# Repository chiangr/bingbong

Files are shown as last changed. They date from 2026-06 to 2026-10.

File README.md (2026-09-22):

# bingbong

The current interactive product site, engineering references, and hardware working files in one checkout. Start with [SESSION_HANDOFF.md](SESSION_HANDOFF.md) for the accepted design direction, source authority, verification results, and remaining work.

This handoff branch is `codex/assembly-handoff-2026-09-22` in [chiangr/bingbong](https://github.com/chiangr/bingbong). It preserves the earlier `master` history and mirrors the local project layout: the former repository-root firmware now lives under `firmware/`.

## Run the site

Install Node.js 24 LTS (or 22.12+) and run:

```sh
git clone --single-branch --branch codex/assembly-handoff-2026-09-22 https://github.com/chiangr/bingbong.git
cd bingbong/site
npm ci
npm run dev
```

Open http://localhost:5173/#inside for the exploded assembly study, or http://localhost:5173/ for the full fifteen-chapter experience. [The standalone HTML](site/artifact/bingbong.html) also opens directly in a browser without installing dependencies.

For a production preview:

```sh
npm run build
npm run preview
```

Open http://localhost:4173/#inside. Servers must be started on each laptop; no remote service is required.

## Project map

| Path | Contents |
| --- | --- |
| [site/](site/) | Current Three.js/Vite experience, all assets, source, scripts and documentation |
| [site/qa/](site/qa/) | Saved tests, 240 layout captures, independent reviews, Lighthouse report and videos |
| [DESIGN_MANUFACTURING_REPORT_2026-09-19.md](DESIGN_MANUFACTURING_REPORT_2026-09-19.md) | Latest engineering authority, including conflicts and open decisions |
| [REDESIGN_DECISION_2026-09-12.md](REDESIGN_DECISION_2026-09-12.md) | Earlier engineering decisions; superseded where the September 19 report conflicts |
| [firmware/](firmware/) | Existing ESP32-S2/BG95 bring-up code and current KiCad working files in `bingbong_pcb/` |
| [cad/](cad/), [cad-v2/](cad-v2/) | Existing mechanical and PCB design exports; these are not final production CAD for the illustrated reference build |
| [pcbway-fab/](pcbway-fab/), [datasheets/](datasheets/), [bom-scratch/](bom-scratch/) | Fabrication exports, component references and supporting analysis |

See [site/README.md](site/README.md) for interactions and verification commands. The website uses the engineering report's reference geometry; existing hardware files and firmware do not constitute a completed implementation of that design.

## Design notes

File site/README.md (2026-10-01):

# bingbong — the assembly study

A new visual direction built around an animated, inspectable 3D product. Midnight blue, cool silver, violet, clean typography, and the original pet / boop / hold demonstrations. This replaces the first build's warm palette and still-first presentation, as requested.

Five later chapters open the same object into its internal assembly, crown cartridge, working ceramic-ball detents and antenna connection, then build it back up. Twenty component descriptions explain manufacture and fitting against the September 19 engineering report.

## Run

Use Node 24 LTS or 22.12+. On a fresh checkout, run these commands from this directory:

```sh
npm ci
npm run dev
```

Open http://localhost:5173. Read [SESSION_HANDOFF.md](../SESSION_HANDOFF.md) for the repository layout, engineering authority and setup on another laptop.

`npm run build` creates `dist/`. Start `npm run preview` to serve it at http://localhost:4173. Open http://localhost:4173/?v=4#inside to begin the assembly study.

Deploy the contents of `dist/` to a static host at the domain root. No server, account, telemetry, external runtime request, or purchase flow is needed. The local service worker makes the site available offline after a complete load. Navigation prefers the network so revisions are visible; cached content remains available offline.

`npm run artifact` produces `artifact/bingbong.html`. This standalone version includes the code, fonts, lighting map, and fallback assets. Open it directly in a browser; no local server or CDN is required.

## Interact

- Drag the **body** to rotate the object. Horizontal touch dragging rotates; vertical swiping keeps normal page scrolling. The view controls also work with keyboard activation.
- Drag the **crown**, or use its arrow keys, to turn in 15° detents. Enter boops; holding Space shares presence.
- Use the chapter's turn, boop, and hold controls to try the paired-device demonstrations.
- Use **Turn it over** for the rear charging pads. Rotation and rear-view transitions use the same live geometry.
- Scroll carries the same object between compositions. Position, scale, screen brightness, halo, mobile clipping and view controls follow the same continuous track; reversing scroll retraces it.
- In **Inside**, select a component button or click the 3D part to read how it is made and fitted. The crown opens into ten component groups.
- In **The mechanical click**, step the race forward or backward. Exactly two ceramic balls move against the 24 grooves while the BeCu leaves deflect.
- In **The cap and antenna**, trace the board → spring finger → plated land → cap connection. The cap is turned to expose its underside; the board is cropped to the RF edge.
- Open **RF lab** in the navigation or antenna chapter, or visit `/#rf-lab`, for a four-part interactive study. Follow equations from charge and current to traveling fields; inspect all 16 proposed RF component positions; animate LC branch currents and reflected waves; and decode a typed message through actual I/Q mixing and integration. The receiver exposes symbol boundaries, phase errors, a known pilot, and interference. The matching bench and receiver use documented teaching models, not measured bingbong antenna data or a complete LTE PHY. Escape or Back returns to the product; a static primer remains available without JavaScript.
- In **Coming together**, scroll, scrub, play, pause or reset the six-stage assembly. On phones the compact controller remains below the object while its introduction scrolls away.
- Sound is opt-in. Reduced motion stops ambient movement and scroll catch-up; the object follows the user's scroll directly and retains manual interaction.

## Source

| File | Responsibility |
| --- | --- |
| `src/experience.css`, `src/tokens.css` | New layout, responsive behavior, palette, typography |
| `src/sections/` | Fifteen chapters of static, accessible content |
| `scripts/build-page.mjs` | Generates HTML, navigation, and accessible controls |
| `src/main.js` | Immediate scene startup and chapter coordination |
| `src/timeline.js` | A single scroll coordinate drives continuous poses and visual states |
| `src/components/scene.js` | Live rendering, damped transforms, drag rotation, context recovery |
| `src/components/graphics-warmup.js` | Optional temporary worker prepares the graphics driver during page setup |
| `src/components/product-model.js` | Parametric exterior in millimetres; materials, crown, display and halo |
| `src/components/assembly-model.js`, `assembly-geometry.js` | Lazy internal geometry, cutaways, spring motion and fitting paths |
| `src/assembly-data.js`, `assembly-interactions.js`, `assembly.css` | Component catalogue, manufacturing notes and assembly controls |
| `src/sections/rf-lab.js`, `src/rf-content.js`, `src/rf-lab.js`, `src/rf-lab.css` | RF study content, schematic, accessible modal, and experiments |
| `src/rf-model.js` | Auditable passive-circuit calculations for the educational matching bench |
| `src/rf-components.js` | Component-by-component explanations of the working RF schematic, including DNP positions |
| `src/rf-lessons-content.js`, `src/rf-lessons.js`, `src/rf-lessons.css` | Detailed first-principles equations, animations, and worked receiver interface |
| `src/rf-signal.js` | Independent models for QPSK encoding/mixing, pilot phase measurement, LC currents, and complex reflection |
| `src/components/studio.js` | Source of the studio lighting environment |
| `src/components/mascot.js` | Original wordless creature and animated reactions |
| `src/interactions.js` | Pet, boop, hold, sound and timer lifecycle |
| `public/mascot/` | Reusable SVG states, PNG sheets, loops and character note |
| `public/lighting/` | Prefiltered reflection map; the object itself remains live geometry |
| `public/renders/` | Generated stills for no-JavaScript / unavailable-WebGL fallback only |
| `qa/` | Screenshots, gesture tests, motion recordings and reports |

With the dev server running, `npm run assets` regenerates fallback stills. `node scripts/bake-lighting.mjs` regenerates the lighting map from the studio source. Shader compilation runs asynchronously; expensive environment prefiltering happens when generating assets, not on each visitor's device.

## Verify

Install Google Chrome for Playwright's `chrome` channel. Run `npm run build` and `npm run artifact`, then keep the production preview running on port 4173. In another terminal:

```sh
npm run qa
node scripts/live-check.mjs
node scripts/scroll-check.mjs
node scripts/assembly-check.mjs
node scripts/delivery-check.mjs
node scripts/rf-check.mjs
node scripts/rf-lessons-check.mjs
node scripts/lighthouse.mjs
```

QA uses installed Google Chrome through Playwright. The main suite captures every chapter at 390, 820, 1440 and 1920 px, in both system themes and motion settings. The fixed midnight palette is intentional in both themes. The scroll suite measures rendered movement across every chapter in both directions, including reduced motion, intermediate stops, screen/halo fades, mobile clipping, wheel input and boop navigation. Additional checks cover 360 px, touch, keyboard, live startup, object rotation, graphics-context recovery, no JavaScript, offline reload and the standalone file.

See [DESIGN_NOTES.md](DESIGN_NOTES.md) for measured results and limitations. Browser-emulated touch/performance is not a physical-phone test.

The RF checks cover analytical circuit reference cases, energy conservation, all four study panels at 360/390/820/1440 px, keyboard and reduced-motion interactions, browser history, accessibility, the static primer, and the standalone HTML. The expanded lesson checks add analytic I/Q identities, all printable ASCII round-trips, phase/pilot recovery, LC current cancellation and energy conservation, each component inspector, partial-symbol decisions, custom and invalid inputs, animation lifecycle, and a visible phone readout. Evidence is in `qa/rf/` and `qa/rf/deep/`. See [the RF source register](qa/rf/source-register.md) for design authority, model assumptions, and the report/schematic test-port discrepancy.

The physical facts and wording come from `SITE_BRIEF.md` and the local engineering reports. The assembly study uses the September 19 report's coaxial reference build; crown architecture/materials, rotary seal, sensor/contact choices and RF results remain open. This is an explanatory model, not production CAD. [Assembly source register](qa/assembly/source-register.md) records the component references. Fonts are self-hosted under the SIL Open Font License; licences accompany them. Three.js's MIT notice is in `public/THIRD_PARTY_NOTICES.txt`. Earlier source/static archives are preserved in `revisions/first-build/` and `revisions/scroll-edition/`.

`scripts/export.ps1` creates source, static and review ZIPs. The source includes historical notes; the review archive holds screenshots, results and videos separately. Extract both into the same directory to follow the evidence links. Raw screencast frames and dependencies are excluded.

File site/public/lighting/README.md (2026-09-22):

# Studio environment

A prefiltered CubeUV lighting map from the softbox scene in src/components/studio.js. Not a product image: the model is rendered live using these reflection samples.

384 × 512; linear RGB; radiance divided by 4 for PNG storage; flipY false. The renderer restores the scale through material environment intensity. Rebuild with npm run dev followed by node scripts/bake-lighting.mjs.

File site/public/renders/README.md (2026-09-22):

# Fallback render source

These static views support unavailable WebGL and no-JavaScript browsing. The normal experience starts its animated 3D model automatically and does not use product-image swaps.

All frames come from `src/components/product-model.js`, `scene.js` and `timeline.js`. The geometry is in millimetres. `npm run assets`, with the dev server running, opens `render-lab.html`, sets complete poses and exports transparent WebP files. Desktop and phone views share geometry and materials. Projected crown coordinates in `src/render-frames.json` are retained as render metadata; live hit areas are projected each frame from the real crown.

`await createScene(container)` creates the renderer. `scene.setFrame({rx,ry,rz,cx,cy,scale,screen,halo,state,pair,otherCx,otherCy,otherScale,otherState,otherHalo,crown,pressed,reduced})` sets a complete target. `cx` and `cy` are fractions of the canvas. `crown` is radians in π/12 steps; `pressed` moves it 0.4 mm. `reduced:true` removes automatic movement for capture. The runtime uses one animation loop and pauses when the document is hidden.

The 95 × 27 × 15 mm body, Ø13 crown, 48 serrations, 1.5 mm ring, 22.5 mm cap, 34 × 16 mm lens and 25.58 × 10.96 mm active panel follow brief §12. The model is an exterior visualization, not production CAD. Final colours and finishes remain design intent. Studio reflections come from the generated lighting map in `public/lighting/`; grain textures are deterministic.

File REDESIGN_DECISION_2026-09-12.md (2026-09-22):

# bingbong — ARCHITECTURE DECISION DOCUMENT

**Author:** lead architect
**Date:** 2026-09-12
**Status:** decision, for review. Nothing here is frozen until the three EVM-0 experiments in §10 report.

**A note on provenance before anything else.** Every tag below means something specific:

| Tag | Meaning |
|---|---|
| `[V]` | A primary datasheet or standards document was opened and the number read, by the research pass or a hostile-review pass recorded in this corpus. |
| `[V?]` | Read by one pass, **contradicted or unreproducible** by another. Must be re-confirmed before design-in. |
| `[U]` | Nobody has read the primary source. It is an estimate, a vendor marketing claim, or a distributor parametric field. |

I have not fetched anything new in writing this document. I am arbitrating between passes that did. Where two passes disagree I say which I believe and why, and I budget the pessimistic one.

---

## 1. THE RECOMMENDATION

**Build ENDURANCE, amended: a 27 × 95 × 15 mm sealed polymer capsule with a machined metal end-cap that is also the cellular antenna, an always-on 160×68 reflective landscape screen that costs 20 microamps to leave lit forever, a knurled metal crown at the other end with 24 real mechanical ball detents, and one 8 mm haptic motor whose only job is to render the *other person*.**

The bet is this: **being reachable is the only thing that costs real power, so buy reachability deliberately and spend nothing else.** A boop costs 53 microamp-hours — all 280 boops in a week cost less than the battery's own self-discharge. What costs money is how often the radio wakes up to *listen*. So the device listens slowly (once every 164 seconds) when nothing is happening, and listens fast (every 5 seconds) for three minutes after anyone touches anything. That single trick is 42× cheaper than listening fast all the time, for a latency the user cannot tell apart, because only the *first* message of a conversation can ever be slow. The money we save goes into a screen that never turns off — which is what makes the object feel alive rather than notified — and into surviving the edge of coverage, which is where every standalone-cellular product actually dies.

The second bet, and the expensive one: **the metal end-cap must be a real 700 MHz radiator.** The industry-standard answer (an Ignion chip booster) has no published solution below 824 MHz, and AT&T mandates Band 12 at 699–746 MHz for every IoT LTE device. There is no catalogue part that certifies this product. We therefore own an antenna engineering programme — roughly $30–70k of NRE and 3–5 months — and we find out whether it works in a chamber in month two, not month ten.

---

## 2. WHY THIS OVER THE OTHERS

All three concepts scored 6.5/10 under hostile review, which is the correct score for three documents that each got one big thing right and one big thing wrong.

### What each one got right, and what killed it

**JEWEL** (23.7 cm³ aluminium, coaxial crown, split-band chassis antenna, 330 mAh)

Right: mechanical detents only; never let the actuator render your own input. That is the single best idea in the entire corpus and I have taken it verbatim. Also right: Power Class 5 is free peak-current relief *because the AT&T TRP requirement drops 3 dB in lockstep*.

Killed by: the crown zone does not close. 9.0 mm allocated against an 11.45 mm serial stack, and three components (magnet, angle sensor, 8 mm LRA coin) all demanding the same centreline. Worse, it bonded a 170 Hz permanent-magnet actuator 4 mm from a magnetometer and made "you feel it in the crown" the headline feature — the charm and the measurement were in direct physical conflict. And its sole quantitative justification for the metal shell, "2.8× lower Q_min, therefore +3.2 dB efficiency ceiling," is a misuse of the Chu limit. **Chu bounds Q, not efficiency.** The reviewer reproduced the arithmetic exactly and then correctly refused the inference. That is precisely the failure mode this project's evidence standard exists to prevent, and I will not repeat it anywhere in this document.

**EX** (31.5 × 85 × 16 mm, colour IPS, two actuators, 710 mAh)

Right: filling the mandatory zero-copper antenna keepout with a PMMA light pipe, so the RF tax becomes the most emotive feature of the product. I have taken this, adapted. Also right: performing the 2–6 s cold RRC setup as the creature waking up instead of hiding it behind a spinner.

Killed by: its headline feature does not exist. Phantom tactile motion between two actuators 44 mm apart requires compliantly decoupled contact surfaces; the reviewer computed the first free-free bending mode of the shell at ~2105 Hz, 9–12× above both actuators, so the capsule moves as a rigid body and both LRAs shake the same 52 g identically. The second actuator, its driver, the 44 mm separation and the extra millimetre of Z were all bought against a claim that does not survive the calculation. Separately, its colour TFT at 18 mA cell-side costs 42 mAh/week — more than the entire standing budget of this design — and can only ever be a screen you switch on, which is the pager feeling the whole product is trying to escape.

**ENDURANCE** (29 × 86 × 15 mm, memory-in-pixel, metal end-cap radiator, 620 mAh)

Right: the eDRX escalation exploit (the best protocol idea in the corpus, and it transfers to any silicon). Right: memory-in-pixel reframes a notification into "a thing your partner left on your desk that never expires." Right, and load-bearing: it killed the Ignion NN02-224 on a correct, document-backed reading — the part's published cellular-IoT solution is 824–960 MHz `[V, local DS_NN02-224.pdf]`, and AT&T mandates B2/B4/B12 `[V, local att_trp.txt]`, so that recommendation would have failed certification.

Damaged by: a coverage-search line wrong by ~20×, a square 128×128 display that contradicts the ID brief and forced the body wide, a Z-stack with negative margin, no ESD strategy on two exposed live metal parts, and no recovery path on a sealed object.

### Why ENDURANCE wins anyway

Because **its errors are arithmetic and its rivals' errors are physics.** Every defect the reviewer found in ENDURANCE is fixable with numbers and a millimetre budget. EX's phantom motion is not fixable without a different chassis architecture. JEWEL's crown/LRA/magnetometer collision is not fixable without giving up its headline feature — which is what ENDURANCE had already done.

And ENDURANCE is the only one of the three whose central thesis survives contact with the corrected power budget. Re-run honestly (§5) it lands at **3.5 weeks typical, 1.6 weeks in sustained deep coverage** on a 560 mAh cell. JEWEL corrected lands at 1.45 weeks warm-24/7 and 1.03 weeks with CE-mode repetitions. EX corrected lands at 1.88 weeks typical and 0.99 weeks in fringe coverage. Both of those meet the brief *on paper and nowhere else* — they have no margin left for the coverage-loss case, which is the one unbounded failure mode in any standalone-cellular product.

### The display error that nobody caught, and that buys back the width

EX's document asserts that the 160×68 memory LCD's 25.28 mm active area "needs a 32 mm-wide MODULE and therefore a ~34 mm body," and used that to justify growing to 31.5 mm. ENDURANCE accepted the same reasoning and went to a square panel, which forced 29 mm.

**Both are wrong.** The Sharp LS011B7DH03 outline is 32.0 × 14.0 × 0.745 mm `[V, Display Logic Sharp product table]`. On a stick, the module's **32 mm long axis runs down the length of the stick**, because that is the axis the landscape image runs along. Only 14.0 mm crosses the body width. A 27 mm body with 1.2 mm walls has 24.6 mm of internal width — the module fits with 5 mm to spare.

Consequence: **the recommended architecture honours the brief's 27 mm width exactly.** We spend the growth on length instead, where it is both less objectionable in a pocket and worth real antenna dB.

### What we give up, stated plainly

- **Colour.** One bit, 10,880 pixels, dithering only. The whole colour channel is one RGB LED in the split ring. A creature's face here is line art.
- **Length.** 95 mm against a brief of 80, and against a real NW-E405 at 84.9 mm. That is +19% and it is the most arguable call in this document. I defend it in §6.
- **Sub-minute presence by default.** Mean inbound latency is 82 s cold, 2.6 s inside a conversation window. The first boop of a cold exchange is slow. This is a product decision and the UI must never claim "delivered."
- **A programmable dial.** 24 steel balls in grooves, one texture forever. No firmware update will ever change how it feels.
- **Fingertip haptic crispness.** The actuator lives mid-body, not in the crown, so the boop arrives in the palm rather than the thumb. Paid to keep a 170 Hz magnet away from a magnetometer and a steel can away from the radiator.
- **Any catalogue antenna.** There is no drop-in fallback. See §9.1.
- **GNSS, Bluetooth, Wi-Fi, USB, a microphone, a speaker, PPG, and a phone app.** All dead, most for good reasons, listed in §8.

### Grafts taken from the runners-up

| Taken from | What | Why |
|---|---|---|
| JEWEL | Mechanical detents only; the LRA never renders your own input | Zero latency, zero microamps, zero wear, and emotionally exactly right. Best idea in the corpus. |
| JEWEL (reviewer) | Ceramic Si₃N₄ detent balls; non-magnetic crown with controlled permeability | 440C is martensitic and sits millimetres from the sensing magnet |
| JEWEL (reviewer) | 4-pin pogo: VBUS, GND, SWDIO, SWCLK | Field recovery on a sealed object; PPK2 attach point |
| EX | The RF keepout volume *is* the light feature | Adapted: the polymer split ring the chassis antenna **requires** becomes the illuminated halo. Zero added volume. |
| EX | Perform the cold RRC setup as the creature waking | Turns the one unavoidable curse of standalone cellular into character |
| EX | Mirror-Pet character model; no streaks, no death, no read receipts | Removes the guilt engine and the coercion vector by construction |
| EX | IQS211B true self-capacitance for grip, not Qvar | Qvar is charge-*variation* sensing; a steel crown in a POM journal is a triboelectric generator |
| ENDURANCE (reviewer) | Grow to ~95 mm; AT&T Small Form Factor is anything **under 107 mm** `[V]` | Free certification-class margin and real low-band dB. Do not reach 107: at 107 the B12 requirement jumps to +18 dBm, unachievable. |
| ENDURANCE (reviewer) | Rail at 3.1 V, not 3.0 V | MT6701 minimum supply is 3.0 V; a 3.0 V rail at −2% is out of spec on every unit |
| All three reviewers | PC5 vs PC3 is not a free lunch either way | I reverse JEWEL and EX here and choose **PC3**. See §6.3. |

---

## 3. BLOCK DIAGRAM

```
MECHANICAL (27.0 W x 95.0 L x 15.0 T mm, ~38.5 cm3 bbox / ~34 cm3 radiused, ~48 g)

  x=0                  x=16                         x=71   x=72.5      x=95
  +====================+============================+======+===========+
  | CROWN ZONE 16 mm   | MAIN PCB ZONE 55 mm        |SPLIT | 6061-T6   |
  |                    |                            | RING | END CAP   |
  | 13.0 OD knurled    | PCB 23 x 55, 6L, 0.8 mm    |1.5mm | 22.5 mm   |
  | non-mag crown,     | display module x=18..53    |PC/ABS| = THE     |
  | 6.0 protruding     | LRA + bracket x=55..69     |+ RGB | RADIATOR  |
  | 24 ceramic-ball    | cell 23x43x5.5 BENEATH     |LIGHT | ZERO      |
  | detents, POM       | nRF9151 on TOP under disp  |GUIDE | COPPER    |
  | journal, O-ring,   |                            |HALO  | ON ALL 6  |
  | keyring lug on     | last 8 mm of PCB and the   |      | LAYERS    |
  | the FLANK          | whole cell: >=10 mm from   |      | + NO CELL |
  +====================+ the split ring             +======+===========+
   satellite PCB 22x10 perpendicular, 6-way 0.5 mm FFC        ^
   (angle sensor on-axis, tact off-axis, 2x Hall latch)    spring-finger
                                                            feed, masked
   NON-CONDUCTIVE 28 mm DYNEEMA INTERPOSER between the      Ni/Au pad
   keyring lug and the user's actual keys.  <-- mandatory

ELECTRICAL

  4-pin magnetic pogo dock (5 V, SWDIO, SWCLK, GND)
     |
  [ferrite + 24 V TVS + reverse-blocking FET + dock-presence detect]
     |  IN  (abs max 25 V -- survives the fault it exists to prevent) [V]
     v
  +--------------------+  VSYS 3.45 - 4.35 V   (power path: 1.5 A DC / 2.5 A pulse [V])
  |   TI BQ25180       +---+-------------+-------------+--------------+
  |  power path + chg  |   |             |             |              |
  |  300 mA, JEITA/NTC |   |             |             |              |
  |  /MR <- dial press |   |             |             |              |
  +--+-----------------+   |             |             |              |
     | I2C                 |             |             |              |
  +--v-----------------+   |             |             |              |
  |  ADI MAX17048      |   |             |             |              |
  |  ModelGauge        |   |             |             |              |
  +--------------------+   |             |             |              |
                           |             |             |              |
  560 mAh Li-Po -----------+      +------v------+ +----v-----+  +-----v------+
  PCM trip >=2 A / >=10 ms        | TI DRV2625  | | TPS62840 |  | RGB LED    |
  DC-IR <=150 mOhm incl PCM       | DSBGA-9     | | V3 = 3.1 |  | 3x N-FET   |
  10k NTC bonded to the CELL      +------+------+ | 60 nA IQ |  | + resistor |
  cutoff raised to 3.45 V                |        +----+-----+  +------------+
                                         v             | V3 rail (3.1 V)
                              Vybronics VG0840001D     |
                              8.0 x 4.05, 170 Hz       |
                              on a bracket tied to     |
                              PCB + cell mass          |
                                                       |
  +----------------------------------------+           |
  | Nordic nRF9151-LACA-R                  |           |
  | 12.1 x 11.1 x 1.2 mm LGA  [V]          |           |
  | Cortex-M33, 1 MB / 256 kB              |           |
  | LTE-M Cat-M1, POWER CLASS 3 (23 dBm)   |           |
  | GNSS silicon present, NOT FITTED       |           |
  | VDD <- VSYS directly (3.0-5.5 V) [V]   |           |
  | VDD_GPIO <- V3 (abs max 3.9 V) <-------+-----------+
  +--+---+---+---+---+---+---+-------------+
     |   |   |   |   |   |   |
     |   |   |   |   |   |   +-- GPIOTE/PPI/RTC --> EXTCOMIN (hardware VCOM,
     |   |   |   |   |   |                          runs through deep sleep)
     |   |   |   |   |   +------ SPI0 -----------> MEMORY LCD 160x68  (V3)
     |   |   |   |   |                             Sharp LS011B7DH03 /
     |   |   |   |   |                             Winstar WFM0108A2 (2nd src)
     |   |   |   |   +---------- SPI1 -----------> 16 Mbit SPI NOR    (V3)
     |   |   |   |                                 MCUboot slot1 + art
     |   |   |   +-------------- SIM_1V8 --------> MFF2 eUICC 5x6 DFN-8
     |   |   |                                     SGP.32, supply-shutdown
     |   |   |                                     MANDATORY (contractual)
     |   |   +------------------ I2C0 + GPIO ----> SATELLITE PCB via 6-way FFC
     |   |                                          |
     |   |                                          +- MT6701QT-STD (LOAD-SWITCHED)
     |   |                                          |    on-axis 14-bit absolute
     |   |                                          +- 2x DRV5032DU (ALWAYS ON)
     |   |                                          |    1.6 uA typ / 3.5 max ea [V]
     |   |                                          +- tact SW (off-axis, press)
     |   |
     |   +---------------------- I2C0 -----------> Azoteq IQS211B (V3)
     |                                              electrode = STATIC annular
     |                                              ring on the end-cap shoulder
     |                                              (NOT the rotating crown)
     |                                              + 2k2 series R + 10 pF shunt
     |                                              + TX blanking in firmware
     v
  ANT (single 50 ohm port [V])
     |
  [low-cap TVS <0.3 pF]--[defined DC return]--[5x 0402 high-Q L/C dual-resonant
                                                match: B12 699-746 AND B2/B4
                                                1710-2155 MHz]
     |                        |
     +--> spring finger --> MASKED Ni/Au PAD ON THE 6061 END CAP
     |
     +--> DNP Hirose MHF4 pad  (CHAMBER PROBE ONLY -- see 9.1, this is NOT
                                a production fallback)

  NO aperture tuner in the shipping build.  NO coax.  NO GNSS antenna.
  ONE regulated rail.  ZERO boost converters.
```

---

## 4. BILL OF MATERIALS

Significant parts only. Passives, the matching network and adhesives are lumped.

### 4.1 Silicon

| Function | MPN | Package | Tag | Note |
|---|---|---|---|---|
| Host MCU + LTE-M modem + RF FE + PMIC + crystals | Nordic **NRF9151-LACA-R** (2k reel); `-R7` 500-pc for protos | LGA **12.1 × 11.1 × 1.2 mm** | `[V]` PS v1.0 front matter | **This corrects the corpus's "11 × 12 × 1.0 mm"** — Nordic's marketing page still says 11×12×1, the Product Specification says 12.1×11.1×1.2. Design to the PS. VDD 3.0–5.5 V single supply, runs straight off VSYS. PC3 23 dBm **and** PC5 20 dBm selectable. −108 dBm Cat-M1 low band. **Supply: 16–19 wk factory lead, 0 stock at most houses. Place the 2k reel PO before the schematic exists.** |
| Charger + power path | TI **BQ25180YBGR** | DSBGA-8 1.6 × 1.1 mm | `[V]` SLUSE99C Rev C | IN pin abs max **25 V** — survives the exact charge-port overvoltage it exists to prevent. SYS 1.5 A DC / 2.5 A pulse. **Correction to ENDURANCE:** IQ_BAT is 3 µA typ with pushbutton *disabled*, **4 µA typ with it enabled**, and we enable it for the /MR recovery path. Budget 5.5 µA max. |
| Fuel gauge | ADI **MAX17048G+T10** | WLP 0.9 × 1.7 mm | `[V]` 19-6171 | Needed because current swings 100× (147 µA → 295 mA); a naive voltmeter reads ~60 mV low during every boop, which on the 3.9–3.6 V plateau looks like a 20–40 % SoC collapse. **Caveat nobody flagged:** voltage-based ModelGauge with no coulomb counting is ±15–20 % without a custom battery-model INI from ADI, which means shipping cells to ADI and waiting. The UI shows the creature's sleepiness, not a percentage. |
| 3.1 V rail (the only regulator) | TI **TPS62840DLC** + 1 % ≤200 ppm/°C RSET | SON-8 **2.0 × 1.5 mm** | `[V]` SLVSEC6D Rev D | 60 nA IQ (36 nA VIN + 56 nA VOS typ), 120 nA in 100 % mode, **300 nA shutdown max** (ENDURANCE quoted the 25 nA typ). VIN 1.8–6.5 V, 750 mA. **RSET = 71.5 kΩ E96 → 3.1 V** `[V?]` — the hostile reviewer read this from Table 1; re-confirm at schematic. Layout rule from the datasheet: C(VSET) ≤ 100 pF or the R2D converter mis-reads and sets the wrong output. |
| Haptic driver | TI **DRV2625YFFR** | DSBGA-9 1.498 × 1.361 mm | `[V]` SLOS879C, TI product folder ACTIVE | 105 nA shutdown / 1.55 µA standby vs DRV2605L's 4 µA — 40× on a line that runs 168 h/week. 8.5k at DigiKey. **Do not design in DRV2624** (electrically identical, 1 kB RAM, 0 stock at DigiKey *and* Mouser). |
| Coarse rotation wake, always on | 2 × TI **DRV5032DU** | X2SON 1.4 × 1.1 mm | `[V]` SLVSDC7H Rev H | 3.9 mT, unipolar, push-pull, 20 Hz. **ICC(AVG) at VCC = 3 V is 1.6 µA typ / 3.5 µA MAX** — note the headline 5.2 µA in marketing is the 1.8 V figure for the 80 Hz part. Budgeted at MAX. |
| Fine angle, power-gated | MagnTek **MT6701QT-STD** | QFN3×3-16L | `[V?]` Rev 1.5 read, but the vendor datasheet has mislabelled units and no Western authorised distribution | 14-bit absolute, VDD **3.0–5.5 V**, 10 mA typ / 14 mA max, 1.0 ms power-up, 0.3 mm max off-axis. **Weakest sourcing line in the BOM.** Mitigation in §4.5. |
| Grip / presence | Azoteq **IQS211B00000000TSR** | TSOT23-6 ~2.9 × 1.6 mm | `[V]` v2.8.1 Table 7.2; stock Mouser 14,002 @ $0.40/1, $0.181@1k | 2 µA at 160 ms scan, 77 µA at 9 ms interacting, VDDHI 1.764–3.6 V, Cx ≤ 120 pF. Note this is the **default-OTP `-00000000-TSR`** variant with real dual-distributor stock, not the `-00060000-CSR` the research named. |
| SIM | Generic **MFF2 eUICC**, ETSI TS 102 671, SGP.32-capable | DFN-8 5 × 6 × 0.85 mm | `[V]` footprint; `[U]` specific MPN | **Do not design in Hologram SIM-ST-MFF2 — discontinued at DigiKey.** Design to the generic footprint. **Contractual, not technical:** written confirmation of UICC supply-shutdown support before any reel PO. Nordic's own footnote requires adding 20–60 µA at 3.7 V without it — up to 10 mAh/week, more than the display and both always-on sensors combined. |
| Asset / update flash | 16 Mbit SPI NOR, ≤6 × 5 mm, 1.65–3.6 V (Macronix MX25R1635F class) | USON-8 2 × 3 mm | `[U]` — **nobody has opened this datasheet** | Required: nRF9151 has 1 MB, no XIP, no QSPI. MCUboot slot 1 goes here via Partition Manager `nordic,pm-ext-flash`. Select against live stock at BOM freeze. |

### 4.2 Display

| Function | MPN | Outline | Tag | Note |
|---|---|---|---|---|
| Primary | Sharp **LS011B7DH03**, 1.08 in 160×68 MIP | **32.0 × 14.0 × 0.745 mm**, active 25.28 × 10.744 mm | `[V]` Display Logic Sharp product table; `[U]` the panel's own IVDD1/IVDD2/fCOM table | **Nobody in this corpus has read the LS011B7DH03's own electrical spec.** We are extrapolating from the LS013B7DH03 (20 µA static max, 340 µA dynamic max, fCOM 0.5–30 Hz) `[V]`. That extrapolation is conservative (smaller panel) but it is an extrapolation. Supply: 0 stock, 28-week lead, ship dates in Feb 2027. |
| Second source, same 10-pin FPC | Winstar **WFM0108A2TAJASNN000** | **34.84 × 16.17 × 2.08 mm** per Winstar, **32 × 14 × 2.08** per First Components | `[V]` spec 1st ed. 2025-04-24; **outline disputed** | 5 µA typ / 16.7 µA max hold at 3.0 V. **Mandates fEXTCOMIN 57–70 Hz**, unlike Sharp's 0.5 Hz floor. In stock in singles at ~€19.50@25. |
| Frontlight (stuff option) | Azumo-class frontlight film | ~0.6 mm added | `[U]` — no quote, no part | Reserved in the Z-stack. See §9.7. |

**Mechanical decision:** the display pocket and Z-stack are designed to the **Winstar worst case (34.84 × 16.17 × 2.08 mm)**, the aperture to the **shared active area (25.28 × 10.744 mm)**. Either part drops in. If the Sharp panel is secured, its 0.745 mm thickness returns 1.34 mm of Z, which goes to a 6.5–7.0 mm cell (~700 mAh) or a 13.7 mm body. That is the reward for closing the display source, and it is why §9.2 ranks it third.

### 4.3 Electromechanical

| Function | Part | Tag | Note |
|---|---|---|---|
| Haptic actuator | Vybronics **VG0840001D**, 8.0 dia × 4.05 mm, 170 Hz | `[V]` vendor page | 2.0 Vrms, 68 mA typ / 90 mA max, 1.00 Grms, fall ≤55 ms. **I am reversing ENDURANCE's stated reason for this part.** It quoted "rise 12 ms max" as the decisive number; the hostile reviewer correctly observed that a linear resonator's rise-to-50 % and fall-to-50 % share the same time constant τ = 2Q/ω₀ and **must be equal**. 12 ms vs 55 ms at the same threshold is only possible under overdrive — and overdrive is exactly what the DRV2625's supply compensation suppresses. The real reason to pay 0.8 mm of Z over the VG0832012 is **55 ms free fall instead of 80 ms**, which active braking then has to cut to ~15–25 ms. Prototype the click separation on a real 48 g mass before this is final. |
| Crown | 13.0 mm OD × 8.0 mm, knurled, **non-magnetic grade with a specified max permeability measured after machining**, hard-anodised or PVD | `[U]` | Protrudes 6.0 mm from the end cap. Recessed 0.4 mm radially inside the end-cap shoulder silhouette so it is never the drop impact point. |
| Detents | 24 grooves in a **hardened 17-4PH insert pressed into the crown bore**; 2 × ø0.8 mm **Si₃N₄ ceramic** balls on BeCu leaf springs | `[U]` torque target 2.5–4 mN·m | **Two fixes taken from the JEWEL review.** 303SS is free-machining, sulphur-bearing and soft (~170 HV) — two balls would brinell the grooves inside the life of the gift. And 440C is martensitic and ferromagnetic, sitting millimetres from the sensing magnet. Ceramic balls in a hardened race solve both. Specify 1,000,000 indexes with a measured torque-decay limit. |
| Sensing magnet | ø6.0 × 2.5 mm diametric NdFeB, catalogue part, in the crown hub | `[V]` MT6701 requirement | Concentric to 0.3 mm. Tightest tolerance in the product; it must be held by a moulded/machined feature, not by assembly luck. |
| Press | SMD tact ≥1.6 N, ≥300k cycles, **off-axis**, behind the sealed bulkhead | `[U]` — pull the catalogue | **The axis conflict is resolved by geometry, not by three switches.** The crown + hub + bulkhead translate 0.25 mm as a rigid unit on a 12 mm-long POM journal at 0.06–0.10 mm diametral clearance, which bounds tilt to <0.5°. A single off-axis tact pressed by a boss on the bulkhead therefore cannot cock. **Verify press force is independent of thumb position on the knurl at EVM** — this must be a measured result, not an argument. |
| Charge / debug | 4 × gold-over-**1.0–2.5 µm nickel** pogo pads (VBUS, GND, SWDIO, SWCLK) + weighted magnetic dock | `[V]` EU Directive 2022/2380 Annex Ia is a closed list; keychain wearables absent | **Upgraded from 2 pins per both hostile reviews.** Two pins on a sealed, screwed-shut object with no USB means one bad FOTA bricks a unit permanently, with no RMA reflash and no PPK2 attach point for the sleep-current verification this design demands. Gold *thickness* alone is the classic mis-spec; the nickel diffusion barrier is what survives sweat. Charge current held off until dock presence is detected. Short and reverse protection — a key **will** bridge them. |
| Antenna radiator | Machined **6061-T6** end cap, 22.5 mm, isolated by a 1.5 mm moulded PC/ABS split ring, single spring-finger feed | `[U]` performance | Feed pad is **selectively masked electroless Ni/Au on bare aluminium** — you cannot feed RF through Type II/III anodise, and a gold spring on bare 6061 is a ~1.5 V galvanic couple with gold cathodic. Both catches from the ENDURANCE review. |
| Keyring | Stainless lug on the **flank** of the crown-end housing + **28 mm Dyneema/POM interposer** | `[U]` | Zero axial length. The interposer costs pennies and is the only thing between the chamber result and the field link budget — a 120 g steel key bundle capacitively coupled to the counterpoise end of a 0.22 λ chassis is worth 4–10 dB. |
| Halo | 1 × PLCC-4 RGB, 1.6 × 1.6 mm, common anode to VSYS, 3 × SOT-523 N-FET + resistor, firing into the **polymer split ring as a light guide** | `[U]` MPN | Deliberately **not** an LP5009/LP5012: 10 µA power-save for nothing. Three GPIOs and three FETs cost zero standby. Common anode to VSYS because blue/green Vf exceeds 3.1 V. 8-bit software PWM is adequate here because the halo is a ring, not a display; if banding shows in the breath, move to a hardware PWM channel. |
| Cell | Li-Po pouch **23 × 43 × 5.5 mm, ~560 mAh**, integrated PCM, 10k NTC | `[U]` capacity derived, not quoted | 5.44 cm³ × 0.3796 Wh/cm³ (computed from the `[V]` LiPol LP602248 datapoint: 650 mAh / 2.405 Wh in 6.0 × 22 × 48) = 2.065 Wh = 558 mAh. **Get a vendor quote before believing it.** Specify in writing, because no vendor in this class publishes them: **PCM trip ≥2 A with ≥10 ms delay** (so a 295 mA burst with 35 mA/µs transients never nuisance-trips), **DC-IR ≤150 mΩ including PCM**, IEC 62133-2 and UN38.3 certificates. Connectorised on a 2-pin FPC/ZIF — **not** a JST ACH, which is 2.8–3.2 mm mated and blows the Z budget. |

### 4.4 Parts that MUST be datasheet-confirmed before anyone designs them in

Ranked by how much damage a wrong assumption does:

1. **Sharp LS011B7DH03's own electrical table** — IVDD1, IVDD2, fCOM/fEXTCOMIN floor, and storage temperature. We are extrapolating all four from the LS013B7DH03. Note the LS013's application note gives **Tstg −10 to +60 °C absolute maximum**, far tighter than the family selector's −30/+80, and a keychain on a July dashboard exceeds +60 °C routinely. *This is exactly the class of abs-max oversight that produced the 6 V protection-part failure.*
2. **Winstar WFM0108A2 mechanical drawing for the exact ordering code** — 34.84 × 16.17 × 2.08 vs 32 × 14 × 2.08 is 2.8 mm of width and 1.3 mm of thickness in dispute. Also: the Winstar MIP selector says "Front Light: Yes" while the spec has a 10-pin FPC with **no LED terminals and an empty LED table**.
3. **TPS62840 RSET value for 3.1 V** — read once, by a reviewer, and the rail feeds the display (abs max 3.6 V) and the MT6701 (min 3.0 V). Two abs-max exposures on one unconfirmed resistor.
4. **MT6701QT-STD** — vendor datasheet extracts badly and the electrical table has mislabelled units. Treat every marginal spec with suspicion.
5. **The MFF2 part's supply-shutdown behaviour** — contractual, in writing, before the reel PO.
6. **Panasonic EVPBB or whatever tact is chosen** — Panasonic publishes no operating force, travel or cycle life on the overview page, and a 0.55 mm-tall tact almost certainly has ~0.15 mm travel, not the 0.25 mm the crown is specified to move.
7. **SPI NOR MPN, RGB LED MPN** — placeholders.
8. **Cell energy density** — derived, not quoted.

### 4.5 The MT6701 sourcing hedge

The satellite PCB is a 22 × 10 × 0.6 mm 2-layer board. It costs cents. **Spin two variants of it** — one MT6701QT-STD (QFN3×3-16L), one ams-OSRAM AS5600L (WLCSP 2.07 × 2.63 × 0.60, real Western distribution) — and qualify both against the same FFC pinout and the same magnet. The main PCB never knows which is fitted. This converts a single-source exposure into a $300 NRE item, and it is the cheapest insurance in the whole design.

### 4.6 Cost

**~$62 material per unit at 1k**, plus ~$6 for the dock. I am explicitly re-costing the two lines both JEWEL and EX got badly wrong:

| Line | Naive | Honest @1k |
|---|---|---|
| nRF9151-LACA-R | $16.08@2000 `[V]` | $16.08 |
| Display | $6.54@2240 Sharp `[V]` / €19.50@25 Winstar `[V]` | $9.00 blended, **high variance** |
| 6-layer 0.8 mm main PCB + 2-layer satellite + FFC | "$3.50" | **$7.00** |
| Machined crown assembly (crown, 17-4PH insert, ceramic balls, BeCu springs, journal, O-ring, wave washer, magnet) | "$4.50" | **$9.50** |
| Machined + finished 6061 end cap with masked plated feed pad | "$3.50" | **$6.50** |
| Shells (2), glass lens + OCA, split-ring light guide, brass inserts | — | **$5.50** |
| Cell + PCM + NTC | — | $3.50 |
| MFF2 eUICC | — | $3.50 |
| VG0840001D | — | $2.00 |
| MT6701 / AS5600L | — | $1.50 |
| BQ25180 $1.64 + MAX17048 $1.12 + TPS62840 + DRV2625 $0.81 + 2× DRV5032 + IQS211B $0.18 + NOR | — | $6.00 |
| Passives, matching network, TVS, pogo, adhesives, aura | — | **$4.00** |

At 10k expect ~$48–54. **Excludes** ~$30–70k antenna NRE, ~$18–30k shell tooling, ~$8–15k chamber, and PTCRB + FCC/CE + AT&T + Verizon Open Development at **$50–150k** — a line both JEWEL and ENDURANCE listed without a number.

---

## 5. POWER BUDGET

### 5.1 The assumption everything rests on

**Baseline eDRX 163.84 s → mean inbound latency 82 s.** On any interaction (you boop, or a boop arrives, or the grip sensor fires), the modem drops to **eDRX 5.12 s for 180 s → mean inbound latency 2.6 s.** Twelve such windows per day.

This is the ENDURANCE exploit and it is the single best idea in the corpus. Flat eDRX 5.12 s costs **345 mAh/week** and is impossible at any cell size that fits this body. Twelve 180-second windows cost **8.2 mAh/week** for the same felt latency *inside a conversation*, because only the very first boop of a cold exchange can ever be slow.

**The idle-current model:** `I_idle = 2.7 µA + 10,499/T µA`, back-solved from Nordic's field measurement of 132 µA at eDRX 81.2 s on a live network. Sanity check: the model returns 130.9 µA at 81.92 s, 1 % from measured. At 163.84 s the model returns 66.8 µA but Nordic **measured** 92.6 µA, so I budget 92.6 — 39 % conservative on the largest line in the design.

**Honest caveat on that number.** Nordic's own Product Specification says eDRX @ 81.92 s = **18 µA** Cat-M1, UICC included `[V]`. The field figure is 7× higher and the ENDURANCE reviewer could not locate its source. I budget the field figure because it errs safe — but the reader should know that the biggest line in this table rests on a measurement I cannot point you to. §10 fixes this with a PPK2.

### 5.2 The modelled day

20 boops sent, 20 received, 5 petting sessions initiated + 5 received (20 s each), 50 display-wake interactions of 15 s, 24 periodic TAU, 2 cold re-attaches. **AS-RAI assumed NOT granted.** Where a datasheet publishes a MAX, I budget the MAX.

**Cell: 560 mAh nominal × 0.81 = 454 mAh usable.** Derate = 0.90 (nRF9151 RF is specified only down to VDD 3.3 V; 3.0 V is survival, and see §5.5 on the cold-temperature droop) × 0.90 (ageing + temperature).

#### A. Standing load, 168 h

| Line | Current | mAh/wk | Tag |
|---|---:|---:|---|
| nRF9151 modem, eDRX 163.84 s | 92.6 µA | 15.56 | `[V?]` field-measured, source unlocated |
| nRF9151 app core, System-ON idle + RTC | 2.2 µA | 0.37 | `[V]` |
| Display static, IVDD1 MAX | 20.0 µA | 3.36 | `[V]` LS013 max, extrapolated to LS011 |
| EXTCOMIN generation (RTC→PPI→GPIOTE domain) | 2.0 µA | 0.34 | `[U]` |
| Idle "breathing" animation, 40 µA for 90 min/day | 2.5 µA | 0.42 | `[U]` — **see note** |
| 2 × DRV5032DU @ 3 V, ICC MAX 3.5 µA each | 7.0 µA | 1.18 | `[V]` |
| IQS211B grip, 160 ms scan | 2.0 µA | 0.34 | `[V]` |
| DRV2625 standby, MAX | 2.0 µA | 0.34 | `[V]` |
| BQ25180 IQ_BAT, **pushbutton enabled**, MAX | 5.5 µA | 0.92 | `[V]` |
| MAX17048 hibernate, MAX | 5.0 µA | 0.84 | `[V]` |
| SPI NOR deep power-down | 1.0 µA | 0.17 | `[U]` |
| TPS62840 IQ + pull-ups + board leakage | 5.0 µA | 0.84 | `[U]` |
| **Standing subtotal** | **146.8 µA** | **24.68** | |
| Cell self-discharge, **4 %/month** on 560 mAh | — | 5.20 | `[U]` |
| **A. STANDING TOTAL** | | **29.88** | |

> **The breathing-creature line is the one ENDURANCE missed and I have put back.** Its 20 µA display line assumed a *still image*. A creature that breathes needs CPU wakes: a 4 Hz idle animation costs ~40 µA all-in, which run 24/7 would be **6.7 mAh/week — doubling the standing budget**. The resolution is architectural, not arithmetic: **the creature only animates when a human is present.** The IQS211B grip bit or the DRV5032 pair or a recent event gates it; otherwise the panel holds a static frame at 20 µA. Budgeted at 90 min/day. This is a firmware requirement with a hard number attached, not a polish item.

#### B. Event load

| Line | Basis | mAh/wk | Tag |
|---|---|---:|---|
| eDRX escalation, 12 × 180 s/day to 5.12 s | Δ1960 µA × 2160 s/day | 8.23 | model |
| 40 boops/day, **no AS-RAI**, 191 mC = 53.1 µAh each | | 14.87 | `[V]` Nordic |
| 10 petting sessions/day × 20 s RRC-connected **@ 50 mA** | | 19.44 | `[U]` — reviewer's correction from 35 mA |
| App core awake: 750 s display + 200 s petting + 120 s boops @ 4 mA | 1070 s/day | 8.32 | `[U]` |
| Display dynamic, IVDD2 340 µA MAX, 950 s/day | | 0.63 | `[V]` LS013 max |
| Haptics: 1220 clicks/day × 30 ms @ 68 mA | | 4.84 | `[V]` actuator |
| Haptics: purr 100 s/day @ 35 % amplitude (≈8.3 mA, V² scaling) | | 1.61 | `[V]`+`[U]` |
| MT6701 gated on, 10 × 25 s/day @ 14 mA MAX | | 6.81 | `[V]` |
| Periodic TAU, 24/day **@ 0.5 J** | 37.5 µAh each | 6.30 | `[U]` — reviewer's correction from 105 mJ |
| Cold re-attach, 2/day **@ 5 J** | 375 µAh each | 5.26 | `[U]` — reviewer's correction from 0.98 J |
| **Coverage search governor allowance** | | **20.00** | `[U]` — **see note** |
| Aura: 40 blooms + 20 min/day breath | | 1.15 | `[U]` |
| FOTA allowance, 1 × 200 kB delta/month | | 0.50 | `[U]` |
| **B. EVENT TOTAL** | | **97.96** | |

> **The coverage-search line is where ENDURANCE was wrong by ~20× and it is the most important correction in this document.** It budgeted "30 min/week @ 1.72 mA = 0.86 mAh/wk". An nRF91-class modem doing PLMN/cell search runs its receiver at tens of milliamps, and a pocket-carried keychain loses coverage *daily* in garages, lifts, building cores and transit. The reviewer's fair figure is 15–20 mAh/wk; pessimistic is 28. **I budget 20, which makes it the second-largest single line in the design.** It is also the only genuinely unbounded failure mode: a modem that cannot find a cell and does not back off draws 1.72 mA continuously and flattens this cell in 11 days. §9.6.

#### Total

| | mAh/wk |
|---|---:|
| A. Standing | 29.88 |
| B. Events | 97.96 |
| **TOTAL** | **127.84** |

**454 mAh usable / 127.84 = 3.55 weeks.** Round to **3.5 weeks typical.**

### 5.3 Sensitivities

| Scenario | mAh/wk | Runtime |
|---|---:|---:|
| **Nominal** (eDRX 163.84 s baseline, AS-RAI refused) | 128 | **3.5 wk** |
| AS-RAI granted (boops 191 mC → 24.3 mC) | 115 | 3.9 wk |
| Network grants only eDRX 81.92 s (latency halves to 41 s) | 134 | 3.4 wk |
| eSIM without supply shutdown (+40 µA) | 135 | 3.4 wk |
| Heavy user: 2× all interaction | 190 | 2.4 wk |
| **Network refuses eDRX → PSM + 300 s poll** (latency 150 s) | 227 | **2.0 wk** |
| **Sustained CE Mode A/B deep coverage** (4× connected-mode energy, 2× search) | 285 | **1.6 wk** |
| Compound: no eDRX **and** sustained deep coverage | ~600 | **0.8 wk — FAILS** |

The compound case does not meet one week **at any cell size that fits this body**, and I am not going to pretend otherwise. The mitigation is behavioural and must be specified: in sustained deep coverage with no eDRX grant, the device lengthens the poll interval to 900 s, stops animating, and tells the user through the creature that it is sleeping deeply. That is an honest degradation, not a fudge, and it needs to be in the requirements document with those numbers.

### 5.4 The one genuinely fatal mode

If the network denies **both** eDRX and PSM and parks the device in idle DRX at 1.28 s, current is ~8.2 mA and the product is **dead in 2.6 days**.

Firmware must read back `+CEDRXRDP` and `+CPSMS` after every attach and, if neither is granted after N attempts, **detach and fall back to RTC-scheduled polling**. Never leave the modem in operator-chosen idle DRX. This is a release gate, tested in a shielded box against a base-station simulator configured to refuse both.

Second gate: Qoitech measured **+600 µA on an nRF9151 simply from leaving the debug UART enabled in sleep** `[V]`. That is 100 mAh/week — 78 % of the entire budget, from one build flag. The console UART must be compile-gated out of the production image; debug is SEGGER RTT over the SWD pogo pins. Verified with a PPK2 capture on the golden unit, every release.

### 5.5 Burst current — and the argument ENDURANCE got wrong by 70×

Worst simultaneous: PC3 TX 295 mA + haptic 90 mA + housekeeping 10 mA = **395 mA = 0.71C** on a cell rated 1C continuous.

ENDURANCE wrote "on a linear power path the bulk cap is what actually services that burst." **That is wrong.** 44 µF over a 1 ms LTE-M TX subframe at 295 mA gives ΔV = 6.7 V. To hold 100 mV you would need ~3000 µF. The capacitors handle the **35 mA/µs edges**; the millisecond subframe is serviced by the cell through the BATFET (90 mΩ max `[V]`) and the cell's DC-IR.

At 0 °C, cell IR ≈ 375 mΩ + 90 mΩ BATFET × 395 mA = **181 mV droop**, putting VDD at ~3.12 V against the SiP's 3.0 V hard floor if the cutoff is 3.3 V. **Brownout during TX at low temperature is a credible field failure** and the 0.90 "RF floor" derate was being asked to cover it silently.

Fix: **discharge cutoff raised to 3.45 V**, DC-IR specified at ≤150 mΩ including PCM, and the actual droop measured at 0 °C on a real cell with a real 295 mA burst before the 0.81 derate is trusted. Decoupling per Nordic's HIG: 4.7 µF + 100 nF at the SiP, 2 × 22 µF 0805 bulk on VSYS **mounted bottom-side beside the SiP** (they are 1.45 mm tall and will not fit the 0.70 mm top-side budget).

### 5.6 Charge and thermal

300 mA (0.54C) → ~2.1 h CC + ~0.4 h CV = **~2.5 h full charge**, against v1's 5.35 h. Dissipation 0.3 A × (5.0 − 3.7) = 0.39 W; body surface 2(27×95 + 27×15 + 95×15) = 90.3 cm²; at h = 10 W/m²K that is a **4.3 K rise**. Thermal has real slack — but h = 10 is a still-air textbook figure and a trouser pocket is not still air. JEITA throttling against an NTC **bonded to the cell, not the PCB**, is mandatory; charging a Li-Po below 0 °C is prohibited.

---

## 6. MECHANICAL

### 6.1 Envelope

**27.0 W × 95.0 L × 15.0 T mm** = 38.5 cm³ bounding box, ~34 cm³ as a 4 mm-radiused capsule, **~48 g**.

| Reference | W × L × T | Volume |
|---|---|---|
| Brief target | 27 × 80 × 15 | 32.4 cm³ |
| Real Sony NW-E405 | 28.8 × 84.9 × 13.9 | 34.0 cm³ |
| **This design** | **27.0 × 95.0 × 15.0** | 38.5 cm³ bbox |

**Width and thickness are exactly the brief.** Length is +19 % over the brief and +12 % over a real Walkman. I am spending it on one thing: an antenna that can certify.

Why 95 and not 86: at 722 MHz, 86 mm is 0.18 λ and 95 mm is 0.22 λ, and low-band radiation resistance climbs steeply through that region. AT&T's Small Form Factor class is **anything under 107 mm in the longest direction** `[V, local att_trp.txt]`, so the length is free in certification terms. **Do not reach 107 mm** — at 107 you fall into Table 3 and the B12 requirement jumps from +10 to +18 dBm, which is unachievable in any version of this object. 95 mm leaves 12 mm of headroom to absorb tooling growth and the antenna Plan B in §9.1.

### 6.2 Millimetre budget

**Length (95.0 mm):**

| x | Zone | mm |
|---|---|---:|
| 0–16.0 | **Crown zone.** Crown protrusion 6.0 + journal/hub 2.0 + press travel 0.25 + wave washer & bulkhead 1.25 + magnet-to-sensor gap 1.3 + satellite PCB 0.6 + tact/component height 2.6 + tolerance 2.0 | 16.0 |
| 16.0–71.0 | **Main PCB zone.** PCB 23 × 55 × 0.8, 6 layers. Display module x = 18–53. LRA + bracket, top side, x = 55–69. Cell 23 × 43 × 5.5 beneath, x = 24–67. nRF9151 **on the top side under the display**. | 55.0 |
| 71.0–72.5 | **Split ring**, moulded PC/ABS, doubles as the halo light guide | 1.5 |
| 72.5–95.0 | **6061-T6 end cap = the radiator.** Zero copper on all six layers for the last 8 mm of PCB; no cell, no fastener, no metal within 10 mm of the split ring. | 22.5 |

**Note on the crown zone:** JEWEL's 9.0 mm crown zone failed because it put the 4.05 mm LRA coin on the same bulkhead and the same centreline as the magnet and the sensor. Moving the LRA to mid-body removes 4.05 mm at a stroke and de-conflicts the axis. The remaining stack is magnet (inside the hub, zero marginal length), sensor on-axis, tact off-axis. 16.0 mm closes with 2.0 mm of tolerance. That is the JEWEL failure fixed by the ENDURANCE topology.

**Thickness (12.6 mm internal behind 1.2 mm walls), per column:**

| Layer | Battery column | SiP column |
|---|---:|---:|
| Chemically strengthened glass lens | 0.50 | 0.50 |
| OCA | 0.15 | 0.15 |
| Frontlight film (reserved) | 0.60 | 0.60 |
| Display module (**Winstar worst case**) | 2.08 | 2.08 |
| Air / foam | 0.20 | 0.20 |
| FPC (**soldered directly, no ZIF**) | 0.60 | 0.60 |
| Top-side components | 0.70 | **1.35** (nRF9151 + solder) |
| PCB | 0.80 | 0.80 |
| Insulator | 0.15 | — |
| Cell | 5.50 | — |
| Swell gap | 0.60 | — |
| **Total** | **11.88** | **6.28** |
| **Margin in 12.6 mm** | **0.72** | 6.32 |

Two fixes taken from the hostile reviews are load-bearing here: **bulk 0805 caps go bottom-side** (1.45 mm tall, will not fit 0.70 mm) and **the display FPC is soldered, not ZIF'd** (a 180° fold on 0.5 mm-pitch polyimide needs ≥1.0 mm and a ZIF body adds 0.9–1.2 mm). With them, the stack closes with 0.72 mm. Without them it is negative, which is exactly where all three source concepts were.

**If the Sharp 0.745 mm panel is secured, 1.34 mm returns** → a 6.5–7.0 mm cell (~700 mAh, pushing typical runtime to 4.4 weeks) or a 13.7 mm body. Closing the display source is the highest-return mechanical action available.

**Undeclared item I am declaring:** a 13.0 mm crown in a 15 mm body protrudes **6.0 mm axially, not radially** — it sits inside the 15 mm silhouette. The object still passes through a 15 mm slot. JEWEL's 12.6 mm coaxial crown in a 13.0 mm body left 0.2 mm per side with nowhere to land an O-ring; 13.0 in 15.0 leaves 1.0 mm per side for the end-cap shoulder and the labyrinth seal.

### 6.3 Antenna strategy

**The gate, corrected.** AT&T IoT Radiated Performance Requirements v1.8, Table 4, Small Form Factor LTE-M `[V, local att_trp.txt]`:

- **B12 (699–746 MHz): +10.0 dBm TRP at PC3, +7.0 dBm at PC5.** TIS −85 dBm.
- **B2 and B4: +12.0 dBm TRP each.** All IoT LTE devices are **required** to support B2, B4 and B12.

ENDURANCE computed the required efficiency as 5.62 % (23 dBm − 0.5 dB feed − 10.0 dBm = 12.5 dB). **That is optimistic on three axes** and the hostile reviewer's correction stands:

| Term | ENDURANCE | Corrected | Why |
|---|---:|---:|---|
| Conducted design power | 23.0 dBm | **21.5 dBm** | 3GPP ±2 dB plus band-edge MPR |
| Feed + match loss | 0.5 dB | **2.0–2.8 dB** | A 5-element high-Q match into Rr ≈ 5–12 Ω, Xa ≈ −j120 to −j250 Ω has network Q of 20–40; 0402 inductors at Q 45–60 give η_match = 1/(1+Q_net/Q_comp) = 0.53–0.72 |
| Certification margin | 0 dB | **2.0 dB** | Channel spread, unit spread, temperature, lab-to-lab |
| **Required total efficiency @ B12** | 5.62 % | **12.3 %** | |

**The honest estimate of what a 22.5 mm cap on a 23 × 55 mm ground plane achieves, loaded by an aluminium-laminate cell, FR4, PC/ABS, glass, a steel LRA can and a metal crown, is 8–18 %, centred ~12 %.** The gate and the estimate are the same number. **Design target 15 %.**

**Power Class: PC3 (23 dBm), not PC5. I am reversing JEWEL and EX here.** Their observation is correct and sharp — PC5 gives free peak-current relief *because the TRP requirement drops 3 dB in lockstep*, so it costs nothing in certification margin. But it is the wrong call for *this* antenna. With a 12 % antenna the device will spend real time in CE Mode A/B, where repetitions multiply time-on-air and energy **linearly**. 3 dB of absolute link margin buys fewer repetitions, and in the deep-coverage stress case repetitions are worth 157 mAh/week — far more than the 85 mA of peak current PC5 would have saved, which we handle with DC-IR and bulk capacitance anyway. **Antenna efficiency and the power budget are the same problem**, and that is the insight neither JEWEL nor EX joined up.

**What I will not say.** I am not going to justify the metal cap with the Chu limit. Both JEWEL and ENDURANCE derived "+3.2 / +4.5 dB of efficiency ceiling" from Chu/McLean, and both reviewers independently showed the derivation is invalid — **Chu bounds Q, not efficiency**; a small antenna can be 100 % efficient if it is narrow enough, and adding loss actually *buys* bandwidth. The reviewers reproduced the arithmetic exactly (ka = 0.636, Q_min = 5.46, FBW = 12.9 %) and refused the inference. They were right. The metal cap is justified by **radiation resistance and current distribution on a physically larger radiating structure, and by a chamber measurement** — not by a bound on Q. Chu's *legitimate* contribution here is narrower and still useful: on a 23 × 55 mm PCB ground alone the usable instantaneous bandwidth is ~48 MHz against B12's 47 MHz span with practical Q running 2–3× Q_min, which is why a single broadband low-band resonance on the bare board is not available. That is a bandwidth argument, and it is the only one Chu supports.

**Keepout, specified as a volume not a copper rule:** zero copper on all six layers for the last 8 mm of PCB; **no cell within 10 mm of the split ring**; no metal fastener, no display tail, no LRA can, no steel keyring in the 22.5 × 27 × 15 mm cap volume or the 8 mm buffer.

**Unmodelled conductors that must go into the EM solver from day one:** the metal crown (a floating parasitic at the counterpoise current maximum, with a hand on it), the LRA's steel can, the aluminium-laminate cell, and the IQS211B's annular electrode. The last one is also an RF *victim*: a large floating electrode near the counterpoise will rectify a 23 dBm TX burst, so the grip channel needs a 2k2 series resistor, a 10 pF shunt, and **TX blanking in firmware**. None of the three source concepts had any of this.

**ESD, which none of them had either:** the cap is exposed, hand-touched, galvanically fed metal going into the nRF9151 ANT pin. It needs a <0.3 pF TVS and a defined DC return. The crown is floating metal over a capacitive electrode and needs the same treatment on the sense line.

### 6.4 Sealing, drop, service

- The crown runs a **0.15 mm visible labyrinth clearance** into a 0.6 × 1.5 mm annular debris chamber, with a greased 1.0 mm silicone O-ring on the hub behind it. Nothing but magnetic flux crosses the moulded bulkhead. Over years the chamber fills; design so accumulated lint cannot bridge to the O-ring.
- **0.50 mm chemically strengthened glass lens, OCA-bonded** into the aperture, so the panel's own glass is never the outer surface. At ~48 g a 1.5 m drop is 0.71 J.
- **Rear shell on 2 × M1.4 torx into brass heat-set inserts, under the crown end cap. Cell on a connector, never soldered.** This keeps EU Regulation 2023/1542 Art. 11 (in force 18 Feb 2027) a legal question rather than a shell redesign. See §9.9.
- **LRA on a bracket tied to the PCB and the cell mass**, not to the rear shell — the ENDURANCE reviewer is right that a hollow gloss capsule driven at 170 Hz off its own shell is an acoustic radiator, and a "silent, intimate" boop audible across a quiet room is a product failure. Measure acoustic output at 170 Hz in an anechoic box before ID sign-off.

---

## 7. THE INTERACTION

### 7.1 Your own petting — no firmware is in this loop

Your thumb and forefinger take the 13 mm knurled cylinder protruding from the end of the stick and turn it. Every 15 degrees — 1.70 mm of knurl travel — two ceramic balls drop into a groove in a hardened race. Twenty-four soft catches per revolution at 2.5–4 mN·m, damped by a greased O-ring so the crown has glide and weight and coasts about a third of a turn before stopping. It does not free-wheel like a fidget spinner and it does not rattle in a pocket.

**Every one of those detents is mechanical. Zero milliseconds, zero microamps, no firmware in the loop, and they still work with a flat battery.** This is JEWEL's best idea and I have taken it whole: *I will not let an LRA render your own detents; 12 ms of rise is 12 ms too many when your own finger caused it.*

Underneath, the MT6701 reports **absolute** angle to better than 0.02° at 100 Hz, so what your partner receives is a continuous velocity curve, not a click count. The felt resolution and the transmitted resolution are deliberately decoupled. The IQS211B sees your hand land on the static electrode ring 200–500 ms before the thumb moves and has already powered the encoder, so the first millimetre is never lost. Gloved or dry hand: the two DRV5032DU latches catch the rotation within 90°. **The wheel is never dead, only occasionally coarse for a quarter turn.**

Press the crown inward 0.25 mm against a conical wave washer onto a real tact dome. That is a boop. It is a snap, not a synthesis.

### 7.2 A boop, sent and received

**Sent:** the creature on the 25.28 × 10.744 mm landscape screen looks up within ~15 ms. That is local; no radio is involved, so it never lags. Then, if the modem was cold, the creature **stretches** — a deliberate 2–6 second wake animation that *is* the RRC connection setup, performed rather than hidden behind a spinner. This is EX's idea and it is the best available answer to the one unavoidable curse of standalone cellular. When the network acknowledges, one 30 ms braked tap lands in the palm and the creature settles. The UI says "sent". **It never says "delivered" and it never says "read".**

**Received:** one 150 ms pulse at 170 Hz, 1.00 Grms into a rigid ~48 g capsule rather than the 100 g inertial sled the datasheet is measured on — a low, round thump through the whole body. Simultaneously the split ring blooms warm over 400 ms, which is the only channel that works when the device is face-down in a pocket. The arrival then **stays on the screen indefinitely with no timeout**, because a memory-in-pixel panel costs 20 µA to keep showing it. That is the detail that makes the object feel alive rather than notified: it is not a notification that expires, it is a thing your partner left on your desk.

**bingbong, the sound the device does not make:** the boop waveform is two transients — one overdrive cycle at 170 Hz, 18 ms of braked decay, a 40 ms gap, then a second softer transient at 60 %. *BING… bong.* The 40 ms gap is why it reads as a word instead of a buzz. It is also why the product can be named what it is named without having a speaker.

### 7.3 Their petting

Their device emits, per detent, `{seq, cumulative_count, direction, inter-detent Δt[], grip_flag}`, coalesced to ≤10 pkt/s over **UDP/DTLS — never TCP**, because one retransmit stalls a caress for 1–2 s. Cumulative counts mean a lost packet self-heals on the next one: latest-state-wins, not an event stream.

Your device replays it through a **150 ms de-jitter buffer that restores their rhythm, not the network's**. Contract: their detent → your click ≤250 ms typical, 400 ms hard ceiling, from ITU-T G.114's conversational budget `[V]`. A mirrored caress is a social event between two people, so the conversational budget governs — **not** the 45–65 ms cross-modal window, which governs your own self-caused feel and would send the team chasing an impossible latency.

Three regimes on one actuator:

- **Slow (<8 detents/s):** discrete clicks. ~30 ms envelope with DRV2625 active braking fighting the 55 ms free fall. Individual, correctly spaced touches. A hand moving deliberately.
- **Fast (>12–15/s):** clicks stop being resolvable — that ceiling is real and we do not fight it. The firmware **crossfades into a purr**: the 170 Hz carrier held at steady amplitude under a 20–30 Hz envelope whose depth and rate track their speed. That construction is literally what a cat's purr is: a carrier in the Pacinian band (peak sensitivity 250–300 Hz) under an envelope in the Meissner band (20–30 Hz). Add ±10 % slow pseudo-random jitter on depth and ±5 % on rate — a perfectly periodic envelope reads as a machine, a slightly irregular one reads as a creature.
- **They stop:** the purr decays over ~600 ms with a slight downward slide. It feels like a breath being let out.

Sessions auto-taper from 15 s and hard-stop at 20 s. That is a power rule dressed as an emotional one: petting is precious and it ends.

**A single actuator, not two.** EX's travelling purr across two actuators 44 mm apart is dead: the shell's first bending mode is ~2105 Hz, 12× above the carrier, so the capsule moves as a rigid body and both actuators shake the same mass identically. You would feel amplitude and spectral change, not localisation. Two-point vibrotactile localisation needs compliantly decoupled contact surfaces, which an OCA-bonded, screwed-shut IP67 monolith specifically does not have.

### 7.4 Presence

The IQS211B gives a stable DC "held" bit within 160 ms from an annular electrode on the **static end-cap shoulder** — not behind the rotating crown, because a steel crown in a POM journal is a textbook triboelectric generator and rotation-induced charge would swamp grip detection during exactly the interaction it is meant to accompany. Your thumb bridges the crown and the shoulder as a matter of course.

When they are holding theirs, your creature leans in. When they let go, it settles.

**Presence is architectural, not a settings screen.** Ephemeral, held in server RAM only, never logged, no duration, no "last seen", no history API, and **strictly reciprocal** — you see theirs only while yours is visible. **No read receipts, ever:** "arrived", never "they saw it". No delivery-failure alert to the sender that can be cited as evidence of non-compliance. Server-side boop rate limiting (~30/hour, coalesced) as a protection. Unbond is unilateral, instant, from the device, wipes local content, and **presents to the other device as the same neutral "away" state as a flat battery** — announcing "you have been blocked" escalates danger.

These are refusals, not toggles, because the coercion model is demand + threat + **surveillance of compliance**, and presence data supplies exactly that third leg. Ship with presence OFF, boops ON.

### 7.5 The character model

**The creature on your screen IS your partner**, not a third being you both keep alive. You cannot feed it and you cannot fail it. **No streaks, no decay, no death, no bereavement flow.** Long-term bonding comes from a permanent visual trait gained every few hundred exchanges and never lost.

Hard rule: **the creature has no negative-valence idle state.** Resting is content. Absence is asleep or away. Never sad, never sulking, never hungry, never dying — because a low-energy creature that represents a *person* invites the inference that they chose not to answer. Exactly two states, "with you" and "away", and no failure mode may editorialise beyond them.

At 3 % battery the device spends **one final packet** to say "going to sleep", so your partner sees sleep rather than silence. That packet costs ~0.05 mAh and converts the most alarming failure into the most reassuring one.

**The object breaks character exactly once.** If service is genuinely broken for >24 h — subscription lapsed, SIM deactivated — it stops being cute and shows a short code and a URL in plain language. Pretending to be sleepy while actually being unsubscribed is a betrayal.

### 7.6 Onboarding without a phone — the competitive weapon

Bond Touch needs an app and an account. Totwoo needs a phone number. Lovebox needs the **recipient's** Wi-Fi password typed into a 192.168.4.1 captive portal, so it "ideally" has to be gifted in person `[V, vendor sources]`. Standalone cellular lets us ship the only device in the category with **literally zero setup**.

- **Factory bonding, the 95 % path.** Sold as a boxed pair. At manufacture both units get eSIM profiles on one subscription group plus a cross-signed key pair in their secure elements. First boot: "hold the crown". Both hold. Both creatures wake simultaneously — **and that works fine 5000 km apart**, over cellular, which is what makes split shipping possible.
- **Re-pair / rename.** The crown is a natural character wheel: turn to select, press to commit, long-press to backspace. ~2 s/char, so a 6-character base32 code (no I/1/O/0) takes ~20 s. Server-issued, 10-minute TTL, one-time, 5-attempt rate limit.
- **Recovery.** A card in the box with a per-device claim code and a URL any browser can use — also how the 8–12 canned messages get co-authored, which must include at least two lines written by each partner. Generic factory copy would be the weakest thing in the product and the thing reviewers quote.
- **Billing.** N years prepaid in the box price. A payment wall on a gift is a disaster, and a subscription-cancellation dark pattern in a love object is worse. Renewal at year N is a cliff that must be handled gracefully or the object dies for a billing reason.

**Logistics:** offer split shipping of a bonded pair at checkout. Never require the two devices to be physically co-located.

---

## 8. WHAT CHANGED FROM V1

| v1 | Now | Why |
|---|---|---|
| ESP32-S2-SOLO-2U + BG95-M3 + TPS62172 (815 mm², 3.2 mm) | One nRF9151 SiP (134 mm², 1.2 mm) | 84 % area, 63 % height. BG95 eDRX @81.92 s is 577 µA vs 132 µA measured — 97 mAh/week of standby on its own. |
| 1.8" 256×32 SSD1326 OLED + R1200 12 V boost | 160×68 memory-in-pixel, single 3.1 V rail | Deletes an entire conversion stage, an inductor and a Schottky. And it makes always-on cost 20 µA instead of ~21 mAh/day. |
| TPS62172 3.3 V buck + R1200 boost (3 conversion stages) | One TPS62840 at 3.1 V (1 stage) | nRF9151 VDD is 3.0–5.5 V and runs straight off the cell. The 12 V rail died with the OLED. |
| Nano-SIM socket (~182 mm² + 13 mm edge clearance + a case aperture) | MFF2 eUICC, 30 mm² | ~152 mm² and the last unnecessary hole in a sealed object. |
| MCP73871 at 100 mA (5.35 h charge), modem hung off the raw cell | BQ25180 at 300 mA (2.5 h) with a 1.5 A / 2.5 A-pulse power path | Fixes both v1 pain points. The 25 V abs max on IN also survives the charge-port fault. |
| 2 × MHF1 connectors + coax, antenna placement binding a 37.5 mm width | One spring-finger feed to a chassis radiator, zero coax | Deletes the routing constraint that set v1's width. |
| GNSS (BG95 + second antenna + LNA) | Not fitted. Silicon present, pin terminated. | Removes the 25 mm separation constraint that was v1's binding mechanical limit — and removes a coercive-control vector from a device given between intimate partners. |
| Cherry MX key (15.6 × 15.6 × 11.6 mm) | 24-detent metal crown + an off-axis 2.6 × 1.6 mm tact | It is the product now, not an input. |
| USB-C receptacle + native ESP32-S2 USB DFU | 4-pin magnetic pogo (VBUS/GND/SWDIO/SWCLK) + LTE-M FOTA | nRF91 has no USB peripheral. A 7.4 mm-deep cavity through a 15 mm body is the most contested hole in the product. The two extra pins buy field recovery and a PPK2 attach point. |
| 26-pin ZIF for the display | 10-pin FPC, **soldered** | A ZIF in a dropped keychain is a latent intermittent, and it costs 1.0–1.2 mm of Z we do not have. |
| 500 mAh cell, 120 × 37.5 mm board | 560 mAh cell, 23 × 55 mm board | 4.5× less board area for 12 % more energy. |

---

## 9. OPEN QUESTIONS AND RISKS, RANKED

Ranked by *kill probability × irrecoverability*.

### 9.1 Band 12 TRP. This is the one that kills the product.

The corrected gate is **12.3 % total efficiency at 699–746 MHz**, not 5.62 %. The honest estimate for a 22.5 mm cap on a 23 × 55 mm ground plane inside a loaded enclosure is **8–18 %**. The gate and the estimate are the same number.

**There is no catalogue fallback, and I want that stated in writing.** Ignion NN02-224 has no published solution below 824 MHz `[V]` and cannot certify B12. Taoglas FXP14 measures 46.2 % at 698–806 MHz **on a bare 2 mm ABS plate in free space** `[V]`; inside this cavity 1–2 mm from an aluminium-laminate pouch, realistic is 3–8 %, below the gate. The DNP MHF4 pad is a **chamber probe**, not insurance.

**The real Plan B, and it is why the body is 95 mm and not 100:** if the metal cap misses, revert to a polymer cap, extend the clearance zone to 32 mm, and fit an **Ignion NN03-310** (30.0 × 3.0 × 1.0 mm, published 698–960 MHz `[V, UM_NN03-310]`) lying **along the length**, not across the board. That takes the body to ~105 mm — still Small Form Factor, barely. ENDURANCE rejected NN03-310 because "at 30 mm it cannot lie across a 24 mm board," which is true and irrelevant in a 95 mm stick.

**Also unbudgeted by everyone: B2 and B4 at +12.0 dBm TRP each are mandatory** `[V]`. A single 50 Ω feed on a 22.5 mm cap must cover 699–746 **and** 1710–2155 MHz. That is a dual-resonant antenna design problem, not five 0402s, and it goes in the consultancy's statement of work on day one.

> **Cheapest settling experiment:** a representative mechanical mock-up — real cap, real split ring, real 6-layer FR4 with the real matching footprint, a real aluminium-laminate dummy cell, the real display module, a real crown, inside a printed shell — measured in a CTIA chamber at 700/750/850/900/1800/2100 MHz. **~$8–15k, 3 weeks.** Measure **three configurations: bare, in-hand phantom, and with a 120 g steel key bundle on the lug.** If bare-chamber comes in under 15 %, stop and redesign rather than iterating the match.

### 9.2 Mobile-terminated reachability may simply not work

A field report on nRF9151 LTE-M found downlink commands published while the device was in RRC Idle **were not delivered by paging at all** — they arrived only on the next uplink, bounded by a 30–60 s keepalive, with operator NAT/firewall behaviour suspected. If MT paging is unreliable on the chosen operator, "adaptive eDRX" degrades to "polling", which changes the power model *and* the data bill. The entire 15.56 + 8.23 mAh/week reachability budget exists for no other purpose.

Recoverable — PSM + 300 s polling costs 2.0 weeks of runtime at 150 s latency — but it is the difference between the product we described and a worse one.

> **Cheapest settling experiment:** nRF9151-DK + PPK2 + three MVNO SIMs (AT&T, T-Mobile, one roaming MVNO), running the actual reachability state machine. Measure: is eDRX granted (`+CEDRXRDP`)? is PSM granted (`+CPSMS`)? is AS-RAI negotiated? **does an MT UDP packet reach a device in RRC Idle at eDRX 163.84 s, and after how long?** **<$2k, 2 weeks.** This is the cheapest high-value test in the whole programme and it should start on day one.

### 9.3 Display supply, and the two specs nobody has read

Sharp LS011B7DH03: **zero authorised stock, 28-week factory lead, ship dates Feb 2027.** The five-figure broker quantities must not be used for production. Winstar WFM0108A2 is buyable in singles but its outline is disputed by 2.8 mm of width and 1.3 mm of thickness, and it mandates a 57–70 Hz EXTCOMIN that must run for the entire week the device is "always on" — if that toggle is generated by anything that stops in deep sleep, you lose the image or DC-bias and permanently damage the LC.

And nobody has opened the **LS011B7DH03's own electrical table**. We are extrapolating IVDD1, IVDD2, fCOM and storage temperature from the LS013. The LS013's Tstg is **−10 to +60 °C absolute maximum**, which a car dashboard in July exceeds routinely.

> **Cheapest settling experiment:** buy **20 Winstar samples from First Components (~€400)**, measure the outline with callipers, and bench-test the actual minimum EXTCOMIN frequency at which the image holds for 72 h. In parallel, request a written Winstar quote with MOQ, lead time and a lifecycle statement, and request the LS011B7DH03 production spec through an authorised Sharp distributor. **~€400 and two phone calls.** Do this in week 1 — it also unlocks 1.34 mm of Z (§6.2).

### 9.4 Does a coaxial crown actually feel like petting?

The brief says "a knurled metal jog dial at one END of the stick." I have built a coaxial crown you **twist** between thumb and forefinger. EX argued, with some force, that a transverse wheel you **stroke** with the pad of the thumb is the gesture that matches "stroking a pet", and that twisting is not. I do not think that is settled by argument.

> **Cheapest settling experiment:** two 3D-printed mules with real journals, real hardened races, real ceramic balls, real O-rings and a real tact — one coaxial, one transverse — plus a VG0840001D on a bracket driven by a DRV2625-DK. **Ten hands, blind, 20-second sessions. ~$3k and 2 weeks.** Decision gate before the shell CAD starts. If transverse wins, the crown zone shortens by ~3 mm and the angle sensor moves to a side-shaft arrangement, which costs a different sensor (MA782 supports side-shaft; MT6701 is on-axis only) — that is a real but bounded respin of the satellite PCB, which is exactly why §4.5 keeps it separable.

### 9.5 The eSIM's 20–60 µA clock-stop trap

Nordic's current-consumption chapter carries an explicit footnote: if the UICC does not support supply shutdown, **add 20–60 µA at 3.7 V** `[V]`. That is up to 10 mAh/week — more than the display, both always-on sensors, the charger and the gauge combined. It is the single easiest way to silently lose a day of battery life, and it is decided by a supplier email nobody sent.

> **Cheapest settling experiment:** a written confirmation of UICC supply-shutdown support and the minimum shutdown interval, from the supplier, before any reel PO. **Free.** Then verify it on the bench with a PPK2 during the §9.2 test.

### 9.6 The coverage-search governor is a specification, not a firmware to-do

The only unbounded failure mode in the design. A modem that cannot find a cell draws 1.72 mA continuously `[V, arXiv 2601.17656 Thingy:91 PPK2]` = 41 mAh/day, flattening this cell in 11 days of a basement or a flight. I have budgeted 20 mAh/week for it; ENDURANCE budgeted 0.86.

> **Cheapest settling experiment:** write the exponential-backoff schedule, the accelerometer/grip "stationary and untouched for N minutes → stop searching" rule, and the maximum permitted search duty cycle **into the requirements document with numbers**, and make it a release gate tested in a shielded box. **Free, and it must happen before firmware architecture, not after.**

### 9.7 The screen is invisible in the dark, which is where the product lives

Reflective, 0.2 % transmissivity. The most likely single use context for a long-distance-couples device is a dark bedroom. The RGB halo carries the "something happened" channel but cannot show a creature's face or a message.

> **Cheapest settling experiment:** 0.60 mm is already reserved in the Z-stack. Get an Azumo quote for a 1.08 in frontlight film in week 1 (cost, MOQ, lead time, added thickness, and the lamination step). A frontlight at ~1 % duty costs under 1 mAh/week, so the decision is entirely about cost, thickness and supply, not power. **Default is to fit it.** If Azumo cannot supply a 1.08 in part, this becomes an explicit, documented product limitation rather than an accident.

### 9.8 Grip sensing may disappoint

IQS211B on a static annular electrode near a floating metal crown, a hand, a cell and a 23 dBm TX burst. Cx of a 22 mm ring a few mm above a ground plane is ~5–15 pF, comfortably inside the 120 pF ceiling — but the RF rectification and the triboelectric charge from the rotating crown are real.

> **Cheapest settling experiment:** a coupon with the real end-cap geometry, the real crown spinning, and a real TX burst from a DK. **~$1k, 1 week.** Reserve two pads and a GPIO for a fallback so it is a stuff option, not a respin. If grip fails entirely, presence degrades to the DRV5032 pair plus a pick-up detector, which costs nothing and already exists.

### 9.9 EU Battery Regulation 2023/1542 Art. 11

From **18 February 2027**, portable batteries must be removable and replaceable by the **end user** with commercially available tools; permanent adhesives blocking the cover are prohibited; spares must remain available 5 years after discontinuation. The wet-environment provision is a downgrade to professional replacement, not an exemption, and the Commission applies it narrowly. A Delegated Act has added exemptions reportedly covering compact and shock/water-resistant wearables.

> **Cheapest settling experiment:** a written legal opinion on whether a 27 × 95 × 15 mm sealed keychain object qualifies. **~$3–5k.** Must land **before the shell is frozen**, because a glued capsule and a user-openable door are different products and the door costs ~1.5 mm of thickness and most of the jewel. The screwed-rear-shell-plus-connectorised-cell architecture keeps both doors open at low cost in the meantime.

### 9.10 nRF9151 lead time will make the decision for us

16–19 weeks factory lead, 0 stock at DigiKey/Avnet/element14, Mouser 283 units, Octopart flagging −48.7 % three-month inventory `[V?]` — and note that distributor figures throughout this corpus are search-summary-derived because DigiKey returned HTTP 403 to every direct fetch.

> **Action, not an experiment:** place the 2k reel PO against the lead-time clock **before the schematic is finished**, or the part choice gets made for us. Order the 500-pc `-R7` for prototypes at the same time.

### 9.11 Lower-ranked but live

- **MT6701 single-source.** Mitigated by the dual-variant satellite PCB (§4.5). ~$300.
- **LRA acoustic radiation.** Anechoic box measurement at 170 Hz before ID sign-off. ~$500.
- **Press force independence from thumb position.** Measured on the §9.4 mule, not argued.
- **Detent life.** 1,000,000 indexes on a motorised rig with a torque-decay limit. ~$4k.
- **MAX17048 battery model INI.** Ship cells to ADI early; without it SoC is ±15–20 %.
- **Cell PCM trip point and DC-IR at 0 °C.** Measured, on a real cell, with a real 295 mA burst.

---

## 10. WHAT TO PROTOTYPE FIRST

**EVM-0: three mules, run in parallel, before any schematic freeze. ~$30k, 6–8 weeks.**

They are deliberately separate because the three biggest unknowns are independent and the cheapest one answers fastest.

### Mule A — the network mule (start day one, ~$2k, 2 weeks)

nRF9151-DK + PPK2 + three MVNO SIMs. No custom hardware at all.

Answers: Is eDRX granted, and at what cycle? Is PSM granted? Does AS-RAI negotiate? **Does a mobile-terminated UDP packet reach a device in RRC Idle at eDRX 163.84 s, and after how long?** What is the *measured* per-paging-occasion energy — the 92.6 µA field figure that carries 12 % of the power budget, or Nordic's published 18 µA? Does the eSIM's UICC support supply shutdown in practice?

**This is the highest value per dollar in the entire programme** and it tests the central product promise ("their boop reaches you") without a single custom part. It also produces the PPK2 baseline against which every later firmware build is checked for the +600 µA debug-UART regression.

### Mule B — the RF mule (~$20k inc. chamber, 5 weeks)

A **non-functional** mechanical representation: machined 6061 cap, moulded or machined split ring, a 23 × 55 mm 6-layer FR4 board with the real matching footprint and real ground pour, a real aluminium-laminate dummy cell, the real display module, a real non-magnetic crown with a real magnet, an LRA can dummy, inside a printed shell. Feed through the real spring finger onto the real masked Ni/Au pad.

Chamber: **bare, in-hand phantom, and with a 120 g steel key bundle** at 700/750/850/900/1800/2100 MHz.

Gate: **≥15 % total efficiency bare at 699–746 MHz.** Under 15 %, do not iterate the match — go to Plan B (polymer cap, 32 mm clearance, NN03-310, 105 mm body) and re-measure.

### Mule C — the feel mule (~$4k, 3 weeks)

Two 3D-printed crown-end assemblies — one coaxial, one transverse — with real POM journals, hardened 17-4PH races, ceramic balls, BeCu leaf springs, O-rings and tacts, plus a VG0840001D on a bracket driven by a DRV2625-DK from a scripted waveform set.

Answers: coaxial-twist vs transverse-stroke, on ten hands, blind. Detent torque target and its decay over 100k indexes. Click separation at 8, 12, 15, 20 detents/s with active braking on a real ~48 g mass — which is the measurement that decides whether the click→purr crossfade is a designed transition or a papered-over failure. Press force independence from thumb position. Acoustic output at 170 Hz.

### What EVM-0 does *not* do

No custom PCB with an nRF9151 on it. No firmware beyond the reachability state machine on a DK. No shell tooling, no glass, no OCA, no eSIM provisioning, no certification. **Nothing that costs money is committed until Mule B reports**, because if the antenna misses, the shell architecture changes and everything downstream of it is scrap.

### Gate to EVM-1

All three must pass before a custom board is laid out:

1. Mule A: eDRX granted **and** MT paging delivers on at least two of three carriers, or a documented polling fallback with its measured energy cost.
2. Mule B: ≥15 % bare-chamber B12 efficiency on the metal cap, **or** a Plan B configuration that achieves it.
3. Mule C: a chosen dial geometry, a measured detent torque, and demonstrated click separation to ≥12/s.

Plus two paper items on the same clock: the Winstar mechanical drawing in hand, and the EU battery-regulation legal opinion delivered.

---

## Appendix: things I am deliberately leaving dead

Each of these was proposed in the corpus, killed under hostile review, and stays killed. If someone wants to reopen one, they need to refute the specific finding, not re-argue the benefit.

| Killed | Finding that killed it |
|---|---|
| Phantom tactile motion / second actuator | Shell's first free-free bending mode ~2105 Hz, 12× the carrier; the capsule moves as a rigid body |
| Colour IPS TFT | 18 mA cell-side = 42 mAh/week; kills always-on, which is the entire "alive" thesis |
| Any OLED | ~7–12 mA from the cell, plus 20,000 h to 50 % luminance with a static element on a gift object |
| E-paper | 300 ms partial refresh is 3 fps at best, with a visible smear. Petting cannot be rendered. |
| Piezo / TDK PowerHap + BOS1921 | 0 stock at DigiKey, $99.99 at a broker, 60–190 V next to a Li-ion cell in a pocket |
| Ignion NN02-224 as the B12 antenna | Published cellular-IoT solution is 824–960 MHz; B12 is 699–746 |
| The Chu limit as an efficiency argument | Chu bounds Q, not efficiency; adding loss *increases* bandwidth |
| nPM1300 | BCHGISETDISCHARGE "Low" resets on every TX; forces low-accuracy gauging; light-sensitive WLCSP; a DevZone erratum worth 100 µA |
| nPM1304 | 210 mA discharge limiter against a 295 mA TX subframe. It would brown out on every transmit. |
| Onomondo SoftSIM as primary | SPDX GPL-3.0-only, no confirmed commercial licence, ISR-context APDU handler |
| Alps EC05E / any contact encoder | 100,000 cycles ≈ 11 months at 300 rev/day, on the defining interaction of a gift object |
| Microchip MTCH101 | 54 µA at 3.3 V, not the 4 µA the internet says. Datasheet Table 8-2. |
| Any gyro (LSM6DSV16X, BMI270) | No feature in this product needs one; 420 µA in A+G low power is 70 mAh/week |
| ADXL362 | $7.62 to save 2.4 µA = 0.4 mAh/week. Indefensible in a gift-object BOM. |
| GNSS | 43.1 mA tracking, a second antenna site that does not exist, and a coercive-control vector |
| Microphone | Non-negotiable. A love object that can listen is a bug. |
| Qi charging | Largest coil that fits is ~22 mm against a 30 mm derated reference; and the metal crown trips foreign-object detection by design |
| 2-pin pogo | One bad FOTA bricks a sealed object with no reflash path and no PPK2 attach point |
| Qvar on the rotating crown | A steel crown in a POM journal is a triboelectric generator; rotation charge swamps grip during exactly the gesture it accompanies |
| 440C detent balls | Martensitic and ferromagnetic, millimetres from the sensing magnet |
| 303SS as a ball-detent race | ~170 HV annealed; two balls brinell soft grooves long before 800,000 indexes |

## ADDENDUM 2026-09-13 — Programming, debug, and charge interface

**Status:** decision, recorded from the 13 Sep review. Amends the §4.3 "Charge / debug" row and §8 row 9. Nothing else in the body changes.

### A.1 The two ways in

Only two paths reach the nRF9151: **SWD over the dock pads**, and **LTE-M FOTA through MCUboot**. No USB receptacle, no UART pad. Console and shell are SEGGER RTT over the same two SWD lines in development builds. The UART console is compiled out of every build (§5.4: +600 µA `[V]`), and RTT logging out of the production image.

### A.2 The dock interface, specified

| Item | Decision | Tag | Why |
|---|---|---|---|
| Pads | 4 × flat pads, single row, **2.54 mm pitch**, order **GND · SWCLK · SWDIO · VBUS**, gold over 1.0–2.5 µm Ni (unchanged) | `[V]` pitch is the wearable-charger de facto standard | Power at the two ends: a head pressed on backwards maps VBUS↔GND (blocked by the reverse FET) and SWDIO↔SWCLK (harmless). |
| Pad location | Rear face, mid-body, **x ≈ 40–52**, over the cell | `[U]` | ≥10 mm from the split ring (§6.2 metal exclusion) and >20 mm from the satellite PCB's Hall latches and the sensing magnet. The main PCB is on the display side of the cell, so these pads are on a **flex tail bonded behind four sealed openings in the rear shell**. The flex lives in the 0.60 mm swell gap; budget its thickness in §6.2 before the stack is called closed. |
| Ferromagnetic target | **0.3 mm 430 stainless shim, insert-moulded in the 1.2 mm rear wall behind the pads. Not a magnet.** | `[U]` | The head carries the magnets. A magnet in the device costs Z the battery column does not have (0.72 mm margin), and anywhere nearer the crown it sits within reach of two 3.9 mT Hall latches and a 14-bit angle sensor. A shim in the wall costs nothing inside. |
| Polarity | Enforced by the **dock cradle geometry** — the crown end and the metal cap are different shapes — not by magnet repulsion. | — | Repulsion needs a device-side magnet, ruled out above. |
| SWD pad protection | Series resistor plus a 3.3 V-class low-capacitance TVS on SWDIO and SWCLK, at the pads | `[U]` values at schematic | The existing short protection covers VBUS/GND only. While docked, a key bridging the live VBUS pad to an SWD pad puts 5 V on a 3.1 V GPIO; the clamp takes it instead. Keep clamp capacitance low enough for 4 MHz SWD. |
| Dock head | Wearable-charger-class magnetic pogo head (Sunmon 901-00001 / Jiatel 2.54 mm 4P / CFE / Good-Link class): pogos **and** magnets in the head, 2.54 mm, 1–2 A rated, 300–500 g pull, ≥30k cycles, USB-C fed | `[U]` MPN; vendor quotes are against their own steel plate | Catalogue two-half connectors — Adafruit 5358, Adam Tech PH1-3L-04-FVMP-4560, ATTEND 303C-C4115-30-04, EDAC POGO+ — all put a housed receptacle in the device. That is a cavity again, smaller than USB-C but still a hole and a lint trap. The wearable head mates to bare pads. |
| Dock board | USB-C receptacle with 5.1 kΩ Rd on CC1/CC2; 5 V straight through to the head, current-limited so a key across the live head pins is harmless; **3.3 V LDO driving VTref on a 10-pin Cortex debug header**; SWDIO/SWCLK passed straight through | `[U]` | A four-wire head has no pin for VTref and a J-Link will not talk without it, so the dock supplies it. The header is what EVM, service, and the PPK2 plug into. ~$6/unit as already costed in §4.6. |
| Bench jig (EVM-1) | Adafruit 5412 cable with the USB-A end cut off and rewired to a Cortex header, or an Adam Tech / ATTEND pin half, on a printed cradle against the same pads, VTref from a bench 3.3 V | — | $5–10, no custom parts. SWD at 1–4 MHz over a metre of unshielded four-wire is fine. |
| Production programming | The same four pads on a bed-of-nails, bare board, before the rear shell closes: MCUboot + app + modem firmware in one pass, then APPROTECT locked. A Tag-Connect TC2030 footprint is optional if the 23 × 55 board has room; it is not required. | — | A locked unit is still recoverable through the dock with `nrfutil device recover`, by full erase only — the right property for a sealed, field-serviced object. |

### A.3 USB-C: not fitted, and what would bring it back

Deleted per §8. If it returns, it returns in exactly one form: **power-only USB-C** — 5.1 kΩ Rd pulldowns, D+/D− unconnected, SWDIO/SWCLK on **SBU1/SBU2** with clamps, IP67 receptacle gasketed to the shell. D+/D− are never used for SWD: BC1.2 dedicated-charging-port adapters short D+ to D−, which would short SWDIO to SWCLK the first time a C-to-A cable is used.

Any one of these reopens the decision: (1) counsel reads EU 2022/2380 Annex Ia as covering this object; (2) Mule B fails B12 and the shell moves to the 105 mm polymer Plan B, which has room for a cavity; (3) user research says a proprietary dock blocks gifting. **One port or the other, never both** — two charge ports carry both sets of problems and the dock cost.

### A.4 Firmware path

nRF Connect SDK on Zephyr, sysbuild with MCUboot, external-flash secondary slot per §4.1. Modem firmware is flashed over the same SWD link. **Field modem updates are delta only:** a full modem image does not fit in a 16 Mbit NOR beside the app slot, so either accept delta-only or size the NOR up at BOM freeze. Dev builds: `CONFIG_LOG_BACKEND_RTT`, `CONFIG_SHELL_BACKEND_RTT`; every build: `CONFIG_UART_CONSOLE=n`. All of this is brought up on Mule A (nRF9151-DK + PPK2) first; the custom board definition is built against that tree so EVM-1 adds only the pin map and the dock cable.

### A.5 Added to the §4.4 confirm-before-design-in list

9. **Dock head MPN and its measured pull force against a 0.3 mm 430 shim through a 1.2 mm wall.** Vendors quote against their own plate.
10. **Flex-tail thickness in the swell gap.** §6.2 closes at 0.72 mm in the battery column; the flex spends some of that.
11. **SWD clamp capacitance vs. programming speed**, verified on EVM-1.

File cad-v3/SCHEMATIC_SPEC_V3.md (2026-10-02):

# bingbong v3 — schematic gap analysis and spec

Date: 2026-09-23
Basis: `REDESIGN_DECISION_2026-09-12.md` (architecture) as overridden by `DESIGN_MANUFACTURING_REPORT_2026-09-19.md` §0.3 (on-demand AMOLED) and §6 (electronics domain, E-1…E-17). Where the two disagree, the 09-19 report wins.
Compared against: v1 `firmware/bingbong_pcb/bingbong.kicad_sch` (ESP32-S2 + BG95) and the abandoned v2 `cad-v2/bingbong/bingbong.kicad_sch` (ESP32-S3 + BG95 + W25Q32 — same v1 architecture, not carried forward).

Evidence tags follow the decision document: `[V]` primary source read, `[V?]` read once or contested, `[U]` nobody has opened the source.

---

## 1. Verdict

v3 is a clean-sheet schematic. **No v1/v2 circuit block survives electrically.** Every major IC changes, the power topology inverts (modem/MCU straight off VSYS instead of a 3.3 V buck), and the board goes from 120 × 37.5 mm to 23 × 52 mm 6-layer 0.8 mm with an LGA SiP. What carries over is the *lessons* from the v1 reviews (section 3), a handful of footprint-library entries, and the naming/ERC hygiene.

Start v3 as a new KiCad project (`cad-v3/bingbong/`), hierarchical, one sheet per E-step block. Do not edit v2 into v3.

---

## 2. Block-by-block: v1 → v3

| Block | v1 / v2 (current schematic) | v3 (spec) | Action |
|---|---|---|---|
| MCU | ESP32-S2-SOLO-2U (v2: ESP32-S3 + 40 MHz XTAL + W25Q32) | **nRF9151-LACA-R** (MCU + LTE-M + RF FE + PMIC + crystals in one LGA 12.1 × 11.1 × 1.2) | Delete. New symbol + footprint from PS v1.0. |
| Cellular modem | Quectel BG95-M3 + 1.8 V LDO (MIC5504) + SN74AVC2T245 level shifter + Q1 PWRKEY transistor | Inside nRF9151 | Delete U2, U3, U7, Q1, R1 and all UART translation. |
| GNSS | BG95 GNSS + 2nd antenna/MHF1 | **Not fitted**, pins terminated per HIG | Delete. |
| SIM | Nano-SIM socket J7 + 3 × ESD + card-detect to MCU | **MFF2 eUICC** DFN-8 5 × 6, ISO 7816-3 **Class C 1.8 V**, ≤ 10 mm from SiP; HIG series/shunt filter | Delete J7/CR1-3. New footprint; MPN `[U]`. |
| Charger | MCP73871 @ 100 mA, THERM via TH1 JST + DNP R24 | **BQ25188YBGR** (DSBGA-8, successor to BQ25180, SLUSFJ3 `[V]`): 300 mA set in FW after NTC read; **combined TS/MR pin** (NTC + crown button, see §9.1); /INT → nRF; I²C 0x6A | Delete U8 + network. New. |
| Fuel gauge | none | **MAX17048G+T10**, VDD **on BAT** (not V3) | New. |
| Regulation | TPS62172 3.3 V buck from SYS (fails at low cell) + MIC5504 1.8 V | **TPS62840DLC → V3 = 3.1 V**, the only general rail. nRF VDD straight from VSYS (3.0–5.5 V) | Replace. Fixes v1 critical C3 by design. |
| Display | ER-OLED018-1 256×32 SSD1326 PMOLED, I²C, 26-pin ZIF | **1.1" 126 × 294 AMOLED module, off the shelf**: iFan IF011TPS12-29 (RM69310, 27-pin) or OSPTEK AM110Q126294LK1 (ICNA3306, 24-pin) — see §9.3; 4-wire SPI | Replace. Pick the module first; the two are **not** pin-compatible. |
| Display power | R1200 12 V boost + L2 + Q2/Q3 switch | **TPS65631DPDR** (§9.2) → ELVDD +4.6 / ELVSS per panel (−2.4 V on the OSPTEK module) + **two 4.7 µH inductors** + **two TPS22916C load switches** (A: V3→VCI/VDDIO, B: VSYS→PMIC VIN) | Delete R1200 chain. New. |
| Charge / debug port | USB-C (J2) + CC Rd + TPD2EUSB30A + native USB | **4-pad magnetic pogo** GND·SWCLK·SWDIO·VBUS on a lid flex → 5-way 0.4 mm B2B (5th = jig ID) | Delete USB-C block. New dock sheet. |
| Input | Cherry MX key / TS04 tact | Crown on a **satellite PCB**: MT6701 (or AS5600L variant) + 2 × DRV5032DU + EVPBB-class tact, over a 10/12-way 0.5 mm tail | New (separate board). |
| Grip | none | **Azoteq IQS211B**, buried 316L ring electrode, 2k2 + 10 pF | New. |
| Haptics | none | **DRV2625** → Vybronics VG0840001D LRA | New. |
| Light | discrete LEDs | **PLCC-4 RGB halo**, common anode VSYS, 3 × SOT-523 N-FET on hardware PWM | Replace. |
| Flash | ESP internal (v2: W25Q32 as ESP boot flash) | **16 Mbit SPI NOR** (MX25R1635F class) on shared SPIM — MCUboot slot 1 + assets | New role; MPN `[U]`. |
| Antenna | MHF1/u.FL to external antenna | Metal end-cap radiator via SMT spring finger; **MM8130-2600** switch connector; 10 × 0402 dual-resonant match; ≤ 0.3 pF TVS; L_dc | New RF sheet. |
| Battery | 2-pin JST, ~500 mAh | 23 × 43 × 6.0 mm pouch, 560–620 mAh `[U]`, PCM, 10 k NTC, **3-way B2B** (B+, B−, NTC) | Replace connector. |

### What actually carries over from v1/v2

- **Nothing electrical.** Possibly the 10 k β3435 NTC convention and 0402 passive footprints.
- `Bingbong_library` — keep the library *structure*; none of its current parts (BG95, ESP32-S3, TS04 tact, Cherry MX, XRCGB40M crystal, the Molex connectors) are used. Start `Bingbong_v3` library fresh.
- Design-rule file `bingbong.kicad_dru` — does not apply (v3 is 6-layer HDI with via-in-pad). Write new rules against the fab's HDI capability.

---
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

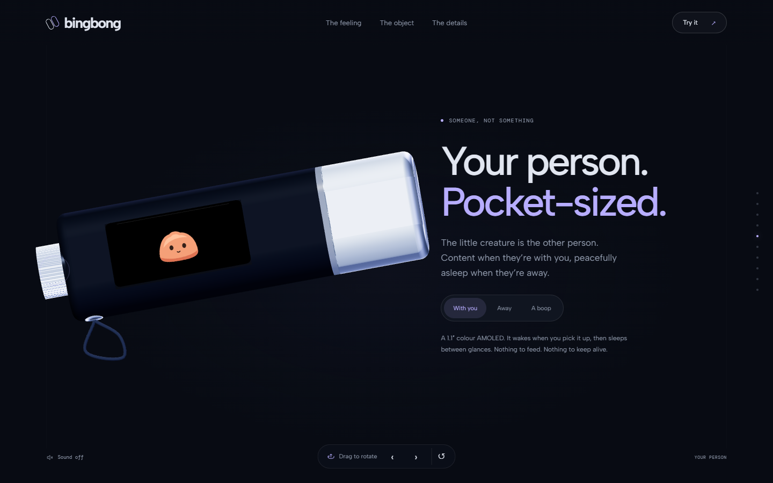
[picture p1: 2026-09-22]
site/qa/redesign/reviewer/creature-1440.png

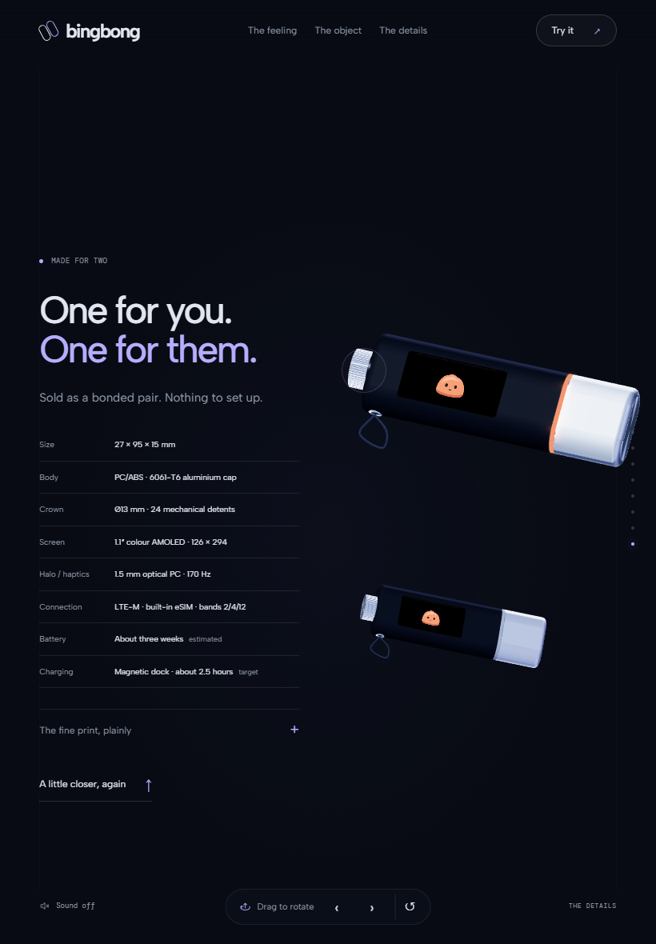
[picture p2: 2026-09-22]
site/qa/redesign/reviewer/details-820.png

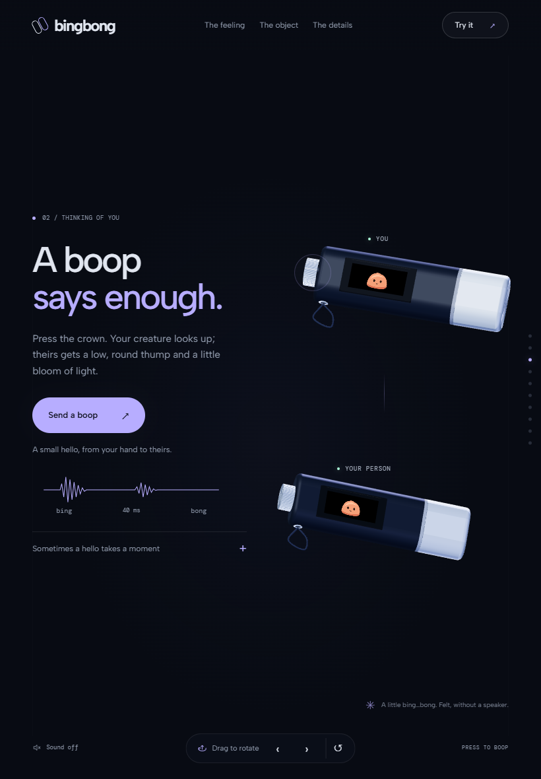
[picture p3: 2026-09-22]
site/qa/redesign/820-boop.png

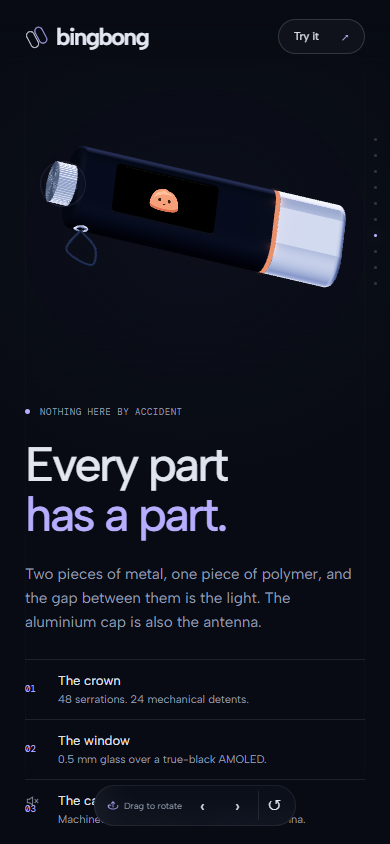
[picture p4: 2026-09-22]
site/qa/redesign/reviewer/object-390.png

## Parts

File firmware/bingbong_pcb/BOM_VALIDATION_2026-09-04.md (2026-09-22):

# Bingbong BOM Validation - 2026-09-04

**BOM under review:** `bingbong_pcb/BOM_2026-09-04.csv` - 48 lines, 104 reference designators, 8 DNP
placements, 96 purchasable placements across 46 lines resolving to **39 distinct usable MPNs plus 4
lines with no MPN at all**. Regenerated 2026-09-04 from the current schematic, MPNs merged forward by
refdes from the stale 2026-03-16 workbook.

**All stock figures are snapshots observed 2026-09-08 unless stated otherwise. They will move. Re-pull
before any PO.**

> **Session caveat.** This report is assembled from six research passes plus verification. The working
> copy (`C:/Users/chian/Desktop/bingbong_software/bingbong_pcb/`) was **not accessible** when this
> document was written, so every claim sourced to a local file (`bingbong.kicad_pcb`,
> `bingbong.kicad_sch`, `_t12.nets`, `_dsx/*`, `_bg95.pdf`, `_r1200_ds.txt`, the `_bomaudit_*.py`
> scripts) is carried forward from the passes that did read them and is marked accordingly. Web-sourced
> lifecycle and stock claims carry their URLs and were independently checked.

---

## THE CONCLUSION, FIRST

**Do not order from this BOM, and do not send this board to fab.** Two independent failures:

1. **The MPN column is wrong on at least seven lines.** Value changes made on 2026-09-04 did not
   propagate through the carry-forward merge - only deletions did. C6/C21 are off by 1000x, L1 is the
   wrong value *and* package *and* component class, C10/C13 and C15 are the wrong package and voltage,
   R11/R13 carry the old 1 k, and the nine-resistor 100 k line carries two contradictory part numbers
   in one cell.
2. **`bingbong.kicad_pcb` was never re-synced with the 2026-09-04 schematic.** 28 parts the BOM buys
   have no footprint on the board - the entire RF pi (C30-C43), five of eight ESD diodes (CR4-CR8),
   the GNSS connector J8, and R24/R31-R37 - while all nine parts deleted today are still placed. A CPL
   exported today would instruct the assembler to fit the exact nine parts you cancelled and silently
   omit 28 BOM lines. `[SUSPECTED - local-file analysis, not re-verified in this session. Run
   Update PCB from Schematic and read the change list; it takes one minute and settles it.]`

The BOM is internally consistent with the schematic (104/104 refdes, quantities, values, footprints and
DNP flags all check out). It is inconsistent with the artifact a fab actually builds from, and its MPN
column is not trustworthy.

---

## 1. BLOCKERS - fix before ordering anything

| Refs | Current MPN | Problem | Action |
|---|---|---|---|
| **PCB (all)** | n/a | Layout never re-synced. 28 BOM parts unplaced (C30-C43, CR4-CR8, J8, R24, R31-R37); 9 deleted parts still placed (C12, C19, C20, Q2, Q3, R10, R29, R30, U7); one stray `REF**`. PCB also records Q2 as **FDN340P** while the workbook ordered **FDN338P**. | Update PCB from Schematic (F8) with "delete extra footprints", re-route, re-DRC, then regenerate BOM **and** CPL from the same post-sync database. Substantial layout work - the RF pi and GNSS path are unplaced. Hold PCB1 + stencil until done. |
| **C6, C21** | `C0603C101K5RACAUTO7411` | **1000x error.** `C101` = 10x10^1 pF = **100 pF**; 0.1 uF is `104`. The row's own LegacyDesc already reads "100 pF ±10% 50V X7R 0603" and contradicts its Value cell. These are the +3.3 V bypass for the ESP32-S2 module (U10 pin 2) and the SN74AVC2T245 VCCB. **`7411` is a real bulk-pack suffix, so a pasted PO orders the wrong part rather than erroring** - worse, not better. | Replace with **C0603C104K5RACTU** (0.1 uF ±10% 50 V X7R 0603, Active, ~8.4 M @ DigiKey). Alt: Samsung **CL10B104KB8NNNC** (DigiKey 1276-1000-1-ND, Active, LCSC C1591). If you want the same packaging code, **C0603C104K5RAC7411** is a one-character-group edit. Strip `7411` from the MPN column BOM-wide. |
| **L1** | `MLZ1608A2R2WTD25` | **Four defects on one line.** Schematic 3.3 uH / L_1008_2520Metric; MPN is 2.2 uH, 0603, and a **multilayer ferrite decoupling** part, not a power inductor; **and the PCB still carries L_0603_1608Metric / 2.2 uH**. Duty is the TPS62172 switch node (ILIMF 1.35 A max). TDK's own page rates MLZ1608A2R2WTD25 at **130 mA** rated current (DigiKey shows 500 mA - that is saturation) - roughly 4.6x under-rated. | **Murata DFE252012F-3R3M=P2**: 3.3 uH ±20%, DCR 135 mOhm max, Isat 2.5 A max, Itemp 1.8 A, 2.5x2.0x1.2, shielded flat-wire metal-alloy, -40..+125C. LCSC 5,140 @ $0.197. Second source **TDK VLS252012HBX-3R3M-1**. **Fix the PCB footprint - the layout is the real blocker.** Note z-height grows 0.8 -> 1.2 mm. **Reject DFE201610P-3R3M** named in the change note: it is 2.0x1.6 mm and does not fit a 2520 land. |
| **R2, R6, R9, R15, R16, R31, R32, R33, R35** | `RC0402JR-0710KL/RE0402FRE07100KL` | Two part numbers in one cell. `RC0402JR-0710KL` = **10 k ±5%** (10x error). `RE0402FRE07100KL` = 100 k ±1%, electrically correct, but Yageo RE is a low-volume precision grade with no readable stocked listing. At **R33** (top leg of the MCP73871 VPCC divider) fitting 10 k moves the foldback knee from 4.29 V to **1.54 V** and silently disables the feature. | Specify **RC0402FR-07100KL** (100 k ±1%, 0402, Yageo RC thick film, 100 ppm/C). LCSC C60491, 3,594,500 in stock; DigiKey 726526; deep multi-source. Strike `RC0402JR-0710KL` from this line. Do not accept a 5% part - R33 needs 1%. |
| **C10, C13** | `GRM158R60J226ME01D` | Schematic footprint is **0805**; part is **0402, 6.3 V**. 6.3 V is wrong for a 3.3 V-bias 22 uF (retains ~20-30%, i.e. 4-7 uF *estimate*) - the reason the schematic moved to 0805. Murata also flags this part "Limited Application: for consumer equipment only". Same MPN as deleted C20. | **GRM21BR61C226ME44L** (22 uF ±20% **16 V** X5R 0805). DigiKey ~111,494; JLCPCB C86817. 16 V derates least at 3.3 V. Avoid the 10 V sibling GRM21BR61A226ME44L - contradictory stock reads on the same day. |
| **C15** | `GRM155R61A106ME11D` | Schematic footprint **0603**; part is **0402, 10 V**. C15 is the raw **USB VBUS** bypass (all four J2 VBUS pins + both MCP73871 IN pins). 10 V on VBUS is only 2x, and hot-plug ringing overshoots. At 5 V bias it holds ~2-3 uF (*estimate*) of a marked 10 uF. | **GRM188R61E106MA73D** (10 uF ±20% **25 V** X5R 0603). Mouser 1.5 M / DigiKey 1.15 M / LCSC 384 k, Active. Second source Taiyo Yuden TMK107BBJ106MA-T. Use the same part at C8 and merge two lines. |
| **R11, R13** | `AF0402JR-071KL` | Value changed 1 k -> 680 R; MPN is still the **1 k** part, and the row's own LegacyDesc says "1 kOhms ±5%". Worse: **the same MPN is legitimately on the R3/R12/R36 1 k line**, so anyone consolidating by MPN orders 5x 1 k and nothing for the 680 R positions, with no error raised. | **RC0402FR-07680RL** (680 R ±1%, 0402). **Do NOT order `AF0402JR-07680RL`** - that PN was constructed by decoding the AF series convention and could not be found at any distributor. Verified 680 R 0402 alternatives: RC0402FR-07680RL (DK 726654), AC0402FR-07680RL (DK 5895472, AEC-Q200), RC0402JR-07680RL (RS 1995428). |
| **J5 + display** | `--` (connector), no line at all (display) | The entire display subsystem is unbuyable from this file. J5's MPN cell is literally `--`; the **ER-OLED018-1 panel does not exist as a BOM line** despite being the second most expensive item in the build (~$11.21) after the BG95. | Add both as explicit lines - see §2. |
| **TH1** | `ND03N00103K--` | **Three-way mismatch.** MPN is a radial leaded 10 k NTC **disc** (3.5 mm dia, 2.54 mm lead pitch, 35 mm leads). Schematic footprint is `Connector_JST:JST_PH_B2B-PH-K_1x02_P2.00mm_Vertical` - a **2.00 mm JST PH connector land** the leads cannot fit. PCB footprint is a third thing: `PinSocket_1x02_P2.54mm`. SchDescription says "External battery NTC **connector**". The trailing `--` is legitimate (Kyocera bulk packaging code), not corruption. | Decide what TH1 is. Most likely a **connector**: buy **JST B2B-PH-K-S(LF)(SN)** (DigiKey 926611 / 608703, LCSC C131337) and add a separate off-board pigtail line (NTC + PHR-2 + 2x SPH-002T-P0.5S). Delete the ND03 from the placement line. Separately: no RT1/RT2 network exists, and this NTC's beta is 4080 vs Microchip's 3892 worked example - the THERM window is currently **undefined**. Recompute per MCP73871 §6.0 or populate R24 and accept that thermal qualification is off. |
| **C26, J2** | `8.85012206055E11`, `1.054500101E9` | **Excel float coercion.** Arithmetic confirmed exactly: `float("8.85012206055E11") == 885012206055` (Wurth 220 pF 25 V X7R 0603) and `float("1.054500101E9") == 1054500101` (Molex USB-C receptacle). Unorderable as written. Same coercion destroyed LegacyPkg BOM-wide (`402.0`, `603.0`, `805.0`, `1206.0`). | Rewrite both cells as text; format MPN/DigiKey/LegacyPkg as strings on export or stop round-tripping through .xlsx. **Recoverable in the meantime** - both rows still carry valid DigiKey PNs (732-7974-1-ND, WM12856CT-ND). |

---

## 2. Parts with NO source yet

| Item | Recommended MPN | Price / lead | Confidence |
|---|---|---|---|
| **Display module (no refdes; legacy row 49)** | **ER-OLED018-1W** (white) or `-1B` (blue), EastRising / buydisplay. 1.8in 256x32, SSD1326U3R1, -40..+85C, **integrated FPC tail - no separate FFC cable needed**. | US$11.21, ~$10.00 in volume; >500 pcs needs a quote. **No published lead time.** | `[SUSPECTED]` buydisplay.com returns HTTP 403 to automated fetch; price is from a search-index snapshot 2026-09-08. **No manufacturer lifecycle status is published** - "listed and priced" is not "Active". Sole-source, zero authorized distribution. https://www.buydisplay.com/white-1-8-inch-256x32-oled-display-module-serial-i2c-and-ssd1326 |
| **J5 ZIF connector** | **ER-CON26HT-1**, 26-pin 0.5 mm, **CONFIRMED TOP contact** (the `HB` sibling is bottom). | Legacy $0.16 - **unverified and carried forward**. MOQ/lead unknown. | `[CONFIRMED]` top/bottom orientation from buydisplay's own page titles. `[UNVERIFIED]` price/stock/lead - findchips returns **zero** legitimate hits across all authorized and independent distributors. https://www.buydisplay.com/26-pin-0-5mm-pitch-top-contact-zif-connector-fpc-connector |
| **J5 second source** | **Hirose FH12A-26S-0.5SH(55)** = **TOP** contact, 2.0 mm high, 6.2 mm deep, DigiKey 1,940 @ $2.37/1, Mouser 1,132. Bottom-contact sibling FH12-26S-0.5SH(55): Mouser 3,510, Newark 2,058 @ $1.83. | ~$1.90-2.60 vs the claimed $0.16 - buys an authorized supply chain and a documented land pattern. | `[CONFIRMED]` The project's own `Conn_Zif_26Pin.kicad_mod` has 26 pads at 0.5 mm spanning exactly **12.5 mm**, matching Hirose's 26-pos contact span. Check ear span (16.1 vs 16.35 mm) and body depth (5.6 vs 6.2 mm); leave 6.2 mm keepout so either fits. FH12 is rated **20 mating cycles** - do not re-seat the FPC repeatedly at bring-up. **Avoid plain FH12-26S-0.5SV (no suffix) - obsolete.** |
| **E2 - cellular antenna (J3 / BG95 ANT_MAIN)** | **TE/Linx ANT-LTE-RPC-UFL**. **600 MHz - 3.8 GHz** (not 617-4200 as stated elsewhere in the passes). Ground-plane-independent dipole - **no counterpoise**. 98.4 x 14.9 x 0.8 mm, 3M 9888T adhesive. Covers **B71**, which T-Mobile US uses for NB-IoT. | DigiKey CA **4,561** @ $8.37 CAD/1, **8-week** lead. | `[CONFIRMED]` stock/price. `[DISPUTED]` lifecycle: TE and DigiKey both say Active, but **TTI shows "Reference Only / in transition" and OnlineComponents says "no longer being manufactured"**. Get a written lifecycle statement from TE/Linx before an 8-week buy and qualify the second source in parallel. **Watch temp: -20..+65C**, narrower than the BG95 and the OLED. https://www.digikey.ca/en/products/detail/te-connectivity-linx/ANT-LTE-RPC-UFL/11314387 |
| **E2 alternates** | **Quectel YF0006PA** - 50 x 25 mm, dipole, ground-independent, 698-960 / 1710-2690, MHF1. **DigiKey: Active, 5,249 in stock, EUR 1.65 @1, 4-week lead.** Loses B71. **Pulse W3907B0100** - 698-3600, -40..+85C, DigiKey CA 4,278 @ $8.98, 9 wk; also no B71. | | `[CONFIRMED]` YF0006PA is the **cheapest and shortest-lead of the three** and half the length - if the CAD mock-up is tight it may be the right primary, not the fallback. |
| **E3 - GNSS antenna (J8 / BG95 ANT_GNSS)** | **Quectel YFGA003AA**, passive GNSS L1, 39.45 x 13.25 x 0.13 mm, 100 mm coax, MHF1. VSWR 1.1, eff 58-61%, peak gain 3.2-3.5 dBi - **passes every line of BG95 Table 34**. | DigiKey CA **3,237** @ $2.36 CAD/1, $1.53 @1000, **4-week** lead, Part Status **Active**. | `[CONFIRMED]` distributor data. `[SUSPECTED]` the passive-vs-active conclusion: Quectel's BG95 HW Design §5.5.1 reportedly recommends a **passive** antenna when B13 is supported (BG95-M3 is), and Fig 32 note 2 says the VDD bias tee is not needed for passive - so **no bias tee, no schematic change, the bare pi is correct**. Cited to local `_bg95.pdf` only; not independently re-read. **Confirm the datasheet's ground-plane clearance requirement** (~10 mm is typical for this class) before assuming it "fits". |
| **E1 - 2.4 GHz antenna (ESP32-S2-**SOLO-2U** on-module U.FL)** | **Molex 1461530150**. 34.90 x 9.00 x **0.10 mm**, 150 mm micro-coax to MHF1, 2.4-2.5 GHz, >72% total efficiency, 2.8 dBi, ground-plane independent, peel-and-stick. | DigiKey CA **22,221** + 4,800 factory @ $4.55 CAD/1, **9-week** lead, **Active**. | `[CONFIRMED]`. Beats the legacy Molex **1461539150** (also Active, 7,150 @ DigiKey, but **18-week** lead, 2.00 mm thick vs 0.10 mm, and a Wi-Fi 6E tri-band part wasted on a 2.4 GHz-only radio). The legacy part was never purchased so nothing is stranded. Backup: Taoglas FXP73.07.0100A, 8,440 @ $7.97 CAD, 16 wk. Note 1461530150 is dual-band 2.4/5 - single-band siblings in the same 146153 family are worth a look if area is tight. |
| **Battery (BT1; legacy row 48)** | **Do not carry ASR00035 forward.** Re-source: any 600-1000 mAh Li-ion pack from a real cell maker with a **published PCM over-current trip**, ordered with a **JST SHR-02V-S-B** pigtail; or change J4 to JST PH and buy a mainstream PH-terminated pack. | ASR00035 was $6.95. | `[CONFIRMED UNBUYABLE]` DigiKey .ca and .co.uk both return "This product is no longer available at DigiKey"; TinyCircuits shows Sold Out; **Mouser 406-ASR00035: 0 on hand, 590 on order, 13 wk factory lead, USA-only shipping** (2026-09-08). No manufacturer EOL notice was published, so it is *delisted*, not confirmed obsolete. **Drop the "under-rated at 1C" argument** - the PCM trip is unpublished and both datasheet PDFs are unreadable; 600 mA from a 500 mAh pouch is 1.2C, ordinary. The real reasons to re-source are the delisting and the 1.0 mm JST SH termination most commodity packs do not carry. Ignore broker listings. |
| **R34** (40.2 k 1%, MCP73871 VPCC lower leg) | **Yageo RC0402FR-0740K2L** (40.2 k ±1%, 0402, 62.5 mW, 100 ppm/C). DigiKey 311-40.2KLRCT-ND / -LRDKR-ND. Second source **Uni-Royal 0402WGF4022TCE** (LCSC C25893 / TME). | ~$0.01. | `[CONFIRMED]` part identity and duty. `[UNVERIFIED]` stock - **DigiKey cached pages read both "ships today" and "out of stock/backorder"; RS UK 198-7788 reads "currently unavailable, no known restock date"**. Check the live page before ordering. **1% matters:** with both legs at 1% the VPCC knee holds ~4.10-4.48 V (including the MCP73871's own ±3% VPCC threshold tolerance). With both at 5% it spreads to ~4.00-4.61 V: at the high corner the charger folds back on a normal 4.75-4.8 V hub port and never fills the cell; at the low corner foldback never engages. **Value-code hazard:** `-0740K2L` = 40.2 k, `-07402RL` = 402 R, `-07402KL` = 402 k, `RC0201FR-0740R2L` = 40.2 R. Three of those are a 1000x error waiting to happen and two are stocked. |
| **C31, C34** (15 pF C0G 0402, RF pi **series** elements) | **Murata GJM1555C1H150JB01J** (15 pF ±5% 50 V C0G 0402) - GJM is Murata's high-Q RF line. **Do not substitute a GRM or GCM C0G**: identical on paper, worse Q and ESR in a matching network. Second source Kyocera AVX 04025A150JAT2A. | DigiKey listed, "ships today" (search-index snapshot). Order the `J` reel code - the `...JB01D` bulk suffix did not surface in stock listings. | `[CONFIRMED]` part. `[OPEN DESIGN QUESTION]` the **value**: at 15 pF the series reactance is 15.2 ohm at 700 MHz into a 50 ohm line. If the SchDescription's "DC block" is literal, 15 pF is far too small (a 700 MHz DC block wants >=100 pF). If it is a matching element, 15 pF is a plausible starting value. Four DNP shunt positions surround these two series positions, i.e. the topology is explicitly a tunable pi - so **action this as "record an MPN and confirm on a VNA at bring-up", not as "the 15 pF is wrong"**. |
| **C32, C33, C35, C36** (DNP - RF pi shunts) | Record **Murata GJM15 series** as the named stuffing family. Buy a tuning kit spanning 0.5-10 pF: **GJM15-KIT-DE-1** (Murata's own 0402 GJM C0G design kit, 20 pcs each) is cleaner than four reel line items. Plus 0 ohm 0402 jumpers. | Kit, not reels - `...BB01D` is a 7-inch paper-tape reel code. | `[CONFIRMED]` family. Not purchased for build 1; the deliverable is recording the family and range so the line is not empty at handoff. |
| **C41, C42, C43** (DNP - SIM EMI shunts) | **33 pF C0G 0402 50 V**, *not* 22 pF. Quectel's BG95 reference (Fig 21) specifies 33 pF, and states verbatim **"the 33 pF capacitors are used for filtering interference of EGSM900"** - so with EGPRS dropped their stated purpose no longer applies and DNP is now *justified*, not an unexplained gap. Record that rationale in Status. **Samsung CL05C330JB5NNNC** or Murata **GRM1555C1H330JA01D** - either is fine, pick on price. | | `[SUSPECTED]` the 33 pF figure and the EGSM900 quote are cited to local `_bg95.pdf` p.48-49 only. `[CORRECTED]` an earlier claim that Murata was "thinning in the channel" does **not** hold: LCSC is out of stock but **DigiKey 3693846 ships today and Arrow has stock** - do not reverse primary/alternate on that basis. Note ETSI/Quectel budget the USIM ESD parasitic at <=15 pF; do not go above 33 pF if you ever populate these. |
| **J6** (1x05 2.54 mm debug header) | **Recommendation: do not buy it. Convert to five labelled test pads.** It is a pure power-rail tap (GND, +1.8 V, +3.3 V, +5 V, +12 V) with **zero signals**, forces a THT operation on an all-SMT board, and puts **+12 V immediately adjacent to +1.8 V on unkeyed, unshrouded 2.54 mm centres** - one slipped probe puts 12 V on the BG95's 1.8 V rail. If pads are kept, reorder so +12 V sits at one end next to GND. | If retained for bring-up: **Wurth 61300511121** (DigiKey 4846831, 30,254 @ $0.25) or **Sullins PRPC005SAAN-RC** (DigiKey 2775249, $0.35). Both Active, in stock 2026-09-08. | `[CONFIRMED]` alternates real and orderable. **`[CONFIRMED]` J6 carries NO `(dnp yes)` in the schematic and its BOM DNP cell is empty** - contrary to the brief's "deliberately not populated", it currently counts as a purchasable placement with no MPN. Pick one and record it. Useful side-finding: **+1.8 V comes from U2.29 (BG95 VDD_EXT), not from the deleted U7** - deleting the MIC5504 did not orphan that rail. |
| **Bare PCB (PCB1)** | JLCPCB **JLC04161H-7628**, 4-layer, ENIG, 37.50 x 120.00 mm. Real JLCPCB controlled-impedance stackup, correct for the 50 ohm coplanar RF the BG95 requires. | `[UNVERIFIED]` - the quote engine is a JS app. Quote at cart.jlcpcb.com with impedance control on **and the stencil in the same cart**. Impedance control + ENIG is not a "standard parameters" order and triggers engineering confirmation, adding build days. | **Do not order until the layout is resynced.** |
| **Stencil (STENCIL1)** | Laser-cut stainless, 0.12 mm (4 mil), **top side only**, frameless is fine for protos. Aperture reduction on the 0.4 mm-pitch UQFN (U3); **windowpaned, not solid, apertures on U6 and U8 exposed pads**. | `[UNVERIFIED]` JLCPCB advertises a $1 first stencil for new accounts. | This board *should not* be hand-pasted: U3 is 0.4 mm-pitch 10-UQFN, U8 is 0.5 mm 20-VQFN with EP, U6 is 8-WFDFN with EP, 39x 0402, plus the BG95 LGA. Buy in the same cart as PCB1 so fiducials and panel data match. Confirm top-side-only **after** the resync. |
| **Mounting hardware / enclosure** | **None found - and none can be fitted.** The PCB has **zero MountingHole footprints**; the only three np_thru_holes are SW1's Cherry MX alignment posts. Six anonymous 2.2 mm plated GND holes exist in the layout with empty refdes/library/value, plus one annotated `REF**` on a TestPoint footprint. CAD exists (`bingbong_case_1/2.SLDPRT`, `helical_pcb_stand.SLDPRT`, `bingbong_btn_ext.SLDPRT`) but SolidWorks binaries are not machine-readable. | n/a | `[SUSPECTED - local analysis]`. **Adding at least two MountingHole footprints before the next spin costs nothing now and cannot be added after fab.** Open the assembly and answer: how do the case halves join, what retains the PCB, and is `bingbong_btn_ext` printed or purchased. Then add the fasteners and the enclosure as BOM lines. |
| **SW1 keycap / actuator** | **None found.** A bare MX switch has no actuating surface as ordered. `bingbong_btn_ext.SLDPRT` implies a custom actuator with no BOM line. | n/a | Add a keycap or enclosure plunger as a purchasable line. Also sanity-check the fit: an MX switch is ~15.6 x 15.6 mm at the plate, ~11.6 mm tall before a keycap adds ~10 mm, and needs a 14 x 14 mm plate cutout - on a 37.5 mm-wide handheld that is very likely the dominant mechanical constraint. |
| **Bring-up SIM** | **None on the BOM.** J7 is a nano-SIM socket and U2 is an LTE-M/NB-IoT modem; a board with no SIM cannot be proven to attach. | Add a Hologram / Twilio / Soracom developer SIM as a bring-up line. | Not an assembly item, but a bring-up blocker. |
| **Off-board / harness** | **None on the BOM.** Missing: the cell, the **JST SH mating housing + crimps** (SHR-02V-S-B, DigiKey 455-1377-ND; SSH-003T-P0.2, DigiKey 700389/27687549), the **JST PH housing + crimps** for the NTC lead (PHR-2, 455-1165-ND; SPH-002T-P0.5S, 455-1127-1-ND). | All confirmed real and orderable 2026-09-08. | Two practical notes: the **SSH-003T-P0.2-H** variant reads 0 stock with a **16-week** lead - specify the base part or buy **pre-terminated ASSHSSH28K jumpers**, because 1.0 mm-pitch SH crimping is impractical by hand (the JST WC-240 hand crimper is ~$537). SPH-002T-P0.5S is 24-30 AWG; if the NTC pigtail is finer, use **SPH-004T-P0.5S** (32-28 AWG). |

---

## 3. Lifecycle and stock risk register

Sorted by risk. Every row marked `[CONFIRMED]` / `[SUSPECTED]` / `[UNVERIFIED]`. All quantities are
**2026-09-08 snapshots**.

### BLOCKER

| Refs | MPN | Lifecycle | Stock (2026-09-08) | Risk | Action |
|---|---|---|---|---|---|
| PCB | n/a | n/a | n/a | Layout desync - board is a different design from the BOM | `[SUSPECTED]` Resync, re-route, re-DRC before anything. Local analysis, not re-verified here. |
| C6,C21 | C0603C101K5RACAUTO7411 | **Active** `[CONFIRMED]` | Alt C0603C104K5RACTU: ~8.4 M DigiKey; ~10 M aggregate `[SUSPECTED - search-index]` | Wrong part, 1000x, and *orderable* as written | Swap to C0603C104K5RACTU. https://www.arrow.com/en/products/c0603c101k5racauto/kemet-corporation ; https://www.digikey.com/en/products/detail/kemet/C0603C104K5RACTU/1465594 |
| L1 | MLZ1608A2R2WTD25 | **Unknown** `[UNVERIFIED]` - product.tdk.com 403s to automated fetch | n/a - delete from BOM. Alt DFE252012F-3R3M=P2: **LCSC 5,140 @ $0.197** `[CONFIRMED - read live]` | Wrong value+package+class+rating; PCB land also wrong | Murata DFE252012F-3R3M=P2 + fix the footprint. https://www.lcsc.com/product-detail/C2041573.html ; https://www.murata.com/~/media/webrenewal/products/inductor/chip/tokoproducts/wirewoundmetalalloychiptype/m_dfe252012f.ashx |
| R2 group (9) | RC0402JR-0710KL / RE0402FRE07100KL | Both **Active** `[CONFIRMED]` | Wrong one: LCSC C60489 4,288,100. Right one: **no readable stocked listing anywhere**. Alt RC0402FR-07100KL: LCSC C60491 **3,594,500** `[CONFIRMED - read live]` | 10x error at R33 kills VPCC foldback | RC0402FR-07100KL. https://www.lcsc.com/product-detail/C60491.html ; https://www.digikey.com/en/products/detail/yageo/RC0402FR-07100KL/726526 . *Caveat: the "RE = 20 wk, not stocked" evidence is from a **different** RE part (RE1206FRE07470KL) and JLCPCB does carry an RE 0402 100 k - so "RE is unstockable" is a reasonable inference, not a fact for this exact PN.* |
| J5 connector | ER-CON26HT-1 | **Unknown - no status published** `[CONFIRMED absence]` | **Zero authorized-distributor availability**; findchips returns no legitimate hits | Sole-source, zero visibility, on the critical path | Buy 5-10 spares with the display; qualify Hirose FH12A in parallel. https://www.findchips.com/search/ER-CON26HT-1 |
| Display | ER-OLED018-1W | **Unknown - no status published** `[SUSPECTED]` | Listed at $11.21; **live stock never obtained** (403) | Sole-source, small Shenzhen vendor, no distribution, no published lead time | Add as a line, get a written lead time and stock reservation from sales@buydisplay.com **before the enclosure is committed**. Buy 2-3 spares - the ZIF tail is fragile. Also ask whether the ER-CON26HT-1 ships bundled (their AliExpress listing says "Free Connector") - the answer zeroes the J5 cost and tells you authoritatively which contact orientation they intend. |
| Battery | ASR00035 | **Delisted, no EOL notice** `[CONFIRMED]` | DigiKey: "no longer available". TinyCircuits: Sold Out. **Mouser: 0 on hand, 590 on order, 13 wk, USA-only** | Unbuyable through the project's channel | Re-source. Longest pole: re-selection + UN38.3 + air-freight restrictions. https://www.digikey.ca/en/products/detail/tinycircuits/ASR00035/9808767 |
| TH1 | ND03N00103K-- | **Active** `[CONFIRMED]` | Mouser 8,942 @ $0.41; Newark 4,838; DigiKey 3,131 @ $0.46 | Right part, wrong slot - three mutually incompatible representations | Decide connector vs on-board NTC; see §1. https://datasheets.kyocera-avx.com/NTC_DiscThermistors.pdf |
| J8 | CONMHF1-SMD-T | Active | n/a | **Not placed on the PCB** despite being in schematic, netlist and BOM (qty 2) | Resync. Buying 2 is correct; the board cannot accept the second one today. `[SUSPECTED - local]` |
| SW1 | KS-9Y10B060NW-G43 | **Unknown - no lifecycle published** `[CONFIRMED absence]` | **Zero authorized distributors** (findchips: only unrelated APEM/IDEC "KS900B14"). Hobby channel: mechanicalkeyboards.com ~860 @ $0.50; MaxGaming, Milktooth, LumeKeebs, KBDfans | No franchised supply, no PCN process, no RoHS/REACH declaration, no MSL rating, on a commercial handheld | **Buy lifetime spares now** at $0.50 - keyboard switch colourways are discontinued on fashion cycles, not PCN cycles. Electrically and footprint-wise it is correct (5-pin MX PCB mount, 60±15 gf, netlist active-high on press). If MX feel was inherited rather than chosen, re-selecting to a distributor-stocked tact collapses this risk to zero. https://www.findchips.com/search/KS-9Y10B060NW-G43 |
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

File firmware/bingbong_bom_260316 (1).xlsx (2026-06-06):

Ryan Chiang |  | rychi@berkeley.edu |  |  |  |  |  |  |  |  |  |  |  |  |  | Total Price for Project
 |  |  |  |  |  |  |  |  |  |  |  |  |  |  |  | $68.70
Quantity | Purchase Status | Description (include component value if applicable) | Purchase URL | Reference Designator | Package/Case | Type | Assembly (YES/NO) | Side | Manufacturer Part # | Digi-key Part#/SKU | Price/unit ($) | Datasheet Link |  | Multiple | Total Qty | Total Price/part ($)
1 | Ordered | 470 µF 16 V Aluminum Electrolytic Capacitors Radial, Can 8000 Hrs @ 105°C | https://www.digikey.com/en/products/detail/rubycon/16ZLH470MEFCT78X11-5/3568114 | C3 | Radial, Can | Through Hole | YES | TOP | 16ZLH470MEFCT78X11.5 | 1189-3712-1-ND | $0.42 | https://www.rubycon.co.jp/wp-content/uploads/catalog-aluminum/ZLH.pdf |  | 1 | 1 | $0.42
4 | Ordered | 1 µF ±10% 6.3V Ceramic Capacitor X5R 0402 (1005 Metric) | https://www.digikey.com/en/products/detail/taiyo-yuden/JMK105BJ105KV-F/930583 | C2, C11, C12, C29 | 402 | SMD | YES | TOP | JMK105BJ105KV-F | 587-1231-2-ND | $0.08 | https://ds.yuden.co.jp/TYCOMPAS/ut/detail?pn=JMK105BJ105KV-F%20%20&u=M |  | 1 | 4 | $0.32
7 | Ordered | 0.1 µF ±10% 25V Ceramic Capacitor X5R 0402 (1005 Metric) | https://www.digikey.com/en/products/detail/samsung-electro-mechanics/CL05A104KA5NNNC/3886701 | C1, C4, C5, C7, C17, C18, C19 | 402 | SMD | YES | TOP | CL05A104KA5NNNC | 1276-1043-2-ND | $0.08 | https://mm.digikey.com/Volume0/opasdata/d220001/medias/docus/503/CL05A104KA5NNNC.pdf |  | 1 | 7 | $0.56
2 | Ordered | 100 pF ±10% 50V Ceramic Capacitor X7R 0603 (1608 Metric) | https://www.digikey.com/en/products/detail/kemet/C0603C101K5RACAUTO7411/21784016?gclsrc=aw.ds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 | C6, C21 | 603 | SMD | YES | TOP | C0603C101K5RACAUTO7411 | 399-C0603C101K5RACAUTO7411CT-ND | $0.12 | https://yageogroup.com/content/datasheet/asset/file/KEM_C1023_X7R_AUTO_SMD |  | 1 | 2 | $0.24
2 | Ordered | 4.7 µF Molded Tantalum Capacitors 25 V 1206 (3216 Metric) 6Ohm | https://www.digikey.com/en/products/detail/kemet/T491A475K025AT/3759607 | C22, C23 | 1206 | SMD | YES | TOP | T491A475K025AT | 399-10128-1-ND | $0.44 | https://yageogroup.com/content/datasheet/asset/file/KEM_T2005_T491 |  | 1 | 2 | $0.88
1 | Ordered | 220 pF ±10% 25V Ceramic Capacitor X7R 0603 (1608 Metric) | https://www.digikey.com/en/products/detail/w%C3%BCrth-elektronik/885012206055/5453829 | C26 | 603 | SMD | YES | TOP | 885012206055 | 732-7974-1-ND | $0.10 | https://www.we-online.com/components/products/datasheet/885012206055.pdf |  | 1 | 1 | $0.10
3 | Ordered | 22 µF ±20% 6.3V Ceramic Capacitor X5R 0402 (1005 Metric) | https://www.digikey.com/en/products/detail/murata-electronics/GRM158R60J226ME01D/13918973 | C10, C13, C20 | 402 | SMD | YES | TOP | GRM158R60J226ME01D | 490-GRM158R60J226ME01DCT-ND | $0.37 | https://search.murata.co.jp/Ceramy/image/img/A01X/G101/ENG/GRM158R60J226ME01-01A.pdf |  | 1 | 3 | $1.11
3 | Ordered | 10 µF ±20% 10V Ceramic Capacitor X5R 0402 (1005 Metric) | https://www.digikey.com/en/products/detail/murata-electronics/GRM155R61A106ME11D/12091056 | C8, C9, C15 | 402 | SMD | YES | TOP | GRM155R61A106ME11D | 490-GRM155R61A106ME11DCT-ND | $0.08 | https://search.murata.co.jp/Ceramy/image/img/A01X/G101/ENG/GRM155R61A106ME11-01A.pdf |  | 1 | 3 | $0.24
2 | Ordered | 4.7 µF ±20% 10V Ceramic Capacitor X5R 0402 (1005 Metric) | https://www.digikey.com/en/products/detail/samsung-electro-mechanics/CL05A475MP5NRNC/3887140 | C14, C16 | 402 | SMD | YES | TOP | CL05A475MP5NRNC | 1276-1482-1-ND | $0.10 | https://mm.digikey.com/Volume0/opasdata/d220001/medias/docus/863/CL05A475MP5NRNC_Spec.pdf |  | 1 | 2 | $0.20
2 | Ordered | 1 µF ±10% 16V Ceramic Capacitor X7R 0603 (1608 Metric) | https://www.digikey.com/en/products/detail/kemet/C0603C105K4RACTU/2199788 | C24, C25 | 603 | SMD | YES | TOP | C0603C105K4RACTU | 399-C0603C105K4RACTUCT-ND | $0.08 | https://yageogroup.com/content/datasheet/asset/file/KEM_C1002_X7R_SMD |  | 1 | 2 | $0.16
3 | Ordered | Clamp Ipp Tvs Diode Surface Mount SOD-923 | https://www.digikey.com/en/products/detail/onsemi/ESD9B5.0ST5G/1646497?gclsrc=aw.ds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 | CR1, CR2, CR3 | SOD-923 | SMD | YES | TOP | ESD9B5.0ST5G | ESD9B5.0ST5GOSCT-ND | $0.10 | https://www.digikey.com/en/products/detail/onsemi/ESD9B5.0ST5G/1646497?gclsrc=aw.ds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 |  | 1 | 3 | $0.30
2 | Ordered | Red 630nm LED Indication - Discrete 1.9V 0603 (1608 Metric) | https://www.digikey.com/en/products/detail/w-rth-elektronik/150060SS75000/4489902?gclsrc=aw.ds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 | D1, D3 | 603 | SMD | YES | TOP | 150060SS75000 | 732-4979-1-ND | $0.15 | https://www.digikey.com/en/products/detail/w-rth-elektronik/150060SS75000/4489902?gclsrc=aw.ds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 |  | 1 | 2 | $0.30
2 | Ordered | Green 573nm LED Indication - Discrete 2V 0603 (1608 Metric) | https://www.digikey.com/en/products/detail/w%C3%BCrth-elektronik/150060VS55040/8557182 | D2, D4 | 603 | SMD | YES | TOP | 150060VS55040 | 732-12017-1-ND | $0.19 | https://www.we-online.com/components/products/datasheet/150060VS55040.pdf |  | 1 | 2 | $0.38
1 | Ordered | USB-C (USB TYPE-C) USB 3.2 Gen 2 (USB 3.1 Gen 2, Superspeed + (USB 3.1)) Receptacle Connector 24 Position Surface Mount, Right Angle; Through Hole | https://www.digikey.com/en/products/detail/molex/1054500101/5843891 | J2 | -- | SMD, Through Hole | YES | TOP | 1054500101 | WM12856CT-ND | $2.40 | https://www.molex.com/pdm_docs/ps/PS-105448-001.pdf |  | 1 | 1 | $2.40
1 | Ordered | U.FL (UMCC) Connector Jack, Male Pin 50 Ohms Surface Mount Solder | https://www.digikey.com/en/products/detail/te-connectivity-linx/CONMHF1-SMD-T/15293395?gclsrc=aw.ds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 | J3 | -- | SMD | YES | TOP | CONMHF1-SMD-T | 343-CONMHF1-SMD-TCT-ND | $0.21 | https://www.te.com/commerce/DocumentDelivery/DDEController?Action=srchrtrv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 |  | 1 | 1 | $0.21
1 | Ordered | Connector Header Surface Mount 2 position 0.039" (1.00mm) | https://www.digikey.com/en/products/detail/jst-sales-america-inc/BM02B-SRSS-TBT/5725846?gclsrc=aw.ds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 | J4 | -- | SMD | YES | TOP | BM02B-SRSS-TBT | 455-BM02B-SRSS-TBTCT-ND | $0.56 | https://www.jst-connector.com/datasheet/jst-connector/BM02B-SRSS-TB.pdf |  | 1 | 1 | $0.56
1 | Ordered | 26 Pins 0.5mm Pitch ZIF Connector (FPC Connector) | https://www.buydisplay.com/white-1-8-inch-256x32-oled-display-module-serial-i2c-and-ssd1326 | J5 | -- | SMD | YES | TOP | -- | -- | $0.16 | https://www.buydisplay.com/download/connector/ER-CON26HT-1.pdf |  | 1 | 1 | $0.16
1 | Ordered | 8 (6 + 2) Position Card Connector NANO SIM Surface Mount, Right Angle Gold | https://www.digikey.com/en/products/detail/te-connectivity-linx/2452808-1/21284895 | J7 | -- | SMD | YES | TOP | 2452808-1 | 343-2452808-1CT-ND | $1.36 | https://www.te.com/usa-en/product-2452808-1.datasheet.pdf |  | 1 | 1 | $1.36
1 | Ordered | 2.2 µH Shielded Multilayer Inductor 500 mA 250mOhm 0603 (1608 Metric) | https://www.digikey.com/en/products/detail/tdk/MLZ1608A2R2WTD25/4743174 | L1 | 603 | SMD | YES | TOP | MLZ1608A2R2WTD25 | 445-MLZ1608A2R2WTD25CT-ND | $0.13 | https://product.tdk.com/en/system/files |  | 1 | 1 | $0.13
1 | Ordered | 22 µH Shielded Multilayer Inductor 220 mA 1.25Ohm 0805 (2012 Metric) | https://www.digikey.com/en/products/detail/tdk-corporation/MLZ2012P220WT000/4327893 | L2 | 805 | SMD | YES | TOP | MLZ2012P220WT000 | 445-15751-1-ND | $0.10 | https://product.tdk.com/en/system/files |  | 1 | 1 | $0.10
1 | Ordered | Bipolar (BJT) Transistor NPN 40 V 600 mA 300MHz 300 mW Surface Mount SOT-23-3 (TO-236) | https://www.digikey.com/en/products/detail/onsemi/SMMBT2222ALT3G/9087735?gclsrc=aw.ds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 | Q1 | SOT-23-3 | SMD | YES | TOP | SMMBT2222ALT3G | SMMBT2222ALT3GOSCT-ND | $0.18 | https://www.onsemi.com/pdf/datasheet/mmbt2222lt1-d.pdf |  | 1 | 1 | $0.18
1 | Ordered | P-Channel 20 V 1.6A (Ta) 500mW (Ta) Surface Mount SOT-23-3 | https://www.digikey.com/en/products/detail/onsemi/FDN338P/458848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 | Q2 | SOT-23-3 | SMD | YES | TOP | FDN338P | FDN338PCT-ND | $0.68 | https://www.onsemi.com/pdf/datasheet/fdn338p-d.pdf |  | 1 | 1 | $0.68
1 | Ordered | Bipolar (BJT) Transistor NPN 25 V 1.5 A 100MHz 300 mW Surface Mount SOT-23 | https://www.digikey.com/en/products/detail/shenzhen-slkormicro-semicon-co-ltd/SS8050/21853087 | Q3 | TO-236-3, SC-59, SOT-23-3 | SMD | YES | TOP | SS8050 | 5399-SS8050CT-ND | $0.10 | -- |  | 1 | 1 | $0.10
2 | Ordered | Tactile Switch SPST-NO Top Actuated Surface Mount | https://www.digikey.com/en/products/detail/same-sky-formerly-cui-devices-/TS04-66-70-BK-100-SMT/15634306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 | S1, S2 | -- | SMD | YES | TOP | TS04-66-70-BK-100-SMT | 2223-TS04-66-70-BK-100-SMT-ND | $0.19 | https://www.cuidevices.com/product/resource/ts04.pdf |  | 1 | 2 | $0.38
1 | Ordered | Boost Switching Regulator IC Positive Adjustable 1 Output 700mA (Switch) SOT-23-6 | https://www.digikey.com/en/products/detail/nisshinbo-micro-devices-inc/R1200N002A-TR-FE/10244888 | U1 | SOT-23-6 | SMD | YES | TOP | R1200N002A-TR-FE | 2129-R1200N002A-TR-FECT-ND | $1.24 | https://www.nisshinbo-microdevices.co.jp/en/pdf/datasheet/r1200-ea.pdf |  | 1 | 1 | $1.24
1 | Ordered | Cellular, Navigation BeiDou, EGDE, Galileo, GLONASS, GPS, GNSS, GSM, LTE Transceiver Module 850MHz, 900MHz, 1.8GHz, 1.9GHz Antenna Not Included Surface Mount | https://www.digikey.com/en/products/detail/quectel/BG95M3LA-64-SGNS/13278150?gclsrc=aw.ds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 | U2 | Module | SMD | YES | TOP | BG95M3LA-64-SGNS | 2958-BG95M3LA-64-SGNSTR-ND | $27.46 | https://mm.digikey.com/Volume0/opasdata/d220001/medias/docus/7133/Quectel_BG95_Series_LPWA_Specification_V2.2.pdf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..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 |  | 1 | 1 | $27.46
1 | Ordered | Translation Transceiver 1 Element 2 Bit per Element 3-State Output 10-UQFN (1.8x1.4) | https://www.digikey.com/en/products/detail/texas-instruments/SN74AVC2T245RSWR/1902119 | U3 | 10-UQFN | SMD | YES | TOP | SN74AVC2T245RSWR | 296-23684-1-ND | $1.20 | https://www.ti.com/general/docs/suppproductinfo.tsp?distId=10 |  | 1 | 1 | $1.20
1 | Ordered | 8V Clamp 1A (8/20µs) Ipp Tvs Diode Surface Mount SOT-3 | https://www.digikey.com/en/products/detail/texas-instruments/TPD2EUSB30ADRTR/2520830 | U5 | 3-SMD, SOT-23-3 | SMD | YES | TOP | TPD2EUSB30ADRTR | 296-28153-1-ND | $0.72 | https://www.ti.com/general/docs/suppproductinfo.tsp?distId=10 |  | 1 | 1 | $0.72
1 | Ordered | Buck Switching Regulator IC Positive Fixed 3.3V 1 Output 500mA 8-WFDFN Exposed Pad | https://www.digikey.com/en/products/detail/texas-instruments/TPS62172DSGR/2833456 | U6 | 8-WFDFN Exposed Pad | SMD | YES | TOP | TPS62172DSGR | 296-39449-1-ND | $1.32 | https://www.ti.com/general/docs/suppproductinfo.tsp?distId=10 |  | 1 | 1 | $1.32
1 | Ordered | IC REG LINEAR 1.8V 300MA 4-TDFN | https://www.digikey.com/en/products/detail/microchip-technology/MIC5504-1-8YMT-TR/5049172 | U7 | 4-UDFN Exposed Pad | SMD | YES | TOP | MIC5504-1.8YMT-TR | MIC5504-1.8YMT-CT-ND | $0.22 | https://ww1.microchip.com/downloads/en/DeviceDoc/MIC5501-02-03-04-300mA-Single-Output-LDO-in-Small-Packages-DS20006006B.pdf |  | 1 | 1 | $0.22
1 | Ordered | Charger IC Lithium Ion/Polymer 20-QFN (4x4) | https://www.digikey.com/en/products/detail/microchip-technology/MCP73871-2CCI-ML/1680971 | U8 | 20-VFQFN Exposed Pad | SMD | YES | TOP | MCP73871-2CCI/ML | MCP73871-2CCI/ML-ND | $2.41 | https://ww1.microchip.com/downloads/en/DeviceDoc/30009610F.pdf |  | 1 | 1 | $2.41
1 | Ordered | WiFi 802.11b/g/n Transceiver Module 2.4GHz Antenna Not Included, U.FL Surface Mount | https://www.digikey.com/en/products/detail/espressif-systems/ESP32-S2-SOLO-2U-N4/16997862?gclsrc=aw.ds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 | U10 | 41-SMD Module | SMD | YES | TOP | ESP32-S2-SOLO-2U-N4 | 1965-ESP32-S2-SOLO-2U-N4CT-ND | $4.29 | https://www.digikey.com/en/models/16591894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 |  | 1 | 1 | $4.29
6 | Ordered | 10 kOhms ±5% 0.063W, 1/16W Chip Resistor 0402 (1005 Metric) Moisture Resistant Thick Film | https://www.digikey.com/en/products/detail/yageo/RC0402JR-0710KL/726418 | R1, R14, R15, R18, R20, R30 | 402 | SMD | YES | TOP | RC0402JR-0710KL | 311-10KJRCT-ND | $0.10 | https://www.yageogroup.com/content/datasheet/asset/file/PYU-RC_GROUP_51_ROHS_L |  | 1 | 6 | $0.60
5 | Ordered | 100 kOhms ±1% 0.063W, 1/16W Chip Resistor 0402 (1005 Metric) Thick Film | https://www.digikey.com/en/products/detail/yageo/RE0402FRE07100KL/18103629?gclsrc=aw.ds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 | R2, R6, R9, R10, R16 | 402 | SMD | YES | TOP | RE0402FRE07100KL | 13-RE0402FRE07100KLCT-ND | $0.10 | https://yageogroup.com/content/Resource%20Library/Datasheet/PYU-RE_105_ROHS_L.pdf |  | 1 | 5 | $0.50
4 | Ordered | 1 kOhms ±5% 0.063W, 1/16W Chip Resistor 0402 (1005 Metric) Anti-Sulfur, Automotive AEC-Q200 Thick Film | https://www.digikey.com/en/products/detail/yageo/AF0402JR-071KL/12707163?gclsrc=aw.ds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 | R3, R11, R12, R13 | 402 | SMD | YES | TOP | AF0402JR-071KL | 13-AF0402JR-071KLCT-ND | $0.10 | https://yageogroup.com/content/Resource%20Library/Datasheet/PYU-AF_51_ROHS_L.pdf |  | 1 | 4 | $0.40
4 | Ordered | 0 Ohms Jumper Chip Resistor 0402 (1005 Metric) Moisture Resistant Thick Film | https://www.digikey.com/en/products/detail/yageo/RC0402JR-130RL/12756406?gclsrc=aw.ds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 | R4, R5, R17, R19 | 402 | SMD | YES | TOP | RC0402JR-130RL | 13-RC0402JR-130RLCT-ND | $0.10 | https://yageogroup.com/content/datasheet/asset/file/PYU-RC_GROUP_51_ROHS_L |  | 1 | 4 | $0.40
2 | Ordered | 5.1 kOhms ±1% 0.063W, 1/16W Chip Resistor 0402 (1005 Metric) Anti-Sulfur, Automotive AEC-Q200 Thick Film | https://www.digikey.com/en/products/detail/yageo/AF0402FR-075K1L/18104055?gclsrc=aw.ds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 | R7, R8 | 402 | SMD | YES | TOP | AF0402FR-075K1L | 13-AF0402FR-075K1LCT-ND | $0.10 | https://yageogroup.com/content/Resource%20Library/Datasheet/PYU-AF_51_ROHS_L.pdf |  | 1 | 2 | $0.20
1 | Ordered | 680 kOhms ±5% 0.1W, 1/10W Chip Resistor 0603 (1608 Metric) Automotive AEC-Q200 Thick Film | https://www.digikey.com/en/products/detail/panasonic-electronic-components/ERJ-3GEYJ684V/135939 | R21 | 603 | SMD | YES | TOP | ERJ-3GEYJ684V | P680KGCT-ND | $0.10 | https://industrial.panasonic.com/cdbs/www-data/pdf/RDA0000/AOA0000C301.pdf |  | 1 | 1 | $0.10
3 | Ordered | 10 kOhms ±5% 0.1W, 1/10W Chip Resistor 0603 (1608 Metric) Automotive AEC-Q200 Thick Film | https://www.digikey.com/en/products/detail/panasonic-electronic-components/ERJ-3GEYJ103V/135662 | R22, R23, R26 | 603 | SMD | YES | TOP | ERJ-3GEYJ103V | P10KGCT-ND | $0.10 | https://industrial.panasonic.com/cdbs/www-data/pdf/RDA0000/AOA0000C301.pdf |  | 1 | 3 | $0.30
1 | Ordered | 110 kOhms ±1% 0.1W, 1/10W Chip Resistor 0603 (1608 Metric) Thin Film | https://www.digikey.com/en/products/detail/yageo/RT0603FRE07110KL/1075045 | R27 | 603 | SMD | YES | TOP | RT0603FRE07110KL | 13-RT0603FRE07110KLCT-ND | $0.10 | https://yageogroup.com/content/datasheet/asset/file/PYU-RT_1-TO-0-01_ROHS_L |  | 1 | 1 | $0.10
1 | Ordered | 2 kOhms ±5% 0.1W, 1/10W Chip Resistor 0603 (1608 Metric) Moisture Resistant Thick Film | https://www.digikey.com/en/products/detail/yageo/RC0603JR-072KL/726726 | R28 | 603 | SMD | YES | TOP | RC0603JR-072KL | 311-2.0KGRCT-ND | $0.10 | https://yageogroup.com/content/datasheet/asset/file/PYU-RC_GROUP_51_ROHS_L |  | 1 | 1 | $0.10
1 | Ordered | 1 kOhms ±5% 0.1W, 1/10W Chip Resistor 0603 (1608 Metric) Moisture Resistant Thick Film | https://www.digikey.com/en/products/detail/yageo/RC0603JR-071KL/726677 | R29 | 603 | SMD | YES | TOP | RC0603JR-071KL | 311-1.0KGRCT-ND | $0.10 | https://yageogroup.com/content/datasheet/asset/file/PYU-RC_GROUP_51_ROHS_L |  | 1 | 1 | $0.10
1 | Delivered | NTC Thermistor 10k Disc, 3.5mm Dia x 3.0mm W | https://www.digikey.com/en/products/detail/kyocera-avx/ND03N00103K--/1452051?gclsrc=aw.ds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 | TH1 | -- | Through Hole | NO | TOP | ND03N00103K-- | 478-ND03N00103K---ND | $0.41 | https://datasheets.kyocera-avx.com/NTC_DiscThermistors.pdf |  | 1 | 1 | $0.41
1 | Delivered | Gateron POM Banana Smoothie Switch | https://mechanicalkeyboards.com/products/gateron-pom-banana-smoothie-switch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 | SW1 | -- | Through Hole | NO | BOTTOM | KS-9Y10B060NW-G43 | -- | $0.50 | -- |  | 1 | 1 | $0.50
1 | Delivered | 3.7 V Lithium Polymer Battery Rechargeable (Secondary) 500mAh | https://www.digikey.com/en/products/detail/tinycircuits/ASR00035/9808767 | -- | -- | -- | NO | TOP | ASR00035 | 1832-1051-ND | $6.95 | https://mm.digikey.com/Volume0/opasdata/d220001/medias/docus/738/ASR00035_Web.pdf |  | 1 | 1 | $6.95
1 | Ordered | White 1.8“ inch 256x32 OLED Display Module w/Serial I2C and SSD1326 | https://www.buydisplay.com/white-1-8-inch-256x32-oled-display-module-serial-i2c-and-ssd1326 | -- | -- | -- | NO | TOP | -- | -- | $11.37 | https://www.buydisplay.com/download/manual/ER-OLED018-1_Series_Datasheet.pdf | https://track.4px.com/#/result/0/4PX3002601089856CN | 1 | 1 | $11.37
1 | Not Purchased | RF ANTENNA Bluetooth, Wi-Fi, Zigbee™ Flat Patch MHF1 Adhesive | https://www.digikey.com/en/products/detail/molex/1461539150/17630204 | -- | -- | -- | NO | TOP | 1461539150 | 900-1461539150-ND | $1.55 | https://www.molex.com/en-us/products/part-detail/1461539150?display=pdf |  | 1 | 1 | $1.55
 | Delivered |  | https://www.amazon.com/gp/buy/thankyou/handlers/display.html?purchaseId=106-0649734-9523433&isRefresh=1 |  |  |  |  |  |  |  |  |  |  |  | 0 | 0
 | Ordered |  | https://www.amazon.com/Liter-energybattery-Rechargeable-602535-Connector/dp/B09FSVSBG5 |  |  |  |  |  |  |  |  |  |  |  | 0 | 0
 | Ordered |  | https://www.amazon.com/dp/B0DPJ9392M?ref=ppx_yo2ov_dt_b_fed_asin_title |  |  |  |  |  |  |  |  |  |  |  | 0 | 0
 | Not Purchased |  | https://www.digikey.com/en/products/detail/quectel/YF0006AA/17101890?utm_source=chatgpt.com |  |  |  |  |  |  |  |  |  |  |  | 0 | 0
 |  |  |  |  |  |  |  |  |  |  |  |  |  |  | 0 | 0
 |  | https://www.amazon.com/OXWINOU-Battery-103450-Rechargeable-1-Pack/dp/B0CTQ6VBB6 |  |  |  |  |  |  |  |  |  |  |  |  | 0 | 0
 |  |  |  |  |  |  |  |  |  |  |  |  |  |  | 0 | 0
 |  |  |  |  |  |  |  |  |  |  |  |  |  |  | 0 | 0
 |  |  |  |  |  |  |  |  |  |  |  |  |  |  | 0 | 0
 |  |  |  |  |  |  |  |  |  |  |  |  |  |  | 0 | 0
 |  |  |  |  |  |  |  |  |  |  |  |  |  |  | 0 | 0
 |  |  |  |  |  |  |  |  |  |  |  |  |  |  | 0 | 0
 |  |  |  |  |  |  |  |  |  |  |  |  |  |  | 0 | 0
 |  |  |  |  |  |  |  |  |  |  |  |  |  |  | 0 | 0
 |  |  |  |  |  |  |  |  |  |  |  |  |  |  | 0 | 0
 |  |  |  |  |  |  |  |  |  |  |  |  |  |  | 0 | 0
 |  |  |  |  |  |  |  |  |  |  |  |  |  |  | 0 | 0
 |  |  |  |  |  |  |  |  |  |  |  |  |  |  | 0 | 0
 |  |  |  |  |  |  |  |  |  |  |  |  |  |  | 0 | 0
 |  |  |  |  |  |  |  |  |  |  |  |  |  |  | 0 | 0
 |  |  |  |  |  |  |  |  |  |  |  |  |  |  | 0 | 0
 |  |  |  |  |  |  |  |  |  |  |  |  |  |  | 0 | 0
 |  |  |  |  |  |  |  |  |  |  |  |  |  |  | 0 | 0
 |  |  |  |  |  |  |  |  |  |  |  |  |  |  | 0 | 0
 |  |  |  |  |  |  |  |  |  |  |  |  |  |  | 0 | 0
 |  |  |  |  |  |  |  |  |  |  |  |  |  |  | 0 | 0
 |  |  |  |  |  |  |  |  |  |  |  |  |  |  | 0 | 0
 |  |  |  |  |  |  |  |  |  |  |  |  |  |  | 0 | 0
 |  |  |  |  |  |  |  |  |  |  |  |  |  |  | 0 | 0
 |  |  |  |  |  |  |  |  |  |  |  |  |  |  | 0 | 0
 |  |  |  |  |  |  |  |  |  |  |  |  |  |  | 0 | 0
 |  |  |  |  |  |  |  |  |  |  |  |  |  |  | 0 | 0
 |  |  |  |  |  |  |  |  |  |  |  |  |  |  | 0 | 0
 |  |  |  |  |  |  |  |  |  |  |  |  |  |  | 0 | 0
 |  |  |  |  |  |  |  |  |  |  |  |  |  |  | 0 | 0
 |  |  |  |  |  |  |  |  |  |  |  |  |  |  | 0 | 0
 |  |  |  |  |  |  |  |  |  |  |  |  |  |  | 0 | 0
 |  |  |  |  |  |  |  |  |  |  |  |  |  |  | 0 | 0
 |  |  |  |  |  |  |  |  |  |  |  |  |  |  | 0 | 0
 |  |  |  |  |  |  |  |  |  |  |  |  |  |  | 0 | 0
 |  |  |  |  |  |  |  |  |  |  |  |  |  |  | 0 | 0
 |  |  |  |  |  |  |  |  |  |  |  |  |  |  | 0 | 0
 |  |  |  |  |  |  |  |  |  |  |  |  |  |  | 0 | 0
 |  |  |  |  |  |  |  |  |  |  |  |  |  |  | 0 | 0
 |  |  |  |  |  |  |  |  |  |  |  |  |  |  | 0 | 0
 |  |  |  |  |  |  |  |  |  |  |  |  |  |  | 0 | 0
 |  |  |  |  |  |  |  |  |  |  |  |  |  |  | 0 | 0
 |  |  |  |  |  |  |  |  |  |  |  |  |  |  | 0 | 0
 |  |  |  |  |  |  |  |  |  |  |  |  |  |  | 0 | 0
 |  |  |  |  |  |  |  |  |  |  |  |  |  |  | 0 | 0
 |  |  |  |  |  |  |  |  |  |  |  |  |  |  | 0 | 0
 |  |  |  |  |  |  |  |  |  |  |  |  |  |  | 0 | 0
 |  |  |  |  |  |  |  |  |  |  |  |  |  |  | 0 | 0
 |  |  |  |  |  |  |  |  |  |  |  |  |  |  | 0 | 0
 |  |  |  |  |  |  |  |  |  |  |  |  |  |  | 0 | 0
 |  |  |  |  |  |  |  |  |  |  |  |  |  |  | 0 | 0
 |  |  |  |  |  |  |  |  |  |  |  |  |  |  | 0 | 0
 |  |  |  |  |  |  |  |  |  |  |  |  |  |  | 0 | 0
 |  |  |  |  |  |  |  |  |  |  |  |  |  |  | 0 | 0
 |  |  |  |  |  |  |  |  |  |  |  |  |  |  | 0 | 0
 |  |  |  |  |  |  |  |  |  |  |  |  |  |  | 0 | 0
 |  |  |  |  |  |  |  |  |  |  |  |  |  |  | 0 | 0
 |  |  |  |  |  |  |  |  |  |  |  |  |  |  | 0 | 0
 |  |  |  |  |  |  |  |  |  |  |  |  |  |  | 0 | 0
 |  |  |  |  |  |  |  |  |  |  |  |  |  |  | 0 | 0
 |  |  |  |  |  |  |  |  |  |  |  |  |  |  | 0 | 0
 |  |  |  |  |  |  |  |  |  |  |  |  |  |  | 0 | 0
 |  |  |  |  |  |  |  |  |  |  |  |  |  |  | 0 | 0
 |  |  |  |  |  |  |  |  |  |  |  |  |  |  | 0 | 0
 |  |  |  |  |  |  |  |  |  |  |  |  |  |  | 0 | 0
 |  |  |  |  |  |  |  |  |  |  |  |  |  |  | 0 | 0
 |  |  |  |  |  |  |  |  |  |  |  |  |  |  | 0 | 0
 |  |  |  |  |  |  |  |  |  |  |  |  |  |  | 0 | 0
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

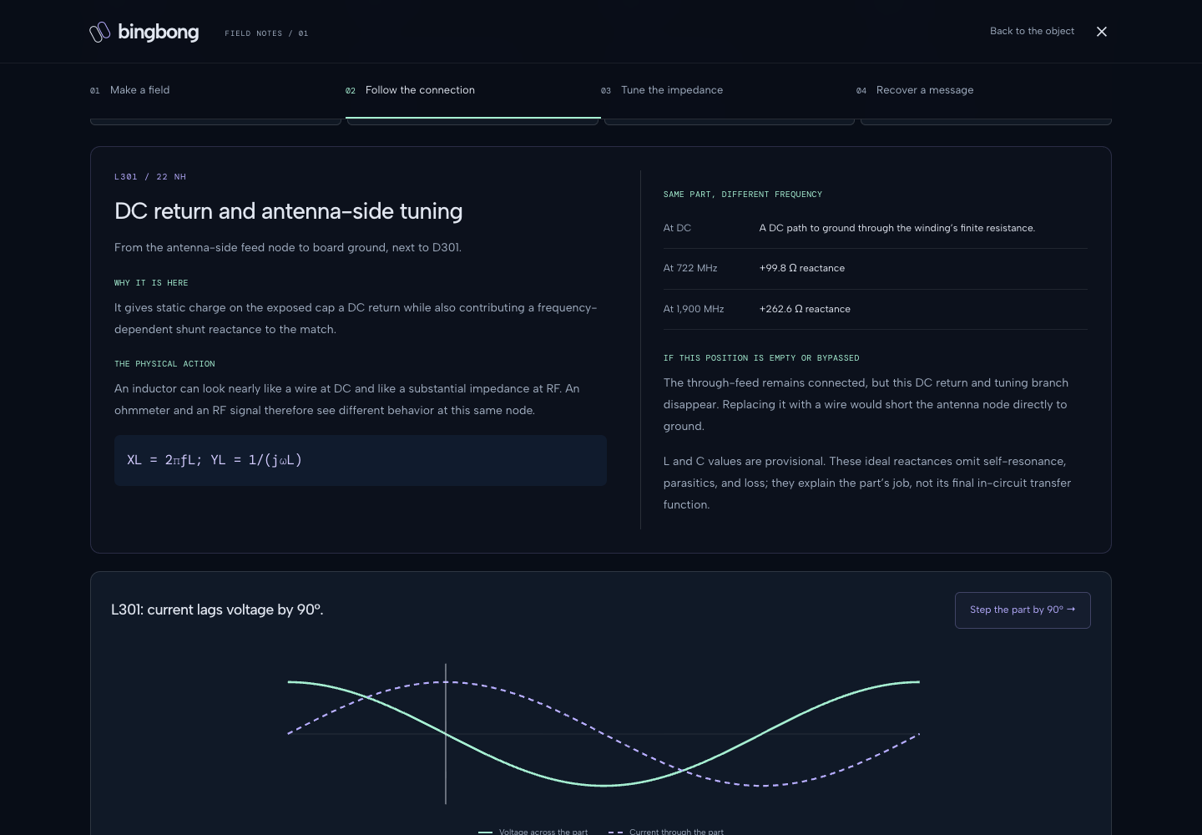
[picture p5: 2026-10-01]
site/qa/rf/deep/1440-component.png

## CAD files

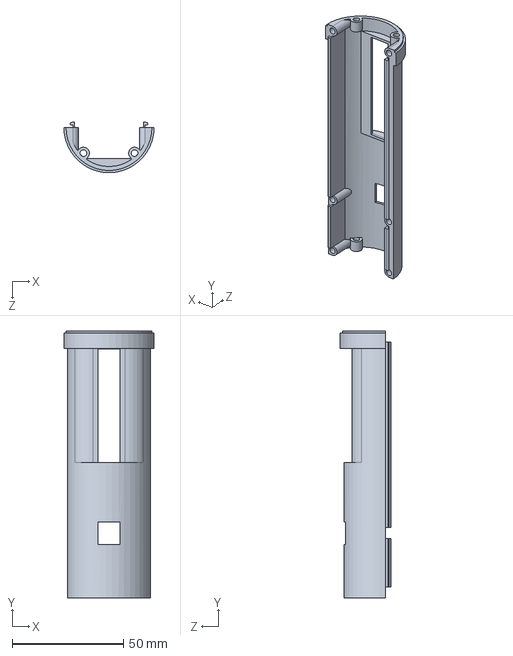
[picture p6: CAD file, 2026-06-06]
firmware/bingbong_pcb/bingbong_case_1.SLDPRT
40.6 x 120.0 x 22.7 mm

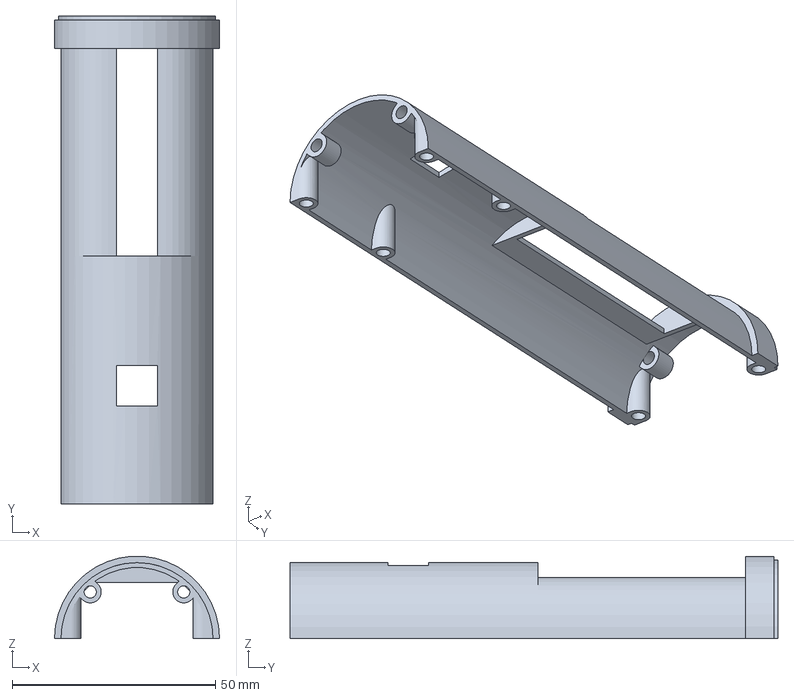
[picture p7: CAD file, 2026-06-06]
firmware/bingbong_pcb/test.3MF
40.6 x 120.0 x 20.2 mm

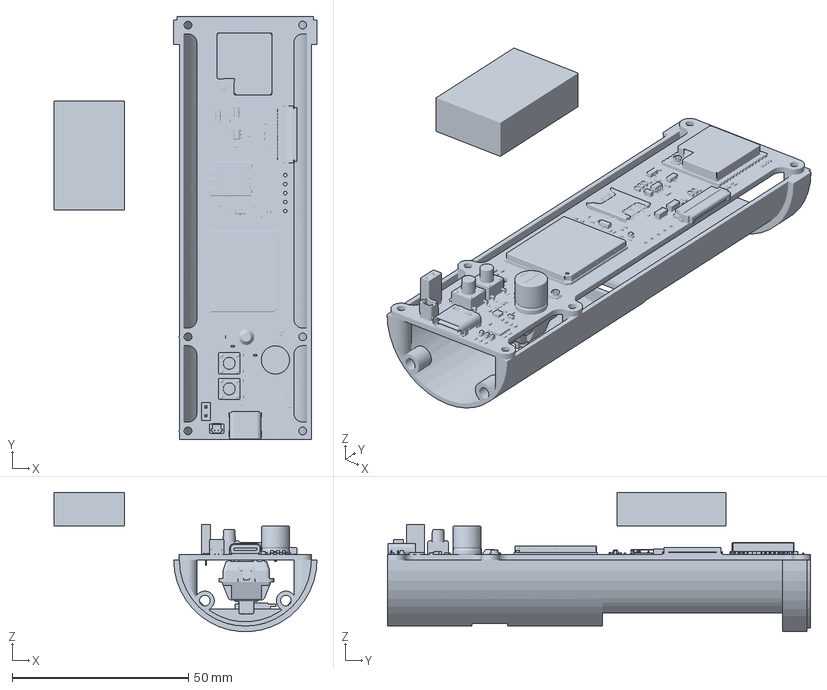
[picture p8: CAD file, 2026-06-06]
firmware/bingbong_pcb/bingbong_pcb_shape.3MF
74.5 x 120.0 x 39.4 mm

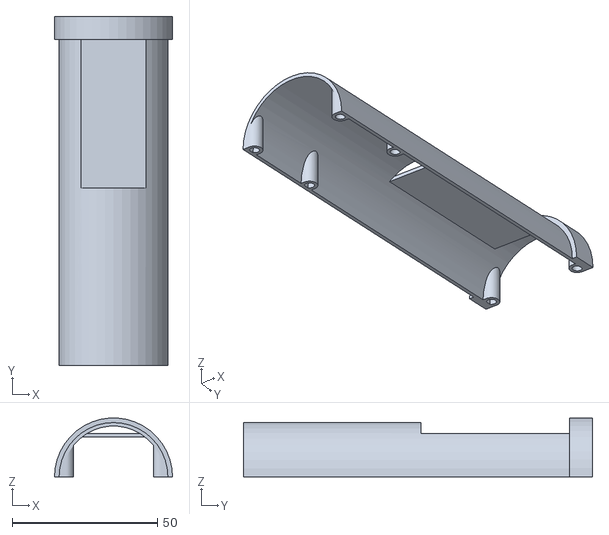
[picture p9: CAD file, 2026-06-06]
firmware/bingbong_pcb/case-test.STL
40.6 x 120.0 x 20.2

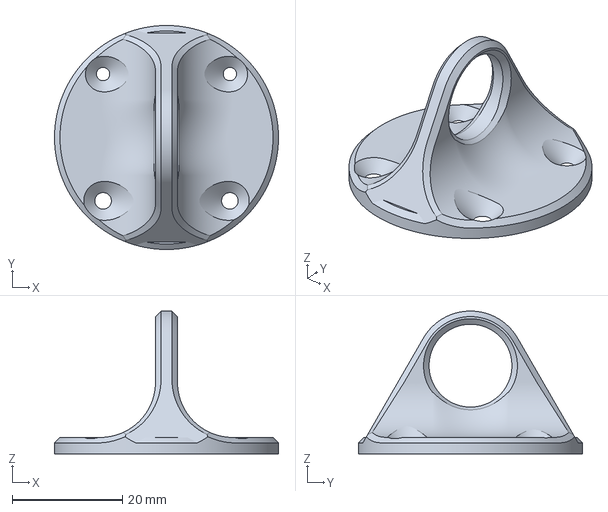
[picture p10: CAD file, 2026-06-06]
firmware/bingbong_pcb/keychain_top.3MF
40.6 x 40.6 x 25.9 mm

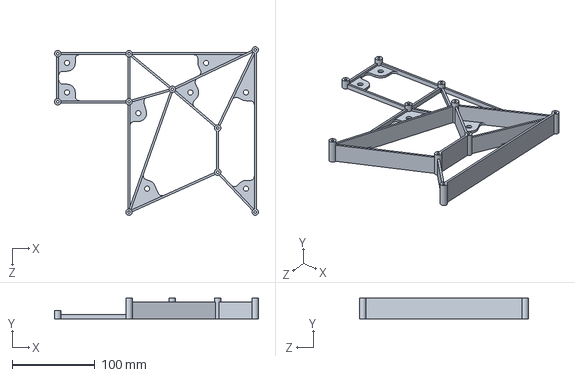
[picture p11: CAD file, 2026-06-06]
firmware/bingbong_pcb/helical_pcb_stand.SLDPRT
246.1 x 24.8 x 203.5 mm

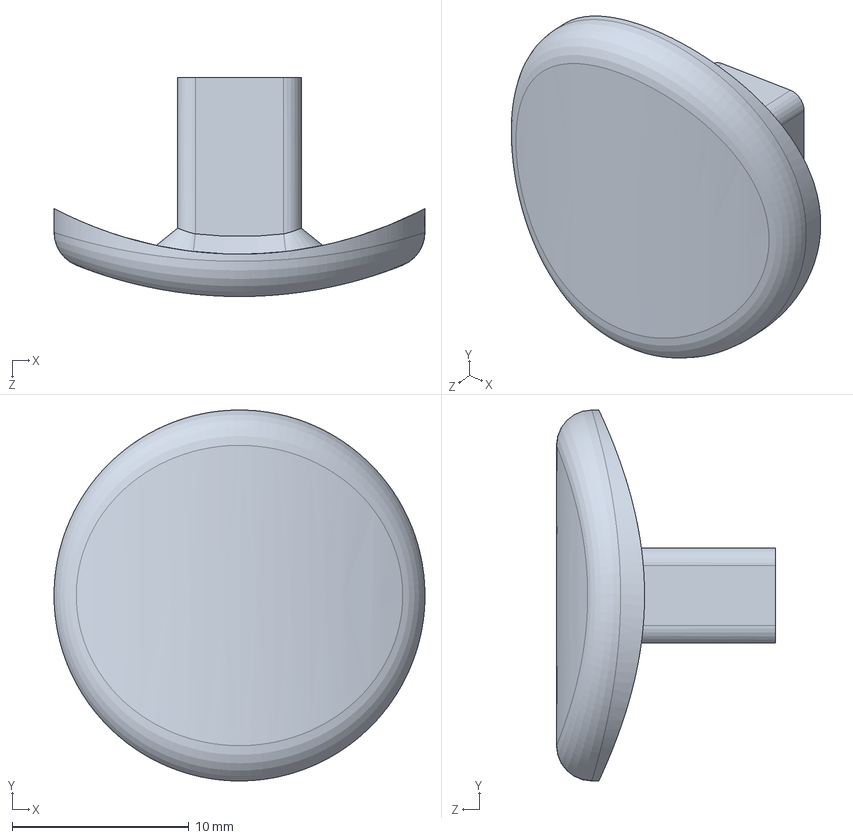
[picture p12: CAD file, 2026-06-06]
firmware/bingbong_pcb/bingbong_btn_ext.SLDPRT
21.0 x 21.0 x 12.4 mm

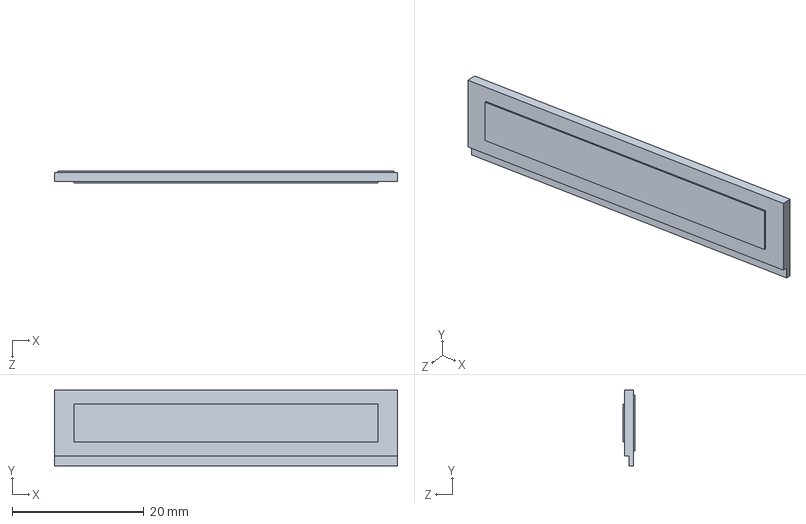
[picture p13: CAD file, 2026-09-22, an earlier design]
cad/ER-OLED018-1W_OLED_256x32.SLDPRT
52.0 x 11.5 x 1.83 mm

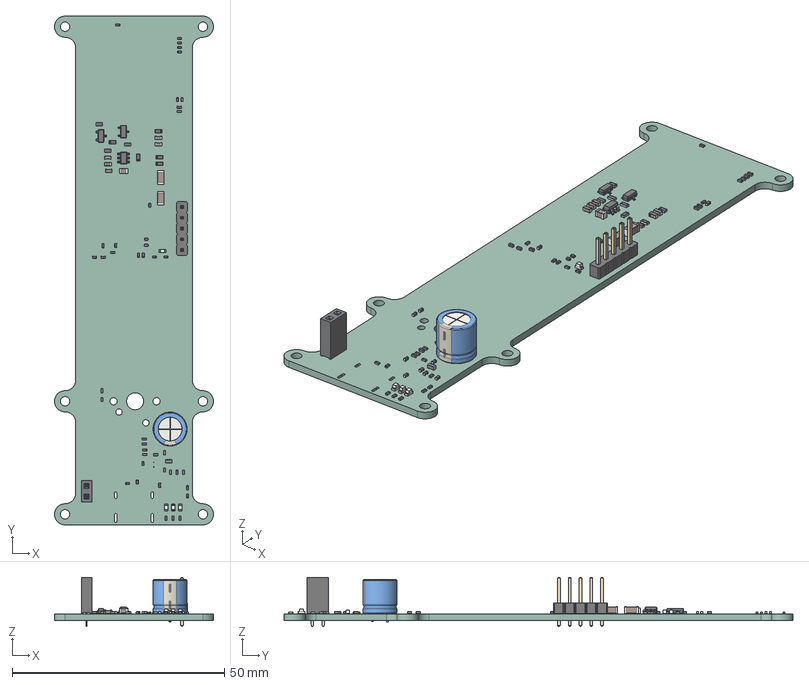
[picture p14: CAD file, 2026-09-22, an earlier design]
cad/bingbong-2026-03-20.step
37.5 x 120.0 x 11.6 mm
PinSocket_1x02_P2.54mm_Vertical
D_SOD-923 x 3
R_0402_1005Metric x 20
R_0603_1608Metric x 8
C_0603_1608Metric x 5
C_0402_1005Metric x 19
PinHeader_1x05_P2.54mm_Vertical
SOT-23 x 2
L_0603_1608Metric
LED_0603_1608Metric x 4
C_1206_3216Metric x 2
SOT-23-6
CP_Radial_D8.0mm_P3.50mm
L_0805_2012Metric
bingbong_PCB

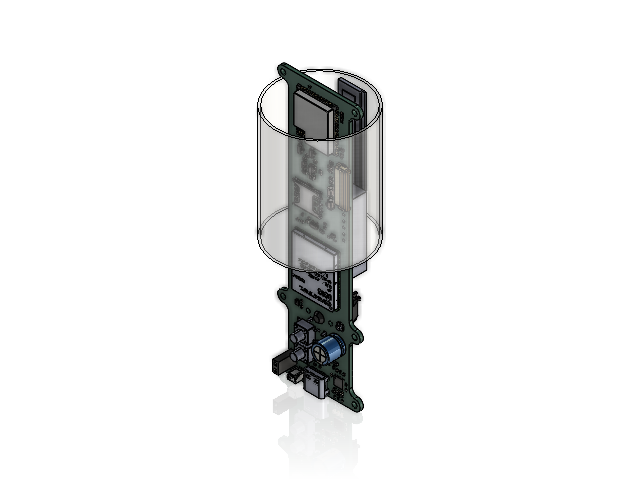
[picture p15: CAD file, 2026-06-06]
firmware/bingbong_pcb/Assem8.SLDASM
SOLID.step
COMPOUND.step
body.step
lock.step
pins.step
BMxxB-SRSS-TB(LF)(SN)_02.step
PinSocket_1x02_P2.54mm_Vertical_1.step
D_SOD-923_1.step x 3
R_0402_1005Metric_1.step x 20
R_0603_1608Metric_1.step x 8
C_0603_1608Metric_1.step x 5
C_0402_1005Metric_1.step x 19
SOT-23_1.step x 2
L_0603_1608Metric_1.step
UQFN-10_1.4x1.8mm_P0.4mm.step
CONMHF1-SMD-T.step
2452808-1.step
BG95M3LA-64-SGNS.step
LED_0603_1608Metric_1.step x 4
ESP32-S2-SOLO-U-N4R2--3DModel-STEP-510211.step
SOT-23-3.step
DFN-8-1EP_2x2mm_P0.45mm_EP0.64x1.37mm.step
Same_Sky_TS04-66-70-BK-100-SMT.step x 2
C_1206_3216Metric_1.step x 2
SOT-23-6_1.step
CP_Radial_D8.0mm_P3.50mm_1.step
UQFN-20-1EP_4x4mm_P0.5mm_EP2.8x2.8mm.step
L_0805_2012Metric_1.step
MX1A-11NN--3DModel-STEP-510211.step
bingbong_PCB_1.step
acrylic_tubing
ER-OLED018-1W_OLED_256x32
ASR00035_3.7_Lipo

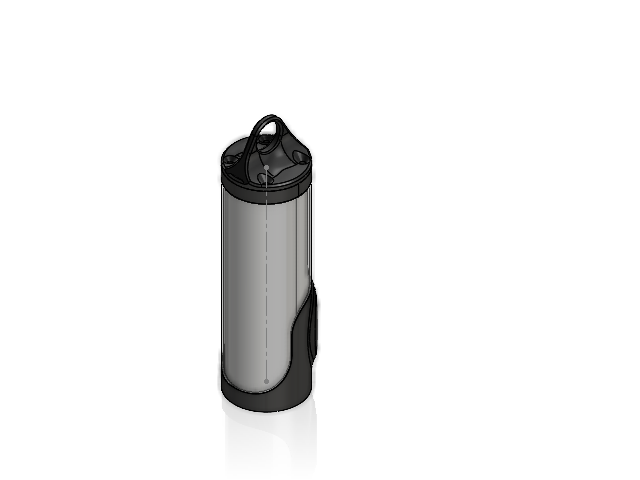
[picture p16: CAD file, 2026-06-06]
firmware/bingbong_pcb/bingbong.SLDASM
SOLID.step
COMPOUND.step
body.step
lock.step
pins.step
BMxxB-SRSS-TB(LF)(SN)_02.step
PinSocket_1x02_P2.54mm_Vertical.step
D_SOD-923.step x 3
R_0402_1005Metric.step x 20
R_0603_1608Metric.step x 8
C_0603_1608Metric.step x 5
C_0402_1005Metric.step x 19
SOT-23.step x 2
L_0603_1608Metric.step
UQFN-10_1.4x1.8mm_P0.4mm.step
CONMHF1-SMD-T.step
2452808-1.step
BG95M3LA-64-SGNS.step
LED_0603_1608Metric.step x 4
ESP32-S2-SOLO-U-N4R2--3DModel-STEP-510211.step
SOT-23-3.step
DFN-8-1EP_2x2mm_P0.45mm_EP0.64x1.37mm.step
Same_Sky_TS04-66-70-BK-100-SMT.step x 2
C_1206_3216Metric.step x 2
SOT-23-6.step
CP_Radial_D8.0mm_P3.50mm.step
UQFN-20-1EP_4x4mm_P0.5mm_EP2.8x2.8mm.step
L_0805_2012Metric.step
MX1A-11NN--3DModel-STEP-510211.step
bingbong_PCB.step
acrylic_tubing
ER-OLED018-1W_OLED_256x32
ASR00035_3.7_Lipo
bingbong_case_1
bingbong_case_2
bingbong_bottom_case
Part1^bingbong
bingbong_btn_ext

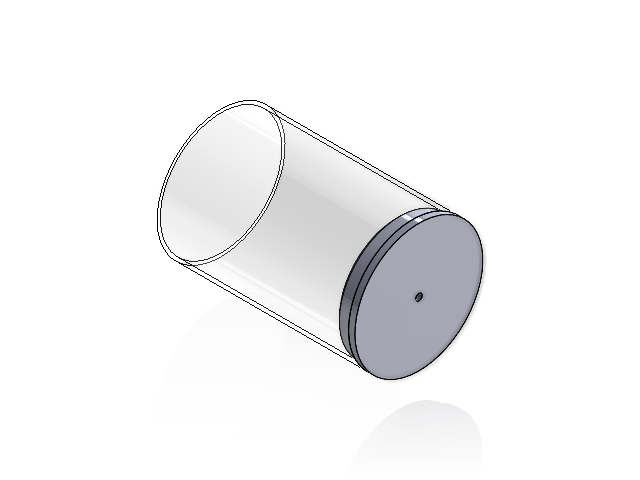
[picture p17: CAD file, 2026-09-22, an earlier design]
cad/Assem1.SLDASM
acrylic_tubing
Part3^Assem1

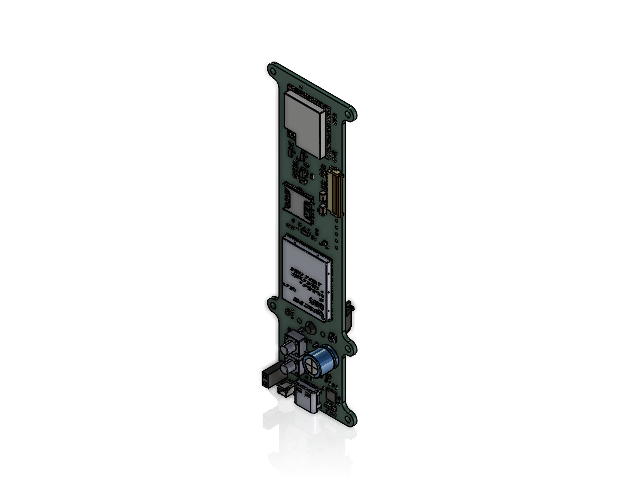
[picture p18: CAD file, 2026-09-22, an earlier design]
cad/bingbong_PCB.SLDASM
SOLID.step
COMPOUND.step
body.step
lock.step
pins.step
BMxxB-SRSS-TB(LF)(SN)_02.step
PinSocket_1x02_P2.54mm_Vertical.step
D_SOD-923.step x 3
R_0402_1005Metric.step x 20
R_0603_1608Metric.step x 8
C_0603_1608Metric.step x 5
C_0402_1005Metric.step x 19
SOT-23.step x 2
L_0603_1608Metric.step
UQFN-10_1.4x1.8mm_P0.4mm.step
CONMHF1-SMD-T.step
2452808-1.step
BG95M3LA-64-SGNS.step
LED_0603_1608Metric.step x 4
ESP32-S2-SOLO-U-N4R2--3DModel-STEP-510211.step
SOT-23-3.step
DFN-8-1EP_2x2mm_P0.45mm_EP0.64x1.37mm.step
Same_Sky_TS04-66-70-BK-100-SMT.step x 2
C_1206_3216Metric.step x 2
SOT-23-6.step
CP_Radial_D8.0mm_P3.50mm.step
UQFN-20-1EP_4x4mm_P0.5mm_EP2.8x2.8mm.step
L_0805_2012Metric.step
MX1A-11NN--3DModel-STEP-510211.step
bingbong_PCB.step

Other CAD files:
firmware/bingbong_pcb/bingbong_case_2.SLDPRT
cad/ASR00035_3.7_Lipo.SLDPRT
cad/Part3^Assem1.3MF
cad/acrylic_tubing.SLDPRT
cad/acrylic_tubing.STEP
cad/acrylic_tubing_shaped.STEP
cad/bingbong.step
cad/bingbong/bingbong_btn_ext.3MF
cad/bingbong/bingbong_case_1.3MF
cad/bingbong/bingbong_case_2.3MF
cad/bingbong/bingbong_case_2.SLDPRT
cad/bingbong/helical_pcb_stand - Copy.SLDPRT
cad/bingbong/helical_pcb_stand.3MF
cad/bingbong_bottom_case.3MF
cad/bingbong_bottom_case.SLDPRT
cad/bingbong_pcb.3MF
cad/bingbong_pcb.SLDPRT
firmware/bingbong_pcb/bingbong_btn_ext.3MF
firmware/bingbong_pcb/bingbong_case_1.3MF
firmware/bingbong_pcb/bingbong_case_2.3MF
firmware/bingbong_pcb/helical_pcb_stand - Copy.SLDPRT
firmware/bingbong_pcb/helical_pcb_stand.3MF

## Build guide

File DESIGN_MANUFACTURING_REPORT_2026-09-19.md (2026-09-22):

# bingbong — Step-by-step Design & Manufacturing Report (2026-09-19)

**Role of this document:** the single integrated engineering programme for the bingbong 27 × 95 × 15 mm sealed polymer capsule keychain — design phases, EVM-0 (Mules A/B/C), EVM-1, DVT, PVT — synthesised from the 2026-09-12 architecture decision document and the revised (post-hostile-review) domain reports of 2026-09-19. It is engineering, not marketing. Nothing in it is frozen until the EVM-0 gate (§2) reports.

---

## 0. Provenance, evidence standard and binding decisions

### 0.1 Evidence tags (the decision document's standard, applied throughout)

| Tag | Meaning |
|---|---|
| `[V]` | A primary datasheet or standards document was opened and the number read; the source is named where the tag appears or in §10. |
| `[V?]` | Read by one pass but contradicted, unreproducible, or read only from a secondary/summary source (supplier sheet, lab summary, search extract). Must be re-confirmed before design-in. |
| `[U]` | Nobody has read the primary source: an estimate, an engineering calculation from tagged inputs, or a vendor-marketing / distributor-parametric claim. |

Rules applied in this synthesis: no `[U]` was upgraded to `[V]` without a domain report naming the primary source it opened; where two domains tagged the same number differently the more conservative tag is kept and the disagreement is stated; no part numbers were invented — where a class of part is proposed, the text says what must be confirmed. Costs and durations are `[U]` unless a domain tagged them otherwise.

### 0.2 What was synthesised, and the gap closed in the second pass

Inputs to this report:

1. `C:\Users\chian\Projects\bingbong\REDESIGN_DECISION_2026-09-12.md` (the primary source, read in full by the editor: §3 block diagram, §4 BOM incl. §4.3/§4.4, §5 power, §6 mechanical incl. §6.2/§6.3/§6.4, §7 interaction, §8, §9 risks, §10 prototypes, Appendix, Addendum A).
2. Domain report **Crown & crown-end assembly** (revised after hostile review) → §4.
3. Domain report **End-cap antenna & RF front end** (revised after hostile review) → §5.
4. Domain report **Mechanical system, sealing, cell, LRA, final assembly and build plan** (revision 2 after hostile review) → §7.
5. Domain report **Electronics** (revision 2 after hostile review; second pass, merged 2026-09-19) → §6.
6. The 2026-09-19 decisions listed in §0.3.

**Electronics domain report — delivered in a second pass:** the brief names four domain reports, but only three reached the synthesis editor in the first pass and §6 was assembled by the editor from the decision document, the electronics content of §4/§5/§7 and the local nRF9151 PS front-matter extract (`firmware\bingbong_pcb\_mech\nrf9151_ps.txt`, 116 lines — "Up to 4x SPI master/slave with EasyDMA", "32 general purpose I/O pins", "Single 50 Ω antenna interface", PC3 23 dBm / PC5 20 dBm, −108 dBm Cat-M1 low band, PSM floor 2.7 µA, eDRX @ 81.92 s 18 µA — and no SPIM clock limit). **The electronics domain report was then delivered in a second pass — analysed by a domain analyst, hostile-reviewed (14 findings, 10 missing steps, 7 mis-tags) and revised — and merged into this report on 2026-09-19 as §6 (revised after hostile review), with its cross-domain conflicts added to §3 (C-22…C-30), its open questions to §8, its risks to §9 and its sources to §10.6.** §6 now carries the same evidence standard and the same review maturity as §4, §5 and §7; the reviewer's dispositions are in §6.1.1.

### 0.3 Decisions since the decision document (2026-09-19), binding on this report

1. **Display: the Sharp/Winstar memory-in-pixel LCD is replaced by an on-demand colour AMOLED** — 1.1" 126 × 294, RM69310 driver, 3/4-wire SPI, outline 12.96 × 30.94 × 0.78 mm, active 10.96 × 25.58 mm, 400–450 nits, VCI 2.7–3.6 V, VDDIO 1.65–3.3 V, ELVDD +4.6 V / ELVSS −2.2 V from an external AMOLED PMIC (TI TPS65631-class, 3 × 3 mm WSON, single-wire CTRL/SWIRE from the panel) plus a load switch on VCI/VDDIO. All AMOLED mechanicals are `[V?]` (vendor product page, no drawing — §7 makes the panel drawing an EVM-1 entry criterion). The screen sleeps between glances; **the halo carries arrivals.** The 0.60 mm frontlight reservation and ~1.3 mm of panel thickness are returned to the cell; the EXTCOMIN/RTC machinery is gone. The nRF9151 SPIM is taken as 8 MHz maximum `[V?]` (not in the PS extract opened; confirm in the full PS) → ~13.5 fps full-frame at 16 bpp; partial-window updates for animation (§6).
   - Consequences the domains carry: the doc's "always-on 20 µA screen" thesis (§1, §7.2 "stays on the screen indefinitely") is **withdrawn**; the crown, the two Hall latches and the halo are now the only always-available channels; the doc's "ZERO boost converters" line (§3) is no longer true — the AMOLED PMIC is a boost + negative charge pump and is an RF-desense and power-budget item (§5 Step 14, §6).
   - **Cell thickness:** the decision text's "~6.5–7 mm, ~700 mAh" is **not** available in the Z-stack as built: with the LRA on the top side the governing column closes only with a 6.0 mm cell (§7 Step 6, margin 0.70 mm); 6.5 mm needs an RF-gated LRA cut-out. See §3 conflict C-7.
2. **Crown geometry (coaxial twist vs transverse stroke) is OPEN pending Mule C** (doc §9.4, §10). Coaxial is the baseline throughout; §4 Design step 20 and §7 Step 12 state what changes if transverse wins; §7 Step 12 lists the tray features frozen at the EVM-0 gate so the tray tool is unaffected either way.
3. **The product page exists; this report is engineering.** Where a domain found the product story physically wrong (e.g. §7.1 "coasts about a third of a turn" — the crown cannot coast, §4 Design step 7; "looks up within ~15 ms" — an on-demand AMOLED wakes in ~100–200 ms `[U]`, §6), the correction is recorded in §8 for the product owner.

### 0.4 Coordinate frames and terminology harmonised across domains

- **Body frame X (mm):** the decision document's frame — X = 0 at the crown's front face, +X toward the antenna cap; crown zone X = 0–16, main PCB zone 16–68/71, split ring 71–72.5, end cap 72.5–95. §5, §6, §7 use this frame.
- **Crown frame x (mm):** the crown domain's frame — x = 0 at the crown-end shoulder (the tray's crown-end wall face), +x into the body; the crown front face is at x = −6.00. **X = x + 6.0.** §4 uses this frame; where a §4 number is quoted elsewhere it is converted.
- **PCB z:** the RF domain's feed-stack datum (PCB top surface); §5 Step 6.
- "**Bezel**" (crown report) = "**crown-end bulkhead / collar**" (mechanical report) = the tray's crown-end wall that carries the reamed ø13.30 crown bore, the debris pockets and the buried grip electrode, plus the snap-on cosmetic collar that hides the two lid screws. See §3 conflict C-2 for the harmonised module-to-tray interface.
- "**Split ring / annulus**" (RF) = "**ring-disc**" (mechanical) = the 1.5 mm optical-PC part between tray and cap: full web (sealing and light guide) with a sealed aperture for the cap's feed tab (§3 C-5).
- "**Satellite PCB**" = the 22 × 10 × 0.6 mm 2-layer board in the crown zone carrying the angle sensor, two DRV5032DU latches and the tact; two variants (MT6701 / AS5600L) per doc §4.5.
- Step labels are kept from each domain so that cross-references remain traceable: §4 uses *Design step n*, *M-n*, *Verification item n*, *Risk n*; §5 uses *Step n*, *Mn*, *V-n*, *Rn*; §6 uses *E-n*, *EM-n*, *EV-n*, *ER-n*; §7 uses *Step n*, *Jn* (joints), *Phase n / station n*, *Risk n*.

---

## 1. Executive summary

### 1.1 What gets built

A 27.0 × 95.0 × 15.0 mm PC/ABS **front tray + full-width screwed-and-snapped rear door** (over-moulded LSR bead gasket, 12 snap hooks + 2 × M1.4 Torx T3, IP67, end-user battery door for EU 2023/1542 Art. 11) holding a 23 × 52 × 0.8 mm six-layer PCB with the Nordic **nRF9151** LTE-M SiP, a 1.1" **RM69310 AMOLED** behind a 0.50 mm chemically strengthened glass lens (vendor-laminated, tail on a 0.4 mm-pitch B2B), a **23 × 43 × 6.0 mm pouch cell** (560–620 mAh `[U]`, connectorised, stretch-release PSA), a **VG0840001D 170 Hz LRA** on a bracket reacting against the PCB only, one TPS62840 3.1 V rail plus the AMOLED PMIC, a BQ25180 charger with a 4-pad magnetic pogo dock (VBUS/GND/SWDIO/SWCLK) and an MFF2 eUICC.

At the crown end (X = 0–16): a **one-piece turned 316L crown + hub** (13.0 OD × 8.0, 48 cut serrations, PVD, 6.0 mm proud) rotating and translating 0.40 mm on a **one-piece POM-C sleeve** carrying two ø0.8 Si₃N₄ balls on BeCu leaves into a **24-groove race** (17-4PH H900 wrought + wire-EDM baseline; zirconia and BeCu rings built in parallel for Mule C), a ø6 × 2.5 diametric magnet in the hub's rear pocket, an **LSR diaphragm bulkhead** with a PEEK-cored pip onto one off-axis EVPBB tact, an on-axis MT6701 (or AS5600L) and two DRV5032DU latches on the satellite PCB, and an optional low-squeeze FKM rotary O-ring whose fate Mule C decides.

At the antenna end (X = 68–95): a **machined 6061-T6 end cap** that is a coupling element exciting the whole 95 mm capsule's dipole-like mode at 722 MHz, isolated by the **1.5 mm optical-PC ring-disc** that is also the RGB halo light guide, fed by a **vertical-deflection BeCu spring finger** onto a plated land on the underside of an **L-shaped cap tab** through a 5-element 0402 dual-resonant match (B12 + B2/B4) with a ≤ 0.3 pF antenna TVS, a DC-return inductor and a Murata MM8130-2600 RF switch connector for test.

### 1.2 In what order

1. **Weeks 0–2 — freeze requirements and start the clocks** (§2 Phase 0): nRF9151 2k-reel PO and prototype quantity secured; AT&T "wearable vs SFF" classification letter; cell RFQ at 6.0 and 6.5 mm with capacity in writing; AMOLED panel drawing and RM69310/PMIC datasheets; Art. 11 legal opinion; ID sign-off on the 0.40 mm press stroke and on "no coast".
2. **Weeks 0–8 — EVM-0, three mules in parallel** (§2 Phase 1): Mule A (network, DK + PPK2), Mule B (RF, chamber), Mule C (feel, crown-end blocks) — with the EM simulation, the FEMM magnetics, the press-stroke stack and the to-scale Z/x CAD running alongside. **Gate G0 at week 8.**
3. **Weeks 8–20 — EVM-1, 20 units** on quick-turn aluminium tools with the first custom PCBA, real crown cartridges, real cap/ring/feed, real cells and laminated display modules: active TRP/TIS, SAR and radiated-spurious pre-scans, drop with monitored connectors, insert pull-out, PPK2 golden current, 0 °C brownout. **Gate G1 at week 20.**
4. **Weeks 20–36 — DVT, 150 units** on soft tooling, RF BOM frozen, the full DVT matrix (drop, IP67, altitude, thermal, damp heat, ESC/UV, salt/sweat, detent and press life, charge cycling, leak correlation), certification pre-scans. **Gate G2 at week 36.**
5. **Weeks 36–52 — PVT, 500 units** on hard tooling; PTCRB/CTIA/AT&T/FCC (+ ISED/CE if in scope) from PVT samples; ORT; production RF box, tracer-gas leak station, EOL dock jig, serialisation live. **MP after week 52.**

### 1.3 The five numbers that decide the product

| # | Number | Value | Why it decides | Where |
|---|---|---|---|---|
| 1 | **B12 total antenna efficiency, bare, 699–746 MHz** | binding **≥ 12.3 %** (doc); design target 15 %; Mule B stop-line **< 15 % → Plan B**; honest estimate 8–18 % `[U]` | The gate and the estimate are the same number; there is no catalogue fallback; B2/B4 need **≥ 17.8 %** as well | §5 rows 7–9, Step 2, V-5 |
| 2 | **Governing Z-stack margin** | **C′ = 0.70 mm with a 6.0 mm cell** (LRA top-side column); 6.5 mm cell → 0.20 mm (fails the 0.3 mm floor) unless the LRA drops into an RF-gated PCB cut-out | Sets the cell (560–620 mAh `[U]`), hence the runtime; the AMOLED decision's "~700 mAh" is not available without the cut-out | §7 Step 6; §3 C-7 |
| 3 | **Weekly energy vs usable capacity** | doc 127.84 mAh/wk vs 454 mAh usable (560 mAh × 0.81) → 3.5 wk; **with the AMOLED, editor estimate 132–153 mAh/wk (mid 139) `[U]`** → 3.0–3.4 wk on 560 mAh, 3.2–3.7 wk on 600 mAh; compound no-eDRX + deep coverage still fails 1 week | The one unbounded failure mode (coverage search) and the biggest line (eDRX paging) both rest on measurements Mule A must make | §6 E-9; doc §5 |
| 4 | **Crown press stroke and click window** | **S = 0.40 ± 0.03 mm** hard stop; click at 0.27 mm nominal, RSS 0.18–0.36; arithmetic worst-case does **not** close — design relies on 3-bin selective pip assembly + 100 % EOL force-stroke test; the doc's 0.25 mm cannot be built with an H ± 0.1 tact | The boop is the product's second input; if ID rejects 0.40 the tact class changes | §4 Design step 12, Risk 1 |
| 5 | **Detent contact stress vs race shakedown** | land contact **p₀ ≈ 2.1 GPa** at 0.49 N vs shakedown ≈ 1.9 GPa (wrought 17-4PH H900) / 1.75 GPa (MIM) / 0.4 GPa (303) → wrought marginal-OK, MIM ratchets, 303 brinells; **1,000,000 indexes, torque decay ≤ 15 %** | The dial is "one texture forever"; a race that brinells kills the gift inside its life | §4 Design step 6, Risk 2 |

Two more numbers sit just behind these: **first-motion detection ≤ 77° worst-case** (both DRV5032DU outputs on two devices at 90°; OUT1-only gives 121° and fails the doc's "within 90°") — now a hard requirement because the screen sleeps (§4 Design step 11); and the **crown-end zone closure at 11.6 of 16.0 mm** (4.4 mm spare; 2.9 mm with an FH12 connector) which the draft had broken and the revision restored (§4 Design step 15).

### 1.4 The three experiments that come first (EVM-0, doc §10 — revised build lists)

| Mule | Answers | Cost / time (doc) | Revised scope carried by this report |
|---|---|---|---|
| **A — network** (nRF9151-DK + PPK2 + 3 SIMs) | Is eDRX granted and at what cycle; PSM; AS-RAI; **does an MT UDP packet reach a device in RRC Idle at eDRX 163.84 s, and after how long**; measured paging energy (92.6 µA field `[V?]` vs 18 µA PS `[V]`); UICC supply shutdown; the +600 µA debug-UART regression baseline | < $2k, 2 wk — **start day one** | Adds: `%XCOEX0` and `%XRFTEST` syntax/semantics on nRF91x1 firmware (§5 Step 13, M14); band-mask and power-class switchability (§5 Step 1); SPIM maximum clock on the DK (§6 EV-1 a); AMOLED + PMIC current on a DK-driven panel (§6 E-5.7, EV-1 b) |
| **B — RF** (non-functional mechanical mock in a CTIA chamber) | B12 and B2/B4 total efficiency bare / body phantom / hand / keys ± interposer; cap length, ring gap, tab position, crown grounded/floating, **cell at X = 19–62 vs 24–67**, **PCB with vs without the LRA slot**, harmonic-band efficiency; feed-land route A vs C; cable-free cross-check | ~$20k incl. chamber, 5 wk | Gate **≥ 15 % bare at 699–746 MHz** (binding) plus B2/B4 ≥ 17.8 % floor; full build list §5 Week 0; RF-gated decisions for §7 (cell x, LRA cut-out) and §4 (crown material/floating) |
| **C — feel** (two printed crown-end blocks, coaxial + transverse, with real parts) | Coaxial vs transverse on 10 hands blind; detent torque and 100k decay; seal drag with/without the O-ring; press stack closure on ≥ 10 units; magnetics with three race materials; click separation to ≥ 12/s on a ~48 g mass; acoustics; nickel release, yank, permeability controls | ~$4k, 3 wk (+ $4k life rig) | Full list §4 Verification items 1–16; tray interface freeze for §7 Step 12 at the gate |

**Gate to EVM-1 (doc §10, extended):** Mule A — eDRX granted **and** MT paging delivers on ≥ 2 of 3 carriers, or a documented polling fallback with measured energy; Mule B — ≥ 15 % bare B12 on the metal cap **or** a Plan B that achieves it, plus a cell x and LRA-slot decision; Mule C — a chosen geometry, measured torque, click separation ≥ 12/s, press-stack closure, seal-drag decision, latch edge map, and the collar/bore/lug interface frozen. Paper items: AMOLED panel drawing, cell quotes at both thicknesses, Art. 11 legal opinion, AT&T classification answer, LSR grade with a self-bonding datasheet, ID sign-off on stroke 0.40 and "no coast".

---

## 2. Master sequence — the integrated programme

All durations and costs `[U]` unless a domain tagged them; costs are rolled up from the domain tables (§4 Sourcing, §5 Sourcing, §7 Sourcing, §6.5) and **overlap where domains costed the same item** (noted). Week 0 = programme start. Critical path items are in bold.

### 2.1 Phase 0 — Requirements freeze and long-lead starts (weeks 0–2)

**Entry:** this report accepted; owners named per domain.

| # | Action | Owner | Output / exit criterion | Feeds |
|---|---|---|---|---|
| P0-1 | **Place the nRF9151-LACA-R 2k-reel PO and secure ≥ 40 prototype SiPs** (16–19 wk factory lead `[V?]` doc §9.10; distributor stock was 283 at Mouser `[V?]`) | Electronics | PO acknowledged with a date ≤ week 19; ≥ 40 pcs for EVM-1 in hand by week 10 | EVM-1 PCBA |
| P0-2 | Written question to AT&T's Partner Coordinator: keychain = "wearable" (body phantom, v2.1 Note 6) or free-space SFF? | RF | Letter; Mule B pass/fail configuration fixed | §5 Step 1, V-5 |
| P0-3 | SKU decision: AT&T-only B2/B4/B12 first; B13/B5 disabled in the band mask; EU/Verizon as separate tunes | RF + product | Signed band plan | §5 Step 1, Step 16 |
| P0-4 | Cell RFQ to ≥ 3 pouch vendors per §7 Step 7, **at T 6.0 max and 6.5 max**, capacity and local face-pressure in writing; 50 samples each thickness ≤ 6 wk; 20 cells to ADI for the MAX17048 INI | Mechanical + electronics | Quotes; sample PO | §7 Step 6/7, §6 E-1 |
| P0-5 | AMOLED module: panel drawing (outline tolerance, COG ledge, tail pitch/length/bend zone, polarizer/back film, Tstg), RM69310 datasheet (SPI timing, sleep-in/out delays, partial-window commands), TPS65631-class PMIC datasheet, load-switch selection; 10 modules + 3 evaluation boards | Electronics + mechanical | Drawing in hand = EVM-1 entry criterion (§7); SPIM clock confirmed in the full nRF9151 PS | §6 E-5/E-6, §7 Step 4 |
| P0-6 | Art. 11 legal opinion ($3–5k, doc §9.9) — keychain classification, boxed T3 driver as the "free tool", 18 Feb 2027 date | Mechanical + product | Opinion before the lid tool is cut | §7 Step 14 |
| P0-7 | ID sign-offs: press stroke 0.40 mm (doc 0.25 cannot be built with an H ± 0.1 tact); "no coast" (threshold 9.7 rev/s); detent acoustic target; crown zone as drawn (one-piece crown+hub, 6.9 mm two-land journal, 0.8° tilt) | Crown + ID | Signed | §4 Design steps 7, 9, 12 |
| P0-8 | Antenna consultancy SOW: EM model contents (§5 Step 4, all 11 conductors), sweeps incl. harmonic bands, dual-resonant match, chamber support, cert configuration | RF | SOW signed; model started week 1 | §5 Phase 1 |
| P0-9 | Requirements document lines with numbers: coverage-search governor (backoff schedule, "stationary and untouched N min → stop", max search duty), eDRX/PSM-refused fallback, first-motion ≤ 90° as a hard spec, screen-wake latency budget | Firmware + product | Release-gate tests defined | §6 E-14, doc §5.4/§9.6 |
| P0-10 | MFF2 eUICC supplier: written confirmation of UICC supply-shutdown support and minimum shutdown interval | Electronics | Letter (free) | §6 E-3, doc §9.5 |
| P0-11 | LSR-capable moulder and watch-component crown maker short-listed; wire-EDM shop and 17-4PH heat-treater identified | Mechanical + crown | Quotes for §4 M-14/M-15 and §7 tooling | DVT tooling |

**Exit:** P0-1, P0-4, P0-5, P0-8 started; P0-7 signed. (P0-2/P0-6/P0-10 may land during Phase 1 but must land before Gate G0.)

### 2.2 Phase 1 — EVM-0: the three mules and the design analyses (weeks 0–8)

**Entry:** Phase 0 exit. **Quantities:** Mule A = 3 DKs + PPK2 + 3 SIMs; Mule B = 7–9 caps, 6 annuli, 5 boards, 1–2 shells, dummies; Mule C = 2 crown-end blocks (coaxial, transverse) with 3 groove/preload variants and 3 race materials, ~10 crown cartridges. **Cost:** Mule A < $2k; Mule B $6–11k hardware + $8–15k chamber (+ consultancy $20–40k running through EVM-1); Mule C ~$4k + $4k life rig + Ti control crown; mechanical mock-ups ~$12k (§7) → **≈ $35–50k hardware + labs, plus the consultancy retainer** (the doc's "~$30k" excluded the consultancy).

Run in parallel:

| Track | Weeks | Content (cross-reference) |
|---|---|---|
| **Mule A — network** | 0–2 (+ continuous PPK2 baseline) | doc §10; §6 EV-1: eDRX/PSM/AS-RAI grants, MT paging latency at eDRX 163.84 s, per-paging energy, UICC shutdown, UART regression baseline; `%XCOEX0`/`%XRFTEST` on nRF91x1 firmware; SPIM clock; DK-driven AMOLED current |
| **Mule B — RF** | 0–5 | §5 Verification Week 0–4: build list, bench V-1…V-4, chamber V-5/V-5b/V-6/V-7, decide V-8; both cell positions and the LRA slot (§7); feed route A vs C; ring gap 1.0/1.5/2.0 |
| **Mule C — feel** | 0–3 (+ 100k decay to week 5) | §4 Verification items 1–16: geometry (10 hands), torque, decay, seal drag, coast/rattle, press stack, magnetics with three races, sealing, ESD, drop, yank, permeability, nickel release, debris, acoustics, click separation; §7 Gate items (cold torque at −20 °C, field map, acoustic with/without cell contact) |
| **EM simulation** | 1–4 | §5 Steps 4–5 (model, sweeps incl. harmonic bands) → design point + dB/mm sensitivity table signed by mechanical |
| **Crown analyses** | 1–4 | §4 Design step 16: FEMM (both sensor variants, both latches, race and tact dome, press-induced change, stray field at the labyrinth); Hertz/shakedown; LSR skin + pip stiffness and 300k fatigue; ring/groove bearing at 150 N; drop 120 N on the hard stop; seal drag |
| **Mechanical CAD to scale** | 1–6 | §7 Steps 1–6, 12: tray/lid architecture, Z-stack columns A1/A2/B/C′/C/D with the PCB floor plan (§5 Step 11b, §6 E-12), the crown-module-to-tray interface (§3 C-2), lid rib FEA (§7 J1), lens ledge stack |
| **Electronics schematic v0** | 2–8 | §6 E-1…E-17: power tree with the AMOLED PMIC, GPIO budget, SPI throughput, satellite 10-way interface, ESD, dock; PCB rev A layout starts at week 6 against the Mule B keepout and the §5 floor plan |
| **Paper items** | 0–8 | P0-2, P0-4, P0-5, P0-6, P0-10; LSR grade with self-bonding datasheet; Panasonic EVPBB allowable static load in writing; Materion C17200 datasheet; ASTM B733/B488 opened |

**Gate G0 — EVM-0 → EVM-1 (week 8), all mandatory:**

1. Mule A: eDRX granted **and** MT paging delivers on ≥ 2 of 3 carriers, or a documented polling fallback with measured mAh/wk; measured paging energy replaces the 92.6 µA `[V?]` line; UICC shutdown confirmed on the bench.
2. Mule B: **≥ 15 % total efficiency bare, 699–746 MHz** on the metal cap (or a Plan B configuration that achieves it); B2/B4 ≥ 17.8 %; cell x (19–62 vs 24–67) and LRA slot (≤ 1 dB cost or dead) decided; feed route chosen; harmonic-band efficiency table delivered to §5 Step 10b.
3. Mule C: geometry chosen; torque 2.5–4.0 mN·m with ripple uniformity ≤ 15 %; ≤ 15 % decay at 100k; press stack closes on ≥ 10 units with 3 bins; seal-drag decision (O-ring in/out); INL and latch edge map (≤ 80° gap) met on ≥ 3 units; race material chosen from the field map (≥ 2× B_OP margin); cold torque at −20 °C; **collar/bore/lug/boss interface frozen** (§7 Step 12).
4. Paper: AMOLED panel drawing; cell quotes at 6.0/6.5 with capacity in writing; Art. 11 opinion; AT&T classification; ID sign-offs (P0-7); nRF9151 prototype SiPs allocated.

**If a gate item fails:** Mule B < 15 % → Plan B (polymer cap, 32 mm clearance, NN03-310 lengthwise, ~105 mm body) is simulated during weeks 4–6 and a Plan B mule is built before any tooling (doc §10; §5 V-8 table — the 12–15 % "one structural iteration" branch is a proposed amendment needing sign-off). Mule C transverse → satellite PCB respin (L-flex MT6701 or MA782 side-shaft), crown zone −3 mm to the keepout buffer, crown-module tool changes, tray tool unaffected.

### 2.3 Phase 2 — EVM-1: first real hardware (weeks 8–20), 20 units

**Entry:** Gate G0. **Cost:** mechanical ~$50k (quick-turn Al tray/lid tools $8–15k, cells, lenses, CNC caps, machined sleeves, proto LSR discs) `[U]` §7; PCBA rev A (main + 2 satellite variants, ~30 sets) $15–25k `[U]` §6; crown proto parts (turned crowns, EDM'd races, etched leaves, Ti control) ~$10k `[U]` §4; chamber active TRP/TIS + SAR pre-scan + spurious pre-scan $13–25k `[U]` §5 → **≈ $90–110k**.

| Step | Weeks | Content |
|---|---|---|
| EVM1-1 | 8–11 | PCBA rev A: §6 EM-1…EM-7b (6-layer 0.8 mm, copper ends X = 63.0, ten 0402 match positions, TVS, MM8130-2600, finger pad, AMOLED B2B at X = 46–49, PMIC in the side strip, 10-way satellite connector at X = 16–19.5, bottom-side strip connectors); satellite PCB both variants (§4 Design step 13) |
| EVM1-2 | 8–12 | Quick-turn Al tools for tray and lid (§7 Phase 1); separately moulded/die-cut LSR gasket; CNC caps with L-tab and land (§5 M1–M5, Route A on some, Route C on others); CNC/SLA optical-PC ring-disc with the sealed tab aperture; 10 bosses for insert pull-out |
| EVM1-3 | 9–13 | Crown cartridges from real parts through §4 M-1…M-23 at proto level (machined POM-C sleeves, loose LSR disc + machined pip in 3 heights, Panasonic EVPBB, wire-EDM'd wrought race, chosen race material variants) |
| EVM1-4 | 10–14 | Cells: 50 vendor samples, both thicknesses; 50 laminated lens + AMOLED modules with B2B tails |
| EVM1-5 | 12–16 | Bring-up: §6 EV-2 (rails, PMIC, SPI throughput and fps, NOR, eSIM, gauge, charger JEITA readback, DRV2625 waveforms, satellite both variants, IQS211B); PPK2 golden sleep current (< 200 µA at 60 s, target per §6 E-9/EV-3; §3 C-23); 0 °C brownout with a real 395 mA burst; COEX0 timing (§5 V-15) |
| EVM1-6 | 14–18 | RF: §5 V-9 conducted (MPR/A-MPR/ΔTC applied, H2/H3 at ANT, switch-connector IL), V-9b radiated-spurious pre-scan, V-10 active TRP/TIS (AMOLED on/off ≤ 1 dB), V-10b SAR pre-scan (PC3 vs PC5 decision), V-11 ESD, V-12 unit spread (σ ≤ 0.6 dB), V-13 temperature/humidity/swell, V-14 field (3 units, 2 wk), V-15 COEX0 |
| EVM1-7 | 14–18 | Mechanical: §7 Gate EVM-1→DVT items — all six Z columns ≥ 0.3 mm by shim; lid closes ≤ 150 N; 3 units fine-leak + immersion; 3 units 26-orientation drop with **continuous B2B monitoring**; insert pull-out ≥ 180 N / torque-out ≥ 0.08 N·m on 10 bosses; dock pull ≥ 200 g through the wall; ESC screen (Bergen jig) on tray/lid/ring; gasket reseal × 10 |
| EVM1-8 | 16–20 | Crown: §4 Gate to EVM-1 items re-run on production-intent parts; §9.11 1M-index rig started on the chosen variant (≈ 5.8 h at 2 rev/s per million, then talc/filings) |

**Gate G1 — EVM-1 → DVT (week 20):** RF: TRP ≥ gate + 2 dB and TIS ≤ gate − 2 dB on 3 channels/band in the certification configuration; spurious pre-scan passed or trap fitted with ≤ 0.3 dB in-band cost; SAR pre-scan decided PC3/PC5; unit σ ≤ 0.6 dB. Electronics: golden sleep current within budget; brownout margin at 0 °C ≥ 100 mV; fps and wake latency meet the P0-9 numbers; JEITA/gauge validated. Mechanical: all §7 Gate items; 6.0 vs 6.5 mm cell decided (with the Mule B slot result); panel B2B or hot-bar decided. Crown: press-stack closure on ≥ 10 production-intent cartridges; latch edge map at −10…+50 °C; nickel-release and yank in hand. Paper: cell CB/UN 38.3 test plan booked; PTCRB/GCF module status (§5 Step 15.2) confirmed; hard-tool decision (1+1 P20 + LSR 2-shot, $35–60k) taken.

### 2.4 Phase 3 — DVT (weeks 20–36), 150 units (~65 consumed by test)

**Entry:** Gate G1. **Cost:** mechanical tooling + build $60–90k `[U]` §7; PCBA rev B ~$20k `[U]`; crown tooling (POM sleeve tool $6–10k, LSR 3-cavity tool $12–20k, race EDM program/fixtures $3k, PVD fixtures, spring dies) $30–45k `[U]` §4; test labs (drop/IP/thermal/salt/altitude/ESC/UV/IEC 62133-2) $25–40k `[U]` §7; nickel-release + ESD + salt fog on crowns $3–5k `[U]` §4; cell CB + UN 38.3 $3–6k `[U]` → **≈ $145–210k**.

| Step | Weeks | Content |
|---|---|---|
| DVT-1 | 20–27 | Soft tooling: 7075 Al single-cavity tray (may be the EVM-1 tool re-cut) and ring-disc; lid as Al tool + small LSR gasket tool; POM-C sleeve tool + one-chucking secondary (§4 M-14); LSR diaphragm tool with 3 pip-height cavities (§4 M-15); production-intent crown module from the watch-component house; CNC caps by two shops (cap-to-cap RF spread ≤ 0.3 dB) |
| DVT-2 | 20–24 | **RF BOM lock** (§5 Step 16): cap alloy/finish, ring resin, cell vendor/thickness, LRA position, AMOLED module, PMIC, shell mould — any later change is an ECO with re-measurement |
| DVT-3 | 22–26 | PCBA rev B (layout fixes from EVM-1; SPI terminations; PMIC placement verified for TIS); satellite variant chosen or both kept |
| DVT-4 | 26–36 | The §7 DVT matrix: drop (26 orientations), tumble, lens impact, IP67 after drop/lid cycles/1M indexes/thermal/altitude/cold soak, altitude, thermal cycling + 72 °C × 3 + 80 °C stretch, damp heat (coupons 85/85; real module 60/90), ESC/chemical, UV, salt/sweat/EN 1811/dock-pad creep, detent life at three temperatures, press life 300k, charge/discharge 300 cycles with real bursts, cell safety certs, swell, acoustics, lug, lid service × 10 by naive users, dock 30k, **leak-test correlation (30 units, fine-leak vs IPX7/IP6X)**, RF pre-scans on RF-frozen units |
| DVT-5 | 28–34 | §5 V-16 golden units (5) and production box limits (−1.0/+2.0 dB, ≤ 0.3 dB repeatability); V-17 drop → S11 finger check; V-18 long-term (60 °C/90 % RH on real units within the cell vendor's limit; 85/85 + thermal cycling on dummy-cell RF units) |
| DVT-6 | 28–36 | Firmware release-gate tests: eDRX/PSM-refused fallback in a shielded box against a base-station simulator; coverage-search governor duty cycle; PPK2 on every release; FOTA delta (app + modem delta) end to end |
| DVT-7 | 30–36 | Production test development: §5 M12/M13/M14 (bed-of-nails DC checks, S11 finger signature, `%XRFTEST` shield box); §7 Phase 4 leak station commissioning; §7 Phase 5 EOL dock jig; §4 M-19/M-21/M-23 crown stations and the tact-height gauge; MES serialisation schema |

**Gate G2 — DVT → PVT (week 36):** all DVT failures closed with re-test; leak threshold frozen from the correlation set; RF pre-scans within 2 dB of the gates on RF-frozen units; golden units locked; firmware release gates passed; work instructions with photos; hard-tool release approved; certification lab slots booked.

### 2.5 Phase 4 — PVT (weeks 36–52), 500 units, then MP

**Entry:** Gate G2. **Cost:** hard tooling + build $75–120k `[U]` §7 (1+1 P20 tray + 2-shot LSR lid $35–60k; 2-cavity ring); fixtures (pre-line + 7 stations + crown cell + dock jig) $30–45k; **tracer-gas leak station $40–80k** (forming-gas variant $25–40k); production RF box/fixture/power meter $6–15k; crown assembly fixtures + life rig $20–30k `[U]` §4; **certification $50–150k** (doc; §5: PTCRB + CTIA OTA $15–35k, FCC Parts 24/27/15B + SAR $25–50k, ISED +$5–10k, CE RED + second tune + OTA +$30–60k) → **≈ $220–440k**.

| Step | Weeks | Content |
|---|---|---|
| PVT-1 | 36–46 | Hard tooling (8–10 wk); textured; first-off CMM (ledge 0.05 sort, rim 0.10, hook shoulder ± 0.05, crown bore); cap on a 5-axis cell; crowns on Swiss-type lathes with the M-4 permeability gate live |
| PVT-2 | 40–48 | Certification samples from PVT: PTCRB integration + CTIA OTA (per the classification answer), AT&T Table 4 report, FCC (custom chassis antenna → transmitter certified in our name; SAR), ISED/CE if in scope; cell IEC 62133-2 CB and UN 38.3 summary with the pack |
| PVT-3 | 44–52 | ORT: 20 units/week through drop/IP/thermal mini-loops for 4 weeks; yield targets: lamination ≥ 95 %, fine-leak ≥ 98 % first pass, EOL ≥ 97 %; Cpk ≥ 1.33 on lens sub-flush, lid step, gasket squeeze (lid height), crown torque, click travel |
| PVT-4 | 44–52 | Production readiness: golden RF units re-verified weekly; leak station correlated; tact-height gauge R&R; grease-mass audit (§4 M-22); EOL calibration capture (§4 M-23) writing the 24-point detent table to NVM; pair provisioning and eSIM profiles; split-shipping DG paperwork (UN3481 PI 967 Section II `[V?]`) |

**Release gate to MP:** certifications granted (or conditional with a dated plan); ORT four weeks clean; traceability live (serial ↔ pair ↔ cell ↔ module ↔ crown module ↔ leak value ↔ EOL ↔ firmware); spares path (cell + 2 screws + gasket) stocked for the Art. 11 five-year obligation.

### 2.6 Programme roll-up (all `[U]`, overlaps noted)

| Phase | Weeks | Units | Cost range |
|---|---|---|---|
| Phase 0 | 0–2 | — | legal $3–5k; silicon reels (nRF9151 2k × $16.08 = $32k, doc `[V]` price) |
| EVM-0 | 0–8 | 3 mules | $35–50k + consultancy $20–40k (runs to EVM-1) |
| EVM-1 | 8–20 | 20 | $90–110k |
| DVT | 20–36 | 150 | $145–210k |
| PVT | 36–52 | 500 | $220–440k |
| **Total to MP** | 52 | | **≈ $550–890k** excluding silicon reels and the optional in-line lamination cell (+$30–60k) — the domains' own subtotals (antenna $39–76k, certification $50–150k, mechanical/build $355–420k, crown-end $60–85k) overlap in the EVM-1/DVT builds and are not simply additive |

**Schedule risks that move the whole sequence:** nRF9151 lead time vs EVM-1 (P0-1); custom cell 12 wk from the EVM-1 gate (§7); LSR 2-shot moulder selection at G0; wire-EDM race capacity (bridge: broach-then-age); AT&T classification answer (changes the Mule B pass/fail configuration); Mule B < 15 % (adds a Plan B mule cycle of ~6 weeks and changes the shell).

---

## 3. Cross-domain conflicts and interfaces

Each conflict states the positions, which one is adopted and why, the owner, and the test or gate that closes it. "Adopted" means the domain sections in §4–§7 are read with this resolution; where a domain's text still carries the superseded position it is marked *[Editor: superseded by §3 C-n]* in place.

### C-1. Detent race material: 17-4PH H900 (crown) vs "replace with BeCu/zirconia" (mechanical)

- **Crown (§4):** wrought 17-4PH H900 (YS ≥ 1170 MPa, 40–48 HRC `[V?]`) with wire-EDM grooves after ageing is the only ferromagnetic part; it is coaxial and co-rotates with the magnet so its distortion is a static reshaping of the 2-pole field (< 5 % shunting expected `[U]`), not INL; fallbacks Y-TZP zirconia (preferred if the O-ring is deleted) and C17200 BeCu HT (38–45 HRC `[V?]`).
- **Mechanical (§7):** 17-4PH is "strongly ferromagnetic in all conditions" `[V]` ATI TDS; a concentric ferromagnetic ring rotating with the magnet is a static shunt (field-amplitude loss at DRV5032 and MT6701) plus a once-per-rev harmonic if eccentric; use BeCu C17200 TH04 or Y-TZP.
- **Resolution:** the two domains agree on the physics (static shunt, not INL) and on the test. **Adopted: Mule C builds all three race rings as swap-in parts** (wrought 17-4PH H900 EDM'd; Y-TZP CIM/sintered; C17200 TH04 turned + grooved + aged) and decides on the gaussmeter map — race delta ≤ 10 % at the IC, **≥ 2× B_OP margin at the latches (Bpk ≥ 8 mT)** — and on the 100k decay (≤ 15 %). Hertz check: BeCu TH04 at YS 1130–1420 MPa `[V?]` has a shakedown line (≈ 1.8–2.3 GPa) at or above the wrought 17-4 figure, so it is not excluded on contact stress; zirconia (HV ~1200) is above all of them. The 17-4 ring stays the *cost* baseline only until the map is in hand. Mechanical's station C1 "press 200–400 N" is superseded by §4 M-7 (0–0.02 mm interference + retainer, 50–150 N — a 0.03 mm press puts ~470 MPa hoop in the 1.0 mm annealed 316L wall). **Owner:** crown. **Closes:** Mule C item 7; §4 M-11 residual-magnetisation check applies to the 17-4 variant only.

### C-2. Crown-end architecture: one-piece crown+hub on a POM sleeve (crown) vs "crown bore on a fixed hollow sleeve, magnet in the end wall, 2.8 mm to the sensor, 0.25 stroke" (mechanical Step 12)

- **Crown (§4):** body-by-body dimensioned stack that closes at 11.6 of 16.0 mm; magnet in the hub's rear pocket (AG 1.0 mm rest / 0.6 pressed for the MT6701 `[V]` window 0.5–2.0); stroke 0.40 with a toleranced press stack; LSR diaphragm bulkhead with a compliant pip; retention by a BeCu C-ring; 6.9 mm two-land journal → tilt ≈ 0.8°.
- **Mechanical (§7 Step 12):** a sketch resolving the doc's "12 mm journal" inconsistency with a ≥ 6 mm sleeve journal (also 0.8°), magnet in the crown end wall, sensor behind a 1.0 mm moulded bulkhead at ≈ 2.8 mm, stroke 0.25 with a tact of ≥ 0.25 travel.
- **Resolution:** **§4 is authoritative for everything inside the crown module** — it is toleranced, it keeps the magnet inside the crown's own length (the doc's zero-marginal-length topology), it puts the sensor at the datasheet's mid-window rather than 2.8 mm, and it faces the tact-travel fact (no 0.5 mm-tall tact travels > 0.11 mm `[V]` Panasonic) instead of specifying a tact that does not exist in that height. Mechanical Step 12 is superseded except for (a) the **dual-compatibility freeze list** (crown-end bore, O-ring/gasket land, orientation key, two screw bosses, collar snap, lug position) frozen at Gate G0, and (b) the "draw to scale before Mule C" requirement. Both domains' 0.8° tilt figures agree; the doc's "< 0.5° on a 12 mm journal" is corrected in §8.
- **Harmonised module-to-tray interface (editor, for sign-off by crown + mechanical):** the crown cartridge (crown + sleeve + diaphragm + satellite PCB + carrier ring) is inserted **crown-first from inside the tray, before the lid closes** (§4 M-21), through the tray bulkhead's reamed ø13.30 +0.05/−0 bore; the sleeve flange (ø13.20) passes the bore and the **two retention ears on the wide-face sides** seat in pockets on the bulkhead's inside face — the ears are the yank shoulder (crown → C-ring → sleeve groove → ears → bulkhead). Because the 27 mm direction has room, the ears are widened from 3.0 to **6.0 mm** each (shear capacity ≈ 2 × 300 N `[U]`, doubling §4 Design step 14's figure). **J5 (the static seal) is a face seal on the flange/ear front face against the bulkhead's inside face** (LSR ring or O-ring in a flange groove, 25–30 % squeeze), not a radial seal on a "collar OD"; mechanical station 10 ("insert from outside") is superseded. The cosmetic collar snaps on from outside and hides the two lid screws; it carries no load and no seal. Mechanical's "crown-module bore ø~10.5" is superseded by ø13.30 + the ear pockets; the opening in the bulkhead inside face is sized for the sleeve nose only, the satellite PCB (22 × 10) is fitted to the cartridge before insertion and lies inside the tray. **Owner:** mechanical (tray), crown (cartridge). **Closes:** to-scale CAD by week 6; Mule C item 11 (yank 150 N / lug 300 N).

### C-3. Crown seal: optional 3–6 % squeeze FKM rotary O-ring (crown) vs 10–15 % squeeze low-temperature FKM (mechanical J6)

- **Crown (§4 Design step 8):** Parker ORD 5700 §8.13 rotary rules `[V]`: ID 1–3 % larger than the shaft, compressed from the gland OD, 3–6 % squeeze; computed drag 0.15–0.35 mN·m running / 0.6–1.4 breakaway `[U]` → optional, Mule C measures with/without; deletion implies a zirconia race (wet-tolerant mechanism); the LSR diaphragm alone protects the electronics.
- **Mechanical (§7 J6):** 10–15 % squeeze, low-temperature FKM (GLT/GFLT class) or PTFE-filled silicone, cold torque at −20 °C.
- **Resolution:** **Crown wins on squeeze and gland geometry** (primary source opened; 10–15 % is reciprocating practice and the review had already rejected it). **Mechanical wins on compound temperature class:** if the O-ring is fitted it is a low-temperature FKM (GLT/GFLT class, TR10 `[U]` — Parker bulletins not opened) or PTFE-filled silicone, and Mule C item 4 gains a −20 °C cold-torque run. Acceptance unchanged: ≤ 0.5 mN·m running / ≤ 0.9 breakaway or delete. **Owner:** crown. **Closes:** Mule C item 4; DVT IPX7 after −20 °C soak.

### C-4. Grip electrode and the crown's ESD path: exposed shoulder ring (doc, crown) vs buried insert-moulded ring (mechanical J8)

- **Doc / crown (§4 Design steps 12, 18):** IQS211B annular electrode on the static shoulder face; the floating crown 0.15 mm away arcs an 8 kV contact discharge across the labyrinth into the electrode's 2k2 + TVS — the ESD acceptance rests on that route, not on the LSR/PEEK dielectric numbers.
- **Mechanical (§7 J8):** the electrode is insert-moulded (or LDS) **inside** the bulkhead wall, 0.8–1.0 mm behind the shoulder surface — no feedthrough, no sealing joint; capacitive sensing through 1 mm of PC/ABS is standard practice; Cx still ≈ 5–15 pF `[U]`.
- **Resolution:** **Adopted: the buried electrode (mechanical)** — it removes a sealing feedthrough and an exposed metal ring at the E-field maximum of the antenna. **Consequence, which the crown text does not yet reflect:** the crown's ESD discharge can no longer reach the electrode's TVS through air; with 1 mm of PC/ABS (~20 kV/mm `[U]`) in the way the next-weakest path is the 0.30 mm LSR skin + pip to the tact (~6 kV `[U]`) — unacceptable. **A deliberate bleed/discharge path must be added:** a BeCu grounding leaf moulded into the POM sleeve, riding on the hub's rear land, taken through the flange to the satellite PCB → 1 MΩ to GND (keeps the crown RF-floating for §5) in parallel with a low-capacitance TVS to GND. This is the RF domain's "1 MΩ bleed from the crown insert via the wave washer `[U]`" made concrete. Alternative if the leaf is refused: a small exposed spark-gap pad on the shoulder tied to the TVS — a feedthrough again. **Owners:** crown (leaf in the sleeve), electronics (1 MΩ + TVS on the satellite PCB), mechanical (electrode ring in the bulkhead). **Closes:** §4 Verification item 9 (8 kV contact / 15 kV air with a current probe on the bleed line); doc §9.8 coupon with a press (Cx step on the 0.40 mm stroke) and a TX burst.

### C-5. Feed geometry, ring web and PCB edge: L-tab + z-deflection finger, PCB to X = 71 (RF) vs full-web ring-disc, ø3 boss with an x-loaded finger, PCB ending at X = 68 (mechanical J4/J9)

- **RF (§5 Step 6, M1, M7):** after review, the finger is a standard vertical-deflection (z) SMT part bearing on a plated land on the underside of an L-shaped cap tab that passes through the annulus's open centre and overhangs the PCB edge (tab to X = 68.5, finger at 68.5–70.5, board edge 71); the ring is an annulus with an open centre.
- **Mechanical (§7 J4/J9):** the ring-disc is an H-section optical-PC part with a **full web** (it is the seal and the light guide), skirts inside the tray end (X = 68–71, hence the PCB shortened to 68) and inside the cap bore; the RF feed is a ø3 boss through a ø3.2 hole in the web, with the finger bearing on the boss end face (x-loaded).
- **Resolution:** **RF wins on the feed load direction** (the x-loaded finger is the blocking finding F1 the RF review already killed — the boss end-face contact re-creates it). **Mechanical wins on the full web and the skirt** (sealing and the light path need it; PCB substrate ends at **X = 68.0**). Harmonised: the cap's L-tab (5 wide × 1.5 thick) passes through a **sealed rectangular aperture in the ring web** (≈ 5.6 × 2.1 mm, epoxied in the same operation as J4b — this is the new J9), continues −X over the PCB edge to **X = 65.5**, and its underside land (3.0 × 4.0 mm) sits at z = +1.4 mm above the PCB top; the finger moves to **X = 65.5–67.5**; the feed trace shortens to X = 63–65.5; copper still ends at 63.0. The tab cantilever grows by 3 mm (still a 1.5 mm-thick aluminium beam — the drop load path is the cap lip on the shell, never the tab or finger). The RF model (§5 Step 4.2) must now include the web (εr ≈ 2.9, tan δ ≈ 0.006 `[U]`) and the longer tab; Mule B sweeps tab length 5–8 mm. **Owners:** RF (tab, land, finger, trace), mechanical (ring-disc, aperture seal, tray end). **Closes:** Mule B V-1/V-5 (tab length is a sweep variable); §5 V-3 stack on 10 units; §7 leak correlation includes J9.

### C-6. Feed-land plating spec: "EN 3–5 µm + Au 0.1–0.3 µm" (mechanical Phase 2 item 3) vs "ASTM B733 Type IV/V ≥ 5 µm SC1 + B488 hard Au 0.25–0.5 µm, or a plated insert (Route C)" (RF M4)

- **Resolution:** **RF wins** — the spec was rewritten after review against the standard's classes (`[V?]` until B733/B488 are opened); mechanical's process line is updated to §5 M4 (Route A masked immersion EN + Au; Route C plated pin as co-baseline; Route B recorded only). Acceptance: ≤ 5 mΩ land-to-cap, tape adhesion + thermal shock, XRF thickness 5/lot. **Owner:** RF; mechanical carries it in the cap drawing. **Closes:** Mule B V-3 / V-8.

### C-7. Cell thickness: "~6.5–7 mm, ~700 mAh" (AMOLED decision; RF model) vs "6.0 mm baseline, 6.5 only with the LRA cut-out" (mechanical Z-stack)

- **Resolution:** **Mechanical's arithmetic wins** (§7 Step 6): the governing column is the LRA on the top side (C′ = 0.70 mm at 6.0 mm; 0.20 at 6.5 mm; −0.30 at 7.0 mm). The 6.5 mm option exists only if the LRA sits in an 8.4 mm PCB cut-out at X = 52–60, which slots the counterpoise — **RF-gated on Mule B: if B12 efficiency drops > 1 dB with the slot, the cut-out is dead and the cell is 6.0 mm.** The RF EM model runs both cell boxes (6.0 and 6.5 mm, X = 19–62). The power model (§6 E-9) is re-run at **600 mAh conservative** (560–620 `[U]` for 6.0 mm), not 700. Capacity in writing from the cell vendor at T-max including PCM/wrap at 50 % SoC is a Gate G0 paper item. **Owners:** mechanical (Z), RF (slot), electronics (power). **Closes:** Mule B slot/no-slot; EVM-1 shim measurement of all six columns.

### C-8. Cell x-position and the keepout: doc §6.2 (cell 24–67, LRA 55–69) vs RF (cell ≤ 61, LRA ≤ 61, no metal in X > 61) vs mechanical (cell 19–62, LRA 52–60, brass bracket to 61)

- **Resolution:** the doc's own layout violates its own keepout (§5 R7) — **adopted: cell X = 19–62, LRA X = 52–60 top side, bracket ending ≤ 61 (polymer preferred; brass acceptable only if it ends ≤ 61), halo LED at X = 62–63, copper ends at 63.0, PCB substrate at 68.0.** The doc's "10 mm from the ring" rule is itself `[U]`; the cell at 19–62 is 9 mm from the ring at X = 71. Mule B measures **both** cell positions (19–62 and 24–67) and the number decides; if 24–67 must be used the crown-end connector strip at X = 16–19 gains 5 mm and the RF cost is the price. The 3.0 mm PCB rear-side strip at X = 16–19 (cell 3-way B2B, dock 5-way B2B, two tooling holes) is a layout closure item (§7 Step 11, §6 E-12). **Owners:** RF (keepout), mechanical (layout), electronics (strip closure). **Closes:** Mule B V-1/V-5 with cell/LRA at both positions.

### C-9. LRA steel can vs antenna keepout vs acoustics vs Art. 11

- Positions agree once C-8 is applied: LRA at X = 52–60 on a bracket soldered to the PCB, **≥ 0.3 mm air gap to the cell face, the lid and the front wall, no PSA to the cell** (§7 Step 9 — reacting the moving mass against the pouch drives it as a diaphragm and glues the battery in, defeating Art. 11); bracket first mode ≥ 800 Hz; acoustic ≤ 35 dB(A) at 10 cm `[U]` provisional, set from Mule C. The doc's "bracket tied to PCB **and cell mass**" (§3, §6.4) is corrected: PCB only. The RF model carries the can as steel Ø8 × 4.05 at 49.5–57.5 per §5 Step 4.5 — **harmonised to X = 52–60** (mechanical) so both domains model the same position. **Owners:** mechanical (bracket), electronics (DRV2625 braking), RF (position). **Closes:** Mule C acoustics with/without cell contact; Mule B with the can at 52–60.

### C-10. AMOLED PMIC switching vs RF sensitivity (TIS)

- The PMIC (boost + negative charge pump, ~1–2 MHz `[U]`) and its inductor are new noise sources next to a −108 dBm receiver. **Adopted (§5 Step 14, §6 E-5):** PMIC + shielded inductor at **X < 40** in the side strip beside the panel, input and output capacitors within 2 mm, ELVDD/ELVSS on inner layers between ground planes, load switch off and PMIC disabled when the screen sleeps; SPI SCK with 33 Ω series termination and routed away from the ANT trace. **Acceptance:** TIS screen-on (full white, max brightness) vs screen-off Δ ≤ 1 dB (§5 V-10); conducted spur scan on VSYS/V3. **Owner:** electronics; RF tests. **Closes:** EVM-1 V-10.

### C-11. SPI bandwidth vs animation vs the product's latency story

- nRF9151 SPIM ≤ 8 MHz `[V?]` (not in the PS extract opened; the PS front matter only lists "up to 4× SPI master with EasyDMA") → 126 × 294 × 16 bpp = 592.7 kbit = **74 ms per full frame → 13.5 fps**; a 4-wire interface with no QSPI (the SiP has none). **Adopted (§6 E-6/E-7):** partial-window updates (RM69310 column/row address windows `[U]` until the driver datasheet is opened) for the creature's animated region; full-frame only on wake; TE-synchronised writes; wake sequence (load switch → PMIC enable → SWIRE → sleep-out → first frame) budgeted at **100–200 ms `[U]`**. This changes the doc's §7.2 "creature looks up within ~15 ms": the **halo and the LRA respond within 15 ms; the screen follows within ≤ 200 ms** — a product-story correction recorded in §8. **Owner:** electronics/firmware. **Closes:** Mule A DK measurement of the real SPIM clock and the panel's sleep-out time; EVM-1 fps and wake-latency test.

### C-12. Satellite interconnect: 6-way FFC (doc, mechanical) vs 10 signals (crown)

- **Resolution:** **10 signals** (3V1_ON, MT_VDD_SW, GND, SDA, SCL, HA1, HA2, HB1, HB2, TACT) — both DRV5032DU outputs on both latches are required for ≤ 90° first-motion detection (§4 Design step 11); the doc's 6-way is superseded. Main-board side: a 10-way 0.5 mm connector (FH12-10S-0.5SH `[U]` confirm; 2.0 mm tall `[V]` for the 6S/8S) or a hot-bar pad field at the top-side strip X = 16–19.5 — column D has 7.8 mm of Z (§7 Step 6) so height is not the constraint; **the 3.0 mm x-depth of the strip is** (a 10-way FH12 body is ~3–4 mm deep `[U]`): if it does not close, the satellite tail is hot-bar soldered to a pad field (crown baseline) or the cell moves to X = 20–63 (Mule B). **Owner:** electronics; crown supplies the tail. **Closes:** PCB rev A layout (week 6–8).

### C-13. Sensor supply rail: 3.1 V −2 % = 3.04 V against a 3.0 V minimum (MT6701 `[V]`, AS5600L `[V]`)

- The load switch must add ≤ 20 mV at 14 mA (R_on ≤ 0.5 Ω, §4 Design step 19) — or the rail moves. AMOLED VDDIO max is 3.3 V (`[V?]` decision text) so a 3.3 V rail at +2 % (3.37 V) is out of spec for the panel; a **3.2 V** setting (3.14–3.26 V at ± 2 %) satisfies both the sensors and VDDIO **if the TPS62840's RSET table offers 3.2 V** `[U]` — the doc's RSET 71.5 kΩ → 3.1 V is itself `[V?]`. **Adopted:** keep 3.1 V with a ≤ 0.5 Ω load switch as baseline; evaluate 3.2 V at schematic once the TPS62840 Table 1 is re-read (§6 E-1, §8). **Owner:** electronics. **Closes:** schematic review; EVM-1 rail measurement under the 14 mA MT6701 load.

### C-14. Magnets: crown sensing magnet vs Hall latches vs dock-head magnets vs key fobs vs the LRA

- Positions: sensing magnet at X ≈ 6.25–8.75 (crown hub), latches at X ≈ 10.5 on r = 4.0; dock shim at X = 33–45 (> 20 mm from the latches, > 26 mm from the ring), head magnets in the dock (device carries none — a device-side magnet would cost Z and sit within reach of the 3.9 mT latches); LRA at X = 52–60 (> 40 mm from the sensors); the M-16 magnet bond is the **last** mechanical step so no process heat reaches it; keys shed steel filings into the labyrinth mouth (§4 Verification item 14). **Adopted:** no device-side magnet (Addendum A.2); verify no DRV5032 false latch while docked (head magnets > 25 mm from the sensing magnet) at EVM-1; 50 mT fob at 20 mm for 24 h adds ≤ 0.5 mAh/day (firmware confirms a latch edge with an MT6701 delta before waking the radio). **Owners:** crown (latches/magnet), mechanical (shim/dock), electronics (wake logic). **Closes:** EVM-1 A.5-9 dock test; §4 Risk 14 fob test.

### C-15. Debris chamber and the 15 mm-face wall

- Doc §6.4's 0.6 × 1.5 mm annular chamber in a ø13.30 bore leaves 0.25 mm of wall on the 15 mm faces. **Adopted (§4 Design step 8.2):** two arc pockets of 0.6 radial × 1.5 axial over ± 50° centred on the 27 mm faces; 0.15 mm deep on the 15 mm faces (wall ≥ 0.70 mm). Mechanical's J6 text ("0.6 × 1.5 mm debris chamber") is superseded; the bulkhead mould-flow and the crown-end corner-drop analysis (§4 Risk 11) must include the 0.70 mm wall. The buried grip electrode (C-4) must be routed clear of the pockets. **Owner:** crown (spec), mechanical (mould). **Closes:** Mule C item 10 corner drops; mould-flow on the tray.

### C-16. Crown material and permeability gate: 316L at µr ≤ 1.05 (crown) vs "Ti Gr2 preferred, brass + PVD, 316L only at µr ≤ 1.01" (mechanical)

- **Resolution:** **Crown wins** — 316L one-piece crown+hub with **cut** serrations (no rolled knurl, no welds, no rivets), lot gate µr ≤ 1.05 with a low-mu indicator (ASTM A342 `[U]`), Ti Gr5 as the Mule C control and the premium/fallback grade; the ASSDA "< 1.02 after cold work" statement does **not** cover 316L (re-tagged `[U]`). Brass is rejected (lead-bearing C36000 under REACH; soft; nickel-free but PVD-dependent). Decision rule: if Mule C INL with the 316L crown differs from the Ti control by > 0.3° after the 24-point EOL table, switch to Ti Gr5 (+$3.0/pc `[U]`). Nickel release (EN 12472 wear → EN 1811, `[V?]`) decides between PVD'd 316L and Ti for the skin-contact crown and lug. **Owner:** crown. **Closes:** Mule C items 7, 12, 13.

### C-17. Keyring lug position and load path

- Crown: lug insert-moulded in the crown-end bulkhead flank at "x ≈ 8–14" — evidently the **body** frame (its own crown frame ends at x = +10), i.e. X = 8–14; mechanical: insert-moulded 316L in the **tray** flank at X ≈ 6–10, on the right flank, with the collar clear of it. **Adopted:** lug insert-moulded in the **tray** (monolithic, carries 300 N; a snap-on collar must not), right flank, **X = 8–14**, with a clearance slot in the cosmetic collar; the 28 mm Dyneema interposer is mandatory (RF). Yank path: crown → C-ring → sleeve groove → ears (6.0 mm wide, C-2) → bulkhead; lug path: lug flange → tray flank. **Owner:** mechanical (lug), crown (yank). **Closes:** §4 Verification item 11; §7 DVT lug test (100 N × 60 s, 10k jerks).

### C-18. Sealing vs serviceability

- The cap/ring/tab joints (J4a/J4b/J9), the lens (J2) and the dock pads (J3) are permanent; the only user-openable joint is the lid (J1) — LSR bead 30 % squeeze, 12 snaps + 2 screws, retention ≥ 2 × (gasket + 26 kPa altitude) ≈ 230 N budgeted at ≈ 360 N; the crown module is a factory sub-assembly behind J5 and the diaphragm; the cell is on a connector with a stretch-release tab. Art. 11's wet-environment derogation is **not** relied upon (C/2025/214 `[V]`). No conflict between domains; the interface is that **the crown cartridge is not user-serviceable** — a failed crown is a unit swap. **Owner:** mechanical. **Closes:** DVT lid-service × 10 by naive users → IPX7; altitude → IPX7.

### C-19. Z-stack vs cell vs drop

- Agreed: cell located by its edges (lid perimeter ribs, tray stubs), free on the lid side into the 0.60 mm swell gap, bonded only on the PCB-side insulator; PCB clamped in Z between tray ribs and lid rib ends (0.05–0.10 interference through the gasket's compliance) so a drop never loads the display B2B or the SiP; lens −0.08 ± 0.05 sub-flush; bottom-side components under the cell limited to the insulator + connector strip at X = 16–19 (the doc's "22 µF bottom-side beside the SiP" is superseded: bulk caps go **top-side in the 5.8 mm strips beside the panel**, where ≈ 4.85 mm of height exists — §7 Step 5, §6 E-12). **Owner:** mechanical/electronics. **Closes:** EVM-1 shim measurement; 26-orientation drop.

### C-20. The doc's Mule C race and the §9.11 life rig

- Doc §10 builds Mule C with "hardened 17-4PH races"; §4 separates the 3-week feel mule (100k decay per variant) from the §9.11 qualification rig (1M indexes + 300k presses + talc + filings on the chosen variant only). **Adopted:** Mule C = feel + down-select with three race materials (C-1); the 1M rig starts at Gate G0 on the chosen variant and runs through EVM-1. **Owner:** crown.

### C-21. Interfaces that are *not* in conflict but must be written down (the hand-off list)

| Interface | From → To | Content |
|---|---|---|
| Crown conductors for the EM model | crown → RF | crown material/mass (316L 5.1 g vs Ti 2.8 g), **floating with a 1 MΩ bleed** (C-4), position (13 × 8 cup at the E-max), 17-4/BeCu/zirconia race, BeCu ring/washer/leaves, magnet, satellite PCB 22 × 10, buried electrode ring |
| Keepout and floor plan | RF → electronics/mechanical | copper ends X = 63.0 ± 0.1; nothing metallic in X > 61 except the feed; three-strip top-side plan X = 49–68 (§5 Step 11b, adjusted for the 68 mm PCB) |
| PCB z-datum | mechanical → RF | PCB seated on tray ribs (Z1); cap on the shell shoulder (Z2); stack ± 0.38 worst case → 2.5 mm free-height finger or PCB-referenced stop (§5 Step 6) |
| Z columns and placement rules | mechanical → electronics | SiP at X = 20–32 under the panel; shim 33–45; B2B 46–49; fold 49–51; flex tail never under the LRA; tall parts in the side strips |
| Satellite tail | crown → electronics | 10 signals, soldered tail or FH12-10S, pinout fixed (§4 Design step 13) |
| COEX0 | electronics → firmware/RF | `AT%XCOEX0=2,1,690,760,1,1700,2160` `[V]` syntax (nRF9160 guide v1.9), RF-active semantics; GPIO → IQS211B masking + 20 ms |
| EOL calibration data | crown → firmware | 24-point detent table + 8 latch-edge angles in main-MCU NVM (§4 M-23) |
| Cell spec sheet | mechanical → electronics | §7 Step 7: PCM trip, DC-IR, NTC β 3435, 3-contact B2B, mechanical acceptance |
| Leak-test value, EOL record, firmware versions | production → MES | §7 Phase 5 serialisation |

### C-22. Production programming and lock order: "MCUboot + app + modem in one pass, then APPROTECT locked" on the bare board (doc A.2, §7 Phase 5) vs the RTT factory-mode command on the finished unit (§5 M14)

- **Doc A.2 / mechanical (§7 Phase 5):** the bare PCBA is programmed and APPROTECT-locked at the bed-of-nails fixture; the finished unit is "recoverable through the dock by full erase".
- **RF (§5 M14):** `%XRFTEST` and `%XPRODDONE` are issued as a factory-mode command over the dock's SWD/RTT on the *finished* unit, after the radiated go/no-go — impossible once APPROTECT is set (RTT needs the debug port).
- **Electronics (§6):** the same channel is needed for eSIM confirmation and ship-mode entry; a locked, un-provisionable unit is the highest-irrecoverability production risk (ER-6).
- **Resolution — adopted:** bare board = passive test → image load → powered test → provisioning, **unlocked** (EM-6a → EM-7a → EM-6b → EM-7b); **APPROTECT + SECUREAPPROTECT are the last SWD operation at pack-out (EM-9b)**, after `%XPRODDONE`, eSIM confirmation and ship mode; the failed-unit path (recover → EM-7a → … → EM-9b, serial/pair code re-provisioned from the MES) is defined; A.2's "recoverable through the dock by full erase" is unchanged. §7 Phase 5 is read with the EM-9b step and the recovery path appended. **Also:** the doc's "charge current held off until dock presence" is a BQ25180 register rule (ICHG set only after a valid NTC read and VIN-good, E-1.2) plus a dock-head enable, never a device-side VBUS switch — a firmware-gated VBUS path is a dead-battery/ship-mode lockout (E-2, ER-1). **Owner:** electronics (fixture and jig sequence), production. **Closes:** EV-15 production-flow dry run before the first DVT lot.

### C-23. Sealed-unit EOL sleep current: "1 in 20 via SWD/PPK2, < 200 µA after 60 s" (§7 Phase 5) vs what a dock can measure

- **Mechanical (§7 Phase 5):** sleep current 1 in 20 via SWD/PPK2 (< 200 µA after 60 s) on the dock jig.
- **Electronics (§6 EM-9, EV-3):** with VBUS present the BQ25180 supplies SYS from VIN, so nothing on the dock sees the cell-side current; the "eDRX idle" figure needs a live attach the shield box does not have; and the first draft's EV-3 (135 µA) and EM-9 (200 µA) limits disagreed.
- **Resolution — adopted:** the sealed-unit EOL step becomes a **VBUS-side gross-leak screen, 1 in 20: charging disabled by I²C, screen asleep, modem `CFUN=0`, Δ vs the golden unit ≤ +50 µA `[U]`** after the BQ25180 VIN-side quiescent is characterised on 10 units (EV-3) — it catches a console left on (+600 µA) or a stuck screen, not a 10 µA fault (ER-20). The **cell-side ≤ 40 µA (`CFUN=0`)** is measured on the bare PCBA through the VBAT test pad (EM-6b) and on the golden unit every release (EV-3); the **eDRX-idle ≤ 135 µA mean over 30 min `[U]`** is an EV-3/lab number only. §7 Phase 5's line is read with this replacement; §2's "< 200 µA at 60 s" EVM-1 target is read as the EV-3 pair. **Owner:** electronics; production. **Closes:** EV-3 10-unit characterisation; OQ-19 (whether the VBUS-side screen is stable enough or is dropped for ORT cell-side sampling).

### C-24. Satellite tail, amended: 10-way (C-12) vs 12-way with two grounds; the TACT conductor is a BQ25180 /MR-domain net

- **C-12 as adopted:** 10 signals, FH12-10S-0.5SH `[U]` or hot-bar; the 3.0 mm x-depth of the strip is the constraint.
- **Electronics (§6 E-10, E-15):** the crown's ESD bleed (C-4) returns its TVS clamp current through the tail ground; on a 10-way tail that is one conductor beside the latch lines — proposes **12-way with GND on pins 1 and 12**; **FH12-12S-0.5SH exists in the same series `[V]`** (Hirose FH12 catalogue extract `bom-scratch\fh12.txt`: contact-array width 5.5 vs 4.5 mm, body 10.1 vs 9.1 mm; the series x-depth is not in the extract → `[U]`). **New:** TACT drives the BQ25180 /MR pin directly and the nRF reads it only through a gate-to-V3 N-FET limiter (E-13) — so the **TACT conductor idles at the /MR pull-up voltage (`[U]`, possibly VBAT-referenced; SLUSE99C not opened)**: the satellite's tact switch and trace must be rated for it and no nRF-domain logic shares that conductor (ER-10).
- **Resolution:** electronics proposes, crown decides at the rev A layout; if §4 keeps 10-way, E-10's pin order applies and EV-10 probes HA1 for ground bounce during the crown discharge (≤ 0.5 V). Connector height (2.0 mm `[V]`) is fine either way; the hot-bar pad field remains the baseline for both domains (§7 Step 6 column D). **Owner:** electronics proposes; crown decides. **Closes:** rev A layout (week 6–8); OQ-11; EV-2 TACT idle-voltage measurement.

### C-25. Dock pads: plating spec wording, pitch tag, and the fifth conductor

- **Mechanical (§7 Step 11) / doc A.2:** "Au over 1.0–2.5 µm Ni", 2.54 mm pitch tagged `[V]`, fifth conductor = dock presence.
- **RF (§5 M4):** ASTM B488 hard-gold classes for the feed land.
- **Electronics (§6 E-13, EV-8):** 1.0–2.5 µm Ni is thin for 30k cycles in sweat; the hostile review caught "Type II" mislabelling hard gold. Proposed wording: **ASTM B488 Type II (99.0 % Au, cobalt-hardened), Code C (hard), ≥ 0.76 µm over ≥ 2.5 µm Ni `[U]` until B488 is opened** — consistent with §5 M4; acceptance is EV-8's 30k cycles then ≤ 100 mΩ. The **2.54 mm pitch is `[U]`** — the doc's basis is "wearable-charger de facto standard", not a drawing (§0.1 rule: nothing is `[V]` without a source); §7 Step 11 and the first-issue §6 row are read with that tag. **Dock presence is read from the BQ25180 VIN-good via /INT** (no divider); the flex's **fifth conductor is re-assigned to jig ID/presence (EOL fixture only, 1 MΩ pull-down)** — §7 Step 11's connector pin list and the EOL jig spec follow.
- **Owner:** electronics (spec), mechanical (flex drawing). **Closes:** B488 opened at the flex drawing release; EV-8; OQ-12.

### C-26. Side-strip placement moves (§5 Step 11b, §7 Step 5) and the C-10 extension

- **First-issue §6:** BQ25180 + MAX17048 at X = 40–48 "near the connectors" (the connectors are at X = 16–19); MAX17048 on V3.
- **Electronics (§6 E-12, corrected):** **BQ25180 + MAX17048 + the three limiter FETs at X = 19–28 in the −y strip** (cell B2B, dock B2B and the SiP VDD within ≈ 10 mm; the 395 mA burst path ≤ 10 mm); **IQS211B at X = 24–30** (sense line still leaves on the crown side; electrode ≥ 40 mm from the cap holds); **AMOLED PMIC + inductor + switches A/B at X = 30–40 (−y)**; +y strip: 2 × 22 µF, eSIM X = 22–30, TPS62840 X = 34–40, NOR X = 40–46; halo FETs and the RF strip unchanged; **MAX17048 VDD on BAT** per the doc's block diagram (the gauge must read the cell with the buck off). A shielding-can footprint at X < 40 is reserved and, if fitted, is to be listed in §5 Step 4's conductor list.
- **C-10 extended:** two load switches (A on VCI/VDDIO from V3, B on the PMIC VIN from VSYS); the PMIC's IQ(off) and IQ(VIN present, CTRL low) are `[U]`; the wake order puts PMIC VIN on *before* SLPOUT so the panel's SWIRE burst is not lost. No change to the C-10 acceptance (TIS Δ ≤ 1 dB). C-11's 100–200 ms wake budget is refined to ≈ 135–160 ms `[U]` with a ≤ 200 ms provisional acceptance (halo/LRA carry the 15 ms). C-13 unchanged; E-1.6 adds the VCI ≥ 2.7 V check (passes).
- **Owner:** electronics; RF (conductor list). **Closes:** rev A layout; EVM-1 V-10.

### C-27. `%XMAGPIO` provisioning (§5 M12, first-issue §6 EM-4) vs the nRF9151 pin list

- The nRF9160 AT guide v1.9 `[V]` defines `%XMAGPIO`; whether the **nRF9151 exposes MAGPIO0–2 at all is `[V?]`** (not in the PS extract; OQ-3). **Adopted:** §5 M12 and EM-7b read "`%XMAGPIO` if present"; nothing in the design depends on it (no aperture tuner). **Owner:** electronics. **Closes:** PS pin list; Mule A EV-1 (f).

### C-28. AMOLED module storage temperature (§7 Step 4, doc §4.4) becomes a purchasing and warehouse requirement

- The module is not reflowed (mated at final assembly) but has a storage-temperature limit `[U]`; the doc's +60 °C dashboard warning (§7 Risk 11) transfers to storage. **Adopted:** modules stored ≤ 40 °C / ≤ 60 % RH in original trays, no bake, Tstg and storage conditions on the PO (EM-3, EM-5, §6.5 item 2); §7's final-assembly line must not bake or reflow the module. **Owner:** electronics (PO), production (warehouse). **Closes:** panel datasheet Tstg (§8 A-4).

### C-29. EU SKU EMC immunity and the dock's own EMC — new certification lines

- §5 Phase 4 covers radio and spurious emissions; nobody had listed immunity. **Adopted (EV-12):** EU SKU — EN 301 489-1/-52 radiated immunity (80 MHz–6 GHz, 3 V/m class `[U]`) and conducted immunity on the dock cable, ESD per EV-10; the dock board itself to EN 55032/55035 `[U]`. **Owner:** whoever owns the dock board (electronics by default); RF adds the lines to the §5 Phase 4 scope. **Closes:** DVT pre-scan; §8 C-8.

### C-30. Evidence-tag harmonisation from the electronics pass (§0.1)

- Every vendor web page (TI product pages for TPS65631/TPS22916, the Vybronics LRA page, the Mouser stock line) is `[V?]` in §6; the doc's `[V]` on the Vybronics page and the Mouser stock line, and the first-issue §6's `[V]` on the 2.54 mm dock pitch, are harmonised to `[V?]`/`[U]` wherever this report repeats them. `datasheets\ER-OLED018-1_Series_Datasheet.pdf` is the V1 1.8" SSD1326 PMOLED datasheet (BOM_VALIDATION_2026-09-04 §2), not an RM69310 source — no RM69310 or panel electrical table exists in the project. **Owner:** editor. **Closes:** on the next errata pass of the decision document.

---

## 4. Crown & crown-end assembly — domain report (coaxial baseline; transverse alternative in Design step 20)

*Frame: crown frame x (x = 0 at the crown-end shoulder face, +x into the body, crown front at −6.00); body X = x + 6.0. "Bezel" below = the tray's crown-end bulkhead (§0.4). Editor notes in italics mark §3 resolutions.*

### 4.1 What this subsystem is

The crown end is the only moving mechanism in the product and the only dynamic interface on a sealed capsule. It is a **coaxial knurled metal cup (13.0 OD × 8.0 mm, protruding 6.0 mm) with an integral ø7.0 mm hub** turned from one bar. The hub carries the **ø6 × 2.5 mm diametric NdFeB magnet in a pocket at its rear end, inside the crown's own 8 mm length** (the doc's "zero marginal length" topology, §6.2 — restored after the review showed the draft's shaft-head layout added ~2.9 mm and broke the 16 mm budget). The crown+hub rotates and translates **0.40 mm** (raised from 0.25 — see governing number 9) on a **one-piece static POM-C sleeve** that carries the two ø0.8 Si₃N₄ balls on BeCu cantilever leaves; the 24-groove race is bonded in the crown skirt and co-rotates with the magnet (*race material per §3 C-1: 17-4PH H900 wrought baseline, zirconia and BeCu built in parallel for Mule C*). A **BeCu wire C-ring** in matching grooves on hub and sleeve is the outward stop and the pull-out retention; a BeCu wave washer preloads the crown outward against it. Behind the hub, an **LSR diaphragm (0.30 mm skin) clamped on the sleeve flange is the bulkhead**; a PEEK-cored pip on its dry side presses one off-axis EVPBB tact on the satellite PCB. Nothing but flux crosses the diaphragm (*plus, per §3 C-4, one BeCu grounding leaf moulded into the sleeve for the crown's ESD bleed*). There are **no welds** and every joint is made from the rear in the order it is reached; PVD happens on the finished crown before any assembly.

**What changed from the draft (review outcome).** Accepted and fixed: zone closure (blocking); unreachable weld / 2.0-deep socket in a 1.6 wall (blocking) — eliminated by the one-piece crown+hub; press-stroke tolerance stack (blocking) — stroke 0.40, selective pip assembly, tolerance table in Design step 12; wave-washer datums — one datum set, one table; rotary O-ring drag — computed, made optional, Mule C measures with/without, Parker §8.13 gland rules applied; debris-chamber wall on the 15 mm faces — chamber now on the wide faces only; MIM race tolerances/hardness — wrought + wire-EDM after H900 is baseline, MIM demoted; DRV5032DU two-output — both outputs used, 8 edges/rev, worst-case gap computed 75°, flex 10-way; 316L ASSDA misattribution — re-tagged `[U]`, cut serrations only, Ti control on Mule C; concentricity chain — one worst-case chain, 0.28 mm; nickel release — EN 1811/EN 12472 added; EVPBB 1.0 N travel 0.08; R_b 4.25 and I from a mass build-up; 16 mm bar capacity; PCB placement ring; labyrinth bore tolerance; Mule C vs §9.11 life scope.

### 4.2 The numbers that govern it

| # | Quantity | Value | Tag / source |
|---|---|---|---|
| 1 | Crown envelope | 13.00 −0.03 OD over crests × 8.00 ± 0.03; protrudes 6.00 ± 0.10; recessed 0.4 radially inside the shoulder; 0.15 labyrinth in a reamed ø13.30 +0.05/−0 bulkhead bore | `[U]` doc §4.3/§6.2/§6.4 + this report |
| 2 | Detent count / pitch | 24 → 15° → 1.70 mm crest travel per detent (π·13/24) | computed |
| 3 | Ball-centre radius | R_b = 4.20 (land) / 4.30 (seated) → **4.25 ± 0.05** (race ID 9.20, ball ø0.80, groove 0.12 deep) | computed (draft's 4.4 corrected) |
| 4 | Detent torque | F_n seated 0.40 ± 0.08 N/ball, α_eff 30–35°, µ 0.10 → **T_peak 2.4–2.9 mN·m** nominal, 1.9–3.9 over tolerances; target 2.5–4.0 | `[U]` doc target; math step 6 |
| 5 | Crown inertia / coast | m ≈ 6.1 g (316L cup + hub + race + magnet), I ≈ 1.25 × 10⁻⁷ kg·m² (mass build-up, not ½mr²); barrier ≈ 0.23 mJ; KE at 5 rev/s ≈ 0.06 mJ; coast threshold ≈ 9.7 rev/s → **no coast**; §7.1 "coasts a third of a turn" must be dropped | computed, step 7 |
| 6 | Race material | 17-4PH **wrought** H900: UTS ≥ 1310, YS ≥ 1170 MPa, 40–48 HRC (Ulbrich sheet); MPIF-35 wrought H900 40 HRC / MIM H900 33 HRC, YS 1090 (Markforged sheet quoting MPIF 35); "strongly ferromagnetic in all conditions" (Ulbrich `[V?]`, ATI TDS `[V]` via §7) | `[V?]` two supplier sheets agree; SAE AMS 5643 / ASTM A564 / MPIF 35 text not opened |
| 7 | Hertz on the race | land contact 0.50 N: p₀ ≈ 2.1 GPa (E* 133 GPa, R_e 0.42 mm); shakedown ≈ 1.6·σ_y ≈ 1.9 GPa wrought / 1.75 GPa MIM → wrought marginal-OK, MIM ratchets | computed, step 6 |
| 8 | Angle sensor windows | MT6701: Bpk 200–1000 G at IC surface, AG (magnet-to-IC-surface) 0.5/1.0/2.0 mm, DISP ≤ 0.3 mm, VDD 3.0–5.5 V, power-up ≤ 1 ms, QFN 0.70–0.80 tall. AS5600L: VDD3V3 3.0–3.6 V, Bz 30–90 mT at die on a 1 mm circle (Bz_ERROR 8 mT), typical airgap 0.5–3 mm, **max axis displacement 0.25 mm with a 6 mm magnet**, WL-CSP Hall array **172.5 µm off chip centre**, INL ± 1°, I²C 0x40 programmable, IDD NOM 6.4 / LPM1 3.3 / LPM2 1.8 / LPM3 1.5 mA | `[V]` MT6701 DS Rev 1.5 §5 + tables; `[V]` AS5600L DS v1-12 |
| 9 | Press stack | Stroke **S = 0.40 ± 0.03** (hard stop crown skirt on POM flange); EVPBB2A9B000 1.6 N / 0.11 mm travel / H 0.53 **± 0.1**, general tol ± 0.05, 500k; 1.0 N and 0.7 N variants travel **0.08**; click at 0.27 mm nominal (RSS 0.17–0.37); over-travel absorbed by a 26 N/mm pip; force at click ≈ 2.9 N centre / ≈ 3.8 N rim | `[V]` Panasonic EVPBB DS; stack step 12 |
| 10 | Hall latches | DRV5032DU X2SON: **two outputs — OUT1 (pin 4) north, OUT2 (pin 3) south**; B_OP 1.2/2.5/3.9 mT, B_RP 0.9/1.8/3.5 mT, hysteresis 0.1/0.7/1.9; sampling period 27/50/75 ms; ICC 1.6 µA typ at 3 V | `[V]` TI DRV5032 DS (pin table, DU table, §7.3.2) |
| 11 | First-motion detection | both outputs on 2 devices at 90°, Bpk ≥ 4.5 mT: worst-case edge gap **≤ 77°** (B_OP min case 75°); OUT1-only: 121° (fails the doc's "within 90°"); plus ≤ 75 ms sampling latency (13.5° at 0.5 rev/s) | computed, step 11 |
| 12 | Journal / tilt | hub ø7.00 h7 in POM bore ø7.06–7.10, two lands spanning 6.9 mm → tilt ≤ 0.10/6.9 rad ≈ **0.8°** (doc's < 0.5° needed 12 mm that the zone does not hold) | computed, step 9 |
| 13 | Zone closure | crown front −6.00 … last far-side component +5.63 → **11.6 mm of 16.0, 4.4 mm spare** (2.9 with an FH12 connector); AG 1.0 rest / 0.6 pressed (MT6701); magnet-to-Hall 1.7 / 1.3 (AS5600L WL-CSP) | computed, step 15 |
| 14 | Concentricity chain (worst-case, systematic) | 0.01 + 0.05 + 0.02 + 0.05 + 0.05 + 0.10 = **0.28 mm** vs MT6701 0.30 ✓, AS5600L 0.25 ✗ → AS5600L variant needs 0.04–0.06 bore clearance and a package-body nest (→ 0.24) | computed, step 10 |
| 15 | Seal | O-ring optional; if fitted: FKM 75–80 ShA (*low-temperature GLT/GFLT class per §3 C-3*), 1.0 section, ID 1–3 % larger than shaft, 3–6 % squeeze, compressed from the gland OD (Parker §8.13); computed drag 0.15–0.35 mN·m running, 0.6–1.4 breakaway `[U]`; acceptance ≤ 0.5 running / ≤ 0.9 breakaway or delete it | `[V]` Parker O-Ring Handbook §6.3.16, §8.13, §8.17, §10.4 |
| 16 | Flex | **10 signals** (3V1_ON, MT_VDD_SW, GND, SDA, SCL, HA1, HA2, HB1, HB2, TACT); soldered flex tail baseline; FH12-10S-0.5SH fallback (2.0 tall; 6S/8S read in fh12.txt, 10S `[U]` confirm) | `[V]` Hirose FH12 (local) |
| 17 | Skin contact | REACH Annex XVII entry 27: Ni release < 0.5 µg/cm²/week, EN 1811 (+ EN 12472 wear/corrosion for coated parts) | `[V?]` secondary sources (Intertek/ComplianceGate); regulation text not opened |
| 18 | Life | 1,000,000 indexes = 41,667 rev ≈ 5.8 h at 2 rev/s; torque decay ≤ 15 % | doc `[U]`; rig time computed |

The AMOLED decision (screen sleeps, halo carries arrivals) changes nothing dimensionally here but makes the crown the only always-available input: the mechanical detents, the DRV5032 wake path (now 8 edges/rev) and the EOL detent-phase calibration carry more of the product. Coaxial vs transverse remains OPEN pending Mule C; coaxial is the baseline throughout, transverse is Design step 20.

### 4.3 DESIGN — step by step (coaxial baseline)

Axial datum: x = 0 at the crown-end shoulder face, +x into the body. Crown front face at x = −6.00. All positions are at REST (crown pushed outward by the wave washer against the retention ring). Full press = +0.40.

#### Design step 1. Architecture (what rotates, what translates, what is static) — redrawn

- **Crown + hub (rotates and translates, ONE turned part):** 316L (Ti Gr5 alternative) cup 13.0 × 8.0 with a 1.30 mm front wall and an integral **ø7.00 h7 hub** running from the front-wall inner face (−4.70) to **+2.80** (0.80 mm proud of the skirt rear end at +2.00). The hub has: two journal lands (−4.70 → −3.40 and −2.30 → +2.20), a ø6.20 relief between them (spring room), a **retention groove ø6.20 × 0.85 wide at −1.85 → −1.00**, and the **magnet pocket ø6.05 +0.02/0 × 2.60 deep opening at the rear face** (floor at +0.20). The magnet sits at +0.25 → +2.75, inside the crown's length. The race is bonded in the skirt bore. Because the part is one piece there is no weld, no socket, and PVD is done on the finished crown before assembly (M-7 precedes M-16). `[U]` architecture; settled on Mule C.
- **Sleeve (static, ONE moulded + machined POM-C part):** nose ø9.00 (−4.05 → −1.60) carrying the two radial ball pockets and two tangential leaf slots; journal ø10.90 (−1.60 → +2.40) on which the crown skirt bore ø11.00 runs; **flange OD 13.20 (+2.40 → +2.90)**, with two retention ears on the wide-face sides (*1.5 mm thick; widened to 6.0 mm per §3 C-2*); bore ø7.06–7.10 with a front land (−4.05 → −3.40) and rear land (−2.30 → +2.20); internal ring groove ø7.50 × 0.45 at −1.45 → −1.00; optional O-ring gland (+0.40 → +1.75) in the rear land; counterbore ø7.60 (+2.20 → +2.90) clearing the hub rear; two PCB locating pins on the flange rear at (± 6.0, 0). The sleeve enters the bulkhead from the rear and is the datum for everything (labyrinth bore, PCB, diaphragm). *[Editor, §3 C-4: add one moulded-in BeCu grounding leaf riding on the hub rear land, brought out through the flange rear to a satellite-PCB pad — the ESD bleed.]*
- **Retention / outward stop:** C17200 BeCu **wire C-ring ø0.40**, free OD ≈ 7.8, compressed flush into the hub groove (OD 7.00) for assembly, springs out into the sleeve groove (ø7.50) when it arrives: engagement 0.15 radial in the hub groove, 0.22 in the sleeve groove. Hub groove rear wall on the ring = rest position; hub groove width 0.85 = 0.40 wire + 0.40 stroke + 0.05. Pull-out path: crown → groove wall → ring → POM groove wall (bearing 100 N / (π·7.28·0.22) ≈ 20 MPa, POM yield ~60 MPa `[U]`) → sleeve → ears → bulkhead. BeCu, not 316 spring wire: cold-drawn 316 wire is partly martensitic `[U]`.
- **Wave washer (C17200 BeCu, stamped and aged; ID 7.2 / OD 9.6 / t 0.12, 3 waves, free height ≈ 0.95 `[U]`):** in the annulus between the crown front-wall inner face (−4.70) and the sleeve nose front face (−4.05): **working height 0.65 at rest, 0.25 at full press (solid 0.12 → 0.13 margin)**; rate ≈ 1.8 N/mm → 0.55 N preload at rest, ≈ 1.0 N at click (0.27), 1.3 N at the stop. One datum set — the draft's contradictory −4.0/−4.2/−4.4 values are gone.
- **Bulkhead:** LSR diaphragm (60 Shore A, platinum-cure), 0.8 mm rim bead in a groove on the flange rear face, 0.30 skin spanning the ø9.4 opening at **+2.85 → +3.15**, i.e. **G = 0.05 mm** behind the hub rear face. On the dry side, at r = 3.3 mm, a **pip: PEEK core ø1.4 × 0.60 insert-moulded, LSR cap 0.15** → pip top at +3.90. No rigid pressure plate, no feet: the draft's rigid PEEK plate is what made the stack un-tolerable.
- **Satellite PCB:** component face at +4.48, located on the sleeve pins; MT6701/AS5600L on the axis, crown-facing; tact at r 3.3 (top at +3.95, L = 0.05 to the pip); two DRV5032DU at r 4.0; flex on the far side.

#### Design step 2. Material selection — the permeability argument (corrected)

Requirement: every part within ~8 mm of the magnet other than the race must have µr ≤ 1.05 **measured after all forming/machining** (low-mu permeability indicator, ASTM A342 method `[U]` — standard not opened; the Severn-gauge-type indicator is industry practice).

| Candidate | Verdict | Why |
|---|---|---|
| 303 | **Reject** (doc, confirmed with a number) | Free-machining, sulphide-bearing, ~170 HV, σ_y ~240 MPa: Hertz shakedown ≈ 0.4 GPa vs 2.1 GPa land contact (step 6) → brinells at the first index as a race; as a crown body it also cold-works. |
| 304 | Reject | Lower Ni → strain-induced martensite on cold work; cold-worked austenitics "will be attracted to a permanent magnet" (ASSDA FAQ, qualitative `[V]`). |
| **316L** | **Baseline crown+hub** | Better than 304 but **NOT covered by ASSDA's "µr below 1.02 after cold work" statement — that sentence is about highly alloyed / high-nitrogen austenitics; ASSDA groups 304 and 316 together as grades that become attracted after cold work** (review finding accepted; draft's `[V]` was a misattribution). Md30 for 316L is around −10 to −30 °C `[U]`, so heavy cold work (rolled knurl, orbital forming) can produce martensite. Therefore: **cut serrations only** (no rolled knurl, no riveting, no welding — the one-piece design needs none), permeability gate M-4 on every lot, and a Ti control on Mule C. Cheap, PVD-able, ground finish Ra 0.2. Crown+hub ≈ 5.1 g. |
| 6061-T6 / 7075-T6 hard-anodised | Alternative (lightest, immune to nickel release) | µr ≈ 1.00. MIL-A-8625 Type III ~50 µm, half penetration / half build-up → ø grows ~0.05; crest R ≥ 0.10 or the coating chips `[V?]` anodiser pages, spec not opened. Race press in aluminium creeps; galvanic couple to the race in sweat; hardcoat serrations feel "sandy". |
| **Ti Gr2 / Gr5** | Premium alternative; **Mule C control unit** | µr ≈ 1.00005, 4.4 g/cm³ (crown ≈ 2.8 g), no nickel-release question, Gr5 ~36 HRC allows a true race interference fit. Machining 2–3× cost; PVD or AMS 2488 Type II anodise. |
| 440C / 17-4PH / 430 anywhere but the race | **Reject** | Ferromagnetic (17-4PH "strongly ferromagnetic in all conditions" — Ulbrich `[V?]`, ATI `[V]`); a static ferromagnetic part near the magnet adds angle-dependent field error. |
| Race: 17-4PH H900 **wrought** | Cost baseline (doc) — *§3 C-1: decided on the Mule C field map against zirconia and BeCu* | Only ferromagnetic part; coaxial and co-rotating with the magnet, so its distortion is a static reshaping of the 2-pole field, not INL; 4–6 mm from the magnet, expected < 5 % flux shunting `[U]` → FEMM in step 16. Passivate ASTM A967 (H900 is the most chloride-sensitive condition). |
| Race alternatives | Built for Mule C | Y-TZP zirconia CIM ring (HV ~1200, immune to sweat, non-magnetic — preferred fallback, and preferred outright if the O-ring is deleted in step 8); C17200 BeCu HT (38–45 HRC `[V?]` Materion via MatWeb) for a non-ferromagnetic metal race. |
| Magnet plating (Ni-Cu-Ni) | Sealed side | Behind the diaphragm cavity and the optional O-ring — not a skin-contact surface. |

**Nickel release (step 2b):** the crown (thumb/finger, minutes a day) and the keyring lug are prolonged-skin-contact articles under REACH Annex XVII entry 27 → Ni release < 0.5 µg/cm²/week per EN 1811, and EN 12472 simulated wear + corrosion before EN 1811 for the PVD'd crown `[V?]` secondary sources. Discriminator: if PVD'd 316L fails after EN 12472 wear at the serration flanks, the answer is Ti or hard-anodised Al, not a thicker PVD. Test in Verification item 13.

**What goes to the RF owner (Mule B) from this step:** crown material and mass (316L 5.1 g vs Ti 2.8 g), that the crown is **floating** (no galvanic path to ground by design; *ESD bleed is 1 MΩ per §3 C-4, RF-floating*), its position (a 13 × 8 mm cup at the counterpoise end, ~1 mm of PC/ABS from the buried IQS211B electrode → estimated 5–10 pF `[U]`), the race, the BeCu ring/washer/leaves, and the magnet. None of these are grounded; the EM model must carry them as floating conductors.

#### Design step 3. Crown body geometry (one part)

- OD 13.00 −0.03 over serration crests; length 8.00 ± 0.03 (front face to skirt rear end); front wall 1.30 with a 0.20 dish (1.10 min) — the dish steers the thumb toward the axis (reduces the rim-push penalty).
- Skirt bore, three diameters in one boring setup (concentric ≤ 0.01 TIR): **ø10.00 H8 (−4.70 → −4.20)** clearance behind the race, **ø10.60 H7 (−4.20 → −1.60)** race seat with the step at −4.20 as the race stop, **ø11.00 H7 (−1.60 → +2.00)** skirt journal, Ra ≤ 0.4; 0.2 × 45° chamfers at every bore mouth (race lead-in, ball lead-in).
- Hub as in step 1; magnet pocket and both hub lands turned in the same setup as the bores → pocket-to-hub concentricity ≤ 0.01.
- Recessed 0.4 mm radially inside the shoulder (shoulder silhouette ≥ 13.8); the last 2.0 mm of skirt (x 0 → +2.0) run inside the reamed ø13.30 +0.05/−0 bulkhead bore → labyrinth 0.15 nominal, ≥ 0.05 worst-case (step 8).
- Knurl: **straight (axial) serration, 48 teeth, 90° included, 0.85 pitch, crest flat 0.10, root R 0.10, 5.5 long, 0.25 run-out chamfers. Cut, never rolled** (step 2).

#### Design step 4. Race ring (wrought + hard finishing; tolerances relaxed to process capability)

- 17-4PH wrought bar, Swiss-turned in Condition A: OD 10.61 +0.01/−0 (0–0.02 interference in the 316L bore + anaerobic retainer; a 0.03 press would put ~470 MPa hoop in the 1.0 mm annealed wall, above yield), ID 9.20 ± 0.02, L 2.60, keyed notch. Age H900, then **wire-EDM the 24 grooves after ageing** (profile ± 0.005 achievable `[U]`), remove recast by tumble-lap/electropolish, passivate.
- Grooves: full-radius **R 0.45 ± 0.03, depth 0.12 ± 0.02**, edges blended R 0.10, **angular pitch 15° ± 15′, cumulative ± 20′** (the draft's ± 5′ / ± 0.01 were grinding-class numbers with no process basis — review accepted). What matters is torque-ripple uniformity ≤ 15 % (Mule C); the sensor, not the race, defines angle.
- Geometry check: chord of an R0.45 groove at 0.12 deep = 0.89 mm; land at ID = 1.204 − 0.89 = 0.31 mm → the ø0.8 ball always rests on two flanks or the land, never falls through.
- MIM (net-shape) is **not** baseline: MPIF-35 MIM H900 typical 33 HRC / YS 1090 MPa `[V?]` is below the shakedown line in step 6 — it ratchets. It may return only if a MIM lot measures ≥ 40 HRC and the 1M rig passes.
- *Zirconia and BeCu variants (§3 C-1): same OD/ID/L and groove geometry; zirconia by CIM/sintering + grinding (tool ~$10k `[U]`), BeCu turned + grooved in the solution-annealed state then aged 2 h @ 315 °C `[V?]`.*

#### Design step 5. Ball / spring carrier (in the static sleeve nose) — spring geometry re-derived

- Two radial pockets ø0.85 +0.02/0 at 180° in the ø9.0 nose at x = −2.90; balls ø0.800 Si₃N₄ ISO 3290 G5 (G10 acceptable) `[V?]` vendor pages.
- Space check that killed the draft's leaf: with the hub at ø7.0 under the ball plane there is only ~0.15 mm of radial room for spring deflection. Hence the **hub relief ø6.20 (−3.40 → −2.30)** giving 0.55 mm of room under the balls, without touching the journal lands.
- **C17200 BeCu cantilever leaf, 0.12 × 1.5 mm, effective length 4.5 mm**, lying tangentially in a slot milled into the nose from the outside (root clamped by a moulded boss; retained radially by the race ID — it cannot escape). Rate k = E·b·t³/(4L³) = 131e9 × 1.5e-3 × (0.12e-3)³ / (4 × (4.5e-3)³) ≈ **0.93 N/mm**; preload deflection 0.43 mm for 0.40 N; land climb 0.10 → +0.09 N → land force 0.49 N (ripple ratio 1.2 — a soft, even click). Bending stress at 0.49 N: 6·F·L/(b·t²) ≈ 0.61 GPa vs Materion Alloy 25 HT yield 1130–1420 MPa, fatigue 310–340 MPa reverse-bending at 10⁸ `[V?]` (MatWeb mirror of the Materion sheet); fatigue amplitude here ± 0.05 N ≈ ± 60 MPa → infinite life. Age 2 h @ 315 °C after forming `[V?]`.
- Ball protrudes ≤ 0.20 beyond ø9.0 with the crown off (leaf free-height stop) → cannot escape; even groove count + balls at 180° → both seat together, zero net radial load on the journal.

#### Design step 6. Detent torque math (R_b corrected)

Ball climbing a flank at angle α with µ: F_t/F_n = (sin α + µ cos α)/(cos α − µ sin α). At µ 0.10: α 20° → 0.47; **30° → 0.72; 35° → 0.84**; 45° → 1.22.
Baseline R0.45 groove 0.12 deep with R0.10 edges → α_eff 30–35°. **T_peak = 2 × R_b × F_n × ratio = 2 × 4.25e-3 × 0.40 × (0.72–0.84) = 2.4–2.9 mN·m**; over F_n 0.32–0.48 and µ 0.05–0.15: 1.9–3.9 mN·m. If Mule C wants a sharper click, steepen α (edge blend) rather than raising F_n.

Hertz: E* = 1/((1−0.27²)/310 + (1−0.3²)/200) GPa ≈ 133 GPa; on the **land** (sphere R0.4 on the concave R4.6 cylinder, R_e ≈ 0.42) at 0.49 N: p₀ = (6FE*²/(π³R_e²))^⅓ ≈ **2.1 GPa**; in the conforming groove ≈ 1.0–1.3 GPa. Shakedown ≈ 1.6·σ_y: wrought H900 (≥ 1170 MPa `[V?]`) → 1.9 GPa → mild shakedown/polishing of land edges in the first ~1k indexes, then stable — to be proven on the rig; MIM (1090) → 1.75 GPa → ratcheting → rejected as baseline; 303 (240) → 0.4 GPa → the doc's rejection with a number. *BeCu TH04 (1130–1420 `[V?]`) → 1.8–2.3 GPa, comparable to or above wrought 17-4; zirconia is far above.* Fallbacks: zirconia race; ø0.9 balls (p₀ ∝ R^−⅔).

#### Design step 7. Coast and damping — correction to doc §7.1

Mass build-up: skirt 2.0 g at r 6.0 → 72 g·mm²; front wall 1.4 g → 30; hub 1.7 g → 10; race 0.44 g at r 5 → 11; magnet 0.53 g → 2 → **I ≈ 1.25 × 10⁻⁷ kg·m²** (thin-walled cup, not ½mr²). Barrier energy ≈ T_peak × (π/24) × 0.64 ≈ 2.75e-3 × 0.131 × 0.64 ≈ 0.23 mJ. KE at 5 rev/s = ½·I·ω² ≈ 0.062 mJ. Threshold ω = √(2·0.23e-3/1.25e-7) ≈ 61 rad/s ≈ **9.7 rev/s** — a thumb flick is 3–5 rev/s `[U]`. **The crown cannot coast; delete "coasts about a third of a turn" from §7.1.** "Glide and weight" come from Coulomb + viscous drag in the hub journal, ring and (optional) O-ring: budget **≤ 0.5 mN·m running**, measured on Mule C (step 8). Pocket rattle: holding torque dwarfs any inertial torque on 10⁻⁷ kg·m².

#### Design step 8. Journal / seal stack (outside → inside), with the wall check

1. **Labyrinth:** crown OD 13.00 −0.03 in the **reamed** bulkhead bore ø13.30 +0.05/−0 (post-mould sizing, same reamer pass as the sleeve-flange seat → concentric ≤ 0.02): 0.15 radial nominal; worst case 0.15 − 0.02 (bore/flange) − 0.05 (hub clearance) − 0.03 (crown OD) − 0.02 (race/skirt) ≈ **0.03 ≥ 0** — never touches.
2. **Debris chamber — §6.4 amended:** the doc's 0.6 × 1.5 annulus in a ø13.30 bore leaves 0.25 mm of wall on the 15 mm faces (review, accepted). Chamber is now **two arc pockets of 0.6 radial × 1.5 axial over ± 50° centred on the 27 mm faces**; on the 15 mm faces the groove is 0.15 deep → bulkhead wall ≥ 0.70 mm there. *The IQS211B electrode is buried in the bulkhead wall (§3 C-4), routed clear of the pockets.*
3. **Skirt journal:** crown ø11.00 H7 on sleeve ø10.90 ± 0.02 (0.06–0.10 diametral), 3.6 mm long — a 0.03–0.05 gap that is itself a lint barrier for the race.
4. **Race + balls**, greased 2–4 mg PFPE (Krytox GPL 205-class `[U]`; PFPE is inert and FKM-compatible; silicone grease is incompatible with silicone rubber — Parker §6.3.16 `[V]`).
5. **Hub journal:** ø7.00 h7 (Ra 0.2) in POM-C ø7.06–7.10, two lands spanning 6.9 mm (tilt ≤ 0.8°). POM CTE ~110 µm/m·K: bore grows 0.03 over +40 K, shrinks 0.03 at −10 °C (still ≥ 0.03 clearance).
6. **Retention ring** (step 1) — rotates with the hub, slides in the POM groove; negligible drag.
7. **Rotary O-ring (OPTIONAL — a Mule C variable, not a settled part):** the draft's 12–15 % squeeze in a static housing groove with a silicone ring was reciprocating-seal practice on the wrong compound (review accepted). If fitted: gland in the sleeve rear land at +0.40 → +1.75 (1.35 wide), **FKM 75–80 Shore A (low-temperature GLT/GFLT class, §3 C-3), 1.0 section, ID 1–3 % larger than ø7.0 (≈ 7.1–7.2), compressed from the gland OD, 3–6 % squeeze** — Parker §8.13 Gough-Joule rule `[V]`; PFPE-greased; shaft lead-in 15°. Drag estimate `[U]`: load ≈ 0.03–0.06 N/mm × 22 mm circumference = 0.6–1.3 N normal; µ 0.06–0.08 mixed (Parker §8.17 `[V]`) → 0.04–0.10 N × 3.5 mm = **0.15–0.35 mN·m running; breakaway at µ ≈ 0.3 → 0.6–1.4 mN·m** — the same order as a detent, which is why it must be measured. Combined rotary + 0.4 mm reciprocation is Parker's §10.4 spiral-failure case `[V]` — mitigated by low squeeze, hard compound, grease, stroke ≪ section; inspected after the life test (Verification 3). **Acceptance: seal drag ≤ 0.5 mN·m running, ≤ 0.9 mN·m breakaway after 24 h at 40 °C (and at −20 °C); otherwise delete the O-ring** and make the mechanism wet-tolerant (Si₃N₄, zirconia race, POM, 316L/Ti) — the diaphragm alone protects the electronics.
8. **Sealed interior:** the hub-rear cavity and diaphragm; rim clamped between the flange and the PCB carrier (static seal). Water reaching the electronics must pass the (optional) O-ring **and** the diaphragm. *The flange/ear front face carries J5, the static face seal to the bulkhead inside face (§3 C-2).*

#### Design step 9. Tilt and guidance

Tilt bound = diametral clearance / span between outer land ends = 0.10 / 6.9 ≈ 0.8° (the coaxial skirt journal at r 5.5 with the same clearance tightens this slightly). Magnet tilt 0.8° is harmless to an on-axis 2-pole sensor `[U]` (Mule C INL confirms). The doc's "< 0.5° on a 12 mm journal" cannot exist inside the 10 mm of body the zone contains; 0.8° is the achievable number.

#### Design step 10. Magnet retention and one concentricity chain (worst-case for systematic terms)

- Magnet ø6.0 0/−0.05 × 2.5 diametric NdFeB N35–N42 (N35SH grade if any later process exceeds 80 °C `[U]`), catalogue part; pocket ø6.05 +0.02/0 × 2.60; retained by 3–5 mg Loctite 648-class retainer (0.05 film on the floor) plus a **3 × 120° stake of the pocket lip** (0.1 mm, non-magnetic tool, after bonding); face 0.05 below the hub rear face. Magnetisation axis laser-marked on the hub rear face for the EOL calibration. Bonded **last**, after PVD and mechanical assembly, so no process heat ever reaches it.
- **Chain (all systematic → arithmetic):** pocket-to-hub OD (one setup) 0.01 + hub in sleeve bore (full radial clearance under a rim side-load) 0.05 + sleeve bore to flange/PCB-nest (one secondary op) 0.02 + PCB on pins 0.05 + package placement 0.05 + die-to-package 0.10 `[U]` = **0.28 mm** vs MT6701 DISP 0.30 `[V]` (0.02 margin). AS5600L max 0.25 `[V]` → for that variant: bore clearance 0.04–0.06 (0.03 radial) and a moulded nest on the package body (0.03) → 0.24 ✓; the WL-CSP footprint must be offset **172.5 µm** so the Hall array, not the chip, is on axis `[V]`. Measure die-to-package on 10 samples (open question) — if it is 0.05, both variants gain 0.05.

#### Design step 11. Field levels and the latch geometry (DRV5032DU two-output)

- MT6701 wants 200–1000 G at the IC surface at AG 0.5–2.0 `[V]`; AG here is **1.0 rest / 0.6 pressed** (step 15) — mid-window `[U]` until FEMM + gaussmeter on Mule C with the race fitted. AS5600L WL-CSP: magnet-to-Hall 1.7 / 1.3 mm, needs 30–90 mT on the 1 mm circle `[V]` → expected 35–55 mT for N42 `[U]` — the weaker margin of the two; N42 minimum for that variant.
- **DRV5032DU is a two-output part:** OUT1 (X2SON pin 4) asserts on north flux above |B_OP|, OUT2 (pin 3) on south `[V]` TI DS pin table + §7.3. Under an off-axis diametric magnet Bz at each latch swings ± once per revolution, so **each device gives 4 edges/rev when both outputs are read**. Design: two devices at r = 4.0 mm, 90° apart, **both outputs on each → 4 GPIO lines (nRF9151 has 32 GPIO `[V]` PS), 8 edges/rev.** Worst-case first-motion gap computed with Bz = Bpk·cos θ: Bpk 8 mT / B_OP 2.5 typ → gaps 31° and 59° (max 59°); B_OP 3.9 max → max 55°; **B_OP 1.2 min → max 75°**; Bpk down to 4.5 mT → max 77°. **OUT1-only (the draft) gives 121° at typ — the doc's "within 90°" is not met that way.** Three lines (one device both outputs, one OUT1) gives exactly 90° — rejected as marginal. Add the DU sampling period 27–75 ms `[V]`: 13.5° at 0.5 rev/s petting, so first-motion ≤ 90° holds at petting speed; at a 5 rev/s flick the 75 ms sample gap (135°) dominates and the MT6701 (powered ≤ 1 ms after the first edge `[V]`) takes over.
- Target Bpk at the latches ≥ 8 mT (2 × B_OP max) so the 0.40 mm press (≈ +20 % field) cannot flip a state; firmware masks latch edges while TACT is low.
- MT6701's push-button detector needs a ≥ 31 % field step `[V]` (PUSH_THRD); a 0.40 mm approach gives ~20 % → **cannot replace the tact**; plausibility check only.

#### Design step 12. Bulkhead and press mechanism — toleranced

Why the draft failed: EVPBB height is **H ± 0.1** with ± 0.05 general tolerance `[V]`, larger than any sub-window of a 0.25 mm stroke. Fixes adopted: (i) **stroke S = 0.40 ± 0.03** (hard stop = crown skirt rear end on the POM flange front face, both machined; 0.25 was an ID number the tact cannot honour — needs ID sign-off, open question); (ii) **selective assembly**: tact-top height measured on every satellite PCBA relative to its component face (PCB thickness therefore out of the chain), diaphragm chosen from **3 pip-height bins (0.10 steps)** → residual ± 0.033 + 0.02; (iii) **compliant pip** for over-travel: PEEK core 0.60 + LSR cap 0.15 + 0.30 skin at ø1.4 → rubber column 0.45, shape factor 0.78, E_eff ≈ 7.7 MPa (60 ShA) → **k ≈ 26 N/mm** `[U]`: 0.06 mm pre-compression at 1.6 N, and over-travel of 0.25 costs +6.5 N (dome sees ≤ 8 N worst-case — Panasonic allowable static load is not on the datasheet, open question; if < 10 N, k → 18 N/mm and S → 0.45).

**Stroke stack (from rest, named tolerances):**

| Term | Nominal | Tol | Basis |
|---|---|---|---|
| Hub rest position (groove wall / ring / POM groove wall) | ref | ± 0.06 | turned ± 0.02, wire ± 0.01, machined POM ± 0.03 |
| G: hub rear face → skin | 0.05 | ± 0.05 | LSR mould ± 0.05 (on the machined flange datum) |
| Pip pre-compression at 1.6 N | 0.06 | ± 0.02 | pip stiffness ± 30 % |
| L: pip → tact top (after 3-bin selection) | 0.05 | ± 0.05 | H ± 0.1 binned to ± 0.033, pip height ± 0.02 |
| Tact travel | 0.11 | ± 0.02 `[U]` | Panasonic gives none |
| **Click travel** | **0.27** | **± 0.20 arith / ± 0.09 RSS** | RSS window 0.18–0.36 |
| Hard stop S | 0.40 | ± 0.03 | |
| Over-travel at the dome | 0.13 | 0.01–0.25 (RSS) | arithmetic worst-case −0.10 (no click) |

Arithmetic worst-case does **not** close even at 0.40 — stated plainly. The design relies on RSS plus a **100 % EOL press test (force–stroke curve, click 0.15–0.37, stop 0.37–0.43)**; the fallback is S = 0.45 with 5 pip bins. A 1.0 N tact (EVPBB1AAB000, **0.08 mm travel** `[V]`) moves the click to 0.24 and the force to ≈ 2.3 N; re-run the table for whichever Mule C picks.

- **Force at click** ≈ washer 1.0 N + tact 1.6 N + skin/rim 0.2 N + journal friction 0.1 N ≈ **2.9 N at the centre**; rim push at r 6.5 adds 2µr/L = 2 × 0.15 × 6.5/6.9 ≈ **+28 %** → ≈ 3.7 N; the pip's fixed off-axis reaction (1.6 N × 3.3 mm) adds ≈ +4 % everywhere. Cannot jam (jam needs r/L > 1/(2µ) ≈ 3.3). Acceptance ≤ +50 %, click at every thumb position.
- **Why one off-axis tact cannot cock:** the crown+hub is guided by 6.9 mm of journal at ø7 plus the coaxial skirt journal; the tact is loaded through the pip at r 3.3 by the rigid hub rear annulus (r 3.0–3.5); the moment from any thumb position is reacted by the journal, not by the dome.
- **Drop:** a 6 g crown at 2000 g (≈ 120 N) is reacted by the hard stop (skirt on flange, ≈ 6 MPa on POM) — the dome sees only the pip force at S (≤ 8 N).
- **Debounce:** press counted only if TACT low ≥ 30 ms (drop actuation < 5 ms).
- **ESD (path restated per §3 C-4):** with the IQS211B electrode buried ~1 mm inside the bulkhead wall, the crown's discharge cannot arc to the electrode's TVS; the designed path is now the **BeCu grounding leaf in the sleeve → satellite PCB → 1 MΩ ∥ low-C TVS → GND**. The dielectric barriers behind it (0.30 LSR ≈ 6 kV at ~20 kV/mm `[U]`; 0.6 PEEK pip ≈ 12 kV `[U]`; ≥ 0.55 air + mould compound to the MT6701) are the second line only. Verification item 9 tests 8 kV contact / 15 kV air with a current probe on the bleed line; the acceptance is justified by the bleed route, not by the dielectric numbers.
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

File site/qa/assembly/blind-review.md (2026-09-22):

# Independent assembly-chapter review

Reviewed 2026-09-20 against the live development build at http://127.0.0.1:5173. Scope: `inside`, `crown`, `detents`, `antenna`, and `assembly` only. `DESIGN_NOTES.md` and implementation notes were not read. No application files were changed.

Authority: `../DESIGN_MANUFACTURING_REPORT_2026-09-19.md`, particularly sections 4, 5, and 7. Its engineering baseline takes precedence over older brief inconsistencies. The current aesthetic direction is accepted.

## Findings requiring correction

### R1 — P2: Mobile build controls become concealed and untappable during the build

- Reproduction: fresh browser at 390 × 844; navigate to `#assembly`, then scroll 500 px into that section. Continue to 900 px.
- `#build-progress` remains at viewport y=294–310. Play/Pause and Reset occupy the same reserved product area. The sticky copy has reached y=0 while the scene remains fixed above it. These controls are visually hidden and the canvas receives input at the range's center. Keyboard focus can still reach the hidden range, so the problem also affects visible focus.
- At both sampled scroll positions the step text and part selection remain visible, but the build controls do not. The control remains concealed throughout the sticky portion unless the user scrolls back toward the section's beginning.
- Implementation: `src/assembly.css:4`, mobile `#assembly .section-inner { position:sticky; top:-48svh; ... }`, together with the reserved fixed product area.
- Recommendation: keep a compact controller visible below the product area while the heading scrolls away, or reposition the controller independently of the sticky title. Verify pointer hit testing and keyboard focus after the layout change.
- Evidence: `qa/assembly/reviewer-390-assembly-scroll500.png`, `reviewer-390-assembly-scroll900.png`. Browser `elementFromPoint` at the range center returned the Three.js canvas; `document.activeElement.id` was still `build-progress` after focus.

### R2 — P2: The assembled feed spring penetrates the aluminium tab

- The depicted spring is described as compressing against the underside of the integral tab, but its fitted geometry rises through that tab.
- Implementation: `src/components/assembly-model.js:117`–`120`. Local physical coordinates, before exploded offsets: tab z=2.4–3.9; plated land z≈2.35–2.4; contact tube extends up to z≈3.167. Its arch overlaps the tab rather than remaining below the contact plane. This is not caused by exploded spacing.
- The board top is z=1.8 (`assembly-model.js:55`), making the illustrated land gap approximately 0.55 mm. The source baseline is 1.4 mm above the PCB top.
- Source: engineering report §5, Design step 6, lines 899–904; §7, final assembly station 20, line 1842. The chosen geometry is vertical compression against an underside land, with the finger compressed as the PCB seats.
- Recommendation: adjust the tab/land height and compressed spring profile together so the spring meets the underside without entering the tab. A dimensional simplification caption can explain a schematic view, but the contact relationship itself should remain physically possible.
- Evidence: runtime geometry bounding boxes confirmed the coordinates above; the ordinary exploded view separates the parts and conceals this interference.

### R3 — P2: Opening assembly pose clips the antenna cap at the right edge

- Reproduction: navigate to the start of `#assembly` at 1920 × 1000 or 1440 × 1000, with the view reset and assembly progress at 0%.
- The far end of the antenna cap extends past the viewport edge. This affects the principal composition before any user orbit gesture.
- Implementation: `src/timeline.js:17`, assembly pose `scale:.74, cx:.70`, combined with the cap's exploded +29 mm offset in `src/components/assembly-model.js:147`.
- Recommendation: reduce the opening build scale or shift its center left enough to retain an edge margin across desktop sizes. Preserve clearance from the left copy column.
- Evidence: `qa/assembly/reviewer-1920-assembly.png`; `reviewer-1440-assembly.png`.

## Polish

### R4 — P3: Tablet antenna caption approaches/overlaps the bottom orbit toolbar

- At 820 × 1000, the long antenna heading increases the copy height. Its final validation caption extends into the toolbar's vertical band near y=930–953.
- Implementation: `src/assembly.css:2`–`3`; antenna copy/heading sizing and fixed orbit toolbar positioning.
- Recommendation: shorten the tablet line wrapping or reserve a little more bottom space for the caption.
- Evidence: `qa/assembly/reviewer-820-antenna.png`.

## Passing checks and evidence

- Fresh Chrome context with service workers blocked; WebGL and assembly module initialized successfully. No page errors during the targeted checks.
- All five new chapters inspected at 390, 820, 1440, and 1920 px widths. No document-level horizontal overflow. Original overview images and full 390/1440 screenshots also inspected.
- All 31 part-selector buttons changed the intended panel, pressed state, and scene selection.
- Detent forward/back controls produced +15°/−15° and restored the readout correctly. There are exactly two opposed balls, and both follow the same radial cycle. The animation is appropriately labeled as slowed and cut away.
- Keyboard End on the assembly range reached 100% and the final station; all fitted part offsets reached zero. Reset returned to 0%; Play advanced; Pause held its value.
- Trace the contact started the highlight sequence. No claim of measured antenna efficiency or validated radiated performance is made.
- The copy preserves the one-piece crown/hub, 24-groove race, static sleeve, two ceramic balls/leaves, washer and C-ring, late magnet bonding, diaphragm/pip, and separate angle/press sensing. Reference materials and open choices are identified.
- The displayed high-level assembly order matches the current report: prepared cap/ring/tray, cartridge from inside, board/finger seating, display connection and bonding, cell, door/collar and tests after adhesive dwell. The model routes the crown cartridge from the open rear toward the nose rather than inserting it from outside.
- No factual blocker found in the manufacturing copy. R2 is a displayed mechanical-relationship error, rather than a claim that an untested design is production-proven.

## Limits

This was a bounded review of the five additions, not a new audit of the first ten chapters. It used desktop Chrome and mobile viewport/touch emulation, not a physical phone. Full CAD interference, mechanical tolerances, antenna tuning, and actual production feasibility cannot be validated from this explanatory model. No-JavaScript/fallback assets were being updated concurrently and were not treated as finalized. Transitional poses were reviewed through ordinary navigation; this was not an exhaustive frame-by-frame animation or performance audit.

## Correction verification — 2026-09-20

**R1, R2, R3, and R4 are resolved in the rechecked development build. No remaining blocker was found in this targeted recheck.** The original findings above record the earlier build; this verification supersedes their open status.

- **R1 — passed:** Fresh Chrome mobile/touch context at 390 × 844, service workers blocked. At +500 px into `#assembly` (31%), the midpoint (50%), and the end (100%), the console remained at viewport y=405.125 (48% of the height). The range was at y=450–466 and Play/Pause/Reset at y=481–509. Hit testing returned the actual input/buttons at all three positions, rather than the canvas. At every position, touchscreen tap changed the range to 76%, a CDP touch drag changed it to 26% and retained that value, Play advanced or replayed, Pause held steady, and Reset returned to 0%. The compact console and station text are readable below the product. The redundant final part gallery is hidden only in the enhanced mobile assembly view.
- **R2 — passed:** Runtime geometry confirms the fitted finger's top at z≈3.2, plated underside at z≈3.2, PCB top at z≈1.8, and aluminium tab bottom at z=3.25. The contact therefore has the report's 1.4 mm working gap and does not penetrate the tab. Sampled progress at 35%, 45%, 46%, 47%, 80%, and 100% confirms the board approaches from behind; during the final compression, the tip remains at the underside plane as the board finishes seating. The loose strip has the additional 0.6 mm height. The adjusted web aperture clears the tab's y/z envelope. Sampled board/cell positions agree with the added lateral staging before rear insertion. These checks verify the depicted relationship, not a complete CAD interference analysis.
- **R3 — passed:** Opening assembly screenshots at 1440 × 1000 and 1920 × 1000 show the entire cap inside the viewport with the reduced 0.68 desktop scale. No new copy overlap appeared in those opening poses.
- **R4 — passed:** At 820 × 1000 the shortened caption layout clears the bottom orbit toolbar.
- The spring-leaf initialization now explicitly handles the initial non-finite sentinel; all sampled leaf vertex positions were finite. No page errors occurred in the recheck.

Evidence: `qa/assembly/reviewer-recheck-results.json`; `reviewer-recheck-390-500.png`, `reviewer-recheck-390-mid.png`, `reviewer-recheck-390-end.png`, `reviewer-recheck-1440-assembly.png`, `reviewer-recheck-1920-assembly.png`, and `reviewer-recheck-820-antenna.png`.

The recheck was limited to the reported corrections and their immediate interactions. Physical-phone/browser-chrome behavior and the broader limits above remain untested. No application files were edited.

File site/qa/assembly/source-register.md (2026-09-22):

# Assembly source register

Primary authority: `../DESIGN_MANUFACTURING_REPORT_2026-09-19.md`. The September 19 report supersedes conflicting older brief and CAD details. These are reference-build proposals, not measured production specifications.

The website displays a coaxial crown study. Crown architecture, race material, optional rotary seal, sensing IC, contact supplier/stack and radiated RF results remain open. PCB package artwork, spring curvature, exploded spacing and handling paths are illustrative.

| Component | Material / dimension shown | Manufacturing and fitting authority |
| --- | --- | --- |
| Front tray | PC/ABS · injection moulded | §7 steps 1–3; §7 phase 3C |
| Glass + AMOLED | 0.50 mm glass · laminated display | §7 step 4; stations 30–40 |
| Main circuit board | Six-layer FR4 · 23 × 52 × 0.8 mm | §6; §7 station 20 |
| Pouch cell | Connectorised · 6.0 mm baseline | §3 C-7; §7 steps 6–7; station 50 |
| Haptic actuator | 170 Hz LRA · metal bracket | §7 steps 5, 9 |
| Rear door | PC/ABS · silicone bead gasket | §7 steps 1, 8; stations 60–80 |
| Crown + integral hub | Ø13 mm · 48 cut serrations | §4 design steps 1–3; M1–M7 |
| 24-groove race | Hardened 17-4PH · reference build | §3 C-1; §4 step 4; M8–M11 |
| Two ceramic balls | Si₃N₄ · Ø0.800 mm | §4 step 5; M12, M17 |
| Detent leaf springs | C17200 BeCu · 0.12 mm strip | §4 step 5; M13, M17 |
| Static journal sleeve | POM-C · moulded, then sized | §4 steps 1, 8–9; M14, M18 |
| Wave washer | BeCu · three-wave return spring | §4 step 1; M13c, M18 |
| Captive C-ring | BeCu · Ø0.40 mm wire | §4 step 1; M13b, M18 |
| Sensing magnet | NdFeB · Ø6 × 2.5 mm | §4 steps 10–11; M16 |
| Sealed press diaphragm | LSR · 0.30 mm skin · PEEK pip | §4 step 12; M15, M20 |
| Crown satellite board | Angle sensor · Hall latches · tact | §3 C-24; §4 step 13; M20 |
| Antenna end cap | 6061-T6 aluminium · CNC machined | §5 steps 6–8; M1–M5, M9 |
| Optical isolation ring | Optical PC · 1.5 mm visible web | §3 C-5; §5 M6–M9 |
| Plated feed land | Nickel barrier · hard-gold contact | §3 C-6; §5 step 7, M4 |
| Spring feed contact | Plated BeCu · SMT spring finger | §5 step 6; §7 station 20 |

## Build stations

Reference: report §7, final assembly stations 10–90.
1. **Prepare the tray.** The cap and optical ring are joined to the moulded tray. The feed-tab aperture is sealed.
2. **Fit the crown cartridge.** The tested crown module enters crown-first from inside the tray. Its ears seat and its flex tail is routed.
3. **Seat the circuit board.** The board locates on its pins. Seating it compresses the spring finger beneath the cap’s plated land.
4. **Connect the display.** Mate the display tail, then press the laminated lens module onto the adhesive ledge.
5. **Connect the cell.** Place the insulating layer and stretch-release adhesive, locate the pouch cell and connect its tail.
6. **Close, then test.** Connect the dock flex, close the gasketed rear door, secure its screws and fit the collar. Leak and functional tests follow the adhesive dwell.

## Modeled relationships

- Crown Ø13 × 8 mm, 48 cut serrations; 24-groove race gives 15° increments (§4).
- Exactly two Ø0.800 mm silicon-nitride balls, 180° apart, seat together; each has a separate BeCu leaf (§4 step 5).
- The crown/race rotates; the POM sleeve remains fixed. The wave washer and C-ring serve different return/retention roles (§4).
- LSR diaphragm separates the mechanics from the sensing board; its off-axis PEEK pip operates a separate tact (§4 step 12–13).
- Optical PC web is 1.5 mm visible, with a sealed 5.6 × 2.1 mm feed aperture; the cap is 6061-T6 with an integral tab (§5).
- A gold land on the underside of that tab meets a vertical-deflection spring. Displayed PCB-top/land gap is 1.4 mm; the spring relaxes 0.6 mm in the loose state (§5 step 6).
- The reference contact is explanatory formed 0.09 mm strip, not a selected vendor part. The final supplier and stack remain unqualified (§5 step 6).
- Antenna performance and tuning await chamber work; the animated highlight represents electrical connectivity, not an RF simulation (§5).

Local reports were read only. The site does not alter the engineering report, CAD or firmware.

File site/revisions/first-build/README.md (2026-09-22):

# bingbong — You turn it. They feel it.

A static, scroll-driven product story built from the September 19 brief. The engineering documents in the parent directory remain untouched.

## Run

From this directory, **`npm run dev`** starts the site at <http://localhost:5173>. Dependencies are installed in this workspace. On a fresh checkout use `npm ci` first (Node 22.12+ or 24).

`npm run build` produces `dist/`. `npm run preview` serves that production build at <http://localhost:4173>. Deploy the contents of `dist/` to any static host at the domain root. No server, database, account, analytics, cookie or third-party runtime request is used. The local service worker caches the static app for offline use after its first complete load; no gesture or presence data is stored.

`npm run artifact` produces `artifact/bingbong.html`, a self-contained HTML version with the scripts, fonts, render stills and mascot assets inlined. It can be opened directly in a browser or used as the artifact source; it needs no CDN. Its build prints the byte size. This is a prepared file, not a claim that it has been published to Claude.

## Structure

- `src/sections/`: one content module per chapter; `scripts/build-page.mjs` emits real HTML so every section remains readable without JavaScript.
- `src/tokens.css`: colour, type, spacing and motion tokens. Both system themes are supported; the halo chapter stays dark.
- `src/timeline.js`: the native-scroll timeline, canonical poses and reduced-motion states.
- `src/components/product-model.js`: source model built in millimetres, with documented dimensions and state props.
- `src/components/scene.js`: one persistent Three.js scene. The first frame is a pre-rendered asset; live 3D starts on scroll, pointer or keyboard intent.
- `src/components/mascot.js`: reusable vector/canvas artwork and state props.
- `src/interactions.js`: keyboard, pointer and touch gesture demos. The 250 ms pet and 2.6 s / 90 s boop demos are explicitly simulations.
- `public/mascot/`: eight stills, grouped source SVG, native and landscape preview sheets, loops and the character note.
- `public/renders/`: canonical stills generated from the same model; no stock or AI-generated product pictures.
- `qa/`: screenshots, automated checks, Lighthouse reports, recordings and source/research evidence.
- `DESIGN_NOTES.md`: rationale, source traceability, review findings and the acceptance record.

## Regenerate and check

With `npm run dev` running, `npm run assets` regenerates render stills and their crown hit-target coordinates. `node scripts/prototype.mjs` regenerates the mascot stills and preview sheets. `node scripts/pass.mjs <pass-name>` captures 390, 820 and 1440 px hero views. The QA scripts use installed Google Chrome through Playwright; select another Playwright channel if your machine differs.

With the production preview running, `npm run qa` captures all ten sections at 390, 820, 1440 and 1920 px in both colour schemes and motion modes; it also runs meaningful gesture, timing, no-JavaScript and accessibility checks. `node scripts/lighthouse.mjs` runs Lighthouse mobile. `node scripts/delivery-check.mjs` verifies offline and single-file behavior. See the notes for the exact measured environment and outstanding human checks.

Font subsets were downloaded from Google Fonts: Bricolage Grotesque, Albert Sans and DM Mono, all under the SIL Open Font License. Original URLs are in `qa/font-source.css`; licences are beside the fonts. `scripts/subset-fonts.py` reproduces the smaller subsets from `qa/font-originals/` using fontTools and Brotli. Bricolage's unused optical-size and width axes are fixed at their defaults; weight variation is retained. Runtime dependencies are pinned exactly, and `package-lock.json` records the full tree.

## Source authority

The user confirmed the brief's wording and palette are the approved reference. `SITE_BRIEF.md` is the supplied brief. The local engineering report overrides the older decision document for physical facts. Copy is short, with explicit qualifications for estimates and open decisions. No price, connectivity term, certification, extra colour option or measured battery claim was invented.

The render is an exterior design visualisation from the given geometry, not production CAD. Final supplier drawings, finishes, crown choice and RF results remain unconfirmed. Real-device testing and owner acceptance cannot be replaced by browser emulation; the notes distinguish these from checks that actually ran.

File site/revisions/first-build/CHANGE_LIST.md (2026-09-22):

# Copy and design changes

The user confirmed: **use the wording in the brief**. This comparison is against the approved copy and identity quoted there, not an invented full diff of the inaccessible Claude artifact.

| Item | Final treatment | Reason / authority |
| --- | --- | --- |
| “You turn it. They feel it.” | Unchanged, first viewport | Approved promise |
| Long opening description | “A small cellular keychain, made for two…” plus the separate “No phone. No app. Nothing to set up.” line | Same claims in two readable sentences; coverage qualifier retained |
| Pet / boop / hold | Names unchanged; each has its own chapter and optional interaction | Required gesture vocabulary |
| New chapter headlines | A little turn. A little closer. / A boop says enough. / Just hold on. / Your person. Pocket-sized. / A little light. Left for you. / Every part has a part. / Close. Without keeping score. / Room in your pocket. / One for you. One for them. | New connective copy in the brief's short, concrete voice |
| Crown coast | Explicitly stops at the next detent; no momentum animation | Brief §12.3 and engineering correction override old decision copy |
| Immediate screen wake | Specs say about 0.1–0.2 s, estimated | Brief §12.7 |
| Battery | Only “About three weeks”, labelled estimated | Brief §12.7/.8; no larger-cell claim |
| Always-on creature | Sleeps between glances; halo carries an arrival | September 19 AMOLED decision |
| Latency | Pet: 250 ms demo. Boop: 2.6 s demo, optional 90 s cold demo; all target claims qualified | Avoid applying the petting latency to a boop |
| Halo persistence | Explicit “stays until you touch it” | Brief §12.7 |
| Refusals | Keep no read receipts / last seen / streaks / app and other required negatives | Mandatory §7 content overrides §10F's contradictory blanket word ban |
| Colours / finishes | One graphite-and-silver reference finish only, qualified as design intent | Open in §12.8; no variant picker |
| Subscription / price | Included-connectivity term and price explicitly “to confirm” | Sources leave N unspecified; no invented price |
| Antenna / certification | Cap is part of the antenna; no measured efficiency or IP-rating claim | Report §5 and brief §12.8 |
| Hero / scroll | One continuous assembled device and one contiguous paired-device sequence | Fully commits to narrative B; no explosion |
| Mascot | Original four-colour peach pebble with no name or backstory | Brief §4; one screen occupant representing the other person |
| Typography | Original three font families retained, locally hosted and subset | Preserve the approved identity without third-party runtime requests |
| Light theme | Warm paper, darker ink/accent; halo chapter remains dark | Required system-theme support and contrast |
| Footer | “Target specifications. Nothing measured yet.” | Required honesty note |

Items visibly marked to confirm: final finishes and colours, crown selection, exact panel vendor, runtime and antenna performance, included connectivity term and price. Nothing is presented as measured or certified.

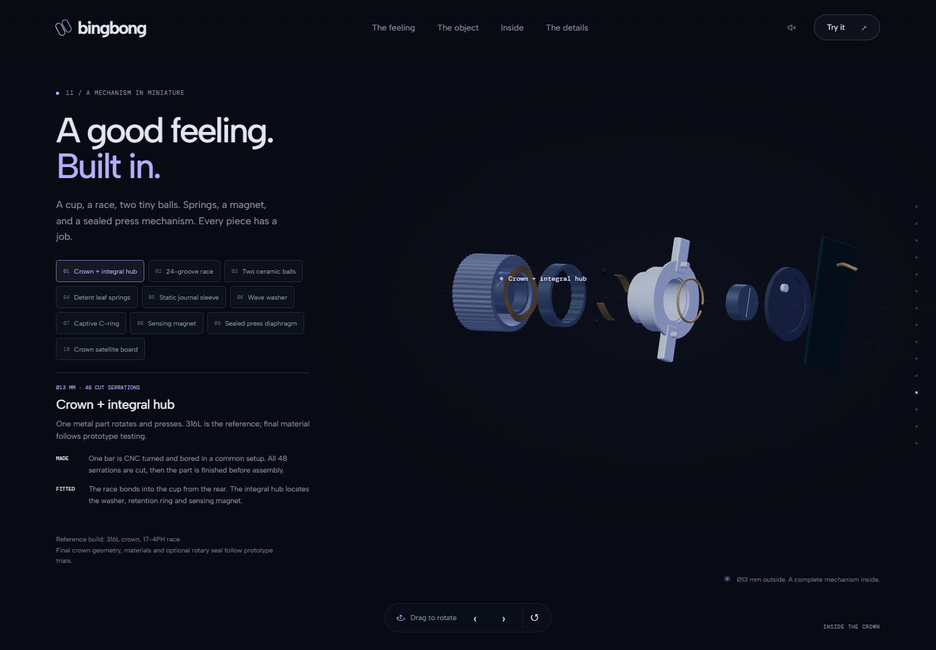
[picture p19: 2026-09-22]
site/qa/assembly/reviewer-1440-crown.png

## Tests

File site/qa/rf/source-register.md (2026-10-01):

# RF study — source register

Added September 24, 2026. Open the lab at `/#rf-lab`.

## Construction authority

- `DESIGN_MANUFACTURING_REPORT_2026-09-19.md`, §3 C-5: adopted vertical spring contact, L-shaped cap tab, sealed ring aperture, and shortened board.
- Same report, §§5.4–5.6: whole-device radiating structure, counterpoise, fields, feed reference plane, materials, keepout, matching topology, and explicitly unverified performance/values.
- `cad-v3/tools/sheet_rf.py` and `cad-v3/bingbong/rf.kicad_sch`: working component references and connections. The overview schematic shows the populated proposed path; the detailed inspector covers all 16 references, including the DNP trim and harmonic-trap positions.
- Existing `site/src/assembly-data.js`: visual construction terminology.

The v3 schematic was already present as untracked working material when this task began. It was read and not modified.

## Primary references

- [Nordic nRF9151 ANT integration](https://docs.nordicsemi.com/r/bundle/nwp_056/page/wp/nwp_054/ant_if.html) and [pin assignments](https://docs.nordicsemi.com/r/bundle/ps_nrf9151/page/pin.html): single-ended 50 Ω antenna interface, pin 35.
- [TI SWRA726](https://www.ti.com/lit/an/swra726/swra726.pdf): antenna impedance measurement, enclosure/hand detuning, calibration, and matching. Its lossless-antenna examples must not be interpreted as proof that all accepted power radiates. This study explicitly separates reflection, component loss, antenna/environment loss, and radiation.
- [Analog Devices impedance matching tutorial](https://www.analog.com/en/resources/technical-articles/impedance-matching-and-smith-chart-impedance-maxim-integrated.html): complex impedance and series/shunt impedance transformations.
- [NI quadrature mixing](https://www.ni.com/docs/en-US/bundle/pxie-5820/page/quadrature-mixing.html): orthogonal references, I/Q modulation, and demodulation.
- [MIT Electromagnetic Fields and Energy, chapter 12](https://ocw.mit.edu/courses/res-6-001-electromagnetic-fields-and-energy-spring-2008/pages/chapter-12/): electrodynamic fields, radiation, and energy flow.
- [3GPP / ETSI TS 36.211, Release 13](https://www.etsi.org/deliver/etsi_ts/136200_136299/136211/13.11.00_60/ts_136211v131100p.pdf): LTE modulation and baseband generation. The lesson explicitly distinguishes the nominal carrier reference from the spectrum of a changing signal, and the single-carrier QPSK example from LTE’s downlink OFDM and uplink SC-FDMA processing.

## Discrepancy handled explicitly

Report §5.6 Step 12 describes probing the antenna through J301, whereas the v3 schematic wires the common/probe side to the IC and the normally closed branch to the antenna. The study follows the actual v3 drawing and explains this in its source notes. An antenna-side fixture and appropriate calibration are needed for antenna impedance measurements. The schematic drawing and contact geometry do not establish measured RF performance.

## Teaching model

`src/rf-model.js` implements a radio-side shunt C, followed by a series L with constant Q = 50, feeding a hypothetical series R–C antenna load. The 50 Ω feed is assumed lossless and omitted. Values can be varied from 650–850 MHz, 0–65 nH, and 0–24 pF.

- Bare: Rradiation = 6 Ω, Rloss = 4 Ω, Cantenna = 1/(2π × 722 MHz × 150 Ω), giving 10 − j150 Ω at 722 MHz.
- Hand: Rloss = 14 Ω and antenna C increased 23%.
- Poor contact: Rloss = 19 Ω, including a severe illustrative 15 Ω contact fault.
- Dummy load: ideal 50 Ω resistor, no radiation.
- Open feed: open antenna branch; any remaining shunt capacitance is still visible at the input, with total reflection and no real power transfer.

Inductor ESR is ωL/Q; capacitors are ideal. All accepted power is divided by the series resistances. The four power fractions sum to one. Radiation/loss resistance is held constant across the sweep. There is no calibrated geometry model, range prediction, antenna radiation pattern, actual dual-band solution, or claim of automatic hardware tuning.

The field illustration represents charge and current in an idealized standing-wave mode. It is neither a Maxwell field solution nor a computed radiation pattern. The QPSK illustration uses the explicit Gray mapping 00/01/11/10 → 45/135/225/315 degrees and does not implement an LTE PHY. The message journey includes the cellular network and delivery service instead of implying direct keychain-to-keychain RF.

## Detailed first-principles models

- **Charge and fields:** the quantitative capacitor example uses 1 pF, 1 V peak, and 722 MHz. `q = Cv` and `i = dq/dt` give 1 pC and 4.54 mA peaks. It is a charge-storage example, not the measured cap input impedance. The outgoing plane-wave slice uses `cos[ω(t − z/c)]`; normalized E and cB are in phase and drawn vertically offset, with their actual perpendicular directions explained. Reactive near fields and far-field radiation are explicitly distinguished.
- **Individual parts:** voltage and current are calculated for isolated ideal capacitors/inductors at 1 V peak and 722 MHz. Energy readouts use `½Cv²` and `½Li²`. These are not circuit-node voltages or a simulation of the assembled network. The ESD example only models its provisional off-state capacitance. DNP means no fitted element, not zero pad parasitics.
- **Parallel LC:** L302 = 15 nH and C302 = 1 pF share an imposed sinusoidal voltage. Current amplitudes are `1/(ωL)` and `ωC`, with opposite signs. At approximately 1299.495 MHz, input currents cancel while branch currents remain. Finite Q and self-resonance are omitted; the resulting infinite ideal impedance is not a hardware prediction. The UI rounds the resonance preset to 0.01 MHz, so it shows a large finite impedance near the peak. The series-LC trap is explained separately.
- **Reflections:** incident/reflected voltage superposition includes the complex phase of Γ from the bench. The drawn transmission line is one wavelength long, lossless, and 50 Ω to make propagation readable. It does not represent the actual PCB length. Reflected voltage amplitude is |Γ| and power is |Γ|².
- **Message recovery:** 1–6 printable ASCII characters become bytes and two-bit symbols. The normalized carrier has four cycles per symbol; no physical LTE symbol rate is implied. Rectangular windows and abrupt transitions are idealizations; real pulse shaping, occupied bandwidth, and timing recovery are explained. The code performs midpoint integration of `2r cos(reference)` and `−2r sin(reference)` with 256 samples per complete window and full-symbol normalization. Partial integrals are never presented as completed decisions. The four integer carrier cycles make the double-frequency term average to zero in the clean reference case.
- **Channel and pilot:** the desired amplitude is 0.65. Phase rotation spans ±90°. An ideal, noiseless known 00/45° pilot provides I/Q; `atan2(Qp, Ip) − 45°` measures the channel offset used by both local references. This deliberate simplification is stated next to the control; real receivers have estimation error. Interference combines a co-channel tone and an 11-cycle-per-symbol tone with repeatable phase variation, not AWGN or a statistical BER model. It affects data, not this ideal pilot. Hard quadrant decisions have no error correction. Error counts compare with the known transmitted bits; a real receiver cannot directly make that comparison on unknown data. Non-printable recovered bytes display a replacement character and retain their byte values.

All animations are manually started, pause on close/chapter changes, and offer manual phase or symbol controls. Reduced-motion users step phases or recover the message without playback. The phone receiver keeps a compact result visible while its controls are adjusted.

## Verification

Run `npm run build`, `npm run artifact`, then the production preview on port 4173, `node scripts/rf-check.mjs`, and `node scripts/rf-lessons-check.mjs`. Results and representative screenshots are saved in this directory and `deep/`. The scripts check analytical reference cases, passive energy conservation, known I/Q identities, ASCII round-trips, pilot recovery, LC cancellation, component controls, reduced motion, keyboard tabs/sliders, animation lifecycle, history/focus return, a paused background renderer, all panels with axe, narrow layouts, no-JS reading, and standalone operation.

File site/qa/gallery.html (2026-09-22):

# bingbong · 240 resting-state captures

Click a frame to inspect its original pixels. These are browser captures, not physical-phone evidence.

WidthThemeMotion

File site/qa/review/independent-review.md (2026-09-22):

# Blind redesign review

A separate reviewer was requested by brief §10. DESIGN_NOTES.md remained unopened.

Forty chapter/width samples: no page errors, overflow or factual inconsistencies. Live initial 3D, mouse rotation, keyboard/touch pet–boop–hold, view reset, native touch scrolling, reduced motion and cold-demo cancellation passed.

Findings fixed and rechecked: mobile toolbar covering content; tablet hero control overlap; desktop sound control overlap; tablet ruler center; touch capture lost during handoff. An 85 px horizontal drag now produces the full 0.68 rad rotation.

Final disposition: no remaining blockers on the reviewed paths. Browser-emulated touch does not establish physical-phone performance. Captures are in ../redesign/reviewer/.

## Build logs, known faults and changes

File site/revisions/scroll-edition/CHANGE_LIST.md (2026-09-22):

# What changed in the redesign

| Area | New version |
| --- | --- |
| Visual direction | Midnight blue, cool silver, violet; a fixed dark presentation in either system theme |
| Typography | Cleaner Albert Sans display/body type; restrained mono labels |
| Opening | Centered headline and a large live object, with a compact demo invitation |
| Product display | Immediate live 3D; no chapter still-image swaps in the normal experience |
| Materials | Rebuilt surface normals, smoother cap edges, matte graphite and controlled studio reflections |
| Movement | One continuous scroll track; curved movement between compositions, reversible progress, restrained ambient motion and animated rear view |
| Inspection | Drag the body, use keyboard view controls, or reset the composition |
| Mobile | Native vertical scrolling; the object, stage clipping, background and controls travel together from the hero into the story |
| Demonstrations | Pet, boop, hold, halo acknowledgment and creature previews preserved |
| State reliability | Leaving a chapter clears pending demonstrations; inspection and halo overrides blend back into the path without a pose reset |
| Accessibility | Reduced motion stops ambient movement and catch-up; scroll still interpolates continuously; keyboard demos retained |
| Cold loading | Baked lighting samples and asynchronous shader compilation remove expensive setup from the visitor's main thread |
| Resilience | Offline reload, standalone file, no-JavaScript content, unavailable-WebGL fallback and context recovery |
| Product facts | Dimensions, semantics and estimate qualifications retained; no new commercial claims |

The first version's source and static archives are in `revisions/first-build/`. Current metrics and evidence are in `DESIGN_NOTES.md`; the first build's scores should not be reused for this revision.

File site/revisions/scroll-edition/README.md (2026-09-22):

# bingbong — the live object edition

A new visual direction built around an animated, inspectable 3D product. Midnight blue, cool silver, violet, clean typography, and the original pet / boop / hold demonstrations. This replaces the first build's warm palette and still-first presentation, as requested.

## Run

Dependencies are installed. From this directory:

```sh
npm run dev
```

Open http://localhost:5173. On a fresh checkout, run `npm ci` first; use Node 22.12+ or 24.

`npm run build` creates `dist/`. `npm run preview` serves it at http://localhost:4173. The production preview is currently running. Use http://localhost:4173/?v=3 to open the continuous-scroll revision from a browser that cached an earlier build.

Deploy the contents of `dist/` to a static host at the domain root. No server, account, telemetry, external runtime request, or purchase flow is needed. The local service worker makes the site available offline after a complete load. Navigation prefers the network so revisions are visible; cached content remains available offline.

`npm run artifact` produces `artifact/bingbong.html`. This standalone version includes the code, fonts, lighting map, and fallback assets. Open it directly in a browser; no local server or CDN is required.

## Interact

- Drag the **body** to rotate the object. Horizontal touch dragging rotates; vertical swiping keeps normal page scrolling. The view controls also work with keyboard activation.
- Drag the **crown**, or use its arrow keys, to turn in 15° detents. Enter boops; holding Space shares presence.
- Use the chapter's turn, boop, and hold controls to try the paired-device demonstrations.
- Use **Turn it over** for the rear charging pads. Rotation and rear-view transitions use the same live geometry.
- Scroll carries the same object between compositions. Position, scale, screen brightness, halo, mobile clipping and view controls follow the same continuous track; reversing scroll retraces it.
- Sound is opt-in. Reduced motion stops ambient movement and scroll catch-up; the object follows the user's scroll directly and retains manual interaction.

## Source

| File | Responsibility |
| --- | --- |
| `src/experience.css`, `src/tokens.css` | New layout, responsive behavior, palette, typography |
| `src/sections/` | Ten chapters of static, accessible content |
| `scripts/build-page.mjs` | Generates HTML, navigation, and accessible controls |
| `src/main.js` | Immediate scene startup and chapter coordination |
| `src/timeline.js` | A single scroll coordinate drives continuous poses and visual states |
| `src/components/scene.js` | Live rendering, damped transforms, drag rotation, context recovery |
| `src/components/product-model.js` | Parametric exterior in millimetres; materials, crown, display and halo |
| `src/components/studio.js` | Source of the studio lighting environment |
| `src/components/mascot.js` | Original wordless creature and animated reactions |
| `src/interactions.js` | Pet, boop, hold, sound and timer lifecycle |
| `public/mascot/` | Reusable SVG states, PNG sheets, loops and character note |
| `public/lighting/` | Prefiltered reflection map; the object itself remains live geometry |
| `public/renders/` | Generated stills for no-JavaScript / unavailable-WebGL fallback only |
| `qa/` | Screenshots, gesture tests, motion recordings and reports |

With the dev server running, `npm run assets` regenerates fallback stills. `node scripts/bake-lighting.mjs` regenerates the lighting map from the studio source. Shader compilation runs asynchronously; expensive environment prefiltering happens when generating assets, not on each visitor's device.

## Verify

With the production preview running:

```sh
npm run qa
node scripts/live-check.mjs
node scripts/scroll-check.mjs
node scripts/delivery-check.mjs
node scripts/lighthouse.mjs
```

QA uses installed Google Chrome through Playwright. The main suite captures every chapter at 390, 820, 1440 and 1920 px, in both system themes and motion settings. The fixed midnight palette is intentional in both themes. The scroll suite measures rendered movement across every chapter in both directions, including reduced motion, intermediate stops, screen/halo fades, mobile clipping, wheel input and boop navigation. Additional checks cover 360 px, touch, keyboard, live startup, object rotation, graphics-context recovery, no JavaScript, offline reload and the standalone file.

See [DESIGN_NOTES.md](DESIGN_NOTES.md) for measured results and limitations. Browser-emulated touch/performance is not a physical-phone test.

The physical facts and wording come from `SITE_BRIEF.md` and the local engineering reports. Final finishes, crown selection, runtime and RF results remain design intent. Fonts are self-hosted under the SIL Open Font License; licences accompany them. Three.js's MIT notice is in `public/THIRD_PARTY_NOTICES.txt`. The original build's source, static archive and notes are preserved locally in `revisions/first-build/`.

`scripts/export.ps1` creates source, static and review ZIPs. The source includes historical notes; the review archive holds screenshots, results and videos separately. Extract both into the same directory to follow the evidence links. Raw screencast frames and dependencies are excluded.

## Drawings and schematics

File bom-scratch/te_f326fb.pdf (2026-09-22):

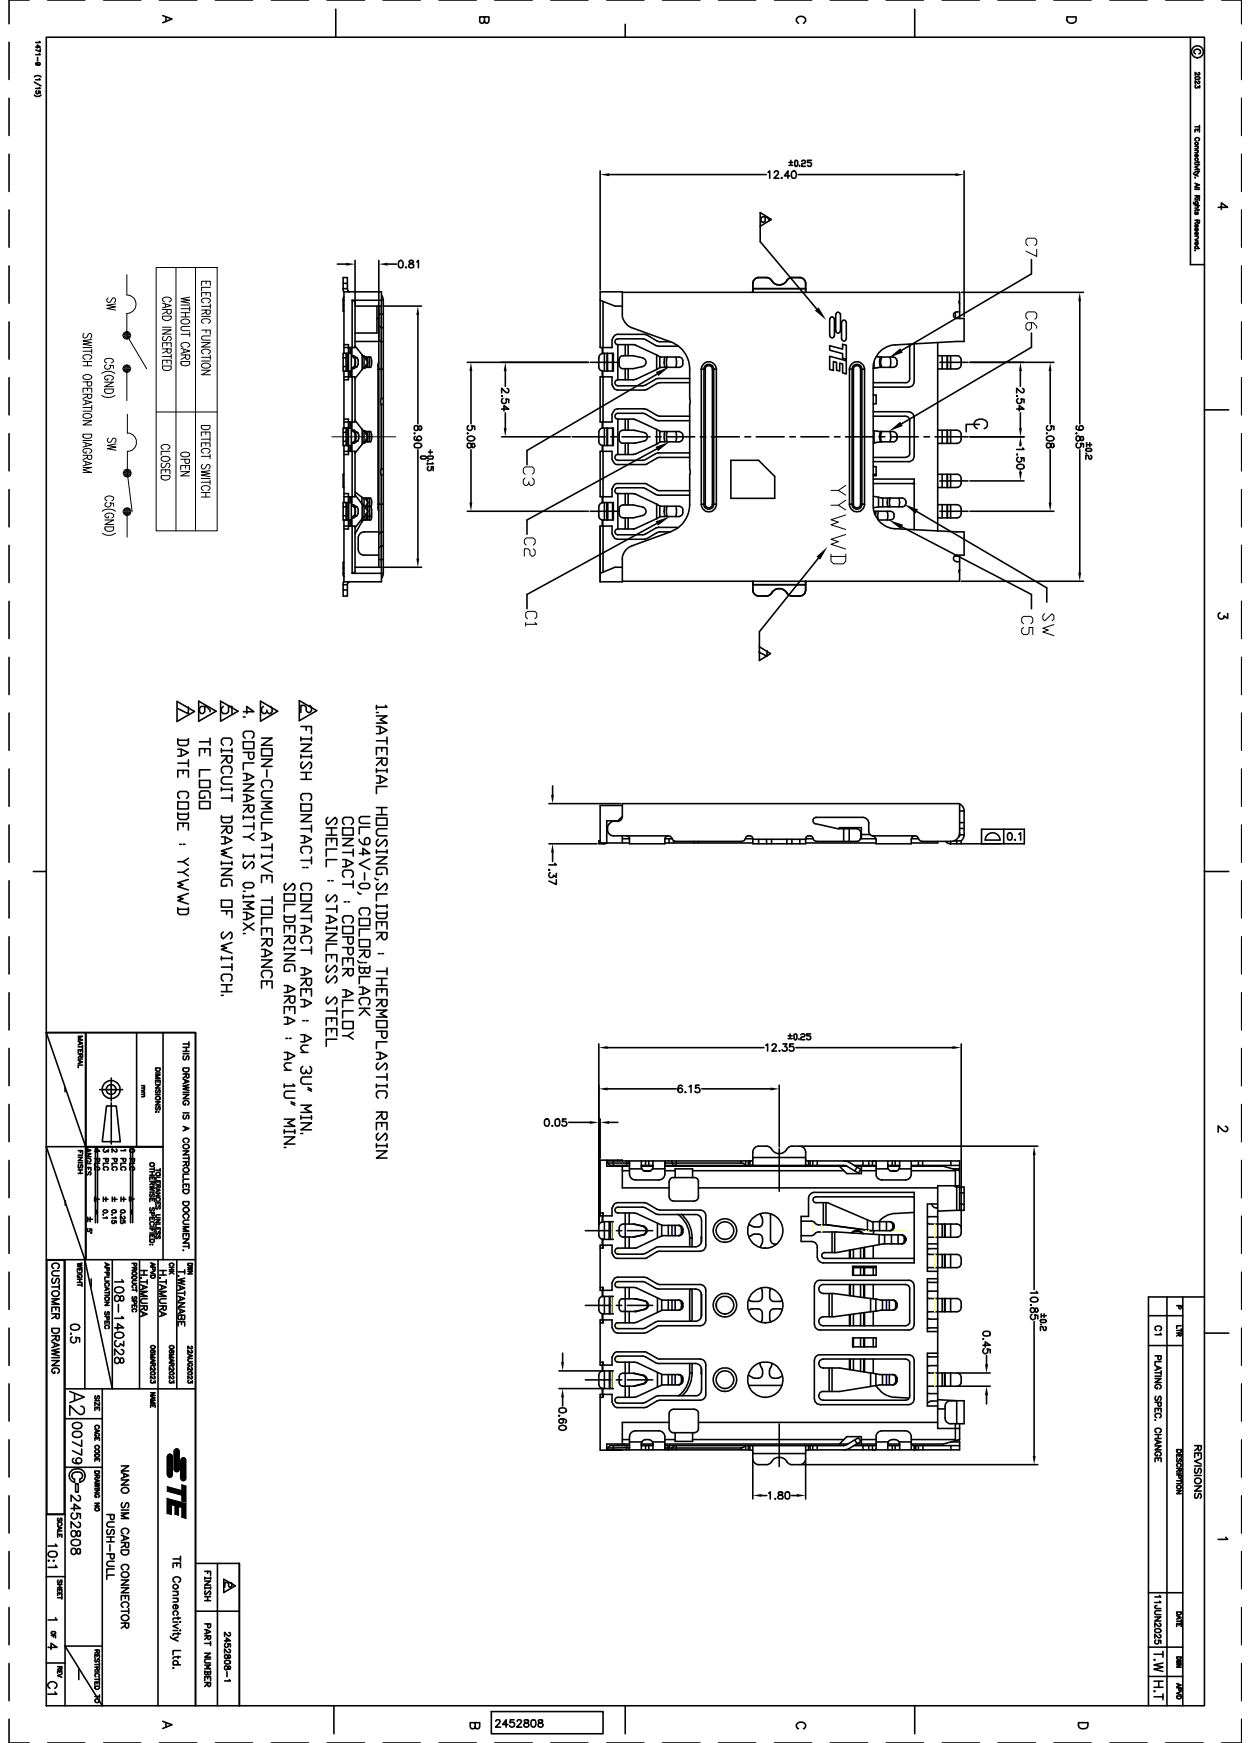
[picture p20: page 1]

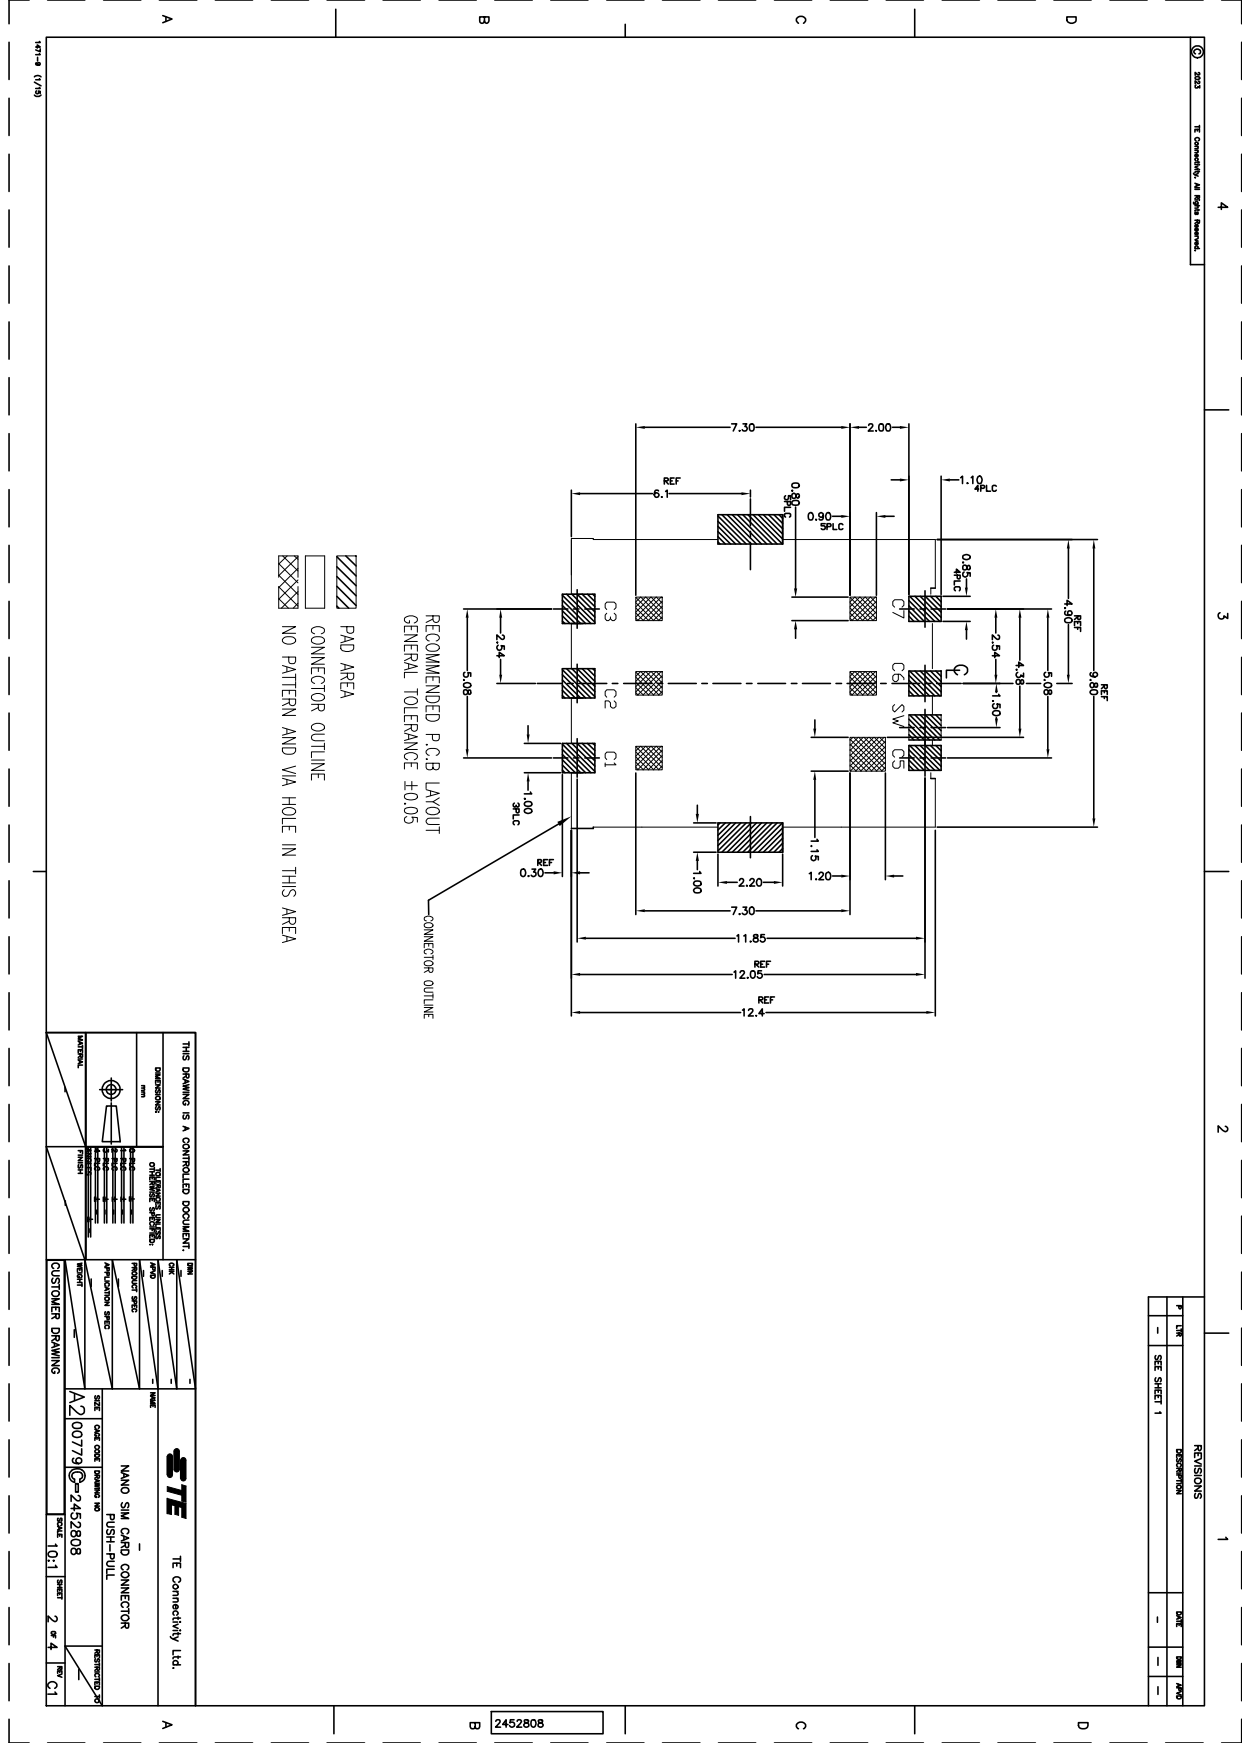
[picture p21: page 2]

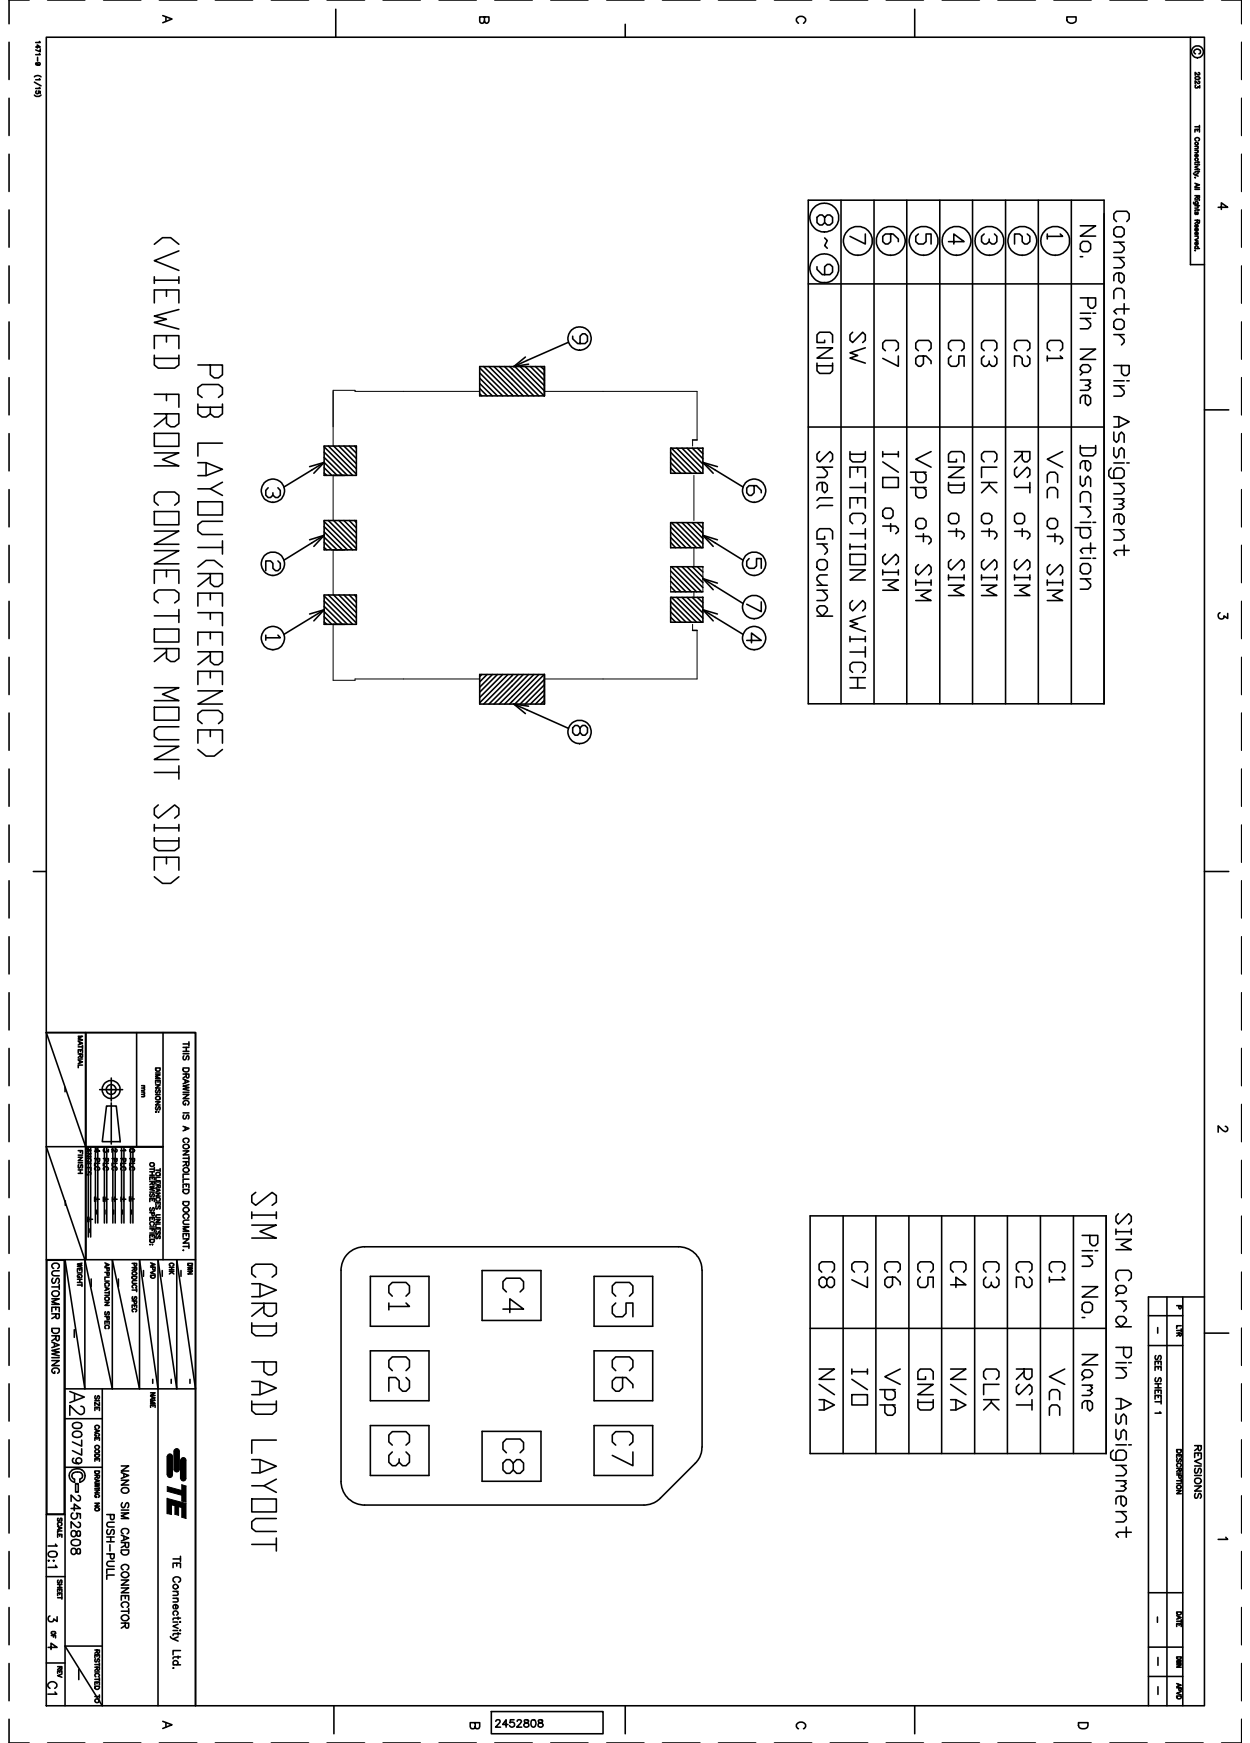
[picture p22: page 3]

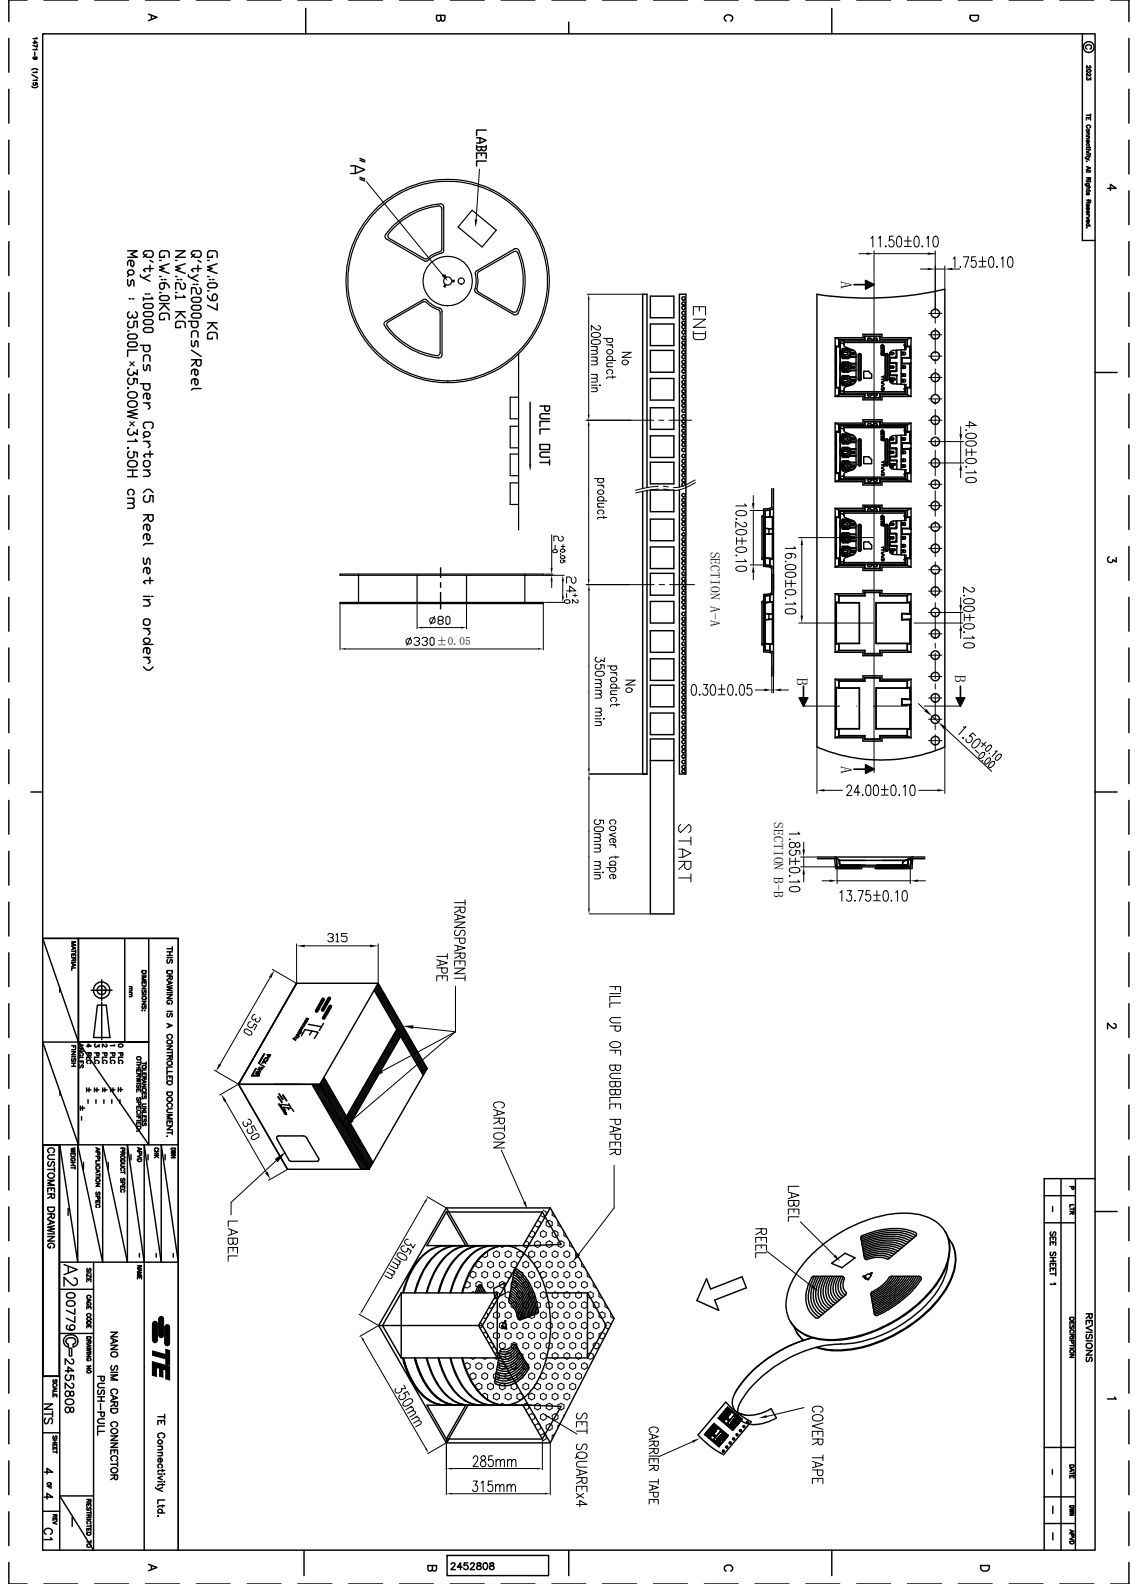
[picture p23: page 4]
SECTION B-B; SECTION A-A

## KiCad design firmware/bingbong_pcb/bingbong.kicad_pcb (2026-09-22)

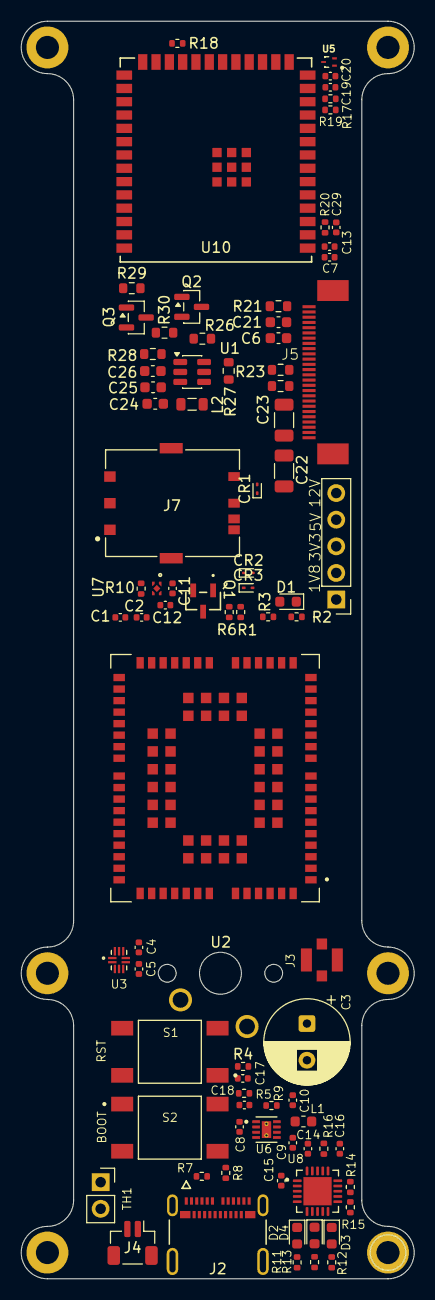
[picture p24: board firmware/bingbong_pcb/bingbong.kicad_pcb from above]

Board: 2 copper layers, 37.5 x 120.0 mm, 85 parts (1 on the bottom side), 60 nets, no tracks yet.

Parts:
C1, C4, C5, C7, C17, C18, C19: 0.1uF; C_0402_1005Metric
C2, C11, C12, C29: 1uF; C_0402_1005Metric
C3: 470 uF; CP_Radial_D8.0mm_P3.50mm
C6, C21: 0.1uF; C_0603_1608Metric
C8, C9, C15: 10uF; C_0402_1005Metric
C10, C13, C20: 22uF; C_0402_1005Metric
C14, C16: 4.7uF; C_0402_1005Metric
C22, C23: 4.7uF; C_1206_3216Metric
C24, C25: 1uF; C_0603_1608Metric
C26: 220pF; C_0603_1608Metric
CR1, CR2, CR3: PESD5V0F1BLD_315; D_SOD-923
D1: RED LED; LED_0603_1608Metric
D2, D3, D4: LED; LED_0603_1608Metric
J2: 1054500101; MOLEX_1054500101
J3: CONMHF1-SMD-T; TE_CONMHF1-SMD-T
J4: Conn_01x02_Pin; JST_SH_BM02B-SRSS-TB_1x02-1MP_P1.00mm_Vertical
J5: Conn_01x28_Socket; Conn_Zif_26Pin
J6: Conn_01x05_Pin; PinHeader_1x05_P2.54mm_Vertical
J7: 2452808-1; TE_2452808-1
L1: 2.2uH; L_0603_1608Metric
L2: 22uH; L_0805_2012Metric
Q1: SOT-23; SOT-23-3_1P4X3P040_ONS
Q2: FDN340P; SOT-23
Q3: SS8050; SOT-23
R1, R14, R15, R18, R20: 10k; R_0402_1005Metric
R2, R6, R9, R10, R16: 100k; R_0402_1005Metric
R3, R11, R12, R13: 1k; R_0402_1005Metric
R4, R5, R17, R19: 0; R_0402_1005Metric
R7, R8: 5.1k; R_0402_1005Metric
R21: 680k; R_0603_1608Metric
R22, R23, R26, R30: 10k; R_0603_1608Metric
R27: 110k; R_0603_1608Metric
R28: 2k; R_0603_1608Metric
R29: 1k; R_0603_1608Metric
S1, S2: TS04-66-70-BK-100-SMT; SW_TS04-66-70-BK-100-SMT
SW1: SW_Push; SW_Cherry_MX_1.00u_PCB
TH1: 10k; PinSocket_1x02_P2.54mm_Vertical
U1: SOT-23-6
U2: BG95M3LA-64-SGNS; XCVR_BG95M3LA-64-SGNS
U3: SN74AVC2T245RSWR; QFN40P180X140X55-10N
U5: TPD2EUSB30ADRTR; SOTFL35P100X50-3N
U6: TPS62172DSGR; SON50P200X200X80-9N
U7: MIC5504-1.8YMT-TR; TDFN1010-4LD-PL-2_MCH
U8: MCP73871-2CCI_ML; QFN50P400X400X100-21N
U10: ESP32-S2-SOLO-2U-N4; ESP32-S2-SOLO-2U_EXP

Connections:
+1.8V: C4.1, C11.1, J6.2, R2.1, U3.7 (VCCA), U7.1 (VOUT)
+3.3V: C5.1, C6.1, C7.1, C9.1, C10.1, C12.1, C13.1, C21.1, J5.19, J5.21, J5.22, J6.3, L1.1, Q2.2 (S), R3.2, R9.1, R11.1, R12.1, R13.1, R20.2, R22.2, R23.2, R30.1, SW1.1, U3.6 (VCCB), U3.10 (DIR1), U6.6 (VOS), U7.4 (VIN), U8.9 (~TE), U10.2 (3V3)
+5V: C15.1, J2.A4 (VBUS_A4), J2.A9 (VBUS_A9), J2.B4 (VBUS_B4), J2.B9 (VBUS_B9), J6.4, U8.2 (VPCC), U8.18 (IN), U8.19 (IN__1)
+12V: C22.1, C25.1, C26.1, J5.2, J5.25, J6.5, R27.2, U1.2 (VOUT)
/ANT_MAIN: J3.1, U2.60 (ANT_MAIN)
/BG95 RX: U2.34 (MAIN_RXD), U3.9 (A2)
/BG95 TOGGLE POWER: R1.1, R6.1, U10.20 (IO12)
/BG95 TX: U2.35 (MAIN_TXD), U3.8 (A1)
/BG95_CLK: CR2.1, J7.C3 (CLK), U2.46 (USIM_CLK)
/BG95_IO: CR1.1, J7.C7 (I/O), U2.45 (USIM_DATA)
/BG95_RST: CR3.1, J7.C2 (RST), U2.44 (USIM_RST)
/BG95_VCC: J7.C1 (VCC), U2.43 (USIM_VDD)
/BOOT: R5.2, U10.27 (IO0)
/BTN: R18.2, SW1.2, U10.23 (IO21)
/CHARGE EN: R16.2, U8.17 (CE), U10.22 (IO14)
/EN: C29.2, R4.2, R20.1, U10.3 (EN)
/ESP32 RX: U3.5 (B1), U10.38 (IO2)
/ESP32 TX: U3.4 (B2), U10.39 (IO1)
/IO19: R19.2, U10.13 (IO19)
/IO20: R17.2, U10.14 (IO20)
/MIC EN: R10.2, U7.3 (EN), U10.21 (IO13)
/OLED RST: J5.16, U10.17 (IO9)
/OLED SCL: J5.12, R23.1, U10.18 (IO10)
/OLED SDA: J5.10, J5.11, R22.1, U10.19 (IO11)
/R1200 CE: U1.1 (CE), U10.12 (IO8)
/R1200 PWR EN: R29.2, U10.11 (IO18)
/SIM SW: J7.SW, U10.24 (IO33)
/SYS LOAD: C8.1, C14.1, U6.2 (VLN), U6.3 (EN), U8.1 (OUT), U8.20 (OUT__1)
/USB D+: C19.1, C20.1, J2.A6 (D1+), J2.B6 (D2+), R17.1, U5.1 (D+)
/USB D-: J2.A7 (D1-), J2.B7 (D2-), R19.1, U5.2 (D-)
/VBAT: C1.1, C2.1, C3.1, J4.2, TH1.2, U2.32 (VBAT_BB), U2.33 (VBAT_BB__1), U2.52 (VBAT_RF), U2.53 (VBAT_RF__1), U8.5 (THERM)
GND: C1.2, C2.2, C3.2, C4.2, C5.2, C6.2, C7.2, C8.2, C9.2, C10.2, C11.2, C12.2, C13.2, C14.2, C15.2, C16.2, C17.2, C18.2, C19.2, C20.2, C21.2, C22.2, C23.2, C24.2, C25.2, C29.1, CR1.2, CR2.2, CR3.2, J2.A1 (GND_A1), J2.A12 (GND_A12), J2.B1 (GND_B1), J2.B12 (GND_B12), J2.SH1 (SHIELD3), J2.SH2 (SHIELD4), J2.SH3 (SHIELD1), J2.SH4 (SHIELD2), J3.2, J3.3, J3.4, J4.1, J5.4, J5.5, J5.6, J5.7, J5.8, J5.9, J5.13, J5.14, J5.15, J5.17, J5.18, J5.20, J5.23, J5.27, J5.28, J6.1, J7.C5 (GND), J7.GND8 (SH), J7.GND9 (SH__1), Q1.1 (E), Q3.2 (E), R6.2, R7.2, R8.1, R10.1, R14.1, R15.1, R16.1, R18.1, R21.2, R26.1, S1.2, S1.4, S2.2, S2.4, TH1.1, U1.5 (GND), U2.3 (GND), U2.31 (GND__1), U2.47 (USIM_GND), U2.48 (GND__2), U2.50 (GND__3), U2.54 (GND__4), U2.55 (GND__5), U2.58 (GND__6), U2.59 (GND__7), U2.61 (GND__8), U2.62 (GND__9), U2.67 (GND__10), U2.68 (GND__11), U2.69 (GND__12), U2.70 (GND__13), U2.71 (GND__14), U2.72 (GND__15), U2.73 (GND__16), U2.74 (GND__17), U2.79 (GND__18), U2.80 (GND__19), U2.81 (GND__20), U2.82 (GND__21), U2.89 (GND__22), U2.90 (GND__23), U2.91 (GND__24), U2.100 (GND__25), U2.101 (GND__26), U2.102 (GND__27), U3.1 (DIR2), U3.2 (~OE), U3.3 (GND), U5.3 (GND), U6.1 (PGND), U6.4 (AGND), U6.5 (FB), U6.9 (EPAD), U7.2 (GND), U7.5 (GND), U8.3 (SEL), U8.4 (PROG2), U8.10 (VSS__1), U8.11 (VSS), U8.21 (EP), U10.1 (GND), U10.40 (GND), U10.41 (GND), U10.42 (GND), U10.43 (GND), U10.44 (GND), U10.45 (GND), U10.46 (GND), U10.47 (GND), U10.48 (GND), U10.49 (GND)
unnamed: C17.1, R4.1, S1.1, S1.3
unnamed: C18.1, R5.1, S2.1, S2.3
unnamed: C26.2, R28.2
unnamed: D1.2 (A), R3.1
unnamed: D1.1 (K), U2.21 (NET_STATUS)
unnamed: D2.2 (A), R11.2
unnamed: D2.1 (K), U8.6 (~PG)
unnamed: D3.2 (A), R12.2
unnamed: D3.1 (K), U8.8 (STAT1/*LBO)
unnamed: D4.2 (A), R13.2
unnamed: D4.1 (K), U8.7 (STAT2)
unnamed: J2.A5 (CC1), R7.1
unnamed: J2.B5 (CC2), R8.2
unnamed: C23.1, J5.3
unnamed: J5.24, R21.1
unnamed: Q1.2 (B), R1.2
unnamed: Q1.3 (C), U2.15 (PWRKEY)
unnamed: C24.1, L2.1, Q2.3 (D), U1.3 (VDD)
unnamed: Q2.1 (G), Q3.3 (C), R30.2
unnamed: Q3.1 (B), R29.1
unnamed: L2.2, U1.4 (Lx)
unnamed: R26.2, R27.1, R28.1, U1.6 (VFB)
unnamed: R2.2, U2.17 (~RESET)
unnamed: R9.2, U6.8 (PG)
unnamed: L1.2, U6.7 (SW)
unnamed: R14.2, U8.13 (PROG1)
unnamed: R15.2, U8.12 (PROG3)
unnamed: C16.1, U8.14 (VBAT__1), U8.15 (VBAT), U8.16 (VBAT_SENSE)

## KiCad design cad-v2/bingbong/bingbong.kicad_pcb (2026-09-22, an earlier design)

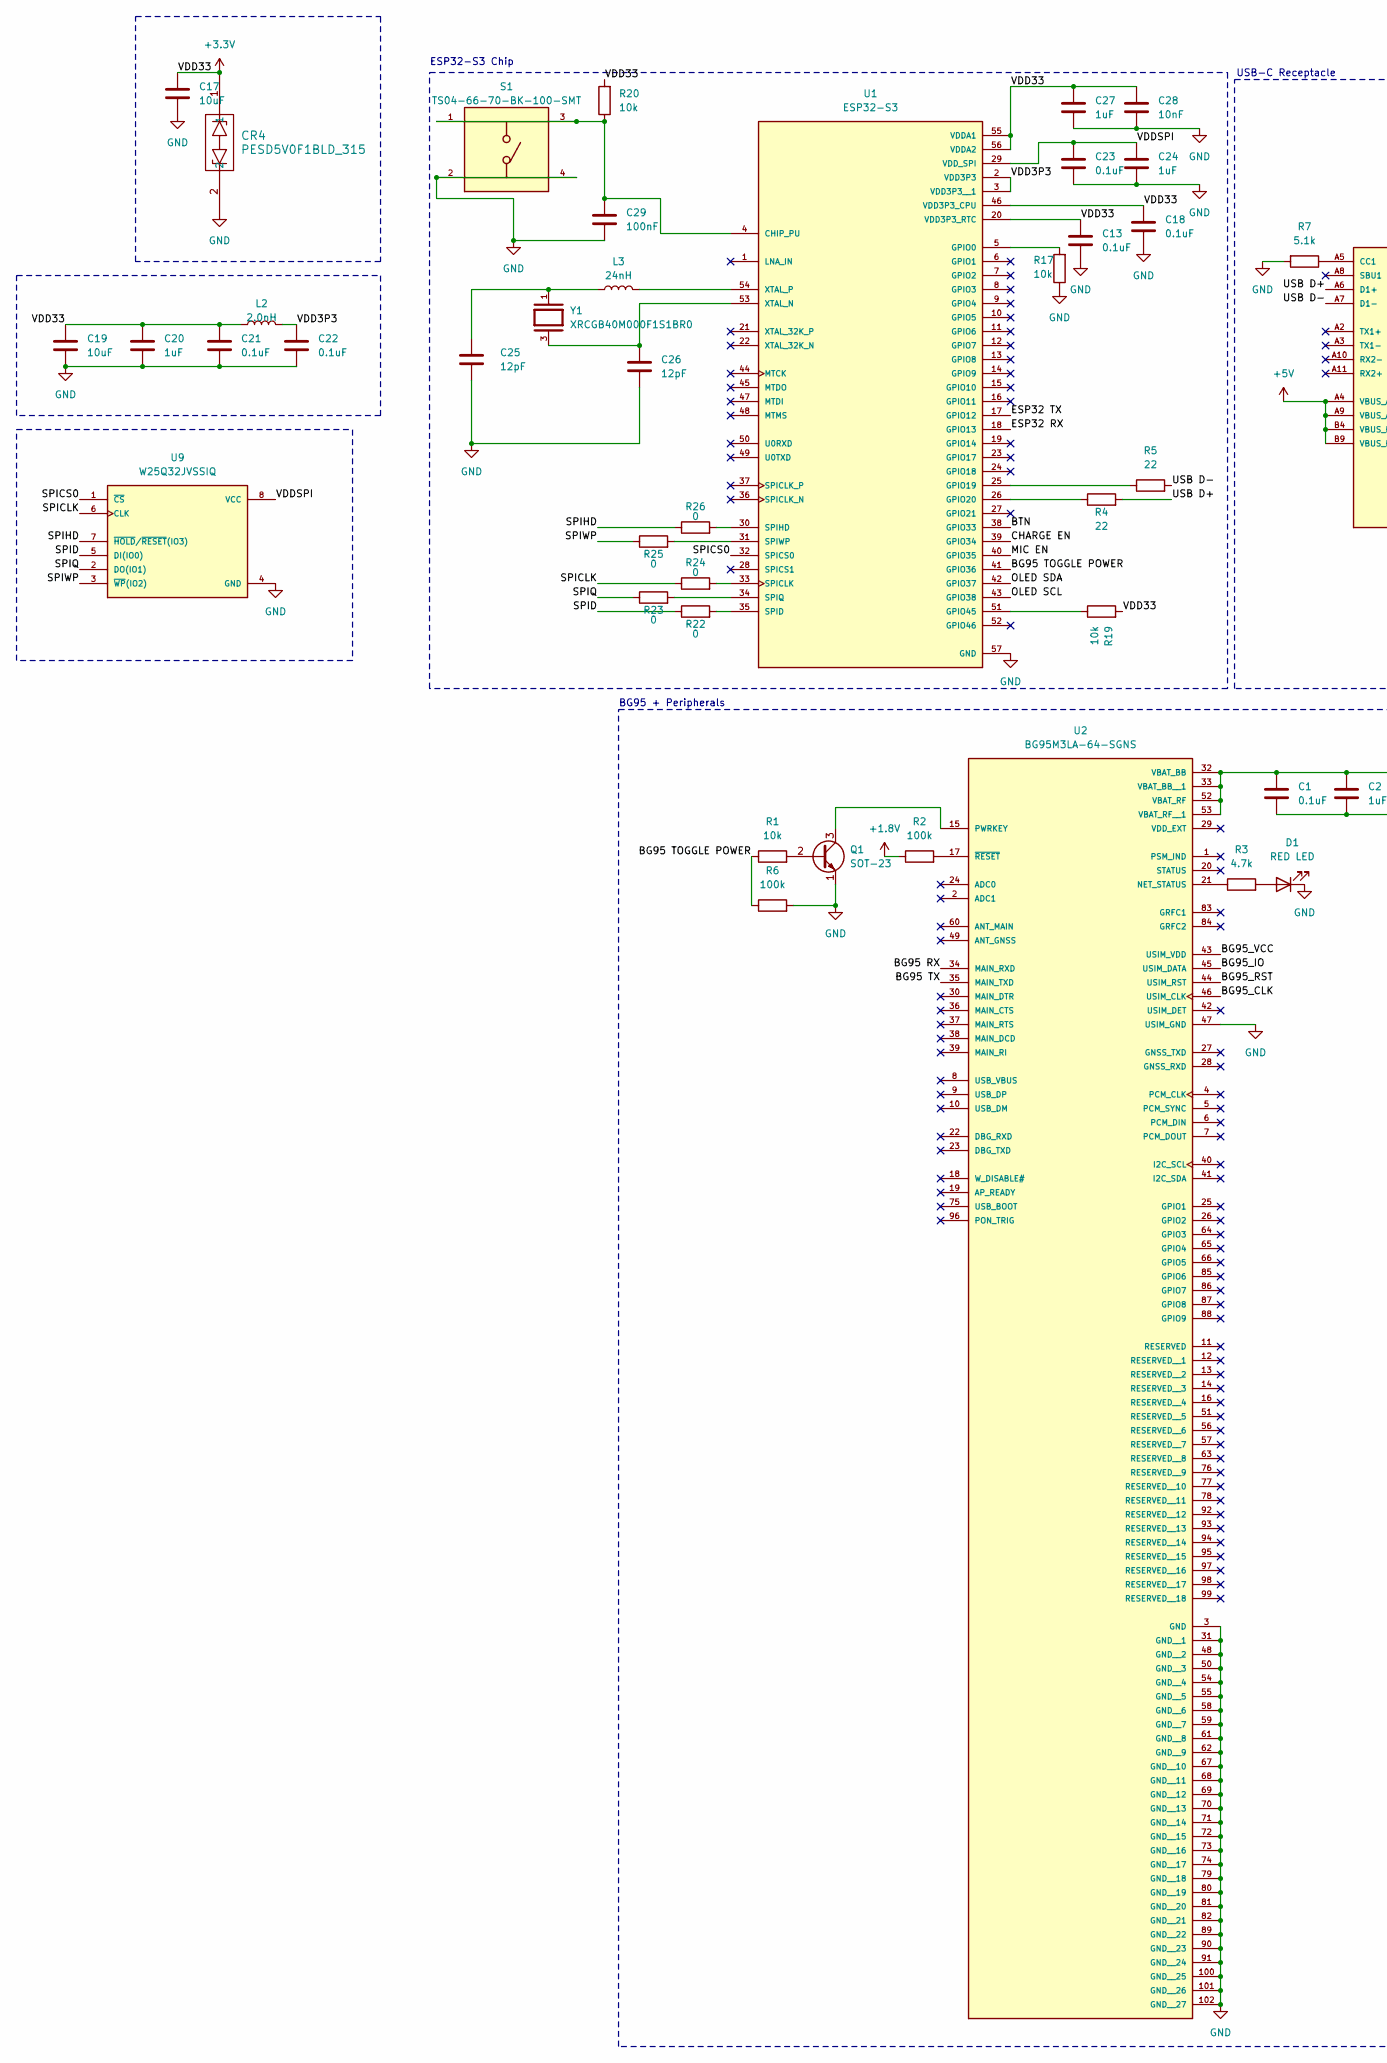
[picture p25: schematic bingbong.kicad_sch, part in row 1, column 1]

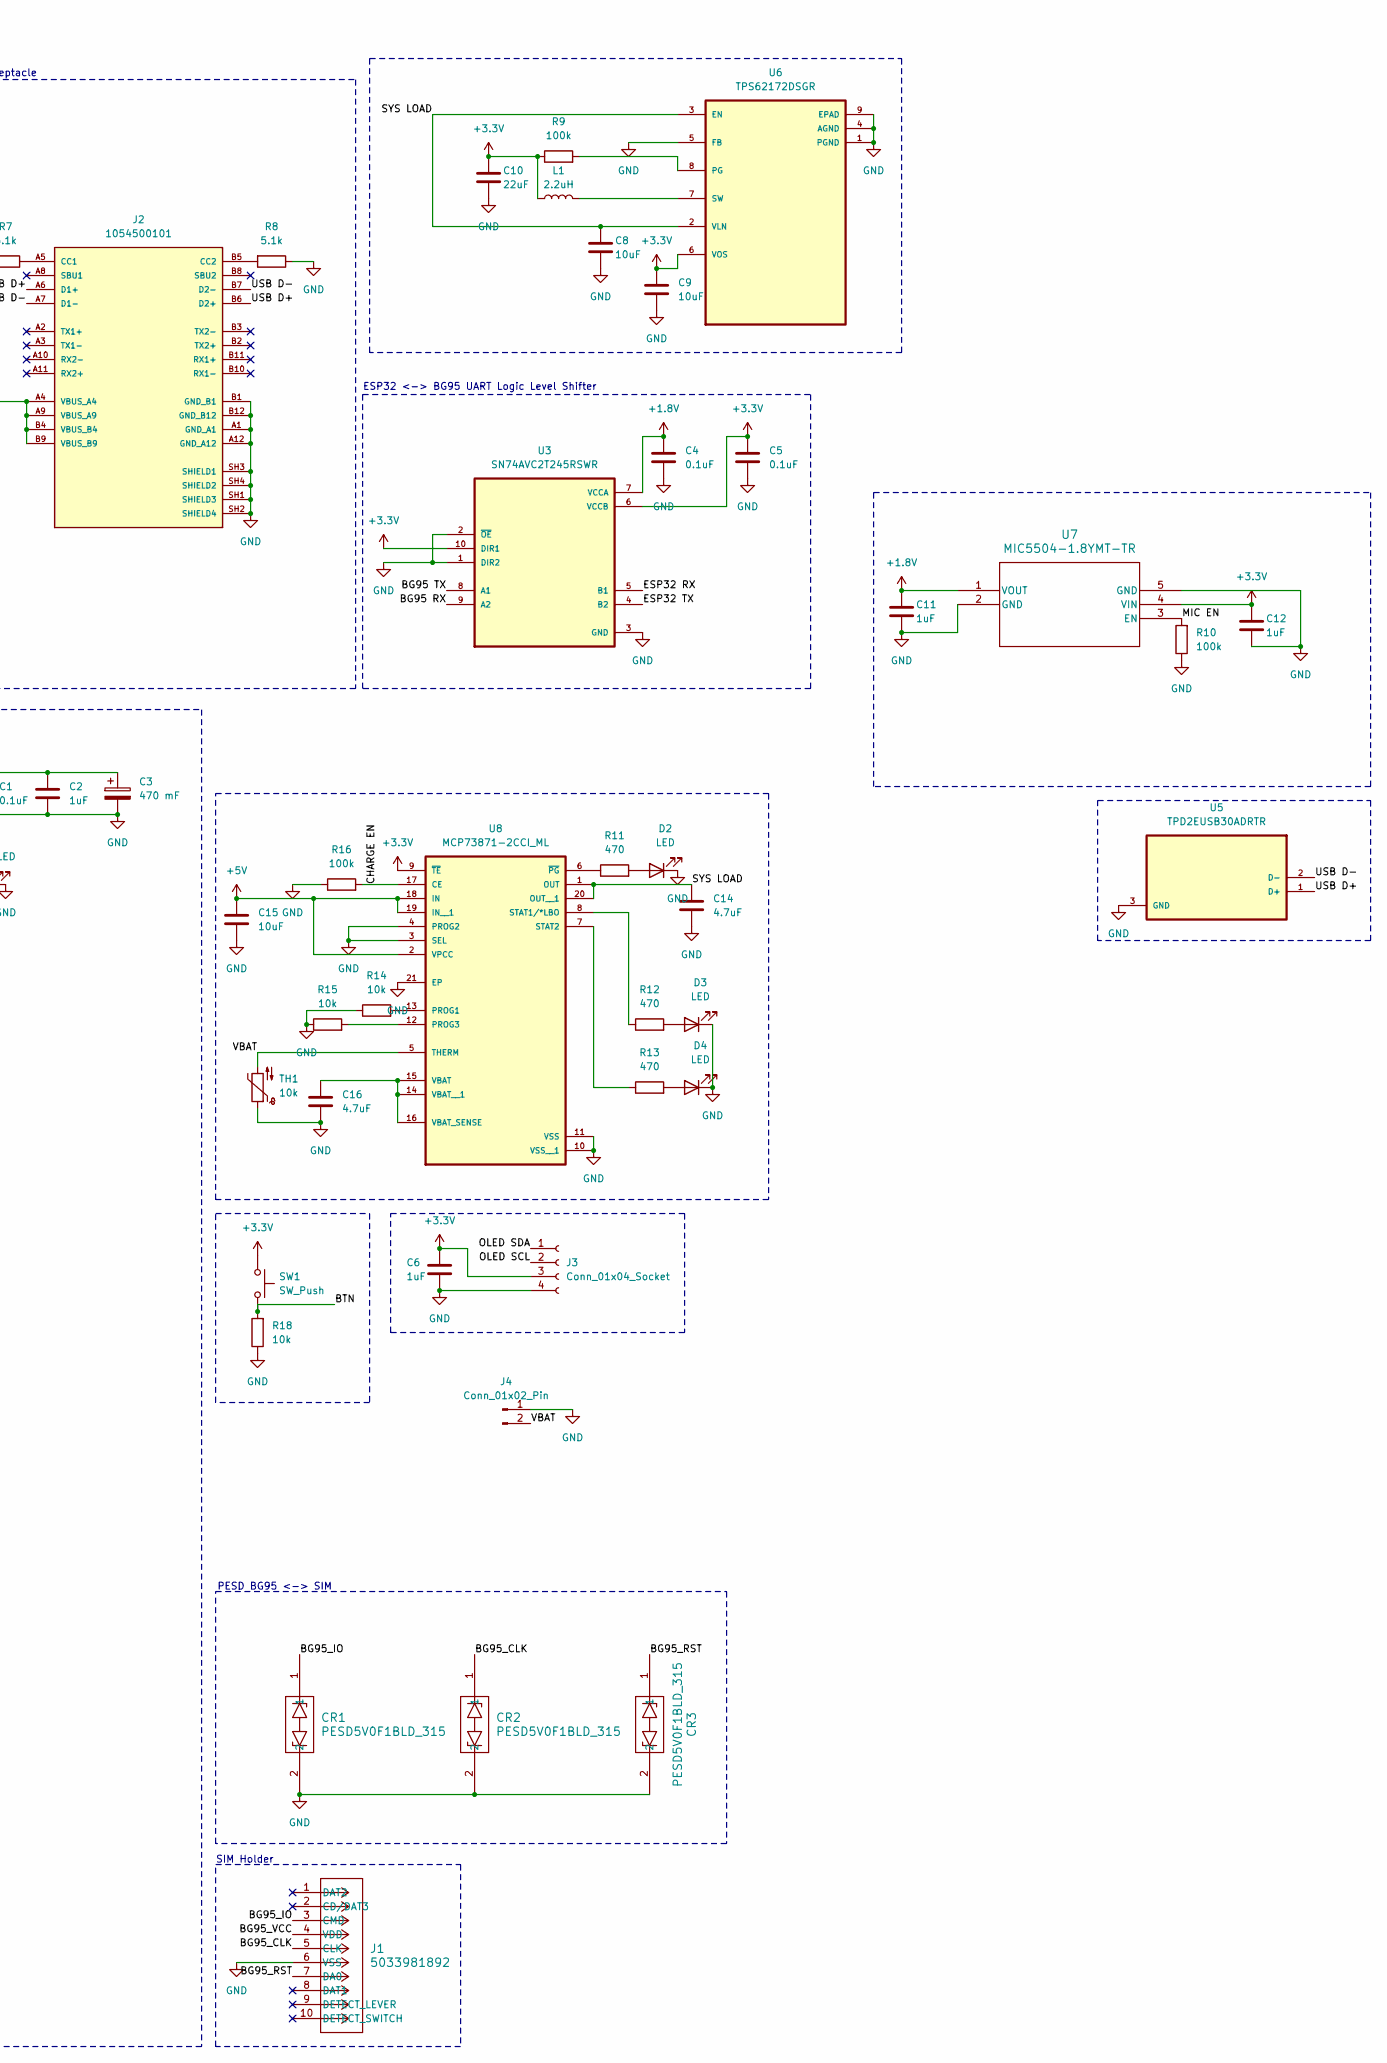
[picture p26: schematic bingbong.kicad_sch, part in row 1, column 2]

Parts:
C1, C4, C5, C13, C18, C21, C22, C23: 0.1uF; C_0402_1005Metric
C2, C6, C11, C12, C20, C24, C27: 1uF; C_0402_1005Metric
C3: 470 mF; CP_Radial_D8.0mm_P3.50mm
C8, C9, C15, C17, C19: 10uF; C_0402_1005Metric
C10: 22uF; C_0402_1005Metric
C14, C16: 4.7uF; C_0402_1005Metric
C25, C26: 12pF; C_0402_1005Metric
C28: 10nF; C_0402_1005Metric
C29: 100nF; C_0402_1005Metric
CR1, CR2, CR3, CR4: PESD5V0F1BLD_315; DFN1006D-2_SOD882D_NEX
D1: RED LED; LED_0603_1608Metric
D2, D3, D4: LED; LED_0603_1608Metric
J1: 5033981892; CONN_503398-1892_MOL
J2: 1054500101; MOLEX_1054500101; PARTREV A7
J3: Conn_01x04_Socket; PinSocket_1x04_P2.54mm_Vertical
J4: Conn_01x02_Pin; PinHeader_1x02_P1.00mm_Vertical
L1: 2.2uH; L_0603_1608Metric
L2: 2.0nH; L_0603_1608Metric
L3: 24nH; L_0603_1608Metric
Q1: SOT-23; SOT-23-3_1P4X3P040_ONS
R1, R14, R15, R17, R18, R19, R20: 10k; R_0402_1005Metric
R2, R6, R9, R10, R16: 100k; R_0402_1005Metric
R3: 4.7k; R_0402_1005Metric
R4, R5: 22; R_0402_1005Metric
R7, R8: 5.1k; R_0402_1005Metric
R11, R12, R13: 470; R_0402_1005Metric
R22, R23, R24, R25, R26: 0; R_0402_1005Metric
S1: TS04-66-70-BK-100-SMT; SW_TS04-66-70-BK-100-SMT; PARTREV 1.0
SW1: SW_Push; SW_Cherry_MX_1.00u_PCB
TH1: 10k; PinSocket_1x02_P2.54mm_Vertical
U1: ESP32-S3; IC_ESP32-S3; PARTREV v1.2
U2: BG95M3LA-64-SGNS; XCVR_BG95M3LA-64-SGNS
U3: SN74AVC2T245RSWR; QFN40P180X140X55-10N
U5: TPD2EUSB30ADRTR; SOTFL35P100X50-3N
U6: TPS62172DSGR; SON50P200X200X80-9N
U7: MIC5504-1.8YMT-TR; TDFN1010-4LD-PL-2_MCH
U8: MCP73871-2CCI_ML; QFN50P400X400X100-21N
U9: W25Q32JVSSIQ; SOIC127P790X216-8N
Y1: XRCGB40M000F1S1BR0; OSC_XRCGB40M000F1S1BR0; PARTREV N/A

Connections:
+1.8V: C4.1, C11.1, R2.1, U3.7 (VCCA), U7.1 (VOUT)
+3.3V: C5.1, C6.1, C9.1, C10.1, C12.1, C13.1, C17.1, C18.1, C19.1, C20.1, C21.1, C27.1, C28.1, CR4.1, J3.3, L1.1, L2.1, R9.1, R19.2, R20.2, SW1.1, U1.20 (VDD3P3_RTC), U1.46 (VDD3P3_CPU), U1.55 (VDDA1), U1.56 (VDDA2), U3.6 (VCCB), U3.10 (DIR1), U6.6 (VOS), U7.4 (VIN), U8.9 (~TE)
+5V: C15.1, J2.A4 (VBUS_A4), J2.A9 (VBUS_A9), J2.B4 (VBUS_B4), J2.B9 (VBUS_B9), U8.2 (VPCC), U8.18 (IN), U8.19 (IN__1)
/BG95 RX: U2.34 (MAIN_RXD), U3.9 (A2)
/BG95 TOGGLE POWER: R1.1, R6.1, U1.41 (GPIO36)
/BG95 TX: U2.35 (MAIN_TXD), U3.8 (A1)
/BG95_CLK: CR2.1, J1.5 (CLK), U2.46 (USIM_CLK)
/BG95_IO: CR1.1, J1.3 (CMD), U2.45 (USIM_DATA)
/BG95_RST: CR3.1, J1.7 (DA0), U2.44 (USIM_RST)
/BG95_VCC: J1.4 (VDD), U2.43 (USIM_VDD)
/BTN: R18.2, SW1.2, U1.38 (GPIO33)
/CHARGE EN: R16.2, U1.39 (GPIO34), U8.17 (CE)
/ESP32 RX: U1.18 (GPIO13), U3.5 (B1)
/ESP32 TX: U1.17 (GPIO12), U3.4 (B2)
/MIC EN: R10.2, U1.40 (GPIO35), U7.3 (EN)
/OLED SCL: J3.2, U1.43 (GPIO38)
/OLED SDA: J3.1, U1.42 (GPIO37)
/SPICLK: R24.1, U9.6 (CLK)
/SPICS0: U1.32 (SPICS0), U9.1 (~CS)
/SPID: R22.1, U9.5 (DI(IO0))
/SPIHD: R26.1, U9.7 (~HOLD/~RESET(IO3))
/SPIQ: R23.1, U9.2 (DO(IO1))
/SPIWP: R25.1, U9.3 (~WP(IO2))
/SYS LOAD: C8.1, C14.1, U6.2 (VLN), U6.3 (EN), U8.1 (OUT), U8.20 (OUT__1)
/USB D+: J2.A6 (D1+), J2.B6 (D2+), R4.2, U5.1 (D+)
/USB D-: J2.A7 (D1-), J2.B7 (D2-), R5.2, U5.2 (D-)
/VBAT: J4.2, TH1.2, U8.5 (THERM)
/VDD3P3: C22.1, L2.2, U1.2 (VDD3P3), U1.3 (VDD3P3__1)
/VDDSPI: C23.1, C24.1, U1.29 (VDD_SPI), U9.8 (VCC)
GND: C1.2, C2.2, C3.2, C4.2, C5.2, C6.2, C8.2, C9.2, C10.2, C11.2, C12.2, C13.2, C14.2, C15.2, C16.2, C17.2, C18.2, C19.2, C20.2, C21.2, C22.2, C23.2, C24.2, C25.1, C26.1, C27.2, C28.2, C29.1, CR1.2, CR2.2, CR3.2, CR4.2, D1.1 (K), D2.1 (K), D3.1 (K), D4.1 (K), J1.6 (VSS), J2.A1 (GND_A1), J2.A12 (GND_A12), J2.B1 (GND_B1), J2.B12 (GND_B12), J2.SH1 (SHIELD3), J2.SH2 (SHIELD4), J2.SH3 (SHIELD1), J2.SH4 (SHIELD2), J3.4, J4.1, Q1.1 (E), R6.2, R7.2, R8.1, R10.1, R14.1, R15.1, R16.1, R17.1, R18.1, S1.2, S1.4, TH1.1, U1.57 (GND), U2.3 (GND), U2.31 (GND__1), U2.47 (USIM_GND), U2.48 (GND__2), U2.50 (GND__3), U2.54 (GND__4), U2.55 (GND__5), U2.58 (GND__6), U2.59 (GND__7), U2.61 (GND__8), U2.62 (GND__9), U2.67 (GND__10), U2.68 (GND__11), U2.69 (GND__12), U2.70 (GND__13), U2.71 (GND__14), U2.72 (GND__15), U2.73 (GND__16), U2.74 (GND__17), U2.79 (GND__18), U2.80 (GND__19), U2.81 (GND__20), U2.82 (GND__21), U2.89 (GND__22), U2.90 (GND__23), U2.91 (GND__24), U2.100 (GND__25), U2.101 (GND__26), U2.102 (GND__27), U3.1 (DIR2), U3.2 (~OE), U3.3 (GND), U5.3 (GND), U6.1 (PGND), U6.4 (AGND), U6.5 (FB), U6.9 (EPAD), U7.2 (GND), U7.5 (GND), U8.3 (SEL), U8.4 (PROG2), U8.10 (VSS__1), U8.11 (VSS), U8.21 (EP), U9.4 (GND)
unnamed: C25.2, L3.1, Y1.1
unnamed: D1.2 (A), R3.2
unnamed: D2.2 (A), R11.2
unnamed: D3.2 (A), R12.2
unnamed: D4.2 (A), R13.2
unnamed: J2.A5 (CC1), R7.1
unnamed: J2.B5 (CC2), R8.2
unnamed: Q1.2 (B), R1.2
unnamed: Q1.3 (C), U2.15 (PWRKEY)
unnamed: C29.2, R20.1, S1.1, S1.3, U1.4 (CHIP_PU)
unnamed: R17.2, U1.5 (GPIO0)
unnamed: R5.1, U1.25 (GPIO19)
unnamed: R4.1, U1.26 (GPIO20)
unnamed: R19.1, U1.51 (GPIO45)
unnamed: R24.2, U1.33 (SPICLK)
unnamed: R22.2, U1.35 (SPID)
unnamed: R26.2, U1.30 (SPIHD)
unnamed: R23.2, U1.34 (SPIQ)
unnamed: R25.2, U1.31 (SPIWP)
unnamed: C26.2, U1.53 (XTAL_N), Y1.3
unnamed: L3.2, U1.54 (XTAL_P)
unnamed: R3.1, U2.21 (NET_STATUS)
unnamed: C1.1, C2.1, C3.1, U2.32 (VBAT_BB), U2.33 (VBAT_BB__1), U2.52 (VBAT_RF), U2.53 (VBAT_RF__1)
unnamed: R2.2, U2.17 (~RESET)
unnamed: R9.2, U6.8 (PG)
unnamed: L1.2, U6.7 (SW)
unnamed: R14.2, U8.13 (PROG1)
unnamed: R15.2, U8.12 (PROG3)
unnamed: R12.1, U8.8 (STAT1/*LBO)
unnamed: R13.1, U8.7 (STAT2)
unnamed: C16.1, U8.14 (VBAT__1), U8.15 (VBAT), U8.16 (VBAT_SENSE)
unnamed: R11.1, U8.6 (~PG)

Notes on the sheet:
USB-C Receptacle
BG95 + Peripherals
SIM Holder
ESP32 <-> BG95 UART Logic Level Shifter
ESP32-S3 Chip
PESD BG95 <-> SIM

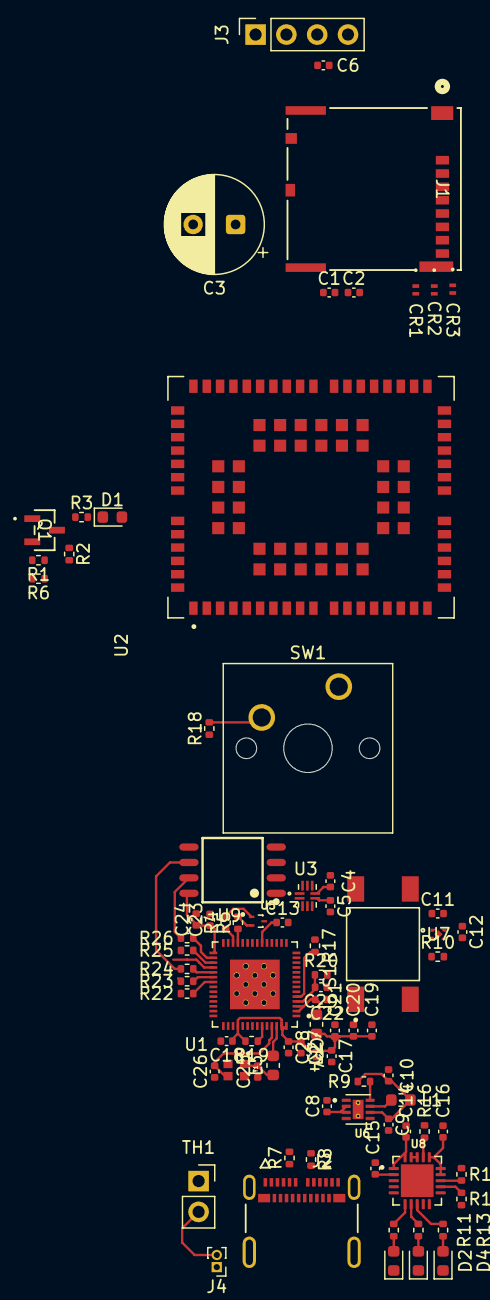
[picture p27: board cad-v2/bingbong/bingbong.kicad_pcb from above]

Board: 2 copper layers, 81 parts (0 on the bottom side), 62 nets.

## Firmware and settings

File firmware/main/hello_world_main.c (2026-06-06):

/*
 * OLED bring-up test for ER-OLED018-1 / SSD1326 over I2C.
 */

#include <stdbool.h>
#include <stdint.h>
#include <string.h>

#include "driver/gpio.h"
#include "driver/i2c_master.h"
#include "esp_check.h"
#include "esp_err.h"
#include "esp_log.h"
#include "freertos/FreeRTOS.h"
#include "freertos/task.h"

#define OLED_WIDTH 256
#define OLED_HEIGHT 32
#define OLED_BYTES_PER_ROW (OLED_WIDTH / 2)
#define OLED_FRAME_BYTES (OLED_BYTES_PER_ROW * OLED_HEIGHT)

#define OLED_SDA_GPIO GPIO_NUM_11
#define OLED_SCL_GPIO GPIO_NUM_10
#define OLED_RST_GPIO GPIO_NUM_9
#define R1200_CE_GPIO GPIO_NUM_8
#define R1200_PWR_EN_GPIO GPIO_NUM_18

#define OLED_I2C_PORT I2C_NUM_0
#define OLED_I2C_SPEED_HZ 100000

#define OLED_RST_ACTIVE_LEVEL 0
#define R1200_CE_ENABLE_LEVEL 1
#define R1200_PWR_ENABLE_LEVEL 1

#define OLED_I2C_TIMEOUT_MS 1000
#define OLED_POWER_STARTUP_DELAY_MS 3000
#define OLED_POWER_STEP_DELAY_MS 5000
#define OLED_ENABLE_R1200_CE 1

static const char *TAG = "oled_test";

static i2c_master_bus_handle_t s_i2c_bus;
static i2c_master_dev_handle_t s_oled;
static uint8_t s_framebuffer[OLED_FRAME_BYTES];

static int iabs_int(int value)
{
    return value < 0 ? -value : value;
}

static uint8_t max_u8(uint8_t a, uint8_t b)
{
    return a > b ? a : b;
}

static void oled_set_reset(bool asserted)
{
    gpio_set_level(OLED_RST_GPIO, asserted ? OLED_RST_ACTIVE_LEVEL : !OLED_RST_ACTIVE_LEVEL);
}

static void r1200_set_ce(bool enabled)
{
    gpio_set_level(R1200_CE_GPIO, enabled ? R1200_CE_ENABLE_LEVEL : !R1200_CE_ENABLE_LEVEL);
}

static void r1200_set_power_enable(bool enabled)
{
    gpio_set_level(R1200_PWR_EN_GPIO, enabled ? R1200_PWR_ENABLE_LEVEL : !R1200_PWR_ENABLE_LEVEL);
}

static esp_err_t board_gpio_init(void)
{
    gpio_config_t output_config = {
        .pin_bit_mask = (1ULL << OLED_RST_GPIO) |
                        (1ULL << R1200_CE_GPIO) |
                        (1ULL << R1200_PWR_EN_GPIO),
        .mode = GPIO_MODE_OUTPUT,
        .pull_up_en = GPIO_PULLUP_DISABLE,
        .pull_down_en = GPIO_PULLDOWN_DISABLE,
        .intr_type = GPIO_INTR_DISABLE,
    };

    ESP_RETURN_ON_ERROR(gpio_config(&output_config), TAG, "GPIO output config failed");

    r1200_set_ce(false);
    r1200_set_power_enable(false);
    oled_set_reset(true);

    return ESP_OK;
}

static esp_err_t oled_i2c_bus_init(void)
{
    i2c_master_bus_config_t bus_config = {
        .clk_source = I2C_CLK_SRC_DEFAULT,
        .i2c_port = OLED_I2C_PORT,
        .scl_io_num = OLED_SCL_GPIO,
        .sda_io_num = OLED_SDA_GPIO,
        .glitch_ignore_cnt = 7,
        .flags.enable_internal_pullup = true,
    };

    return i2c_new_master_bus(&bus_config, &s_i2c_bus);
}

static void oled_detach_device(void)
{
    if (s_oled != NULL) {
        esp_err_t ret = i2c_master_bus_rm_device(s_oled);
        if (ret != ESP_OK) {
            ESP_LOGW(TAG, "OLED I2C detach failed: %s", esp_err_to_name(ret));
        }

        s_oled = NULL;
    }
}

static void oled_log_i2c_scan(void)
{
    bool found_any = false;

    for (uint8_t address = 0x08; address < 0x78; address++) {
        if (i2c_master_probe(s_i2c_bus, address, 50) == ESP_OK) {
            ESP_LOGW(TAG, "I2C device ACK at 0x%02x", address);
            found_any = true;
        }
    }

    if (!found_any) {
        ESP_LOGW(TAG, "No I2C devices ACKed on GPIO%d/GPIO%d", OLED_SDA_GPIO, OLED_SCL_GPIO);
    }
}

static esp_err_t oled_attach_device(void)
{
    if (s_oled != NULL) {
        return ESP_OK;
    }

    const uint8_t address_candidates[] = {
        0x3C, // Datasheet 0x78 when SA0 = 0.
        0x3D, // Datasheet 0x7A when SA0 = 1.
    };

    uint8_t address = 0;
    for (size_t i = 0; i < sizeof(address_candidates); i++) {
        esp_err_t probe_ret = i2c_master_probe(s_i2c_bus, address_candidates[i], 100);
        if (probe_ret == ESP_OK) {
            address = address_candidates[i];
            break;
        }
    }

    if (address == 0) {
        ESP_LOGE(TAG, "OLED did not ACK at 0x3C or 0x3D");
        return ESP_ERR_NOT_FOUND;
    }

    i2c_device_config_t dev_config = {
        .dev_addr_length = I2C_ADDR_BIT_LEN_7,
        .device_address = address,
        .scl_speed_hz = OLED_I2C_SPEED_HZ,
    };

    ESP_LOGI(TAG, "OLED ACKed at I2C address 0x%02x", address);
    return i2c_master_bus_add_device(s_i2c_bus, &dev_config, &s_oled);
}

static void oled_power_on_sequence(void)
{
    ESP_LOGI(TAG, "OLED power step: assert reset low, keep 12V path disabled");
    oled_set_reset(true);
    vTaskDelay(pdMS_TO_TICKS(OLED_POWER_STEP_DELAY_MS));

    ESP_LOGI(TAG, "OLED power step: set GPIO%d R1200_PWR_EN active", R1200_PWR_EN_GPIO);
    r1200_set_power_enable(true);
    vTaskDelay(pdMS_TO_TICKS(OLED_POWER_STEP_DELAY_MS));

#if OLED_ENABLE_R1200_CE
    ESP_LOGI(TAG, "OLED power step: set GPIO%d R1200_CE active", R1200_CE_GPIO);
    r1200_set_ce(true);
    vTaskDelay(pdMS_TO_TICKS(OLED_POWER_STEP_DELAY_MS));
#else
    ESP_LOGW(TAG, "Diagnostic hold: GPIO%d R1200_CE is kept disabled to prevent brownout/reset",
             R1200_CE_GPIO);
    while (true) {
        vTaskDelay(pdMS_TO_TICKS(1000));
    }
#endif

    ESP_LOGI(TAG, "OLED power step: release OLED reset on GPIO%d", OLED_RST_GPIO);
    oled_set_reset(false);
    vTaskDelay(pdMS_TO_TICKS(100));
}

static esp_err_t oled_write_commands(const uint8_t *commands, size_t command_count)
{
    uint8_t tx[64];

    if (command_count > sizeof(tx) - 1) {
        return ESP_ERR_INVALID_SIZE;
    }

    tx[0] = 0x00;
    memcpy(&tx[1], commands, command_count);
    return i2c_master_transmit(s_oled, tx, command_count + 1, OLED_I2C_TIMEOUT_MS);
}

static esp_err_t oled_write_command1(uint8_t command)
{
    return oled_write_commands(&command, 1);
}

static esp_err_t oled_set_window(void)
{
    const uint8_t commands[] = {
        0x15, 0x00, 0x7F,
        0x75, 0x00, 0x1F,
    };

    return oled_write_commands(commands, sizeof(commands));
}

static esp_err_t oled_send_frame(void)
{
    uint8_t data_control = 0x40;
    i2c_master_transmit_multi_buffer_info_t buffers[] = {
        {
            .write_buffer = &data_control,
            .buffer_size = sizeof(data_control),
        },
        {
            .write_buffer = s_framebuffer,
            .buffer_size = sizeof(s_framebuffer),
        },
    };

    ESP_RETURN_ON_ERROR(oled_set_window(), TAG, "set display window failed");
    return i2c_master_multi_buffer_transmit(s_oled, buffers, 2, OLED_I2C_TIMEOUT_MS);
}

static esp_err_t oled_init_controller(void)
{
    const uint8_t init_commands[] = {
        0xFD, 0x12,       // Command lock off.
        0xAE,             // Display off while the RAM is initialized.
        0x15, 0x00, 0x7F, // 128 byte columns = 256 grayscale pixels.
        0x75, 0x00, 0x1F, // 32 rows.
        0x81, 0x27,       // Contrast current from the module datasheet.
        0x87,             // Current range.
        0xA0, 0x07,       // Remap and grayscale mode.
        0xA1, 0x00,       // Display start line.
        0xA2, 0x00,       // Display offset.
        0xA8, 0x1F,       // 1/32 mux.
        0xB1, 0x71,       // Phase length.
        0xB3, 0xF0,       // Clock divider / oscillator.
        0xB7,             // Default linear grayscale table.
        0xBB, 0x35, 0xFF, // Pre-charge setup.
        0xBC, 0x1F,       // Pre-charge voltage.
        0xBE, 0x0F,       // VCOMH.
    };

    ESP_RETURN_ON_ERROR(oled_write_commands(init_commands, sizeof(init_commands)), TAG, "SSD1326 init failed");

    memset(s_framebuffer, 0, sizeof(s_framebuffer));
    ESP_RETURN_ON_ERROR(oled_send_frame(), TAG, "clear frame failed");
    ESP_RETURN_ON_ERROR(oled_write_command1(0xAF), TAG, "display on failed");
    vTaskDelay(pdMS_TO_TICKS(100));

    return ESP_OK;
}

static void framebuffer_set_pixel(int x, int y, uint8_t gray)
{
    if (x < 0 || x >= OLED_WIDTH || y < 0 || y >= OLED_HEIGHT) {
        return;
    }

    gray &= 0x0F;
    uint8_t *byte = &s_framebuffer[(y * OLED_BYTES_PER_ROW) + (x / 2)];

    if ((x & 1) == 0) {
        *byte = (*byte & 0x0F) | (gray << 4);
    } else {
        *byte = (*byte & 0xF0) | gray;
    }
}

static void framebuffer_fill(uint8_t gray)
{
    gray &= 0x0F;
    memset(s_framebuffer, (gray << 4) | gray, sizeof(s_framebuffer));
}

static void framebuffer_rect(int x0, int y0, int width, int height, uint8_t gray)
{
    for (int y = y0; y < y0 + height; y++) {
        for (int x = x0; x < x0 + width; x++) {
            framebuffer_set_pixel(x, y, gray);
        }
    }
}

static void framebuffer_draw_border(uint8_t gray)
{
    for (int x = 0; x < OLED_WIDTH; x++) {
        framebuffer_set_pixel(x, 0, gray);
        framebuffer_set_pixel(x, OLED_HEIGHT - 1, gray);
    }

    for (int y = 0; y < OLED_HEIGHT; y++) {
        framebuffer_set_pixel(0, y, gray);
        framebuffer_set_pixel(OLED_WIDTH - 1, y, gray);
    }
}

static void render_startup_animation_frame(int frame)
{
    const int bright_center = (frame * 6) % (OLED_WIDTH + 64) - 32;
    const int dim_center = OLED_WIDTH - 1 - ((frame * 4) % OLED_WIDTH);

    framebuffer_fill(0);

    for (int y = 0; y < OLED_HEIGHT; y++) {
        for (int x = 0; x < OLED_WIDTH; x++) {
            uint8_t gray = (uint8_t)(((x / 16) + (y / 8) + (frame / 6)) & 0x01);

            int bright_distance = iabs_int(x - bright_center);
            if (bright_distance < 48) {
                gray = max_u8(gray, (uint8_t)(15 - (bright_distance / 4)));
            }

            int dim_distance = iabs_int(x - dim_center);
            if (dim_distance < 24) {
                gray = max_u8(gray, (uint8_t)(8 - (dim_distance / 3)));
            }

            if (((x + (frame * 3) + (y * 6)) % 48) < 3) {
                gray = max_u8(gray, 10);
            }

            framebuffer_set_pixel(x, y, gray);
        }
    }

    framebuffer_draw_border(15);
}

static void render_idle_test_frame(int frame)
{
    framebuffer_fill(0);

    for (int y = 0; y < OLED_HEIGHT; y++) {
        for (int x = 0; x < OLED_WIDTH; x++) {
            uint8_t gray = (uint8_t)((x + frame) & 0x0F);

            if (((x + frame) % 64) < 6) {
                gray = 15;
            }

            if (((x / 8) ^ (y / 4) ^ (frame / 8)) & 0x01) {
                gray = max_u8(gray, 3);
            }

            framebuffer_set_pixel(x, y, gray);
        }
    }

    framebuffer_rect(8, 8, 5, 16, 15);
    framebuffer_rect(13, 8, 14, 4, 15);
    framebuffer_rect(13, 20, 14, 4, 15);
    framebuffer_rect(27, 8, 5, 16, 15);

    framebuffer_rect(42, 8, 5, 16, 15);
    framebuffer_rect(47, 20, 18, 4, 15);

    framebuffer_rect(75, 8, 5, 16, 15);
    framebuffer_rect(80, 8, 18, 4, 15);
    framebuffer_rect(80, 14, 14, 4, 12);
    framebuffer_rect(80, 20, 18, 4, 15);

    framebuffer_rect(108, 8, 5, 16, 15);
    framebuffer_rect(113, 8, 14, 4, 15);
    framebuffer_rect(113, 20, 14, 4, 15);
    framebuffer_rect(127, 12, 5, 8, 15);

    framebuffer_draw_border(15);
}

static esp_err_t run_startup_animation(void)
{
    for (int frame = 0; frame < 70; frame++) {
        render_startup_animation_frame(frame);
        ESP_RETURN_ON_ERROR(oled_send_frame(), TAG, "startup animation frame failed");
        vTaskDelay(pdMS_TO_TICKS(18));
    }

    return ESP_OK;
}

void app_main(void)
{
    ESP_LOGI(TAG, "Starting ER-OLED018-1 SSD1326 I2C test");

    esp_err_t ret = board_gpio_init();
    if (ret != ESP_OK) {
        ESP_LOGE(TAG, "GPIO init failed: %s", esp_err_to_name(ret));
        while (true) {
            vTaskDelay(pdMS_TO_TICKS(1000));
        }
    }

    ret = oled_i2c_bus_init();
    if (ret != ESP_OK) {
        ESP_LOGE(TAG, "I2C bus init failed: %s", esp_err_to_name(ret));
        while (true) {
            vTaskDelay(pdMS_TO_TICKS(1000));
        }
    }

    ESP_LOGI(TAG, "Holding OLED 12V rail off for %d ms before first enable",
             OLED_POWER_STARTUP_DELAY_MS);
    vTaskDelay(pdMS_TO_TICKS(OLED_POWER_STARTUP_DELAY_MS));

    bool oled_ready = false;

    int frame = 0;
    while (true) {
        if (!oled_ready) {
            oled_power_on_sequence();

            ret = oled_attach_device();
            if (ret != ESP_OK) {
                ESP_LOGW(TAG, "OLED not ready yet: %s", esp_err_to_name(ret));
                oled_log_i2c_scan();
                vTaskDelay(pdMS_TO_TICKS(1000));
                continue;
            }

            ret = oled_init_controller();
            if (ret != ESP_OK) {
                ESP_LOGW(TAG, "OLED init failed: %s", esp_err_to_name(ret));
                oled_detach_device();
                vTaskDelay(pdMS_TO_TICKS(1000));
                continue;
            }

            ret = run_startup_animation();
            if (ret != ESP_OK) {
                ESP_LOGW(TAG, "OLED startup animation failed: %s", esp_err_to_name(ret));
                oled_detach_device();
                vTaskDelay(pdMS_TO_TICKS(1000));
                continue;
            }

            oled_ready = true;
        }

        render_idle_test_frame(frame++);
        ret = oled_send_frame();
        if (ret != ESP_OK) {
            ESP_LOGW(TAG, "OLED frame write failed: %s", esp_err_to_name(ret));
            oled_detach_device();
            oled_ready = false;
            vTaskDelay(pdMS_TO_TICKS(1000));
            continue;
        }

        vTaskDelay(pdMS_TO_TICKS(45));
    }
}

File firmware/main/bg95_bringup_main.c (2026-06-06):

/*
 * BG95 bring-up step 1: enable the board's 1.8 V logic rail.
 */

#include <stdbool.h>
#include <stddef.h>
#include <stdint.h>
#include <string.h>

#include "driver/gpio.h"
#include "driver/uart.h"
#include "esp_check.h"
#include "esp_err.h"
#include "esp_log.h"
#include "freertos/FreeRTOS.h"
#include "freertos/task.h"

#define BG95_1V8_EN_GPIO GPIO_NUM_13
#define BG95_PWRKEY_GPIO GPIO_NUM_12
#define BG95_SIM_SW_GPIO GPIO_NUM_33
#define BG95_UART_TX_GPIO GPIO_NUM_1
#define BG95_UART_RX_GPIO GPIO_NUM_2

#define BG95_UART_PORT UART_NUM_1
#define BG95_UART_BAUD 115200
#define BG95_UART_RX_BUF_SIZE 2048
#define BG95_UART_TX_BUF_SIZE 256

#define BG95_1V8_ENABLE_LEVEL 1
#define BG95_1V8_DISABLE_LEVEL 0

/*
 * GPIO12 drives Q1 through R1. High on this net pulls BG95 PWRKEY low.
 * Keep it low for this first rail-only test.
 */
#define BG95_PWRKEY_RELEASE_LEVEL 0
#define BG95_PWRKEY_ASSERT_LEVEL 1

#define BG95_RAIL_SETTLE_MS 250
#define BG95_PWRKEY_PULSE_MS 800
#define BG95_BOOT_WAIT_MS 8000
#define BG95_AT_RESPONSE_TIMEOUT_MS 2500
#define BG95_STATUS_LOG_MS 1000
#define BG95_AT_KEEPALIVE_MS 10000

static const char *TAG = "bg95_bringup";
static int s_1v8_enable_commanded = BG95_1V8_DISABLE_LEVEL;
static int s_pwrkey_commanded = BG95_PWRKEY_RELEASE_LEVEL;

static esp_err_t bg95_gpio_init(void)
{
    gpio_config_t output_config = {
        .pin_bit_mask = (1ULL << BG95_1V8_EN_GPIO) |
                        (1ULL << BG95_PWRKEY_GPIO),
        .mode = GPIO_MODE_INPUT_OUTPUT,
        .pull_up_en = GPIO_PULLUP_DISABLE,
        .pull_down_en = GPIO_PULLDOWN_DISABLE,
        .intr_type = GPIO_INTR_DISABLE,
    };
    ESP_RETURN_ON_ERROR(gpio_config(&output_config), TAG, "GPIO output config failed");

    gpio_config_t input_config = {
        .pin_bit_mask = (1ULL << BG95_SIM_SW_GPIO),
        .mode = GPIO_MODE_INPUT,
        .pull_up_en = GPIO_PULLUP_ENABLE,
        .pull_down_en = GPIO_PULLDOWN_DISABLE,
        .intr_type = GPIO_INTR_DISABLE,
    };
    ESP_RETURN_ON_ERROR(gpio_config(&input_config), TAG, "GPIO input config failed");

    ESP_RETURN_ON_ERROR(gpio_set_level(BG95_PWRKEY_GPIO, BG95_PWRKEY_RELEASE_LEVEL),
                        TAG, "failed to release BG95 PWRKEY");
    s_pwrkey_commanded = BG95_PWRKEY_RELEASE_LEVEL;
    ESP_RETURN_ON_ERROR(gpio_set_level(BG95_1V8_EN_GPIO, BG95_1V8_DISABLE_LEVEL),
                        TAG, "failed to disable BG95 1.8 V rail");
    s_1v8_enable_commanded = BG95_1V8_DISABLE_LEVEL;

    return ESP_OK;
}

static esp_err_t bg95_uart_init(void)
{
    const uart_config_t uart_config = {
        .baud_rate = BG95_UART_BAUD,
        .data_bits = UART_DATA_8_BITS,
        .parity = UART_PARITY_DISABLE,
        .stop_bits = UART_STOP_BITS_1,
        .flow_ctrl = UART_HW_FLOWCTRL_DISABLE,
        .source_clk = UART_SCLK_DEFAULT,
    };

    ESP_RETURN_ON_ERROR(uart_driver_install(BG95_UART_PORT,
                                            BG95_UART_RX_BUF_SIZE,
                                            BG95_UART_TX_BUF_SIZE,
                                            0,
                                            NULL,
                                            0),
                        TAG, "UART driver install failed");
    ESP_RETURN_ON_ERROR(uart_param_config(BG95_UART_PORT, &uart_config),
                        TAG, "UART parameter config failed");
    ESP_RETURN_ON_ERROR(uart_set_pin(BG95_UART_PORT,
                                     BG95_UART_TX_GPIO,
                                     BG95_UART_RX_GPIO,
                                     UART_PIN_NO_CHANGE,
                                     UART_PIN_NO_CHANGE),
                        TAG, "UART pin config failed");

    ESP_LOGI(TAG, "BG95 UART%d ready: TX GPIO%d -> BG95 MAIN_RXD, RX GPIO%d <- BG95 MAIN_TXD, %d baud",
             BG95_UART_PORT, BG95_UART_TX_GPIO, BG95_UART_RX_GPIO, BG95_UART_BAUD);
    return ESP_OK;
}

static void bg95_enable_1v8_rail(void)
{
    ESP_LOGI(TAG, "Holding BG95 PWRKEY inactive on GPIO%d", BG95_PWRKEY_GPIO);
    ESP_LOGI(TAG, "Enabling BG95 1.8 V rail: GPIO%d -> %d",
             BG95_1V8_EN_GPIO, BG95_1V8_ENABLE_LEVEL);
    ESP_ERROR_CHECK(gpio_set_level(BG95_1V8_EN_GPIO, BG95_1V8_ENABLE_LEVEL));
    s_1v8_enable_commanded = BG95_1V8_ENABLE_LEVEL;
    vTaskDelay(pdMS_TO_TICKS(BG95_RAIL_SETTLE_MS));
}

static void bg95_pulse_pwrkey(void)
{
    ESP_LOGI(TAG, "Pulsing BG95 PWRKEY for %d ms", BG95_PWRKEY_PULSE_MS);
    ESP_ERROR_CHECK(gpio_set_level(BG95_PWRKEY_GPIO, BG95_PWRKEY_ASSERT_LEVEL));
    s_pwrkey_commanded = BG95_PWRKEY_ASSERT_LEVEL;
    vTaskDelay(pdMS_TO_TICKS(BG95_PWRKEY_PULSE_MS));

    ESP_ERROR_CHECK(gpio_set_level(BG95_PWRKEY_GPIO, BG95_PWRKEY_RELEASE_LEVEL));
    s_pwrkey_commanded = BG95_PWRKEY_RELEASE_LEVEL;
    ESP_LOGI(TAG, "Released BG95 PWRKEY; waiting %d ms for modem boot", BG95_BOOT_WAIT_MS);
    vTaskDelay(pdMS_TO_TICKS(BG95_BOOT_WAIT_MS));
}

static esp_err_t bg95_send_at_command(const char *command, char *response, size_t response_size)
{
    if (response_size == 0) {
        return ESP_ERR_INVALID_ARG;
    }

    response[0] = '\0';
    ESP_ERROR_CHECK(uart_flush_input(BG95_UART_PORT));

    ESP_LOGI(TAG, "BG95 << %s", command);
    ESP_RETURN_ON_FALSE(uart_write_bytes(BG95_UART_PORT, command, strlen(command)) == (int)strlen(command),
                        ESP_FAIL, TAG, "UART command write failed");
    ESP_RETURN_ON_FALSE(uart_write_bytes(BG95_UART_PORT, "\r\n", 2) == 2,
                        ESP_FAIL, TAG, "UART line ending write failed");

    const int64_t deadline_ticks = xTaskGetTickCount() + pdMS_TO_TICKS(BG95_AT_RESPONSE_TIMEOUT_MS);
    size_t response_len = 0;

    while (xTaskGetTickCount() < deadline_ticks && response_len < response_size - 1) {
        uint8_t byte = 0;
        const int read_len = uart_read_bytes(BG95_UART_PORT, &byte, 1, pdMS_TO_TICKS(50));
        if (read_len > 0) {
            response[response_len++] = (char)byte;
            response[response_len] = '\0';

            if (strstr(response, "\r\nOK\r\n") != NULL ||
                strstr(response, "\r\nERROR\r\n") != NULL ||
                strstr(response, "\r\n+CME ERROR:") != NULL) {
                break;
            }
        }
    }

    if (response_len == 0) {
        ESP_LOGW(TAG, "BG95 >> no response within %d ms", BG95_AT_RESPONSE_TIMEOUT_MS);
        return ESP_ERR_TIMEOUT;
    }

    ESP_LOGI(TAG, "BG95 >> %s", response);
    return ESP_OK;
}

static bool bg95_probe_at(int attempts)
{
    char response[128];

    for (int attempt = 1; attempt <= attempts; attempt++) {
        const esp_err_t ret = bg95_send_at_command("AT", response, sizeof(response));
        if (ret == ESP_OK && strstr(response, "OK") != NULL) {
            ESP_LOGI(TAG, "BG95 AT probe passed on attempt %d", attempt);
            return true;
        }

        ESP_LOGW(TAG, "BG95 AT probe attempt %d/%d failed", attempt, attempts);
        vTaskDelay(pdMS_TO_TICKS(1000));
    }

    return false;
}
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

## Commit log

2026-09-22 Add interactive assembly site and complete project handoff
    Preserve firmware history under firmware and snapshot current site, engineering reports, CAD, PCB changes, and QA evidence. Include cross-laptop setup, source hashes, and a clean-install smoke report.
    [ASR00035_3.7_Lipo.SLDPRT, Assem1.SLDASM, Assem8.SLDASM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]
2026-09-28 cad-v3: display sheet for OSPTEK AM110Q126294LK1 with touch, new footprints
    - Panel decision from a 9-agent study (DISPLAY_PANEL_DECISION_2026-09-28.md)
    - Sheet 4 display: 1.8 V LDO -> switch A -> switch B chain on one GPIO,
    TPS65631 ELVDD/ELVSS with nRF-driven CTRL, LVC/LV1T level shifting,
    TCA9406 touch I2C gated by panel reset, 24-pin BTB (mate TBD)
    - nRF9151 GPIO: P0.20 CTP_INT, P0.23 DISP_PMIC_CTRL (32/32 used)
    - Footprints: TPS7A02 DQN, SN74LV1T34 DCK, TCA9406 YZP, Murata
    DFE252010F, TPS65631 DPD (IPC-7351B, owner-approved)
    - Fix TI_DCK0006A_SC70-6 pad centres (+/-0.65 -> +/-1.1 mm)
    - Datasheets saved under firmware/bingbong_pcb/_mech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
    [bingbong_v3.kicad_sch, display.kicad_sch, dock.kicad_sch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]
2026-09-28 cad-v3: part selections for power, UI, RF, eUICC with verified footprints
    - U102 MAX17048X+T10 (WLP; G+T10 was the TDFN), L101 DFE201210U (S is NRND),
    Q101 DMP3099L, Q102 DMG1012T, D101 TPD1E10B06 (TI pin order), D102 BZX585-C12,
    FB101 BLM18PG221SN1D
    - D501 Kingbright APTF1616 (symbol LED_ARGB), Q501-503/Q601 DMN26D0UT
    - J301 MM8130-2600RA2 (RB2 does not exist), D301 Panasonic EZAEG1N50AC
    - New footprints from manufacturer land patterns: WLP-8, DFE201210U, Diodes
    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
    [dock.kicad_sch, power.kicad_sch, rf.kicad_sch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]
2026-09-28 cad-v3: J302 = Harwin S7141-45R, cap land z 1.65 mm with PCB-referenced stop
    [rf.kicad_sch]
2026-10-01 site: add RF lab, a four-part interactive study of the antenna and radio
    - New #rf-lab modal (nav link + antenna chapter invitation): charge and
    current to traveling fields, all 16 RF schematic positions with per-part
    inspectors, LC branch currents and reflections, and a typed-message
    QPSK receiver with I/Q mixing, pilot phase recovery and interference
    - Teaching models in rf-model.js / rf-signal.js, documented as such in
    qa/rf/source-register.md (not measured bingbong RF data)
    - Scene pauses rendering while the lab is open; static primer without JS
    - rf-check.mjs (139 pass) and rf-lessons-check.mjs (95 + 3 pass), evidence
    in qa/rf/; assembly QA re-run 2026-09-24
    - Rebuilt index.ht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
2026-10-02 cad-v3: E501 grip contact = Harwin S7141-45R; D501 side-view fallback survey
    - E501 on the main board, top-pressed, same part as J302 (one reel, verified
    footprint). WE-SECF rejected: 0.2 mm working window vs 0.5 mm. Ring needs
    a plated tab over the crown-end edge, land z = 1.65 above the PCB top.
    Supersedes report J8's satellite-board contact. ERC: 0 errors, 4 warnings.
    - D501 stays the top-emitting APTF1616; the ring stub's 45 deg facet must
    sit over it. Side-view fallback: ams-OSRAM KRTB AILMS1 (0.6 mm tall,
    needs OSRAM body/pad confirmation before a footprint is drawn).
    - Flag: APTF1616 green Vf max 4.1 V @ 20 mA vs VSYS 3.45 V at low battery;
    bench-check headroom on EVM-1.
    -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
    [ui.kicad_sch]

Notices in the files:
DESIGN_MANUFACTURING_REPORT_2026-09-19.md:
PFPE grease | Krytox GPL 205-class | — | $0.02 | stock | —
